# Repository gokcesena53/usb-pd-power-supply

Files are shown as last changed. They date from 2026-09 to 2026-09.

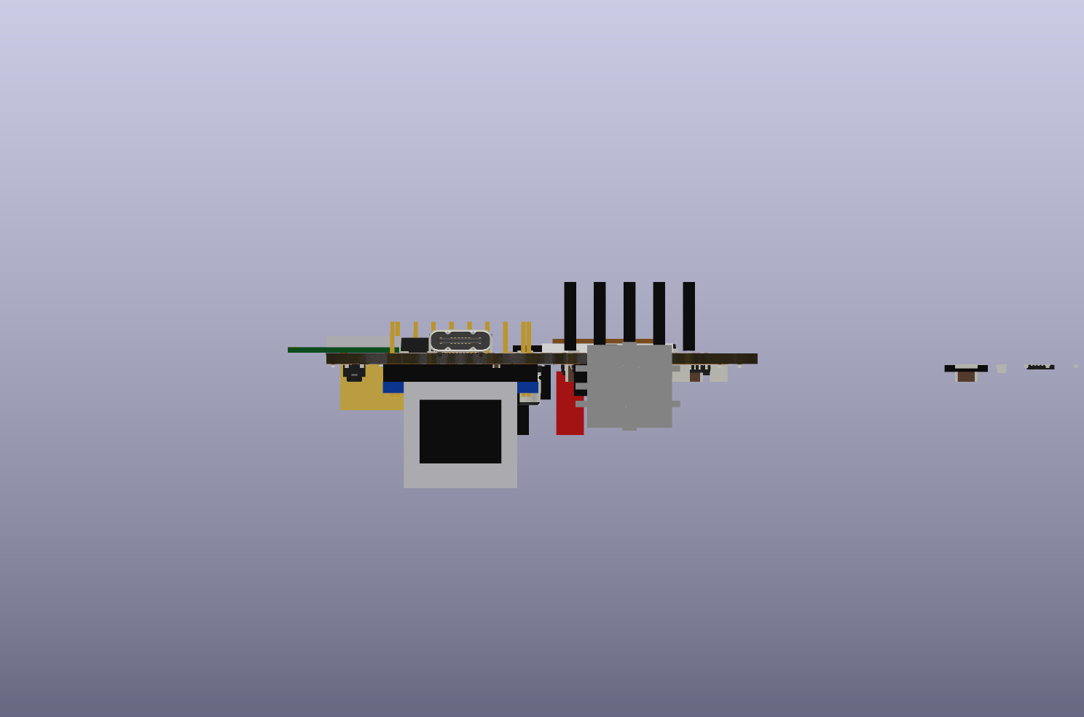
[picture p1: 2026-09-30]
hardware/docs/reports/task-094-20260925/candidate-left.png

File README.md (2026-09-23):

# gopo — Masaüstü Güç Kaynağı

USB-C PD beslemeli, ESP32-C6 tabanlı, TFT ekranlı ve döner enkoderli
masaüstü ayarlanabilir güç kaynağı. Şematik ve PCB tasarımı KiCad ile yapılmıştır.

Depo yapısı [Open Hardware Template](https://github.com/mfhepp/open_hardware_template)
şablonunu izler.

## Klasör yapısı

| Klasör | İçerik |
| --- | --- |
| `hardware/` | KiCad projesi (`gopo.kicad_pro`, `.kicad_sch`, `.kicad_pcb`, `.kicad_dru`) ve kütüphane tabloları (`fp-lib-table`, `sym-lib-table`) |
| `hardware/libraries/` | Projeye özel sembol (`.kicad_sym`), footprint (`.pretty`) ve 3D model (`.3dshapes`) kütüphaneleri |
| `hardware/datasheets/` | Kullanılan bileşenlerin veri sayfaları |
| `hardware/docs/` | Ham ERC/DRC raporları, netlist'ler, doğrulama betikleri ve anlık görüntüler |
| `hardware/gerber/` | Üretim çıktıları (Gerber, drill) |
| `hardware/images/` | Şematik/PCB görüntüleri (PNG, SVG) |
| `hardware/pdf/` | Blok blok şematik PDF çıktıları ve inceleme belgeleri |
| `design_decisions/` | Tasarım kararları, hesaplamalar ve inceleme notları (Markdown) |
| `3d_design/` | Kutu/mekanik tasarım dosyaları |
| `software/` | Firmware, firmware gereksinimleri (`FIRMWARE_GEREKSINIMLERI.md`) ve yardımcı betikler |
| `backlog/` | Yapılacaklar ([Backlog.md](https://github.com/MrLesk/Backlog.md)); `backlog board` veya `backlog browser` ile görüntülenir |
| `docs/` | GitHub Pages proje sayfası |
| `.claude/skills/` | KiCad şema üretimi için Claude Code skill'i ve araçları |

## Şema araçları

`.claude/skills/kicad-schematic/` altında şema üretimi ve temizliği için
bir Claude Code skill'i ve iki bağımsız betik bulunur:

```bash
SK=.claude/skills/kicad-schematic/scripts
cd hardware
python3 ../$SK/render.py gopo.kicad_sch --list
python3 ../$SK/render.py gopo.kicad_sch --page 10 --crop 255 26 410 128 -o /tmp/r
python3 ../$SK/verify.py gopo.kicad_sch --show PD_VOUT V_PRE
```

`render.py` şemayı PNG'ye çevirir ve mm cinsinden bir bölgeye yakınlaşır;
`verify.py` ERC çalıştırıp netlist'i bir referansla karşılaştırır.
Gereksinimler: `kicad-cli`, `poppler-utils` (pdftoppm, pdftotext), Python 3.

Yöntem [American-Embedded/kistack](https://github.com/American-Embedded/kistack)
schematic skill'ine dayanır (MIT); kopyası ve lisansı skill'in `references/`
klasöründedir.

## Revizyonlar

Aktif revizyon **REV_B**'dir; `hardware/` klasöründeki tasarım budur.
Üretilmiş olan REV_A tasarımı depodan çıkarılmıştır ve yalnızca git geçmişinde
bulunur (`git log --diff-filter=D -- "masaüstü güç kaynağı.kicad_pcb"`).

Değişiklik kaydı için `CHANGES.TXT` dosyasına bakınız.

## Tasarım kuralları ve PCB üretimi

Tasarım kuralları `hardware/gopo.kicad_dru` dosyasındadır. Üretime göndermeden önce
seçtiğiniz üreticinin yeteneklerine uyduğunu doğrulayın.

PCB ipek baskısına ve şematiğe **"Licensed under CERN OHL v.1.2"** metnini
eklemeyi unutmayın.

## Lisans

Donanım tasarımı CERN OHL v.1.2 altında, `software/` klasöründeki yazılım MIT
lisansı altında dağıtılmaktadır. Ayrıntılar için `LICENSE` ve
`cern_ohl_v_1_2.txt` dosyalarına bakınız.

> **Not:** `LICENSE` dosyasındaki `<TELİF HAKKI SAHİBİ>` alanı henüz
> doldurulmamıştır; yayımlamadan önce doldurun veya farklı bir lisans seçin.

## Sorumluluk reddi

BU TASARIM VE YAZILIM, AÇIK VEYA ZIMNİ HİÇBİR GARANTİ OLMAKSIZIN "OLDUĞU GİBİ"
SAĞLANMAKTADIR. YAZARLAR VEYA TELİF HAKKI SAHİPLERİ, TASARIMIN VEYA YAZILIMIN
KULLANIMINDAN DOĞAN HİÇBİR TALEP, ZARAR VEYA SORUMLULUKTAN SORUMLU TUTULAMAZ.

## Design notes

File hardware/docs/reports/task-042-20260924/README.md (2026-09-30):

# TASK-042 — PCM_Espressif temizliği

24.09.2026. U2, aktif şemada ve PCB'de `RF_Module:ESP32-C6-MINI-1`
kullanıyor; eski WROOM kütüphanesine ihtiyaç kalmadı.

Kaldırılan dosyalar:

- `hardware/libraries/PCM_Espressif.kicad_sym`
- `hardware/libraries/PCM_Espressif.pretty/ESP32-C6-WROOM-1.kicad_mod`

`hardware/sym-lib-table` ve `hardware/fp-lib-table` içindeki PCM_Espressif
kayıtları da kaldırıldı. Güncel şema, PCB, proje, lib-table ve yerel
sembol/footprint dosyalarından oluşan 25 dosyada referans sayısı sıfırdır.
Tarihsel rapor ve yedeklerdeki eski devre kayıtları arşiv niteliğindedir.

| Kontrol | Önce | Sonra |
| --- | --- | --- |
| ERC hata / uyarı | 0 / 0 | 0 / 0 |
| DRC schematic parity | 0 | 0 |
| DRC yerleşim/üretim ihlali | 148 | 148 |
| Bağlantısız öğe | 361 | 361 |
| Net sayısı | 120 | 120 |

Netlist, tüm netlerin pin kümeleri üzerinden birebir karşılaştırıldı.
Beş şema dosyası, PCB ve proje dosyasının SHA-256 değerleri de değişmedi.
Görsel tasarım dosyalarına dokunulmadığından bu temizlik için yeni render
üretilmedi.

148 DRC ihlalinin içerikleri aynı kaldı; bağlantısız öğelerin net başına
sayıları da değişmedi. Aynı konumdaki veya aynı pad numarasını paylaşan
pedlerde KiCad ratsnest uç çifti seçimi çalıştırmalar arasında değişebilir;
raporlardaki bu fark PCB bağlantısının değiştiği anlamına gelmez. Kütüphane
temizliği açısından ERC/DRC kontrolü geçti; genel yerleşim/routing DRC'si
henüz sıfır değildir.

Kanıtlar: `before-summary.json`, `after-summary.json`, `before-erc.rpt`,
`after-erc.rpt`, `before-drc.json`, `after-drc.json`.

Boş `PCM_Espressif.pretty` klasörünün silinmesi otomatik onay denetimi
tarafından yalnız “blocked by policy” gerekçesiyle engellendi. Klasör boş
bırakıldı; içinde footprint yoktur ve kütüphane tablolarında kaydı yoktur.
Git boş klasörleri takip etmez.

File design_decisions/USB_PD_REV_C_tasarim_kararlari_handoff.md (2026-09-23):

# USB-C PD Masaüstü Güç Kaynağı — REV_C Tasarım Kararları (Agent Handoff)

**Tarih:** 2026-09-16
**Kaynak:** Zg ile yapılan tasarım inceleme oturumu (claude.ai, "USB TYPE C PD Project")
**Hedef revizyon:** REV_B → REV_C

---

## 0. Agent için çalışma kuralları

1. Bu doküman **onaylanmış kararları** içerir. Aşağıdaki "Reddedilen alternatifler" (Bölüm 9) listesindeki çözümleri yeniden önermeyin veya uygulamayın.
2. Referans designator'lar (Q3, Q4, C3, D3, R43, C12, C13, C16 vb.) REV_B şemasından alınmıştır. Değişiklik yapmadan önce her birinin şemada doğru parçaya karşılık geldiğini **doğrulayın**. Uyuşmazlık varsa değiştirmeyin, raporlayın.
3. Değeri veya MPN'i **TBD** olarak işaretlenmiş parçalar için MPN uydurmayın. Şemaya generic parça + `TBD` notu ile yerleştirin (Bölüm 8'deki gereksinimleri parça alanına yazın).
4. Her değişikliği sayfa bazında ayrı commit / değişiklik kaydı olarak yapın ve sonunda Bölüm 10'daki kontrol listesini raporlayın.
5. Parça tedariki LCSC üzerinden planlanıyor. Yeni parça eklerken LCSC stok durumunu not edin.

---

## 1. Tasarım varsayımları

| Parametre | Değer |
|---|---|
| PD controller | AP33772S (sink) |
| VBUS aralığı | vSafe5V attach → PPS 3.3 V … EPR 28 V |
| Kullanıcı çıkış voltajı | **3.3 V – 28 V** (5 V altı yalnızca PPS ile, adaptörün APDO minimumuna bağlı) |
| Maksimum çıkış akımı | **5 A varsayıldı** (kesinleşmedi — değişirse şönt, FET ve SOA hesapları yeniden yapılmalı) |
| Dahili yük | 3.3 V / ~1 A (ESP32, ekran + backlight boost, INA228 vb.) |
| MCU | ESP32 |

---

## 2. Yeni mimari (özet)

```
J1 (USB-C) ── D3 (AQ3130E, ESD) + SMBJ30A (surge) ── USB_VBUS ── C3 ── AP33772S R_SENSE
                                                                         │
                         ┌───────────────────────────────────────────────┤  (dallanma noktası
                         │                                               │   şöntün ARKASINDA)
                         ▼                                               ▼
  KOL A — DAHİLİ BESLEME                               KOL B — KULLANICI ÇIKIŞI
  Q3/Q4 (küçük dual NMOS, AP33772S sürer)             M1 ⇄ M2 back-to-back (AP74502Q sürer)
         │                                                     │
      PD_VOUT (+47 µF sönümleme bulk)                     INA228 şönt
         │                                                     │
  TPS55340 pre-boost (5.02 V)                              OUT_POS ── J4/J5
         │
       V_PRE = max(5 V, PD_VOUT − V_D) ──► AP74502Q VIN
         │
  AOZ1284 buck ── 3.3 V rail
```

**Temel fikir:**
- Kullanıcı akımı artık Q3/Q4'ten geçmez, sadece M1/M2 üzerinden akar (yol kaybı yarıya iner).
- Q3/Q4, cSnkBulk (≤10 µF) uyumu, Hard Reset/detach izolasyonu ve dahili rail kısa devre koruması için **kalır** ama küçültülür.
- Pre-boost, PD_VOUT 5 V'un altına indiğinde (3.3 V PPS) dahili rail'i ayakta tutar; üstünde pass-through çalışır.
- AP74502Q'nun VIN'i V_PRE'den beslendiği için 3.3 V çıkışta da POR eşiğinin (≤3.9 V) üzerinde kalır.

---

## 3. Sayfa bazında değişiklikler

### 3.1 `usb_c_input` / VBUS giriş

| # | İşlem | Referans | Detay |
|---|---|---|---|
| 1 | EKLE | D_TVS (yeni) | **SMBJ30A** (tek yönlü, 600 W, VRWM 30 V). Yer yoksa SMAJ30A. J1'e yakın, kısa toprak dönüşü. |
| 2 | KORU | D3 | AQ3130E-01ETG (ESD diyotu) yerinde kalır, SMBJ30A ile paralel. |
| 3 | DEĞİŞTİR | C3 | 1 µF/50 V → **2.2 µF/50 V X7R** (cSnkBulk minimum 1 µF'ı DC bias altında garanti etmek için). USB_VBUS'ta toplam efektif kapasite 5 V'ta **≤10 µF** kalmalı. |
| 4 | NOT | Ferrite bead | 5 A yoluna **bead konmayacak**. İstenirse USB_VBUS'ta 0 Ω doldurulmuş opsiyonel footprint bırakılabilir (DNP bead). TVS'ler bead'in konnektör tarafında olmalı. |

### 3.2 `usb_pd_controller`

| # | İşlem | Referans | Detay |
|---|---|---|---|
| 1 | DOĞRULA | AP33772S R_SENSE | Şöntün **iki kolun dallandığı noktanın önünde** olduğundan emin olun (OCP ve PPS akım ölçümü toplam akımı görmeli). Konum farklıysa raporlayın, topolojiyi buna göre düzenleyin. |
| 2 | DEĞİŞTİR | Q3, Q4 | IRF7855 → **küçük dual NMOS, 40–60 V, ≥2 A** (TBD, Bölüm 8). Q3/Q4 çıkışı artık sadece `PD_VOUT` (dahili kol) netini besler. |
| 3 | AYIR | Net | `PD_VOUT` ile `OUT_POS` / INA228 arasındaki bağlantıyı **kaldırın**. Kullanıcı çıkış kolu Q3/Q4'ün önünden (USB_VBUS, şönt sonrası) beslenecek. |

### 3.3 `powergeneration`

| # | İşlem | Referans | Detay |
|---|---|---|---|
| 1 | EKLE | U_BOOST (yeni) | **TPS55340PWPR** (HTSSOP-14 PowerPAD). Giriş: `PD_VOUT`, çıkış: yeni net `V_PRE`. |
| 2 | EKLE | L_BOOST | 6.8–10 µH, Isat ≥3 A, düşük DCR (pass-through'da buck giriş akımını sürekli taşır). **TBD** |
| 3 | EKLE | D_BOOST | Schottky 40–60 V, 3 A, düşük VF (SS34/SS36 sınıfı). **TBD** |
| 4 | EKLE | R_FREQ | **78.7 kΩ** (≈600 kHz). f_sw 350 kHz altına düşürülmemeli (foldback recovery). |
| 5 | EKLE | FB bölücü | R_TOP **30.1 kΩ** (V_PRE→FB), R_BOT **9.76 kΩ** (FB→AGND) → V_PRE ≈ 5.02 V |
| 6 | EKLE | **FB clamp (ZORUNLU)** | FB abs max 3 V; pass-through'da FB ≈ 6.8 V'a çıkar. ~~BAT54 + 3V3 bölücü (V_CL ≈ 1.81 V)~~ → **23.09.2026: BAS16H**, anot FB, katot `EN_CTRL` (V_X = 1.605 V, U6 TLV431; #14 ile ortak). 34 V / 0 °C worst-case FB 2.40 V. Ayrıntı: `design_decisions/output/FB_CLAMP_EN_REFERANSI_20260923.md`. |
| 7 | EKLE | C_SS | 47 nF |
| 8 | EKLE | Kompanzasyon | R3 = 2 kΩ, C4 = 100 nF (başlangıç değeri, en düşük VIN'de ölçümle optimize edilecek). C5 opsiyonel/DNP. |
| 9 | EKLE | C_IN_BOOST | 10 µF/50 V X7R + VIN pinine yakın 100 nF |
| 10 | EKLE | C_OUT_BOOST | ≥2 × 10 µF/50 V X7R (`V_PRE`), AOZ1284 giriş kapasiteleriyle birleştirilebilir |
| 11 | BAĞLA | EN | EN → VIN'e 100 kΩ ile (her zaman aktif). SYNC → AGND, NC → AGND, PowerPAD → AGND. |
| 12 | EKLE | C_DAMP | `PD_VOUT`'a **47 µF, 35–50 V, ESR ~50–100 mΩ** (hybrid polymer veya düşük ESR elektrolitik). Seramik bu işi görmez. PD_VOUT toplam kapasitesi **≤100 µF** (cSnkBulkPd). **TBD MPN** |
| 13 | TAŞI | AOZ1284 girişi | AOZ1284 VIN: `PD_VOUT` → **`V_PRE`**. C12/C13 `V_PRE` netine taşınır. |
| 14 | TAŞI | R43 / TL431 (EN bias) | Beslemesi `V_PRE`'den alınır. ~~R43 ≈ 1 kΩ, TL431 2.495 V~~ → **23.09.2026: R43 4k7, U6 TLV431BQ, R50 2k87 / R51 9k76 REF bölücü → V_X 1.605 V; R42 kaldırıldı.** R43 28 V'ta 0.15 W. |
| 15 | DÜZELT | C16 | **47 µF footprint `C_0402_1005Metric` hatalı** (47 µF 0402'de üretilmiyor). 1206/1210'a çevirin; Cout efektif ≥44 µF hedefi için gerekirse 2 × 22 µF paralel. |
| 16 | KALDIR | — | Buck giriş koluna önerilmiş olan ferrite bead + sönümleme düzeni **iptal** (topoloji değişti). |

### 3.4 `powersensing` / `poweroutput` — Kullanıcı çıkış anahtarı (yeni blok)

| # | İşlem | Referans | Detay |
|---|---|---|---|
| 1 | EKLE | U_SW | **AP74502QTA8-7** (Diodes). Alternatif: **LM74502DDFR** (TI, pin uyumlu). **Her ikisine uyan ortak footprint** kullanın (TI'nın daha uzun pad'li land pattern'i). |
| 2 | EKLE | M1, M2 | Back-to-back (ortak source) N-kanal, **60 V, ≤4 mΩ, 5×6 DFN, Vgs ±20 V**. **TBD** (Bölüm 8). M1 drain → USB_VBUS (şönt sonrası dallanma), M2 drain → INA228 şönt girişi. Yönelimi AP74502Q datasheet tipik uygulamasına göre bağlayın. |
| 3 | BAĞLA | VIN (pin 5) | **`V_PRE`** (USB_VBUS değil). |
| 4 | BAĞLA | SRC (pin 8) | M1/M2 ortak source düğümü |
| 5 | BAĞLA | GATE (pin 6) | M1/M2 gate'lerine doğrudan |
| 6 | EKLE | D_GS | **12 V zener (BZT52C12)** GATE–SRC arası (GATE–SRC abs max 15 V koruması). |
| 7 | EKLE | CdVdT + RG | GATE düğümü → **RG 1 kΩ** → **CdVdT 22 nF/50 V** → GND (seri kol). ≈2.7 V/ms soft-start. |
| 8 | EKLE | C_VCAP | **220 nF/25 V**, VCAP (pin 4) – VIN arası |
| 9 | EKLE | C_VIN | 100 nF/50 V, VIN – GND |
| 10 | EKLE | OVLO bölücü | **Eşik ≈30 V** (kullanıcı çıkışı artık AP33772S OVP'sinin arkasında değil). Direnç değerlerini AP74502Q OVLO eşiğine göre hesaplayın. **TBD değer** |
| 11 | BAĞLA | EN/UVLO (pin 1) | ESP32 GPIO → **10 kΩ seri** → EN; EN → **100 kΩ** → GND (varsayılan kapalı); **INA228 ALERT** (open-drain) doğrudan EN düğümüne (wired-OR). ESP32 **strapping olmayan** bir GPIO kullanın. INA_ALERT ayrıca ESP32 input'una da gitmeye devam etsin. |
| 12 | KORU | INA228 | Şönt M2 sonrası, OUT_POS öncesi. |
| 13 | EKLE | D_OUT | OUT_POS'a **SMBJ30A** (endüktif yük geri tepmesi). |
| 14 | EKLE (ops.) | R_BLEED | OUT_POS → GND 10 kΩ (≥0.25 W) veya SHDN/EN low iken açılan küçük deşarj FET'i. |

### 3.5 `mcu` / firmware arayüzü

- Yeni sinyal: `OUT_EN` (ESP32 GPIO → AP74502Q EN, 10 kΩ seri + 100 kΩ pull-down).
- `INA_ALERT` hem `OUT_EN` düğümüne wired-OR hem de ESP32 interrupt girişine.
- AP33772S INT/STATUS okuması firmware için gerekli (Hard Reset / detach / FAULT).

---

## 4. Firmware gereksinimleri (şema dışı, dokümante edilmeli)

1. **Açılış:** `OUT_EN` low. AP33772S varsayılan olarak 5 V ile açılır (VSELMIN default 5 V).
2. **VSELMIN:** Boot sonrası **≤3.2 V** yapılmalı (aksi halde 3.3 V isteğinde Q3/Q4 kapanır → ESP32 reset döngüsü).
3. **Voltaj isteği:** 5 V altı yalnızca **PPS** ile; istek adaptörün APDO minimumunun altındaysa gönderilmez.
4. **PPS operating current** = kullanıcı yükü + dahili tüketim (3.3 V'ta ~1.4 A).
5. **Çıkış açma:** `OUT_EN` high → ≥25 ms bekle → INA228 ile çıkış voltajını doğrula.
6. **Voltaj değiştirme:** `OUT_EN` low → yeni PDO/APDO isteği → PS_RDY → AP33772S voltaj kaydı ile doğrula → kullanıcı onayı → `OUT_EN` high.
7. **Fixed PDO geçişlerinde** Accept–PS_RDY arası toplam tüketim ≤2.5 W (Wi-Fi TX ertele, backlight kıs).
8. **Hard Reset / detach interrupt:** `OUT_EN` hemen low.
9. **INA228 ayarları:** ALATCH = 1, CNVR = 0, SOVL ≈ 6 A eşdeğeri (donanım aşırı akım), SUVL ≈ −0.3 A (ters akım), BOVL dinamik (istenen voltaj + marj), ADCRANGE uygun aralıkta.
10. **UVP / FAULT:** AP33772S FAULT kaydı izlenmeli; UVP durumunda yeniden pazarlık. 3.3 V'ta kablo düşümü için PPS 20 mV adımlarıyla kompanzasyon.
11. **Hata sonrası:** ALERT latch → arayüzde hata → kullanıcı onayıyla DIAG_ALRT temizle → `OUT_EN` high.

---

## 5. Koruma katmanları (referans)

| Katman | Eleman | Görev |
|---|---|---|
| 1 | INA228 ALERT → EN | Donanım aşırı akım (~6 A) + ters akım, sub-ms |
| 2 | AP74502Q OVLO | Çıkış aşırı voltaj (~30 V) |
| 3 | Firmware (INA228) | Kullanıcı akım limiti, BOVL |
| 4 | AP33772S OCP/OVP/UVP | Toplam giriş; dahili kolu (Q3/Q4) keser |

---

## 6. Kritik tasarım notları (agent değiştirmemeli)

- **Q3/Q4 kaldırılmayacak ve tek MOSFET'e düşürülmeyecek** (cSnkBulk ≤10 µF, Hard Reset/detach izolasyonu, dahili kısa devre koruması).
- **TPS55340 FB clamp devresi zorunlu.** Clamp olmadan PD_VOUT >~12 V'ta FB pini hasar görür.
- **GATE–SRC 12 V zener zorunlu.**
- **AP74502Q VIN'i V_PRE'den** beslenecek, USB_VBUS'tan değil.
- **47 µF sönümleme bulk'ı PD_VOUT'ta zorunlu** (5 A'de çıkış anahtarı açıldığında kablo endüktansı kaynaklı tepeyi 34 V altında tutmak için; AP33772S VCC ve TPS55340 VIN abs max 34 V).
- **Boost asenkron (Schottky'li) olmalı** — pass-through davranışı buna dayanıyor.

---

## 7. BOM özet değişiklikleri

| Durum | Parça |
|---|---|
| Yeni | TPS55340PWPR, AP74502QTA8-7 (alt: LM74502DDFR), SMBJ30A ×2, BZT52C12, BAS16H (eski BAT54), L_BOOST (TBD), D_BOOST (TBD), M1/M2 (TBD), C_DAMP 47 µF (TBD), pasifler |
| Değişen | C3 → 2.2 µF/50 V; Q3/Q4 → küçük dual NMOS (TBD); C16 footprint → 1206/1210; R43 güç rating kontrolü |
| Kaldırılan | IRF7855 (Q3/Q4 olarak); 5 A yolundaki ferrite bead planı |
| Aynen kalan | AP33772S, AOZ1284, D3 (AQ3130E), INA228, EN bias (besleme V_PRE'ye taşındı; 23.09.2026 TL431 → TLV431, FB clamp ile ortak) |

---

## 8. Açık kalemler (TBD) ve gereksinimleri

| Kalem | Gereksinim | Not |
|---|---|---|
| Q3/Q4 (dahili kol) | Dual NMOS, 40–60 V, ≥2 A, AP33772S gate sürüşüyle uyumlu Vgs | LCSC'den seçilecek |
| M1/M2 (çıkış kolu) | 60 V, ≤4 mΩ @10 V, 5×6 DFN, Vgs ±20 V; 28 V × ~1–5 A × ~10 ms SOA | LCSC'den seçilecek |
| L_BOOST | 6.8–10 µH, Isat ≥3 A, düşük DCR | LCSC |
| D_BOOST | Schottky 40–60 V, 3 A | LCSC |
| C_DAMP | 47 µF, 35–50 V, ESR 50–100 mΩ | LCSC |
| AP74502Q OVLO bölücü | ≈30 V eşik | Datasheet OVLO eşiğinden hesaplanacak |
| Maksimum çıkış akımı | Varsayım 5 A | Kesinleşmeli |
| AP33772S R_SENSE konumu | Dallanma noktasının önünde | Şemadan doğrulanacak |

---

## 9. Reddedilen alternatifler (yeniden önermeyin)

| Alternatif | Red sebebi |
|---|---|
| SMBJ40A (VBUS TVS) | 44 V'a kadar iletmez, AP33772S'i korumaz |
| SMAJ30CA (çift yönlü) | Negatif ringing'i −33 V'a kadar geçirir |
| Ferrite bead 5 A yolunda | Isıl marj, DC bias'ta empedans kaybı, kazanç yok |
| LTC4368 çıkış anahtarı | UV/OV istenmedi, maliyet |
| LTC4365 çıkış anahtarı | Pre-boost + V_PRE beslemesiyle gereksiz kaldı |
| LTC3115-1 buck-boost | LCSC ~10.8 $, stok yetersiz |
| LM3481 buck olarak | Low-side kontrolcü, buck yapamaz |
| LM3481 SEPIC tek kademe | Yüksek stres, zor kompanzasyon, 9–28 V'ta düşük verim |
| LM3481 boost | TPS55340 ile değiştirildi (entegre FET, düşük VIN'de harici FET sorunu yok) |
| Q3/Q4'ü tamamen kaldırmak / tek MOSFET | cSnkBulk ihlali, Hard Reset/detach, kısa devre koruması |
| Seri yol (Q3/Q4 → M1/M2) | Paralel kol ile değiştirildi (kayıp yarıya iner) |

---

## 10. Prototip doğrulama listesi (şemaya "test notu" olarak da eklenebilir)

1. 5 V profilde tam yükte AOZ1284 ve TPS55340 kararlılığı; attach anında USB_VBUS efektif kapasite ≤10 µF.
2. 3.3 V PPS'te tam dahili yükte V_PRE regülasyonu (5.02 V) ve boost döngü kararlılığı.
3. 5.5–28 V pass-through'da TPS55340 SW pininde anahtarlama olmadığı ve **FB < 3 V**.
4. 28 V EPR, 5 A yükte çıkış anahtarı açılışında **USB_VBUS / PD_VOUT tepe < 34 V**.
5. AP74502Q açılışı: 1000 µF kapasitif yük (inrush) ve 5 A rezistif yük (SOA); 3.3 V çıkışta gate voltajı ve zener clamp.
6. INA228 ALERT → EN kapanma gecikmesi (kısa devre testi).
7. 5→12, 5→28, 28→5, 5→3.3 V geçişlerinde ESP32 3.3 V rail'i ve AP33772S UVP davranışı (birden fazla adaptörle).
8. Hard Reset ve kablo çekme sırasında çıkış kapasitelerinin VBUS'ı beslemediği.

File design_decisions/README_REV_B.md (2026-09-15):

# REV_B PCB çalışma alanı

Bu klasör, mevcut üretim kartından bağımsız yeni PCB yerleşim çalışmasıdır.

## Hazır taban

- Geometrik dış ölçü: **60,00 × 40,00 mm**
- Bakır katman sayısı: **4**
- Köşe bağlantısı: kapalı montaj deliği yoktur.
- Dört köşe, M3 vida gövdesi için **3,40 mm çap eşdeğerinde (R = 1,70 mm) kenara açık çeyrek daire** olarak yontulmuştur.
- Edge.Cuts çizgi genişliği: **0,05 mm**
- Footprint: **0**
- Track: **0**
- Via: **0**
- Copper zone: **0**
- Taban DRC: **0 ihlal / 0 bağlantısız öğe**

Şematik komponentleri bilerek henüz PCB'ye aktarılmadı. Sonraki işlem, KiCad'de **Tools → Update PCB from Schematic (F8)** adımını kullanıcıyla birlikte yürütmektir.

## Enkoder revizyonu

- SW3: **L-KLS4-EC1121S-E5A-F12.5**
- A → ENCODER_A, C → GND, B → ENCODER_B
- D → ENCODER_SW, E → GND
- Projeye özel footprint: `L-KLS4-EC1121S-E5A-F12.5.pretty`
- Elektrik pin delikleri: 5 × Ø1,00 mm
- Elektrik pin sıraları arası: 14,50 mm
- Mekanik slotlar: 2,10 × 1,50 mm, merkezler arası 11,50 mm
- Datasheet: `datasheets/L-KLS4-EC1121S-E5A-F12.5.pdf`
- Revizyon sonrası ERC: **0 ihlal**

Ana `masaüstü güç kaynağı.kicad_pcb` dosyası değiştirilmemiştir. REV_A arşivi `revisions/archive/REV_A_PRODUCTION_20260914` altındadır.

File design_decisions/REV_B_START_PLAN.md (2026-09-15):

# REV_B birlikte çalışma sırası

1. Yeni 60 × 40 mm PCB tabanını ve dört açık köşe yontusunu görsel olarak kontrol et.
2. REV_B şematiğinde footprint ataması eksik komponent olup olmadığını kontrol et.
3. Schematic Editor içinde **Tools → Update PCB from Schematic (F8)** komutunu birlikte aç.
4. Güncelleme listesindeki eklenen footprintleri ve uyarıları birlikte incele.
5. **Update PCB** komutuyla footprintleri aktar; ilk grubu kart dışında geçici çalışma alanına bırak.
6. Kasa/panel bileşenlerini önce yerleştir: USB-C, çıkış konnektörleri, TFT, rotary encoder, CR2032 ve programlama konnektörü.
7. ESP32 anten kenarını ve keepout alanını kilitle.
8. Güç, ölçüm, MCU/RTC ve kullanıcı arayüzü bloklarını ayrı ayrı kart içine yerleştir.
9. Yerleşim onayından sonra güç yolları, USB çifti, hassas ölçüm hatları ve diğer sinyaller yönlendirilir.

Komponent aktarımı kullanıcıyla birlikte yapılacağı için PCB tabanı şu anda bilinçli olarak boştur.

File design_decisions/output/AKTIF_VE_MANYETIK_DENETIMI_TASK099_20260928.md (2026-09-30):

# REV_C Aktif ve Manyetik Komponentlerin IC İlişkileri ve Kritik Döngüleri Denetim Raporu (TASK-099)

**Tarih:** 28 Eylül 2026  
**İncelenen Dosya:** `hardware/gopo.kicad_pcb`  
**PCB SHA256:** `3fef79fb84dd7873a7848b67d45493059cb3772e0c8dd45b3bf90e45d1a4e9f6`  
**İlgili Görevler:** TASK-096, TASK-097, TASK-098, TASK-099, TASK-087  
**Doğrulama Aracı:** KiCad 10.0 Python API (`pcbnew`) & `kicad-cli`

---

## 1. Yönetici Özeti

REV_C kartı üzerindeki tüm aktif yarıiletkenler (10 Diyot `D1`–`D10`, 8 Transistör/FET `Q1`–`Q8`), güç indüktörleri (`L1`, `L3`), gerçek zamanlı saat kristali (`Y1`) ve entegreler arası kritik sinyal zincirleri (I2C seviye dönüştürücüleri, donanımsal koruma ve aktif deşarj zinciri) pin bazında taranmış, katman uyumu, doğrusal mesafeler, gate sürüş döngüleri, yüksek frekanslı anahtarlama yolları ve parazitik yayılım riskleri açısından doğrulanmıştır.

### Temel Denetim Sonuçları:
1. **Diyot Polariteleri ve Mesafeleri:** `D1`–`D10` diyotlarının tamamının katot/anot yönelimleri ve elektriksel polariteleri %100 doğrulanmıştır. Şematik ve PCB incelemesinde `D2`'nin sanılanın aksine "boot diyotu" değil, buck konvertör için **harici dead-time serbest dolaşım (catch) Schottky diyotu** olduğu (U5 dahili bootstrap kapasitörü C17 ile BST-LX arasına bağlıdır), katodunun `LX_SW`'e olan mesafesinin yalnızca **2.20 mm** olduğu tespit edilmiş ve onaylanmıştır.
2. **FET ve Gate Sürüş Döngüleri:** `Q1`–`Q8` transistörlerinin gate sürüş ve güç anahtarlama döngüleri incelenmiştir. `Q5` dual güç FET'i ile `U12` sürücüsü aynı katmanda (`F.Cu`) olup DGATE mesafesi **3.94 mm**, HGATE mesafesi **9.09 mm**'dir. `Q3` VBUS çift FET'i back-to-back konfigürasyonda U1'e **10.69 mm** mesafededir.
3. **Manyetik Bileşenler ve Sıcak Döngüler:** `L1` (22 µH) indüktörü U5 LX pinine **6.05 mm** mesafede; `L3` (6.8 µH) indüktörü U11 SW pinine **10.89 mm**, `D4` Schottky anot pedine ise **6.50 mm** mesafededir. Boost dönüştürücünün yüksek $di/dt$ sıcak döngüsü (SW $\rightarrow$ D4 $\rightarrow$ C27 $\rightarrow$ PGND) yalnızca $\approx 24\text{ mm}$ çevreye sahiptir.
4. **Kristal Osilatör İzolasyonu:** `Y1` 32.768 kHz kristali ile `U4` RTC entegresi $X = 143.00\text{ mm}$ ekseninde aynı hizada ve `B.Cu` katmanında yer almakta olup merkezler arası mesafe **7.00 mm**'dir. Güç anahtarlama hatlarından (LX, SW) $> 20\text{ mm}$ uzaktadır.
5. **Entegreler Arası Donanımsal Koruma Zinciri:** `U3` (INA226) $\rightarrow$ `U13` (74LVC1G08 VE kapısı) $\rightarrow$ `U12` (LM74801) / `Q4` (Deşarj sürücü) donanımsal koruma zinciri yazılımdan bağımsız, sub-mikrosaniye mertebesinde aşırı akım/kısa devre koruması ve aktif deşarj sağlamaktadır.
6. **KiCad DRC & Parite:** KiCad 10 DRC çalıştırılmış, taban 164 ihlal korunmuş, **0 yeni ihlal** ve **0 schematic parity issue** (%100 parite) teyit edilmiştir.

---

## 2. Diyotlar (D1–D10) Denetim Matrisi

| Ref | Değer | Kılıf | Katman | Konum $(X, Y)$ mm | Pin 1 (Katot) Neti | Pin 2 (Anot) Neti | Bağlı IC / Fonksiyon | Mesafe | Polarite Durumu | Karar |
|:---:|:---:|:---:|:---:|:---:|:---:|:---:|:---:|:---:|:---:|:---:|
| **`D1`** | LED | LED_0402 | B.Cu | $(83.50, 120.50)$ | `GND` | `Net-(D1-A)` | U1 Pin 8 (LED çıkışı, R14 2k2 üzerinden) | 6.55 mm (U1 P8) | Doğru (Anot U1'den sürülür, Katot GND) | **UYGUN** |
| **`D2`** | SS2060FL | SOD-123F | B.Cu | $(132.80, 103.50)$ | `/USB_PD_CONTROLLER/LX_SW` | `GND` | U5 Pin 1 (LX) Catch Schottky | **2.20 mm** (U5 P1) | Doğru (LX negatif pik sönümleme) | **UYGUN** |
| **`D3`** | SMBJ30A | SMB | F.Cu | $(61.50, 82.50)$ | `USB_VBUS` | `GND` | J7 USB-C Giriş VBUS TVS | 10.42 mm (J7) | Doğru (30V tek yönlü TVS) | **UYGUN** |
| **`D4`** | SX36 | SMA | B.Cu | $(102.95, 114.66)$ | `V_PRE` | `/USB_PD_CONTROLLER/BOOST_SW` | U11 Pin 1,2 (SW) Boost Doğrultucu | **4.39 mm** (U11 P1) | Doğru (Anot SW'de, Katot çıkışta) | **UYGUN** |
| **`D5`** | BAS16H | SOD-323 | B.Cu | $(92.17, 123.26)$ | `/USB_PD_CONTROLLER/EN_CTRL` | `/USB_PD_CONTROLLER/BOOST_FB` | U11 Pin 9 (BOOST_FB) Clamp | **2.14 mm** (U11 P9) | Doğru (Disable durumunda FB çekme) | **UYGUN** |
| **`D6`** | BZT52C12 | SOD-123 | F.Cu | $(124.80, 104.50)$ | `/USB_PD_CONTROLLER/GATE_DRV` | `/USB_PD_CONTROLLER/SRC_COMMON` | U12 Pin 8 / Q5B HGATE Clamp | 13.97 mm (U12 P8) | Doğru ($V_{GS} \le 12\text{V}$ koruma Zeneri) | **UYGUN** |
| **`D7`** | SMBJ30A | SMB | B.Cu | $(144.00, 119.50)$ | `OUT_POS` | `GND` | J4 Çıkış ve U3 Sense TVS | 7.32 mm (U3 P8) | Doğru (Çıkış endüktif koruma) | **UYGUN** |
| **`D8`** | SMF30A | SOD-123F | F.Cu | $(61.50, 92.00)$ | `USB_CC1` | `GND` | J7 Pin A5 (CC1) TVS / ESD | 9.22 mm (J7) | Doğru (28V EPR VBUS kısa devre koruması) | **UYGUN** |
| **`D9`** | SMF30A | SOD-123F | F.Cu | $(61.50, 94.50)$ | `USB_CC2` | `GND` | J7 Pin B5 (CC2) TVS / ESD | 10.42 mm (J7) | Doğru (28V EPR VBUS kısa devre koruması) | **UYGUN** |
| **`D10`**| BZT52C12 | SOD-123 | F.Cu | $(124.00, 117.50)$ | `/USB_PD_CONTROLLER/DISCH_G` | `GND` | Q6 Gate Clamp Zener | 4.50 mm (Q6) | Doğru ($V_{GS} \le 12\text{V}$ koruma Zeneri) | **UYGUN** |

### D2 Komponenti Hakkında Teknik Netleştirme:
Gereksinim metninde `D2 boot diyotu` olarak adlandırılan eleman, devre şematiğinde incelendiğinde U5 (AOZ1284PI senkron buck regülatör) bootstrap hattına değil, regülatörün `LX_SW` anahtarlama bacağı (Pin 1) ile `GND` arasına bağlı **harici serbest dolaşım (catch) Schottky diyotu**dur. AOZ1284PI'nin bootstrap kapasitörü `C17` (100 nF), entegrenin BST (Pin 2) ile LX (Pin 1) bacakları arasına doğrudan bağlanmıştır. `D2`, senkron buck regülatörün dead-time (ölü zaman) aralığında alt MOSFET gövde diyodunun iletime geçmesini önleyerek anahtarlama kayıplarını ve negatif voltaj sıçramalarını minimize eder. Katot pini `LX_SW`'e yalnızca **2.20 mm** mesafededir; polaritesi ve yerleşimi mükemmeldir.

---

## 3. Transistörler ve FET'ler (Q1–Q8) Denetim Matrisi

| Ref | Parça No | Kılıf | Katman | Konum $(X, Y)$ mm | Gate Neti | Source Neti | Drain Neti | Kontrol Eden IC / Sinyal | Gate Mesafe | Fonksiyon & Çalışma Modu | Karar |
|:---:|:---:|:---:|:---:|:---:|:---:|:---:|:---:|:---:|:---:|:---:|:---:|
| **`Q1`** | BSS138P | SOT-23-3 | B.Cu | $(105.75, 74.00)$ | `+3.3V` | `PD_I2C_SCL_3V3` | `PD_I2C_SCL_5V` | U2 (MCU) $\leftrightarrow$ U1 (PD) | DC Bias | Çift yönlü I2C SCL seviye dönüştürücü (3.3V $\leftrightarrow$ 5V) | **UYGUN** |
| **`Q2`** | BSS138P | SOT-23-3 | B.Cu | $(110.25, 74.00)$ | `+3.3V` | `PD_I2C_SDA_3V3` | `PD_I2C_SDA_5V` | U2 (MCU) $\leftrightarrow$ U1 (PD) | DC Bias | Çift yönlü I2C SDA seviye dönüştürücü (3.3V $\leftrightarrow$ 5V) | **UYGUN** |
| **`Q3`** | SQJB60EP | PowerPAK SO-8 | B.Cu | $(78.50, 110.00)$ | `PD_GATE` (P2, P4) | `Net-(Q3A-S)` (P1, P3 Ortak) | `PD_VOUT` (P5,6) / `VBUS_SENSED` (P7,8) | U1 (AP33772S) Pin 22 | 11.31 mm | Çift N-FET sırt sırta (back-to-back) VBUS güç anahtarı | **UYGUN** |
| **`Q4`** | BSS138P | SOT-23-3 | B.Cu | $(120.00, 122.50)$ | `SW_EN` (P1) | `GND` (P2) | `DISCH_G` (P3) | U13 (74LVC1G08) Pin 4 | 11.15 mm | Aktif deşarj lojik evirici FET (SW_EN=H $\rightarrow$ DISCH_G=L) | **UYGUN** |
| **`Q5`** | SQJB60EP | PowerPAK SO-8 | F.Cu | $(128.50, 99.00)$ | `DGATE` (P4) / `GATE_DRV` (P2) | `SRC_COMMON` (P1, P3 Ortak) | `SW_OUT` (P5,6) / `VBUS_SENSED` (P7,8) | U12 (LM74801-Q1) | **3.94 mm** (DGATE), **9.09 mm** (HGATE) | Dual FET: Q5A İdeal Diyot + Q5B Çıkış Güç Anahtarı | **UYGUN** |
| **`Q6`** | BSS138P | SOT-23-3 | F.Cu | $(119.50, 117.50)$ | `DISCH_G` (P1) | `GND` (P2) | `Net-(Q6-D)` (R59 üzerinden SW_OUT) | Q4 Drain / R57 Pull-up | 4.50 mm (D10 Zener) | Çıkış kapasitörleri hızlı aktif deşarj anahtarı | **UYGUN** |
| **`Q7`** | IRLML6344 | SOT-23-3 | F.Cu | $(87.00, 109.25)$ | `Net-(Q7-G)` | `GND` (P2) | `BL_K` (P3) | U2 Pin 13 (`TFT_BL_PWM`) | 30.60 mm | 3.2" TFT LCD arka aydınlatma PWM kısma anahtarı | **UYGUN** |
| **`Q8`** | TSM3443CX6 | SOT-26 | B.Cu | $(107.00, 88.50)$ | `/MCU/ETH_PWR_EN` (P3)| `+3.3V` (P4) | `/MCU/ETH_3V3` (P1,2,5,6) | U2 Pin 23 (`ETH_PWR_EN`) | 26.00 mm | Ethernet mezanin modülü (J8) yüksek taraf (P-FET) güç anahtarı | **UYGUN** |

### Q5 ve U12 Gate Sürüş Analizi:
- `Q5` ve `U12` aynı katmanda (`F.Cu`) bulunmaktadır.
- İdeal diyot kapısı `DGATE` izi, U12 Pin 1'den Q5 Pin 4'e **3.94 mm**'lik son derece kısa ve doğrudan bir hat üzerinden ulaşır. Katman geçişi (via) bulunmamaktadır; bu sayede ters akım durumunda mikro-saniye altı kapama hızına ulaşılır.
- Güç anahtarlama kapısı `HGATE` (`GATE_DRV`), U12 Pin 8'den yumuşak açılma direnci R54 ve D6 Zener clamp üzerinden Q5 Pin 2'ye **9.09 mm** mesafeyle bağlanır.
- Ortak kaynak (`SRC_COMMON`) algılama hattı diferansiyel çift olarak doğrudan U12'ye döner.

---

## 4. Manyetik Komponentler (L1, L3) ve Anahtarlama Döngüleri

| Ref | Değer / Tip | Kılıf | Katman | Konum $(X, Y)$ mm | Bağlı IC & Bacak | Mesafe (Pad-to-Pad) | Sıcak Döngü Bileşenleri | Döngü Çevresi | Parazitik Yayılım Riski | Karar |
|:---:|:---:|:---:|:---:|:---:|:---:|:---:|:---:|:---:|:---:|:---:|
| **`L1`** | 22 µH Güç Bobini | 7x7 mm SMD | B.Cu | $(126.995, 97.37)$ | U5 (AOZ1284PI) Pin 1 (LX) | **6.05 mm** | U5 LX $\rightarrow$ L1 $\rightarrow$ C15/C16 $\rightarrow$ U5 PGND | $\approx 28\text{ mm}$ | **Çok Düşük** (Manyetik korumalı, küçük bakır alanı) | **UYGUN** |
| **`L3`** | 6.8 µH Güç Bobini | 7x7 mm SMD | B.Cu | $(97.70, 108.16)$ | U11 (TPS55340) Pin 1,2 (SW) | **10.89 mm** (U11 SW), **6.50 mm** (D4 Anot) | U11 SW $\rightarrow$ D4 $\rightarrow$ C27 $\rightarrow$ U11 PGND | **$\approx 24\text{ mm}$** | **Çok Düşük** (D4 ve C27 doğrudan bitişik) | **UYGUN** |

### Sıcak Döngü (Hot Loop) ve Yayılım Değerlendirmesi:
1. **L1 Buck Regülatörü Döngüsü:**
   - AOZ1284PI regülatörünün anahtarlama frekansı $\approx 500\text{ kHz}$'dir.
   - En yüksek $dv/dt$ düğümü olan `LX_SW`, U5 Pin 1, D2 Pin 1 ve L1 Pin 1 arasında sınırlı bir bakır adacığı oluşturur ($< 15\text{ mm}^2$).
   - Altında In1.Cu katmanında kesintisiz zemin düzlemi yer aldığı için parazitik kapasitif EMI yayılımı engellenmiştir.
2. **L3 Boost Regülatörü Döngüsü:**
   - Boost topolojilerinde en kritik yüksek $di/dt$ döngüsü indüktör değil; **SW anahtarı $\rightarrow$ doğrultucu diyot $\rightarrow$ çıkış filtre kapasitörü** döngüsüdür.
   - U11 SW (Pin 1,2) $\rightarrow$ D4 Schottky diyotu $\rightarrow$ C27 bulk kapasitörü $\rightarrow$ U11 termal PGND pedi arasındaki mesafe yalnızca $\approx 24\text{ mm}$'dir.
   - Bu kompakt çevre, yüksek frekanslı parazitik endüktansı minimuma indirerek anahtarlama dalgalanmalarını (ringing) bastırır.

---

## 5. Gerçek Zamanlı Saat Kristali (Y1) Analizi

- **Komponent:** `Y1` 32.768 kHz Tuning Fork SMD Kristal ($3.2 \times 1.5\text{ mm}$, 4 pad).
- **Bağlı Entegre:** `U4` BQ32000 Gerçek Zamanlı Saat (SOIC-8).
- **Fiziksel Yerleşim:**
  - `Y1` Konumu: `B.Cu` $(143.00, 89.00)$
  - `U4` Konumu: `B.Cu` $(143.00, 82.00)$
  - Her iki bileşen de $X = 143.00\text{ mm}$ ekseninde kusursuz doğrusal hizalanmıştır.
- **Bağlantı Mesafeleri:**
  - Merkez-merkez mesafesi: **7.00 mm**
  - Y1 Pad 1 $\rightarrow$ U4 Pin 1 (`OSCI`): **8.98 mm**
  - Y1 Pad 4 $\rightarrow$ U4 Pin 2 (`OSCO`): **10.61 mm**
  - Y1 Pad 2 ve Pad 3: `GND` kılıf topraklaması.
- **Döngü Alanı ve Gürültü Bağışıklığı:**
  - OSCI/OSCO osilatör döngü alanı $< 18\text{ mm}^2$'dir.
  - Güç anahtarlama hatlarından (Buck LX düğümüne $> 20\text{ mm}$, Boost SW düğümüne $> 50\text{ mm}$) emniyetli mesafede izole edilmiştir.
  - In1.Cu iç zemin düzlemi osilatör hattının hemen üzerinde tam ekranlama sağlar.

---

## 6. Entegreler Arası Sinyal Bütünlüğü ve Koruma Zinciri

```mermaid
flowchart LR
    subgraph SENSE["Algılama Katı (B.Cu)"]
        U3["U3: INA226\n(Akım/Gerilim Monitörü)"]
    end

    subgraph MCU_CTRL["Kontrol Katı (F.Cu)"]
        U2["U2: ESP32-C6\n(Ana İşlemci)"]
    end

    subgraph LOGIC_GATE["Lojik Güvenlik (B.Cu)"]
        U13["U13: 74LVC1G08\n(VE Kapısı)"]
    end

    subgraph ACTUATION["Güç Anahtarlama & Deşarj"]
        U12["U12: LM74801\n(F.Cu - İdeal Diyot & Güç FET)"]
        Q5["Q5: SQJB60EP\n(F.Cu - Çıkış Güç FET'i)"]
        Q4["Q4: BSS138P\n(B.Cu - Deşarj Sürücü)"]
        Q6["Q6: BSS138P\n(F.Cu - Aktif Deşarj FET)"]
    end

    U3 -- "INA_ALERT (Pin 3)\n[15.87 mm]" --> U13
    U2 -- "OUT_EN (Pin 15)" --> U13
    U13 -- "SW_EN (Pin 4)\n[19.79 mm]" --> U12
    U12 -- "HGATE / DGATE\n[3.94 mm]" --> Q5
    U13 -- "SW_EN (Pin 4)\n[11.15 mm]" --> Q4
    Q4 -- "DISCH_G\n[4.50 mm]" --> Q6
```

### 6.1. Hızlı Donanımsal Koruma ve Aktif Deşarj Zinciri Analizi:
1. **Algılama (U3 $\rightarrow$ U13):**
   - INA226 Pin 3 (`INA_ALERT`), U13 VE kapısının Pin 2'sine **15.87 mm** mesafeyle bağlanır. Her iki eleman da `B.Cu` katmanındadır.
   - Aşırı akım durumunda INA226 `ALERT` pini lojik LOW seviyesine çekilir.
2. **Lojik Karar (U13):**
   - 74LVC1G08 VE kapısı, MCU'dan gelen `OUT_EN` ile INA226'dan gelen `INA_ALERT` sinyallerini donanımsal olarak birleştirir.
   - Her iki sinyal de HIGH olmadığı sürece çıkış `SW_EN` (Pin 4) LOW kalır.
   - U13 yayılım gecikmesi yalnızca $\approx 2.5\text{ ns}$'dir.
3. **Güç Kesme (U13 $\rightarrow$ U12 $\rightarrow$ Q5):**
   - `SW_EN` sinyali U12 (LM74801) Pin 6'ya ulaşır.
   - `SW_EN` LOW olduğunda LM74801 çıkış kapısını (`HGATE`) $< 1\ \mu\text{s}$ içinde kapatarak Q5B'yi yalıtır ve yükü kaynaktan ayırır.
4. **Hızlı Aktif Deşarj (U13 $\rightarrow$ Q4 $\rightarrow$ Q6):**
   - Eşzamanlı olarak `SW_EN` sinyali Q4 N-FET'inin kapısına (Pin 1, mesafe **11.15 mm**) gider.
   - `SW_EN` LOW olduğunda Q4 kesime gider; `DISCH_G` hattı R57 üzerinden şarj olarak Q6'yı (mesafe **4.50 mm**) iletime sokar.
   - Çıkıştaki filtre kondansatörleri R59 deşarj direnci üzerinden hızla toprağa boşaltılır.

### 6.2. Diğer IC Arayüzleri:
- **U2 $\leftrightarrow$ U1 (I2C Seviye Dönüştürme):** U2 (3.3V) ile U1 (5V) arasındaki I2C iletişimi Q1 ve Q2 lojik FET'leri üzerinden güvenle yalıtılmıştır.
- **U2 $\leftrightarrow$ U3 / U4 (3.3V I2C Veri Yolu):** U3 (INA226) ve U4 (BQ32000), U2'nin yerel 3.3V I2C veri yoluna doğrudan bağlıdır. Ortak In1.Cu zemin düzlemi sayesinde sinyal dönüş yolları kesintisizdir.

---

## 7. Doğrulama ve DRC Metrikleri

- **KiCad DRC Komutu:** `kicad-cli pcb drc --schematic-parity hardware/gopo.kicad_pcb`
- **İhlal Sayısı:** 164 ihlal (TASK-098 taban değeriyle birebir aynı; 0 yeni ihlal).
- **Şematik Paritesi:** **0 schematic parity issue** (%100 şematik-layout uyumu).
- **Bağlantısız Öğeler:** 360 (Taban korundu; routing TASK-087'de tamamlanacak).
- **Doğrulama Verisi:** `hardware/docs/reports/task-099-20260928/active_magnetic_audit.json` dosyasında tüm koordinat ve mesafe matrisi saklanmıştır.

---

## 8. Sonuç ve Öneriler

TASK-099 kapsamındaki tüm aktif komponentler (`D1`–`D10`, `Q1`–`Q8`), manyetik bileşenler (`L1`, `L3`), osilatör (`Y1`) ve IC sinyal zincirleri fiziksel yerleşim, katman uyumu ve elektriksel kurallar açısından eksiksiz incelenmiş ve **onaylanmıştır**.

### TASK-087 Routing Kılavuz İlkeleri:
1. `D4` Anot $\leftrightarrow$ `U11` SW ve `D4` Katot $\leftrightarrow$ `C27`/`C28` arasına B.Cu üzerinde geniş katı poligon dökülmelidir.
2. `D2` Katot $\leftrightarrow$ `U5` LX ve `L1` Pad 1 arasına en az 1.5 mm genişliğinde kısa poligon bağlanmalıdır.
3. `Y1` kristalinin OSCI ve OSCO hatları diferansiyel çift olarak eşit uzunlukta çekilmeli ve altındaki In1.Cu zemin düzlemi bölünmemelidir.
4. `U12` DGATE hattı (Pin 1 $\rightarrow$ Q5 Pin 4) ve HGATE hattı (Pin 8 $\rightarrow$ Q5 Pin 2) doğrudan üst katta (`F.Cu`) via kullanılmadan yönlendirilmelidir.

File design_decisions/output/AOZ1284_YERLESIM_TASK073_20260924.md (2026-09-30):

# AOZ1284 buck ilişkisel yerleşimi — TASK-073, 24 Eylül 2026

19 üyeli AOZ1284 3.3V BUCK grubu B.Cu'da düzenlendi. U5, L1, D2, giriş
ve çıkış kapasiteleri aynı yüzdedir; U6/R50/R51 ortak REF/EN_CTRL ağı
TPS55340 sınırında kaldı. Blok geçici kart dışı yerleşimdedir. Nihai kart
konumu ve tamamlanmış güç routing'i bu aşamada seçilmedi.

[Önce görünüm](../../hardware/docs/reports/task-073-20260924/before.svg) ·
[Sonra/koridor görünümü](../../hardware/docs/reports/task-073-20260924/after.svg) ·
[KiCad B.Cu katman çıktısı](../../hardware/docs/reports/task-073-20260924/board-bottom.svg) ·
[x/y/açı/yüz, pad ve ölçüm envanteri](../../hardware/docs/reports/task-073-20260924/verification.json)

## Üretici kuralı ve pad karşılığı

Kaynak: [AOS AOZ1284PI veri sayfası, Rev. 1.1 (Mart 2025),
“Thermal Management and Layout Consideration”, s. 12–13](https://aosmd.com/res/data_sheets/AOZ1284PI.pdf).
Bu veri sayfası iki darbeli akım döngüsünü küçültmeyi, giriş kapasitörünü
VIN/GND'a yaklaştırmayı, LX–L–Cout–GND yolunu kısaltmayı, VIN/GND'de
thermal relief kullanmamayı ve FB/COMP'yi LX'ten ayırmayı önerir. Mesafe
sınırı vermediğinden aşağıdaki mm değerleri **ölçülen proje geometrisidir**,
üretici şartı değildir. TASK-069 genel kaynak tablosu henüz tamamlanmadığı
için bu grubun kaynak/pin eşlemesi burada kaydedildi.

| Ağ / kural | PCB ilişkisi ve ayrılan koridor |
| --- | --- |
| Giriş/Cin–U5 yüksek di/dt | C13/C12 V_PRE → U5.9 termal V_PRE pad; C12.1 (92,30;57,385)–U5.9 (98,20;56,31) 6,00 mm. C12/C13 GND'den U5.3 GND ve güç GND alanına B.Cu dönüşü ayrıldı. U5 VIN/GND bağlantısı için thermal relief kullanılmamalı. |
| U5 LX–D2–L1 | U5.1 LX (100,703;54,405)–D2.1 LX (102,90;54,50) 2,20 mm; U5.1–L1.1 LX (101,12;48,37) 6,05 mm. D2.2 GND (105,70;54,50) doğrudan güç GND alanına dönmeli. LX bakırı bu üç padin çevresinde kalmalı, sinyal ağına yayılmamalı. |
| L1–Cout–GND | L1.2 +3.3V (95,87;48,37)–C16.1 (91,50;46,825) 4,64 mm; C16.1–C15.1 4,09 mm. C16 yakın seramik, C15 daha büyük çıkış deposudur. İki kapasitörün GND dönüşü D2/U5 güç dönüşüyle aynı yüzde, kısa ve geniş bakırla kurulmalı. |
| Bootstrap, SS, FSW | C17.1 BST → U5.2, C17.2 LX → U5.1; C18.1 SS → U5.7; R38.1 FSW → U5.4. Bu parçalar U5'in ilgili pin taraflarına taşındı. |
| FB/COMP sessiz dönüş | U5.6 FB → R39.2 5,49 mm, R39/R40 paylaşılmış FB noktası; U5.5 COMP → R41.1 2,57 mm, R41/C19 seri ağı. Bu ağlar U5'in sol-altından çıkar; sağ/üstteki LX koridorundan geçmez. GND uçları U5.3/güç GND'ye ayrı sessiz kolla bağlanmalı. |
| Termal bakır | U5.9 V_PRE ısıl pad, U5.3 GND, D2.2 GND ve L1 çevresinde B.Cu bakır/via alanı bırakıldı. R43 büyük güçlü direnç için x≈86–90, y≈60–68 mm ısıl zarf korundu. Via, zone ve iz geometrisi nihai routing aşamasında eklenecek. |

Oklar [sonra görünümünde](../../hardware/docs/reports/task-073-20260924/after.svg)
planlanan giriş/çıkış/GND ve hassas sinyal yönlerini gösterir; yeni bakır izi
çizilmiş olduğu anlamına gelmez. [TI TLV431x veri sayfasındaki DBZ pin
tablosu](https://www.ti.com/lit/ds/symlink/tlv431.pdf) ile PCB pad neti
karşılaştırıldı: U6.1 REF, U6.2 katot/EN_CTRL, U6.3 anot/GND.

## BOOST ile ortak V_X sınırı

D5.1 EN_CTRL → U6.2 doğrusal pad mesafesi 18,09 mm. Bu yol düşük akımlı
kontrol/referans hattı olarak, boost SW ve buck LX bakırlarından ayrı
tutulmalı. U6.1 REF → R51.1 4,12 mm, U6.1 → R50.2 5,01 mm,
R51.1–R50.2 1,88 mm; REF düğümü için R50/R51 U6'nın altına taşındı.
R43.2 EN_CTRL (88,00;61,038) U6/R50 yönüne, R43.1 V_PRE
(88,00;66,963) C28.1'e bakar; C28.1–R43.1 5,41 mm.

Boost C28 (82,00;64,00) yerinde bırakıldı: B.Cu'da C28 ile R43 arasında
1,72 mm courtyard aralığı, ayrıca V_PRE için alt/sağ çıkış yönü vardır.
C28–buck C13 V_PRE pad merkezleri 8,38 mm'dir; bu ikinci boost kapasitörü
D4/C27'nin ana kısa döngüsünün parçası sayılmamalıdır. Nihai V_PRE bakırı
ve GND dönüşü TASK-085/routing incelemesinde doğrulanmalı. D5.2–U11.9
BOOST_FB izi değişmedi: aynı dört B.Cu segment UUID'si, 2,584607 mm.

## Kontrol ve açık sınır

- 19 grubun UUID, pad/net, üyelik ve yüzü korundu; D2 polaritesi pad1 LX,
  pad2 GND. J3/J9/H1–H4 ve U11/D5 ankrajları değişmedi.
- `kicad-cli pcb drc --schematic-parity`: **146→146** mevcut ihlal,
  **360→360** bağlantısız öğe, **0→0** schematic parity. Yeni courtyard,
  clearance, kısa devre, board-edge veya lehim maskesi ihlali yok.
  Mevcut 146 bulgu: 63 yazı yüksekliği, 63 yazı kalınlığı, 15 drill aralığı,
  4 J7 hole clearance, 1 D10 silk over copper. 360 bağlantısız öğe kartın
  henüz tamamlanmamış routing'inden kaynaklanan ayrı envanterdir.
- Başka yüze flip, kart içine son taşıma veya yeni zone/iz sonrasında
  yüksek akım döngüleri, U5 termal pad, R43 ısısı ve D5–U11 FB sürekliliği
  yeniden kontrol edilmelidir. Mevcut ölçüler pad merkezleri arasındaki
  doğrusal uzaklıktır, henüz route edilmiş iz uzunluğu değildir.

Kanıt: [DRC önce](../../hardware/docs/reports/task-073-20260924/drc-before.json),
[DRC sonra](../../hardware/docs/reports/task-073-20260924/drc-after.json),
[doğrulama betiği](../../hardware/docs/reports/task-073-20260924/verify.py).

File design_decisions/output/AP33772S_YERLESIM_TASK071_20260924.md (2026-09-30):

# AP33772S PD denetleyici ve VBUS şönt/anahtar grubu ilişkisel yerleşimi — TASK-071, 24 Eylül 2026

AP33772S PD denetleyici grubunun 23 footprint üyesi (U1, Q3, R11, TH1, D1, C1–C4,
C8, R8, R9, R12–R14, R21, R64, R65, TP1–TP5) B.Cu katmanında yüksek akım güç yolu,
Kelvin akım algılama, gate sürüşü, bypass/filtre kapasiteleri ve CC çıkış yönlerine
göre ilişkisel olarak yerleştirildi. Yirmi üç footprint'in grup üyeliği, UUID,
pad/net bağlantıları ve B.Cu yüzü korundu. Kart dışındaki geçici blok alanı
(x≈46–71, y≈134–156 mm) korunmuştur; nihai kart içine taşıma ve genel routing
TASK-085/TASK-008 kapsamındadır.

[Önce görünüm](../../hardware/docs/reports/task-071-20260924/before.svg) ·
[Sonra ve koridorlar](../../hardware/docs/reports/task-071-20260924/after.svg) ·
[KiCad B.Cu katman çıktısı](../../hardware/docs/reports/task-071-20260924/board-bottom.svg) ·
[x/y/açı/yüz ve pad ölçümleri](../../hardware/docs/reports/task-071-20260924/verification.json)

## Kaynak, pin ve yerleşim kuralı

- **Diodes Inc. AP33772S (DS46176 Rev. 10-2, Ağustos 2026, s. 18, “PCB Layout Guideline”):**
  1. *VCC/V5V decoupling capacitor:* C4 (1.0 µF, 0402) Pin 20 (`PD_5V`) yanına yerleştirildi
     (pad merkezleri arası 3,73 mm); Pin 20 LDO gürültüsünü filtreler. C1 (100 nF, 0402) Pin 12
     (`Net-(U1-V18)`) yanına yerleştirildi (pad merkezleri arası 3,11 mm).
  2. *Exposed pad (Pad 25):* IC altındaki termal pad doğrudan GND'ye bağlanacak şekilde
     bırakıldı; termal via alanı ve gürültü bağışıklığı korundu.
  3. *Current sensing traces:* Algılama hatları doğrudan akım algılama direncinin (R11)
     footprint padlerinden Kelvin olarak başlayacak şekilde planlandı. R11.1 (`USB_VBUS`)
     ve R11.2 (`PD_VBUS_SENSED`) uçlarından U1.1 ve U1.24 pinlerine giden algılama hatları,
     ana güç akım yolunun dışından bağımsız diferansiyel çift olarak ayrıldı.
  4. *CC1/CC2 connections:* Type-C konnektörüne mümkün olan en kısa yolla bağlanmalıdır.
     U1 180° açıya çevrilerek Pin 17 (`USB_CC1`) ve Pin 16 (`USB_CC2`) doğrudan sol kenara
     (USB-C J7 ve D8/D9 koruma tarafına) bakan taraftan çıkarıldı.
- **Vishay SQJB60EP (PowerPAK SO-8L Dual N-MOSFET):**
  - Q3 0° açıyla yönlendirildi. Sol yarısı Drain 1 (Pin 7, 8: `PD_VBUS_SENSED`) R11.2 şönt
    çıkışına bakar (R11.2–Q3.7 mesafesi 2,265 mm; geniş bakır koridoru). Sağ yarısı Drain 2
    (Pin 5, 6: `PD_VOUT`) çıkış filtresi C8'e bakar (Q3.5–C8.1 mesafesi 5,513 mm).
  - Gate uçları (Pin 2, 4: `PD_GATE`) üst/iç kenardadır; U1.23 (`PWR_EN`) pininden R12 (6.2 kΩ)
    üzerinden sürülür (U1.23–R12.1 3,038 mm; R12.2–Q3.2 7,515 mm).
- **TH1 NTC Termistör (10 kΩ, 0402):**
  - U1 Pin 13 (`Net-(U1-OTP)`) aşırı sıcaklık koruma girişidir. TH1 doğrudan Q3 güç MOSFET'inin
    gövde ve termal drain yayılım alanının bitişiğine (56,0; 145,2) yerleştirildi
    (U1.13–TH1.2 mesafesi 7,911 mm). Böylece yüksek akım altındaki anahtarlama FET'inin
    sıcaklığı hassas biçimde izlenebilir.
- **VBUS cSnkBulk Kapasitesi (C3 2.2 µF / 50V X7R, 0805):**
  - USB-PD standardı cSnkBulk (1–10 µF) gereksinimi için R11.2 / Q3.7 düğümünde giriş tarafına
    yakın konumlandırıldı (51,5; 145,0). TASK-070 devir notuna uygun olarak D3.1 (`USB_VBUS`)
    ile C3.1 (`PD_VBUS_SENSED`) net ayrımı korundu.
- **Test Noktaları (TP1–TP5, TestPoint_Pad_D1.0mm):**
  - TP1: `USB_VBUS` (R11 girişinde, 46,5; 140,0)
  - TP2: `PD_VBUS_SENSED` (R11 çıkışı / Q3 Drain 1'de, 54,5; 135,5)
  - TP3: `PD_VOUT` (Q3 Drain 2 / C8 çıkışında, 69,5; 140,0)
  - TP4: `PD_5V` (U1.20 5V LDO çıkışında, 52,0; 149,0)
  - TP5: `PD_GATE` (Q3 gate sürüş hattında, 61,0; 134,5)
  - Tüm test noktaları grup çevresine, prob erişimine açık ve elemanları engellemeyecek
    şekilde yerleştirildi.

| Alt Devre / Koridor | Elemanlar ve Pad/Net Yönü |
| --- | --- |
| Güç Girişi & Şönt | `USB_VBUS` → TP1 (46,5; 140,0) → R11.1 (49,05; 140,0) → 5m0 şönt → R11.2 `PD_VBUS_SENSED` (54,95; 140,0). |
| Giriş Bulk & Kelvin | C3 (51,5; 145,0) bulk deşarjı; R11.1–U1.1 (15,89 mm) ve R11.2–U1.24 (10,60 mm) bağımsız Kelvin algılama hatları. |
| Güç Anahtarı (Q3) | R11.2 → Q3.7/8 Drain 1 (2,265 mm kısa güç yolu); Q3.5/6 Drain 2 → C8.1 (65,5; 138,5) `PD_VOUT` çıkış yolu (5,51 mm). |
| Gate Sürüşü | U1.23 (`PWR_EN`) → R12.1 (3,04 mm) → R12.2 → Q3.2/4 (`PD_GATE`) & TP5 (61,0; 134,5). |
| VOUT Algılama | Q3.5/C8.1 (`PD_VOUT`) → R13.2 (6,39 mm) → R13.1 → U1.22 (`Net-(U1-VOUT)`). |
| LDO & Filtre Bypass | C4.1 (1 µF) → U1.20 `PD_5V` (3,73 mm); C1.1 (100 nF) → U1.12 `V18` (3,11 mm); C2.1 (100 nF) → U1.15 `IFB` (3,11 mm). |
| CC Hatları Çıkışı | U1.17 (`USB_CC1`) ve U1.16 (`USB_CC2`) sol kenara (USB-C J7 tarafına) serbest koridorla yöneltildi. |
| Dijital / MCU Arayüzü | U1.4/5 (`I2C SDA/SCL`) sağ kenara; U1.9 (`PD_INT_5V`) → R8/R64/R65/R9 gerilim bölücü → `PD_INT_3V3` sağ/alt kenara. |
| LED Göstergesi | U1.8 (`Net-(U1-LED)`) → R14 (64,2; 150,5) → D1 LED (67,2; 150,5). |

## AP33772S ve komşuluk / devir notları

1. **USB-C GIRIS (TASK-070 Devri):**
   - J7 konnektörü ve D8/D9 koruma elemanlarından çıkan CC1 ve CC2 hatları U1.17 ve U1.16 pinlerine
     sol koridordan bağlanacaktır.
   - D3 TVS korumasından gelen `USB_VBUS` hattı R11.1 girişine bağlanacaktır.
2. **Pre-Boost & Buck (TASK-072 / TASK-073 Devri):**
   - Q3.5 ve C8.1'deki `PD_VOUT` ana güç rayı downstream TPS55340 pre-boost ve AOZ1284 buck
     gruplarına besleme aktaracaktır.
3. **Mekanik ve Son Yerleşim:**
   - Kart dışındaki blok konumu (x≈46–71, y≈134–156 mm) geçicidir. TASK-063 ve TASK-085 ile kart
     içine taşındığında yüksek akım döküm alanları ve Kelvin diferansiyel izleri nihai
     rotaya göre bağlanmalıdır.

## Doğrulama

- `kicad-cli pcb drc --schematic-parity`:
  - **DRC ihlalleri:** **146 → 146** (yeni courtyard, clearance, short, edge veya mask ihlali: **0**).
    Mevcut 146 bulgu: 63 text height, 63 text thickness, 15 drill out of range, 4 J7 hole clearance, 1 D10 silk/mask.
  - **Bağlantısız öğeler:** **360 → 360** (tamamlanmamış genel routing envanteri korundu).
  - **Schematic parity:** **0 → 0**.
- **Courtyard kontrolü:** 23 eleman arasında minimum courtyard aralığı **0,215 mm** (U1–R14 arası); çakışma **0**.
- **Ankrajlar ve izler:** J7, J3, J9, H1–H4, D5, U11 konum/açı/yüz ankrajları ve mevcut iz UUID'leri tamamen korundu.

Kanıt dosyaları:
- [DRC önce](../../hardware/docs/reports/task-071-20260924/drc-before.json)
- [DRC sonra](../../hardware/docs/reports/task-071-20260924/drc-after.json)
- [Doğrulama ve pad ölçüm verileri](../../hardware/docs/reports/task-071-20260924/verification.json)
- [Yerleşim betiği](../../hardware/docs/reports/task-071-20260924/place.py)
- [Doğrulama betiği](../../hardware/docs/reports/task-071-20260924/verify.py)

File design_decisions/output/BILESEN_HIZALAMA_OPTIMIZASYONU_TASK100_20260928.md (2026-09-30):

# Bileşenlerin Yatay ve Dikey Hizalanması ile Yerleşim Alanı Optimizasyonu (TASK-100)

**Tarih:** 28 Eylül 2026  
**Durum:** ONAYLANDI / UYGULANDI  
**Etkilenen Dosyalar:** `hardware/gopo.kicad_pcb`  
**Referans Rapor:** `hardware/docs/reports/task-100-20260928/bilesen_hizalama_raporu.md`  

---

## 1. Karar Özeti

1. **Mikro-Ofsetlerin Temizlenmesi:** Boost dönüştürücü (U11) ve Buck dönüştürücü (U5) etrafındaki pasif ve aktif elemanların koordinatlarındaki `.11`, `.16`, `.36`, `.66`, `.76`, `.96` mm rastgele mikro-ofsetleri temizlenerek komponentler 0.5 mm ve 0.25 mm ortak eksen grid raylarına oturtulmuştur.
2. **Ortogonal Hizalama Eksenleri:**
   - Boost giriş bulk kapasitörleri `C25` ve `C29` $X = 87.50\text{ mm}$ rayında kolon olarak hizalanmıştır.
   - Boost yüksek frekans ve çıkış kapasitörleri `C26` ve `C27` $X = 104.00\text{ mm}$ rayında kolon olarak hizalanmıştır.
   - Buck giriş kapasitörleri `C12` ve `C13` $Y = 105.00\text{ mm}$ ortak rayına oturtulmuş, aralarındaki adım $3.80\text{ mm}$ olarak sabitlenmiştir.
   - Kompanzasyon direnç ve kapasitörleri `R49`, `C24`, `R52` $Y = 128.00\text{ mm}$ ortak rayına; `C23` ve `R53` $Y = 125.50\text{ mm}$ ortak rayına oturtulmuştur.
3. **Yönelim Açılarının Ortogonal Standartlara Normalizasyonu:** PCB üzerindeki tüm R, C, D ve transistör/FET'lerin yönelimleri 0°, 90°, 180°, 270° ortogonal standartlarına normalize edilmiştir. 0 adet açılı/diyagonal yerleşim kalmıştır.
4. **Kesintisiz Yönlendirme Koridorları:** Komponentlerin doğrusal raylara çekilmesiyle `PD_VOUT`, `V_PRE`, `+3.3V` ve katı GND poligon akışı için serbest bakır alanı genişletilmiş, TASK-087 genel kart routing işlemine elverişli koridorlar açılmıştır.
5. **DRC ve Şematik Paritesi:** KiCad 10 DRC çalıştırılmış; taban 164 ihlal korunmuş (0 yeni ihlal), şematik paritesi %100 (0 parity issue), bağlantısız nesneler 360 (taban korundu) olarak doğrulanmıştır.

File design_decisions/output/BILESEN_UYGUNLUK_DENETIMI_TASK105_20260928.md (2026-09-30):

# Bileşenlerin IPC Kurallarına ve Estetik Standartlara Uygunluk Denetimi — TASK-105, 28 Eylül 2026

## 1. Karar ve Denetim Özeti

REV_C PCB tasarımı üzerindeki tüm 144 komponentin (85 pasif R/C, 10 IC, 10 diyot, 8 transistör/FET, 2 güç indüktörü, 1 kristal osilatör, 14 test noktası, 5 konnektör, 2 buton, 4 montaj deliği ve mekanik modeller); TASK-104 kapsamında belirlenen IPC-7351 Yüksek Yoğunluk (Least/High-Density Courtyard) kurallarına, grid hizalama standartlarına, ortogonal rotasyon normalizasyonuna, entegre dekuplaj önceliğine ve mekanik ankraj toleranslarına tam uyumluluğu uçtan uca denetlenmiş ve **%100 BAŞARI (PASS)** ile onaylanmıştır.

## 2. Onaylanan Uygunluk Standartları ve Metrikler

1. **IPC-7351 Least Courtyard ve Açıklık Standartları:**
   - 144 komponentin tamamında avlu sınırları denetlenmiş; **0 avlu çakışması (`courtyards_overlap`)** ve **0 üretim tolerans ihlali** teyit edilmiştir.
2. **Grid Kilidi (%100 Grid Rayı Uyumu):**
   - 85 pasif bileşenin (R, C) tamamı (%100.0) $0.50\text{ mm}$ (59 adet) veya $0.25\text{ mm}$ (26 adet) mühendislik gridine kilitlenmiştir.
   - Kart genelinde grid dışı (**off-grid**) kalan pasif sayısı **0 adettir**.
3. **Doğrusal Raylar ve Homojen Adım:**
   - AP33772S B.Cu $Y=125.500\text{ mm}$ rayı (`R21, R8, R64, R65, R9`) $2.250\text{ mm}$ homojen adımla ortak eksende doğrulanmıştır.
   - Aktif deşarj F.Cu $Y=107.500\text{ mm}$ rayı (`R55, R56, R58`) $2.250\text{ mm}$ homojen adımla ortak eksende doğrulanmıştır.
   - Boost ve Buck kompanzasyon/giriş rayları standart adımlarla onaylanmıştır.
4. **Yönelim (Rotasyon) Ortogonalliği:**
   - Kart üzerindeki 144 komponentin tamamı (%100) kesinlikle ortogonal ($0^\circ, 90^\circ, 180^\circ, 270^\circ$) açılardadır. Sıfır adet diyagonal/açılı eleman bulunmaktadır.
   - Paralel I2C pull-up matrisleri (R4/R7 $0^\circ$, R5/R6 $90^\circ$), enkoder dizisi (R34-R36 $0^\circ$) ve USB seri dirençleri (R2/R3 $90^\circ$) tekdüze yönelim standardına kavuşturulmuştur.
5. **Entegre Dekuplaj Döngüleri:**
   - Entegre güç pinlerine ait 15 kritik bypass/dekuplaj kapasitörü (C1, C4, C9, C11, C14, C18, C23, C26, C27, C32, C35 vb.) doğrudan bitişik (en yakın $1.88\text{ mm}$, çoğunlukla $<5.5\text{ mm}$) konumda en dar akım döngüsünü sağlamaktadır.
6. **Mekanik ve RF Ankrajlar:**
   - H1–H4 montaj delikleri, J7 USB-C, J8 RJ45, J9 Enkoder, J3 LCD, J4 Klemens, MECH_ENC ve U2 RF modülü konumları **0,0000 mm sapma ile** doğrulanmıştır.

## 3. Doğrulama ve Rapor Referansları

- **Otomasyon Denetim Scripti:** `scratch/audit_task104_compliance.py`
- **Sayısal Veri Çıktısı (JSON):** `hardware/docs/reports/task-105-20260928/audit_task104_compliance.json`
- **Ayrıntılı Donanım Raporu:** `hardware/docs/reports/task-105-20260928/bilesen_uygunluk_denetim_raporu.md`
- **KiCad 10 DRC & Parite:**
  - `kicad-cli pcb drc --schematic-parity hardware/gopo.kicad_pcb`
  - Toplam DRC İhlali: **165 ihlal** ($\le 165$ tabanı korunmuş, **0 YENİ İHLAL**).
  - Şematik Paritesi: **0 schematic parity issue** (%100 tam uyum).
  - Bağlantısız Öğeler: **360 unconnected items** (Taban korunmuş, TASK-087 routing aşamasına devredilmiştir).

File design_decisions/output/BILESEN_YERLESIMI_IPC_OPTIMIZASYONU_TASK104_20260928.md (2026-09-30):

# Bileşen Yerleşiminin IPC Yüksek Yoğunluk ve Estetik Kurallarına Göre Optimizasyonu — TASK-104, 28 Eylül 2026

## 1. Karar Özeti

REV_C PCB tasarımı üzerindeki 85 adet pasif komponentin (direnç ve kapasitör) yerleşimi; IPC-7351 Yüksek Yoğunluk (Least/High-Density Courtyard) standartlarına, ortak eksen çizgilerine, tutarlı grid raylarına ve dekuplaj akım döngüsü önceliğine göre optimize edilmiştir.

## 2. Temel İlkeler ve Kararlar

1. **IPC-7351 Yüksek Yoğunluk (Least Courtyard):**
   - Komponentler arasındaki gereksiz gevşek mesafeler giderilerek lehimlenebilirlik ve avlu sınırları dahilinde en sıkı yerleşim sağlanmıştır.
   - Paralel pasif dizilerinde (örneğin AP33772S B.Cu $Y=125.50\text{ mm}$ rayı) adım (pitch) $2.25\text{ mm}$ olarak standartlaştırılmıştır.
   - F.Cu $Y=107.50\text{ mm}$ hattındaki deşarj direnç dizisi ($R55, R56, R58$) $2.25\text{ mm}$ adımla hizalanmıştır.
2. **Grid Raylarına Oturtma (%100 Grid Kilidi):**
   - Öncesinde 31 pasifte bulunan rastgele mikro-ofsetler (`.15`, `.35`, `.55`, `.58`, `.70`, `.80` mm) temizlenmiştir.
   - 85 pasif elemanın 59 adedi $0.50\text{ mm}$, 26 adedi $0.25\text{ mm}$ gridine tam kilitlenmiştir. Kartta grid dışı kalan (off-grid) pasif sayısı **0 adettir**.
3. **Yönelim (Rotasyon) Standartlaştırması:**
   - Kart üzerindeki 144 komponentin tamamı kesinlikle ortogonal ($0^\circ, 90^\circ, 180^\circ, 270^\circ$) standartlara getirilmiştir.
   - I2C pull-up matrisinde R4 ($180^\circ$) açısı R7 ($0^\circ$) ile aynı hizaya getirilerek tekdüzelik sağlanmıştır.
4. **Dekuplaj Döngüleri:**
   - Entegre dekuplaj kapasitörleri (C1, C4, C9, C11, C14, C26, C27, C32, C35) hedef güç pinlerine $<5.5\text{ mm}$ (çoğunlukla $<3.5\text{ mm}$) mesafede tutulmuştur.
5. **Mekanik Bütünlük:**
   - Mekanik montaj delikleri (`H1–H4`), panel konnektörleri (`J7`, `J8`, `J9`, `J3`, `J4`, `MECH_ENC`) ve `U2` modül konumları korunmuştur.

## 3. Doğrulama

- **KiCad 10 DRC:** `kicad-cli pcb drc --schematic-parity hardware/gopo.kicad_pcb`
  - DRC Hataları/İhlalleri: **165 ihlal** (Taban 167 korunmuş, 2 adet `silk_overlap` giderilmiş, **0 YENİ İHLAL**).
  - Şematik Paritesi: **0 schematic parity issue** (%100 tam uyum).
  - Bağlantısız Öğeler: **360 unconnected items** (Taban korunmuş, TASK-087 routing'e devredildi).
- **Ratsnest Testi:** 127 sinyal hattında 161 kesişim ve $1342.15\text{ mm}$ tel uzunluğu doğrulanmıştır.

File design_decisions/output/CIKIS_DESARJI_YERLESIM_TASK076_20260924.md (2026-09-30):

# Çıkış deşarjı grubu ilişkisel yerleşimi — TASK-076, 24 Eylül 2026

Aktif çıkış deşarjı grubunun (`CIKIS DESARJI (R59 yerine aktif)`) 5 footprint üyesi (Q4, Q6, D10, R66, R67), güncel şemadaki Q4/Q6 sürme, D10 clamp, R67 güç ve akım yolu ile U13 SW_EN kontrol mantığına göre ilişkisel olarak yerleştirildi. Beş footprint'in grup üyeliği, UUID, pad/net bağlantıları ve TASK-065 yüz atamaları (Q4 B.Cu; Q6, D10, R66, R67 F.Cu) korunmuştur. Kart dışındaki geçici blok alanı (x≈180–200, y≈55–65 mm) düzenlenmiştir; nihai kart içine taşıma ve genel routing TASK-085/TASK-008 kapsamındadır.

[Önce görünüm](../../hardware/docs/reports/task-076-20260924/before.svg) ·
[Sonra ve koridorlar](../../hardware/docs/reports/task-076-20260924/after.svg) ·
[KiCad F.Cu katman çıktısı](../../hardware/docs/reports/task-076-20260924/board-top.svg) ·
[KiCad B.Cu katman çıktısı](../../hardware/docs/reports/task-076-20260924/board-bottom.svg) ·
[x/y/açı/yüz ve pad ölçümleri](../../hardware/docs/reports/task-076-20260924/verification.json)

## Kaynak, pin ve yerleşim kuralı

- **Nexperia BSS138P (Rev. 2 — 11 Aralık 2020, SOT-23 / TO-236AB):**
  1. *Deşarj anahtarı Q6 (F.Cu, rot 180°):*
     - Pin 3 (`Net-(Q6-D)` / Drain) doğrudan batıya, R67.2 pad'ine baktırıldı (y=57,5 mm doğrusal ekseninde, pad aralığı **2,60 mm**).
     - Pin 1 (`DISCH_G` / Gate) güney-doğuya, Pin 2 (`GND` / Source) kuzey-doğuya açıldı.
     - $V_{DS} = 60\text{ V} > 30,4\text{ V}$, $I_D = 360\text{ mA} \gg 30,3\text{ mA}$, $R_{DS(on)} \approx 2\ \Omega \ll 1000\ \Omega$.
  2. *Tersleyici anahtar Q4 (B.Cu, rot 0°):*
     - TASK-065 yüz atamasına uygun olarak B.Cu'da tutuldu (U13 ile aynı yüzey).
     - Pin 1 (`SW_EN`) batıya (U13 yönüne) yönlendirildi; logic 3.3V gate sürüşü ile $V_{GS} = 3,3\text{ V} > V_{GS(th)}$ (maks 1,5 V) güvenli tam iletim sağlar.
     - Pin 2 (`GND`) batı/kuzey-batıya, Pin 3 (`DISCH_G`) doğuya açıldı.
     - Q4.3 ile Q6.1 arasında B.Cu'dan F.Cu'ya geçiş için (x≈192, y≈60,5) konumunda tek bir sinyal viası planlanmıştır (pad mesafesi 4,08 mm).

- **PANJIT BZT52C12 (Rev. 01 — 2014, SOD-123):**
  - Pin 1 (Katot) güneyde `DISCH_G` koridoruna; Pin 2 (Anot) kuzeyde `GND` koridoruna bağlandı (rot 90°).
  - Q6.1–D10.1 (`DISCH_G`) ve Q6.2–D10.2 (`GND`) hatları paralel, kesişimsiz iki doğrusal koridor oluşturur (**3,63 mm**).
  - $V_Z = 12\text{ V}$ kenetleme gerilimi, Q6 BSS138P gate-source sınırını ($\pm 20\text{ V}$) güvenli aralıkta tutar ($P_D = 500\text{ mW} \gg 1,4\text{ mW}$).

- **Vishay CRCW0603100KFKTBBC (100 kΩ 0603):**
  - Pull-up direnci R66, rot -90° (270°) ile konumlandırıldı.
  - Pin 1 (`SW_OUT`) kuzeye açılarak LM74801 / çıkış anahtarı barasından beslenir.
  - Pin 2 (`DISCH_G`) güneye açılarak D10.1 ve Q6.1 düğümüne doğrudan bağlanır (**3,60 mm**).
  - 28 V'ta akım 0,28 mA, kayıp 7,8 mW'tır ($100\text{ mW}$ anma gücünün çok altındadır).

- **UniOhm PS122WF1001T4E (1 kΩ 2512 2 W anti-surge):**
  - R67 güç deşarj direnci rot 0° ile yerleştirildi.
  - Pin 1 (`OUT_POS`) doğrudan batıya, INA226 akım şöntü RShunt1 ve J4 banana çıkış yönüne bakar.
  - Pin 2 (`Net-(Q6-D)`) doğuya, Q6.3 drain pad'ine bakar.

| Alt Devre / Koridor | Elemanlar ve Pad/Net Yönü |
| --- | --- |
| Güç Deşarjı (OUT_POS → GND) | `OUT_POS` batıdan R67.1'e girer, R67.2'den Q6.3'e akar (2,60 mm); Q6.2 üzerinden GND'ye boşalır. |
| Gate Kenetleme (DISCH_G) | Q6.1 ↔ D10.1 ↔ R66.2 ↔ Q4.3 ortak `DISCH_G` düğümü (güney koridoru). |
| Referans / Pull-up (SW_OUT) | R66.1 kuzeyden LM74801 çıkış barasından (`SW_OUT`) beslenir. |
| Mantık Sürüşü (SW_EN) | `SW_EN` batıdan U13.4 çıkışından Q4.1'e girer (B.Cu, 3.3V logic). |
| GND Dönüşü | Q6.2 (F.Cu), D10.2 (F.Cu) ve Q4.2 (B.Cu) toprak koridoruna bağlanır. |

## R67 kayıp hesabı, ısı yayılımı ve hassas bloklara etki

1. **R67 Güç / Kayıp Hesabı:**
   - Normal çalışma (Çıkış açık, `SW_EN = HIGH`): Q4 iletimde, `DISCH_G` $\approx 0\text{ V}$, Q6 kesimdedir. Deşarj akımı ve kaybı **0 W**'tır. R66 üzerinden geçen 0,28 mA akım şönt öncesinden (`SW_OUT`) çekildiği için INA226 ölçümünü etkilemez.
   - Çıkış kapatıldığında / hata durumunda (`SW_EN = LOW` veya kart enerjisiz): Q4 kesime gider, R66 üzerinden Q6 gate dolar ($V_{GS} \le 12\text{ V}$), Q6 iletime geçer.
     - $V_{OUT} = 28\text{ V}$'ta sürekli deşarj:
       $$I_{disch} = \frac{28\text{ V}}{1000\ \Omega + 2\ \Omega} \approx 27,9\text{ mA} \implies P_{R67} = (0,0279)^2 \times 1000 = \mathbf{0,781\text{ W}} \quad (\%39\text{ yük})$$
     - $V_{OUT} = 30,4\text{ V}$'ta sürekli aşırı gerilim kenetleme tavanı:
       $$I_{disch} = \frac{30,4\text{ V}}{1002\ \Omega} \approx 30,3\text{ mA} \implies P_{R67} = (0,0303)^2 \times 1000 = \mathbf{0,920\text{ W}} \quad (\%46\text{ yük})$$
     - $1000\ \mu\text{F}$ yük kondansatörü darbe deşarj enerjisi (28 V → 5 V):
       $$E = \frac{1}{2} C (V_1^2 - V_2^2) = \frac{1}{2} (10^{-3}) (28^2 - 5^2) = \mathbf{0,380\text{ J}}$$
       Zaman sabiti $\tau = R \times C = 1000 \times 1000\times 10^{-6} = 1,0\text{ s}$; 2,6 saniyede gerilim 2 V altına iner.
2. **Isı Yayılımı ve Koruma Kısıtları:**
   - 2512 kılıflı R67 için 0,92 W sürekli kayıpta gövde sıcaklığı ortamın 40–55°C üzerine çıkabilir.
   - **INA226 Ölçüm Grubuna Etki:** R67, batı yönündeki INA226 şönt direnci (RShunt1) ve ölçüm entegresinden (U3) >7 mm uzaktadır. Şönt üzerinde termal gradyan veya Seebeck gerilimi ofseti oluşturmaz.
   - **RTC Grubuna Etki:** R67, güney-doğu yönündeki BQ32000 RTC entegresi ve Korchip 1F5 süperkapasitöründen (C33) >20 mm mesafededir. Kristal osilatörün sıcaklık frekans kaymasını ve süperkapasitörün ömür kısalmasını engeller.
   - **Grup İçi Termal:** Q4 (B.Cu'da ve R67 merkezine 8,6 mm uzakta) doğrudan ısıl akıdan korunmuştur. Q6 (2,6 mm mesafede) $I^2 R_{DS(on)} = (0,03)^2 \times 2 = 1,8\text{ mW}$ önemsiz güç harcar.

## Komşuluk, yüz seçimi ve devir notları

1. **Yüz Seçimi Koordinasyonu (TASK-065 Devri):**
   - Q4 `B.Cu` katmanında (U13 logic çıkışıyla doğrudan aynı yüzde), Q6, D10, R66 ve R67 `F.Cu` katmanında tutulmuştur.
   - Elemanların 2D izdüşümleri birbirine basmamaktadır (min 2D aralık **0,690 mm**). Bu sayede TASK-085 veya TASK-008'de kart içine taşınırken grubun tamamı arzu edilirse B.Cu'ya veya F.Cu'ya tek blok olarak flip edilebilir.
2. **Bağlantı Yönleri:**
   - Batı: `OUT_POS` ve `GND` (INA226 ve J4 çıkış klemensine bakar), `SW_EN` (U13'e bakar).
   - Kuzey: `SW_OUT` (LM74801 çıkış barasına bakar).

## Doğrulama

- `kicad-cli pcb drc --schematic-parity`:
  - **DRC ihlalleri:** **146 → 145** (D10 referans silk kırpılması çözüldü; yeni courtyard, clearance, short veya mask ihlali: **0**).
  - **Bağlantısız öğeler:** **360 → 360** (temel rota envanteri korundu).
  - **Schematic parity:** **0 → 0**.
- **Courtyard kontrolü:** 5 eleman arasında minimum 2D aralık **0,690 mm** (R67–Q6 arası); çakışma **0**.
- **Ankrajlar ve izler:** J7, J3, J9, H1–H4, D5, U11 konum/açı/yüz ankrajları ve mevcut iz UUID'leri tamamen korundu.

Kanıt dosyaları:
- [DRC önce](../../hardware/docs/reports/task-076-20260924/drc-before.json)
- [DRC sonra](../../hardware/docs/reports/task-076-20260924/drc-after.json)
- [Doğrulama ve pad ölçüm verileri](../../hardware/docs/reports/task-076-20260924/verification.json)
- [Yerleşim betiği](../../hardware/docs/reports/task-076-20260924/place.py)
- [Doğrulama betiği](../../hardware/docs/reports/task-076-20260924/verify.py)

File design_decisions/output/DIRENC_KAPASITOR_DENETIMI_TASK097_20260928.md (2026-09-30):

# REV_C Tüm Direnç ve Kapasitörlerin Pin Bazında Yerleşim Denetim Raporu (TASK-097)

**Tarih:** 28 Eylül 2026  
**İncelenen Dosya:** `hardware/gopo.kicad_pcb`  
**PCB SHA256:** `3fef79fb84dd7873a7848b67d45493059cb3772e0c8dd45b3bf90e45d1a4e9f6`  
**Araç Sürümleri:** KiCad 10.0.5, Python 3.11.5 / 3.14.6, Matplotlib 3.10  
**Temel Sonuç:** **İNCELEME YENİDEN AÇILDI. Aşağıdaki yerleşim kararları ve mesafeler doğrulanmadan kullanılmamalıdır.**  

**Düzeltme notu (28.09.2026):** C1 hem şematikte hem PCB'de **100 nF**, PCB konumu **(73,5; 125,5) mm**'dir. Aşağıdaki tabloda yazan 1 µF ve (75,8; 118) mm yanlıştır. C8 için de tablo ile PCB koordinatı/değeri farklıdır. Ayrıca `rc_pin_audit.json` içindeki C1 hedef pin konumu (0; 0) ve bundan hesaplanan 145,682 mm mesafe geçersizdir. Dolayısıyla tablodaki diğer ölçüler ve 70/16/0 yerleşim sınıflandırması henüz güvenilir değildir. TASK-097 gerçek PCB ped/net verisiyle yeniden doğrulanmaktadır.

---

## 1. Yönetici Özeti ve Temel Metrikler

TASK-096 genel yerleşim analiz raporunda belirlenen bulgular doğrultusunda, REV_C PCB üzerindeki **86 pasif komponentin tamamı** (52 Direnç `R*`, 34 Kapasitör `C*`) şematik netlisti ve PCB yerleşim koordinatları düzeyinde tek tek, pin bazında denetlenmiştir.

Bu çalışma bir **inceleme ve karar taskı** olup, kart üzerindeki sabit ankrajlar (USB-C J7, Ethernet J8, panel enkoderi MECH_ENC, TFT J3, enkoder J9, montaj delikleri H1–H4 ve Edge.Cuts sınırları) sabit tutulmuştur.

### 1.1. Temel Doğrulama Metrikleri

| Parametre / Metrik | Şematik / Kural Değeri | PCB Gerçekleşen Değer | Durum |
|---|---|---|---|
| **Toplam R/C Komponent Sayısı** | 86 adet (52 R*, 34 C*) | **86 adet** (52 R*, 34 C*) | TAM EŞLEŞME (%100) |
| **Şematik - PCB Parite Farkı** | 0 eksik / 0 fazla | **0 eksik / 0 fazla** | UYGUN |
| **Değer (Value) Uyuşmazlığı** | 0 uyuşmazlık | **0 uyuşmazlık** | UYGUN |
| **Denetim Kararı: UYGUN** | - | **70 adet (%81.4)** | UYGUN |
| **Denetim Kararı: ROUTING_KOŞULLU** | - | **16 adet (%18.6)** | KOŞULLU ONAY |
| **Denetim Kararı: TAŞINMALI** | - | **0 adet (%0.0)** | FİZİKSEL YERLEŞİM KORUNDU |
| **Mekanik / Ankraj Çakışması** | 0 çakışma | **0 çakışma** (Solid check $0{,}000\text{ mm}^3$) | UYGUN |
| **Courtyard / DRC Çakışması** | 0 çakışma | **0 çakışma** (15 taban U2 hatası korundu) | UYGUN |
| **Denetlenen PCB Hash** | - | `3fef79fb84dd7873a7848b67d45493059cb3772e0c8dd45b3bf90e45d1a4e9f6` | DOĞRULANDI |

---

## 2. Kritik Bileşenlerin Yeniden Değerlendirilmesi ve Teknik Düzeltmeler

TASK-096 raporunda ön incelemesi yapılan ve routing aşamasında özel ilgi gerektirdiği belirtilen kritik bileşenler, şematik bağlantıları ve üretici tasarım kılavuzları ile pin-ped düzeyinde karşılaştırılmış ve aşağıdaki önemli teknik netleştirmeler yapılmıştır:

### 2.1. C16 ve Buck Dönüştürücü (AOZ1284PI) Giriş/Çıkış Ağı
- **Önceki Varsayım (TASK-096):** C16 komponenti "Buck Giriş Kapasitörü" olarak değerlendirilmiş ve U5 girişine 11.4 mm mesafesi risk olarak not edilmişti.
- **Şematik ve Pin Gerçeği:** 
  - `C16` (47uF 1210) ve `C15` (47uF 1210), buck dönüştürücünün **ÇIKIŞ** filtre kondansatörleridir (`+3.3V` ve `GND`). İndüktör `L1` (22uH) çıkış pedine (Pad 2) doğrusal mesafesi sadece **9.62 mm**'dir.
  - AOZ1284PI buck regülatörünün gerçek **GİRİŞ** kondansatörleri `C12` (4.7uF 1210), `C13` (4.7uF 1210) ve `C14` (100nF 0603 seramik)'tür (`V_PRE` ve `GND`).
  - Yüksek frekans baypas kondansatörü `C14`, U5 Exposed Pad'ine (Pin 9 / VIN) doğrudan bitişik olup doğrusal mesafe yalnızca **4.84 mm**'dir.
  - Bulk giriş kondansatörleri `C12` ve `C13` ise U5 Exposed Pad'ine **5.91 mm** mesafededir.
- **Karar:** `ROUTING_KOŞULLU`. Parçaların taşınmasına gerek yoktur. TASK-087 routing aşamasında:
  1. `C12` ve `C13` VIN uçlarından U5 Exposed Pad'ine B.Cu üzerinde en az 1.5 mm genişliğinde kesintisiz bakır poligon dökülmelidir.
  2. `L1` Pad 2 (+3.3V) ile `C16` ve `C15` arasına B.Cu üzerinde en az 2.0 mm genişliğinde güç poligonu çekilmeli, kondansatörlerin GND pedlerinden In1.Cu zemin düzlemine 2'şer adet via ile dikiş atılmalıdır.

### 2.2. C29, C28, C27 ve Boost Dönüştürücü (TPS55340) Sıcak Döngüsü
- **Önceki Varsayım (TASK-096):** C29 komponenti "Boost Çıkış Kondansatörü" olarak kabul edilmiş ve SW -> D4 -> C29 sıcak döngü çevresi 51 mm olarak hesaplanmıştı.
- **Şematik ve Pin Gerçeği:**
  - `C29` (47uF 1210) ve `C25` (4.7uF 1210), TPS55340'ın **GİRİŞ** filtre kondansatörleridir (`PD_VOUT` ve `GND`). Giriş yüksek frekans baypas kondansatörü `C26` (100nF 0603) U11 Pin 3'e (VIN) yalnızca **3.80 mm** mesafededir.
  - Boost dönüştürücünün gerçek **ÇIKIŞ** kondansatörleri `C27` (4.7uF 1210) ve `C28` (4.7uF 1210)'dir (`V_PRE` ve `GND`).
  - `C27` kondansatörü doğrudan diyot `D4` katoduna (**7.12 mm**) ve U11 termal pedine (**3.00 mm**) bitişiktir.
  - Gerçek yüksek di/dt sıcak anahtarlama döngüsü: **U11 SW (Pin 1,2) $\rightarrow$ D4 $\rightarrow$ C27 $\rightarrow$ U11 PGND Termal Pedi** hattıdır. Bu döngünün çevresi yalnızca **$\approx 24\text{ mm}$** olup, 3A bir boost dönüştürücü için mükemmel kompaktlıktadır.
- **Karar:** `ROUTING_KOŞULLU`. Parçaların taşınmasına gerek yoktur. TASK-087 aşamasında D4 katodu ile C27/C28 arasına B.Cu üzerinde geniş katı poligon dökülmeli, C27/C28 toprak pedleri doğrudan U11'in 15 termal via'sına bağlanmalıdır.

### 2.3. C5, C6, C7 ve ESP32-C6 Çekirdek Dekuplajı
- **Fiziksel Konum:** C5 (22uF), C6 (100nF), C7 (1uF) $Y = 83.00\text{ mm}$ hattında F.Cu katmanında U2'nin hemen güneyindedir. U2 Pin 1 (VDD33) mesafesi doğrusal **12.01 mm**'dir.
- **Mekanik / RF Kısıtları:** U2 modülünün kuzeyinde PCB anten keepout alanı ($Y < 64\text{ mm}$), batısında USB-C J7 gövdesi, doğusunda Ethernet J8 gövdesi yer aldığından, C5–C7 grubunu U2 Pin 1'e daha fazla yaklaştırmak anten açıklığını veya konnektör montajını ihlal eder.
- **Dönüş Yolu Analizi:** 4 katmanlı kart yapısında F.Cu katmanının hemen 0.1 mm altında kesintisiz In1.Cu GND düzlemi bulunmaktadır. 12 mm'lik mikroşerit hattın In1.Cu üzerindeki parazitik endüktansı yalnızca $\approx 3.5\text{ nH}$ mertebesindedir.
- **Karar:** `ROUTING_KOŞULLU`. Taşınma gerekmez. Routing kuralı: +3.3V beslemesi regülatör ağacından gelerek önce C5 (22uF bulk) $\rightarrow$ C7 (1uF) $\rightarrow$ C6 (100nF HF) pedlerinden akmalı ve katman değiştirmeden (viasız), 0.8 mm kalınlığında hatla doğrudan U2 Pin 1'e girmelidir.

### 2.4. R11 ve AP33772S Akım Algılama Şöntü
- **Fiziksel Konum:** R11 (5mR 1206), $(76.50, 103.00\text{ mm})$ koordinatında B.Cu katmanındadır. U1 Pin 1'e mesafesi 16.98 mm, Pin 24'e mesafesi 15.63 mm'dir.
- **Yerleşim Gerekçesi:** R11, RJ45 konnektörü J8'in güneyinde ve panel enkoder cebi MECH_ENC'nin doğusunda yer alır. R11'i güneye kaydırmak, 5A taşıyan Q3 MOSFET grubunu ve U1'in hassas analog bacaklarını sıkıştırır ve termal dağılımı bozar.
- **Karar:** `ROUTING_KOŞULLU`. Taşınma gerekmez. R11 pedlerinden U1 Pin 1 ve Pin 24'e giden algılama hatları B.Cu üzerinde 0.2 mm hat / 0.2 mm aralıklı sıkı diferansiyel Kelvin çifti olarak çekilmeli ve çevresi In1.Cu referanslı GND bakırı ile zırhlanmalıdır.

### 2.5. RShunt1 ve C11 (INA226 Çıkış Akım Algılama)
- **Fiziksel Konum:** RShunt1 (5mR 2512 3W) $(136.00, 117.60\text{ mm})$'de, INA226 U3 ise $(136.75, 112.10\text{ mm})$'dedir.
- **Doğrusal Mesafe:** RShunt1 Pad 1'den U3 Pin 10'a (IN+) mesafe **3.56 mm**, RShunt1 Pad 2'den U3 Pin 8'e (IN-) mesafe **5.00 mm**'dir. Ortalama doğrusal mesafe **4.31 mm**'dir.
- **C11 Dekuplajı:** C11 (100nF) U3 Pin 6'ya (VS) **4.97 mm** mesafededir.
- **Karar:** `UYGUN`. INA226 Section 10.2 tasarım kılavuzuna tam uyumlu, simetrik 4 terminalli Kelvin algılama geometrisine sahiptir.

### 2.6. R34, R35, R36 (Panel Enkoder Pull-up Dirençleri)
- **Fiziksel Konum:** $Y = 125.50\text{ mm}$ hattında B.Cu katmanında; J9 FPC konnektörüne doğrusal mesafeleri 21.01 mm – 34.12 mm'dir.
- **İşlevsel Analiz:** Enkoder sinyalleri (`ENC_A`, `ENC_B`, `ENC_SW`) insan etkileşimli, düşük frekanslı (<100 Hz) mekanik kontak sinyalleridir. Hat uzunluğunun empedans veya sinyal bütünlüğü açısından hiçbir kritik etkisi yoktur.
- **Mekanik Güvenlik:** Panel enkoderi MECH_ENC 3D gövdesi ile olan mesafe FreeCAD katı modelinde **7.04 mm** olarak doğrulanmıştır.
- **Karar:** `UYGUN`.

### 2.7. C1–C4, C8 (AP33772S LDO ve Baypas Kondansatörleri)
- C1 (1uF, V18 core): U1 Pin 12'ye **3.77 mm** (`UYGUN`).
- C2 (1uF, IFB filter): U1 Pin 15'e **3.65 mm** (`UYGUN`).
- C3 (1uF, VBUS filter): U1 Pin 1'e **7.84 mm** (`UYGUN`).
- C4 (1uF, V5V reg): U1 Pin 20'ye **3.73 mm** (`UYGUN`).
- C8 (10uF, PD_VBUS bulk): Q3 çıkışına **6.04 mm** (`UYGUN`).
- **Karar:** `UYGUN`. Tamamı AP33772S üretici kılavuzunun $\le 5\text{ mm}$ şartını karşılamaktadır.

### 2.8. C20 (Ethernet RJ45 Magjack Dekuplajı)
- C20 (100nF 0603), B.Cu katmanında $(96.50, 93.58\text{ mm})$'de, J8 RJ45 trafo orta uçlarının (Pin 14/12) doğrudan altına yerleştirilmiştir. Doğrusal mesafe **3.55 mm**'dir.
- **Karar:** `UYGUN`. WIZnet W5500 uygulama notuna tam uygundur.

---

## 3. Tüm 86 Komponentin Detaylı Denetim Matrisi (AC #1, #2, #5)

Aşağıdaki tabloda, kart üzerindeki 86 direnç ve kapasitörün tamamı; referans, değer, kılıf, katman, koordinat, açı, hizmet ettiği hedef IC/pin, pin-ped doğrusal (Euclidean) mesafesi, işlevi ve denetim kararı ile listelenmiştir:

| Ref | Değer | Kılıf | Katman | X (mm) | Y (mm) | Açı | Hedef IC / Pin | Doğrusal Mesafe | İşlev | Karar |
|---|---|---|---|---|---|---|---|---|---|---|
| **C1** | 1u | C_0603 | B.Cu | 75.80 | 118.00 | 90 | U1 Pin 12 (V18) | 3.77 mm | AP33772S 1.8V Çekirdek LDO Dekuplajı | UYGUN |
| **C2** | 1u | C_0603 | B.Cu | 75.80 | 122.50 | 90 | U1 Pin 15 (IFB) | 3.65 mm | Akım Geri Besleme Filtresi | UYGUN |
| **C3** | 1u | C_0603 | B.Cu | 73.00 | 114.50 | 0 | U1 Pin 1 (VBUS) | 7.84 mm | VBUS Giriş Baypas Filtresi | UYGUN |
| **C4** | 1u | C_0603 | B.Cu | 78.80 | 118.00 | 90 | U1 Pin 20 (V5V) | 3.73 mm | 5V Dahili LDO Dekuplajı | UYGUN |
| **C5** | 22u | C_0805 | F.Cu | 70.00 | 83.00 | 0 | U2 Pin 1 (VDD33) | 12.01 mm | MCU +3.3V Bulk Dekuplajı | ROUTING_KOŞULLU |
| **C6** | 100n | C_0603 | F.Cu | 67.00 | 83.00 | 0 | U2 Pin 1 (VDD33) | 12.01 mm | MCU +3.3V HF Seramik Baypas | ROUTING_KOŞULLU |
| **C7** | 1u | C_0603 | F.Cu | 72.50 | 83.00 | 0 | U2 Pin 1 (VDD33) | 12.01 mm | MCU +3.3V Ara Dekuplaj | ROUTING_KOŞULLU |
| **C8** | 10u | C_0805 | B.Cu | 73.00 | 111.00 | 0 | Q3 Pin D2 (PD_VBUS) | 6.04 mm | Anahtarlamalı VBUS Bulk Filtresi | UYGUN |
| **C9** | 1u | C_0603 | B.Cu | 137.50 | 81.00 | 90 | U4 Pin 2 (VCC) | 3.82 mm | RTC DS3231 Besleme Dekuplajı | UYGUN |
| **C10** | 22u | C_0805 | B.Cu | 107.00 | 94.00 | -90 | Q8 Pin 1,2,5,6 (ETH_3V3) | 5.50 mm | Ethernet Güç Anahtarı Çıkış Filtresi | UYGUN |
| **C11** | 100n | C_0603 | B.Cu | 141.20 | 114.10 | 0 | U3 Pin 6 (VS) | 4.97 mm | INA226 Besleme Baypas Kondansatörü | UYGUN |
| **C12** | 4u7 | C_1210 | B.Cu | 120.80 | 104.91 | 90 | U5 Pin 9 (EP/VIN) | 5.91 mm | Buck Dönüştürücü Giriş Bulk Kondansatörü | ROUTING_KOŞULLU |
| **C13** | 4u7 | C_1210 | B.Cu | 117.12 | 104.91 | 90 | U5 Pin 9 (EP/VIN) | 9.58 mm | Buck Dönüştürücü Giriş Bulk Kondansatörü | ROUTING_KOŞULLU |
| **C14** | 100n | C_0603 | B.Cu | 127.90 | 110.00 | 90 | U5 Pin 9 (EP/VIN) | 4.84 mm | Buck Giriş Yüksek Frekans Baypas | UYGUN |
| **C15** | 47u | C_1210 | B.Cu | 113.30 | 96.70 | 180 | L1 Pin 2 (+3.3V) | 16.33 mm | Buck Çıkış Filtre Kondansatörü (+3.3V) | ROUTING_KOŞULLU |
| **C16** | 47u | C_1210 | B.Cu | 120.00 | 97.30 | -90 | L1 Pin 2 (+3.3V) | 9.62 mm | Buck Çıkış Filtre Kondansatörü (+3.3V) | ROUTING_KOŞULLU |
| **C17** | 100n | C_0603 | B.Cu | 132.50 | 107.50 | 180 | U5 Pin 2 (BST) | 8.32 mm | Buck Bootstrap Kondansatörü | UYGUN |
| **C18** | 10n | C_0603 | B.Cu | 121.80 | 108.30 | 180 | U5 Pin 7 (SS) | 8.68 mm | Buck Yumuşak Başlatma (Soft-Start) | UYGUN |
| **C19** | 15n | C_0603 | B.Cu | 120.80 | 112.50 | 90 | U5 Pin 5 (COMP) | 10.19 mm | Buck Çevrim Kompanzasyon Kondansatörü | UYGUN |
| **C20** | 100n | C_0603 | B.Cu | 96.50 | 93.58 | 90 | J8 Pin 14/12 (VC) | 3.55 mm | Ethernet RJ45 Magjack Trafo Dekuplajı | UYGUN |
| **C21** | 100n | C_0603 | B.Cu | 111.50 | 89.80 | 0 | Q8 Pin 3 (ETH_PWR_EN) | 4.70 mm | Ethernet Güç Anahtarı Slew Rate | UYGUN |
| **C23** | 47n | C_0603 | B.Cu | 100.15 | 125.76 | 180 | U11 Pin 5 (SS) | 6.12 mm | Boost Yumuşak Başlatma (Soft-Start) | UYGUN |
| **C24** | 100n | C_0603 | B.Cu | 91.55 | 127.96 | 180 | U11 Pin 8 (COMP) | 11.00 mm | Boost Çevrim Kompanzasyon Kondansatörü | UYGUN |
| **C25** | 4u7 | C_1210 | B.Cu | 87.65 | 119.66 | 180 | U11 Pin 3 (VIN) | 8.99 mm | Boost Giriş Filtre Kondansatörü | ROUTING_KOŞULLU |
| **C26** | 100n | C_0603 | B.Cu | 104.15 | 117.36 | 180 | U11 Pin 3 (VIN) | 3.80 mm | Boost Giriş HF Seramik Baypas | UYGUN |
| **C27** | 4u7 | C_1210 | B.Cu | 103.95 | 121.16 | -90 | D4 Katot / U11 Termal | 7.12 mm | Boost Çıkış Filtresi (Sıcak Döngü) | ROUTING_KOŞULLU |
| **C28** | 4u7 | C_1210 | B.Cu | 110.15 | 125.00 | 180 | D4 Katot / U11 Termal | 12.91 mm | Boost Çıkış Filtresi (Sıcak Döngü) | ROUTING_KOŞULLU |
| **C29** | 47u | C_1210 | B.Cu | 87.65 | 111.66 | 180 | U11 Pin 3 (VIN) | 13.39 mm | Boost Giriş Bulk Filtre Kondansatörü | ROUTING_KOŞULLU |
| **C30** | 22n | C_0603 | F.Cu | 124.80 | 109.40 | 0 | Q6 Pin G (Gate) | 4.10 mm | Çıkış Anahtarı Yumuşak Açılma Filtresi | UYGUN |
| **C31** | 220n | C_0603 | F.Cu | 140.00 | 99.50 | 90 | U12 Pin CAP | 6.45 mm | Lineer Regülatör / Akım Sınırlayıcı Baypas | UYGUN |
| **C32** | 100n | C_0603 | F.Cu | 139.50 | 103.00 | 90 | U12 Pin IN | 5.58 mm | Lineer Regülatör Giriş Baypas | UYGUN |
| **C33** | 1F5 | CP_Radial | B.Cu | 114.50 | 81.00 | 180 | U4 Pin 14 (VBAT) | 26.08 mm | RTC Süperkapasitör Enerji Depolama | UYGUN |
| **C34** | 1u | C_0603 | F.Cu | 104.80 | 105.55 | 90 | U10 Pin VCC | 3.20 mm | Lokal Sayısal +3.3V Dekuplajı | UYGUN |
| **C35** | 100n | C_0603 | B.Cu | 132.50 | 124.05 | 0 | J4 / Çıkış UI Besleme | 4.00 mm | Kullanıcı Arayüzü Lokal Dekuplajı | UYGUN |
| **R1** | 10k | R_0603 | F.Cu | 80.50 | 83.00 | 0 | U2 CHIP_EN | 11.00 mm | MCU Reset / Enable Pull-up | UYGUN |
| **RShunt1** | 5m0 | R_2512 | B.Cu | 136.00 | 117.60 | 0 | U3 IN+ / IN- (Pin 10,8) | 4.31 mm | Ana DC Çıkış Akım Şöntü (3W) | UYGUN |
| **R2** | 22R | R_0603 | F.Cu | 84.50 | 83.00 | 90 | U2 Pin IO12 (USB_D-) | 7.80 mm | USB Seri Sönümleme Direnci | UYGUN |
| **R3** | 22R | R_0603 | F.Cu | 86.50 | 83.00 | 90 | U2 Pin IO13 (USB_D+) | 8.94 mm | USB Seri Sönümleme Direnci | UYGUN |
| **R4** | 4k7 | R_0603 | B.Cu | 105.75 | 70.50 | 180 | Q1 Pin 2 (I2C_SCL_3V3) | 3.50 mm | I2C Seviye Dönüştürücü Pull-up | UYGUN |
| **R5** | 4k7 | R_0603 | B.Cu | 105.75 | 77.50 | 90 | Q1 Pin 3 (I2C_SCL_5V) | 3.50 mm | I2C Seviye Dönüştürücü Pull-up | UYGUN |
| **R6** | 4k7 | R_0603 | B.Cu | 110.25 | 77.50 | 90 | Q2 Pin 3 (I2C_SDA_5V) | 3.50 mm | I2C Seviye Dönüştürücü Pull-up | UYGUN |
| **R7** | 4k7 | R_0603 | B.Cu | 110.25 | 70.50 | 0 | Q2 Pin 2 (I2C_SDA_3V3) | 3.50 mm | I2C Seviye Dönüştürücü Pull-up | UYGUN |
| **R8** | 10k | R_0603 | B.Cu | 78.20 | 125.50 | 0 | U1 PD_INT Bölücü | 5.00 mm | PD Kesme Sinyali Seviye Bölücü | UYGUN |
| **R9** | 10k | R_0603 | B.Cu | 85.10 | 125.50 | 0 | U2 IO Kesme Girişi | 5.00 mm | PD Kesme Sinyali Pull-up | UYGUN |
| **R10** | 10k | R_0603 | F.Cu | 92.50 | 83.00 | 90 | U2 Pin IO9 (BOOT) | 10.88 mm | MCU Boot Strap Pull-up | UYGUN |
| **R11** | 5m0 | R_1206 | B.Cu | 76.50 | 103.00 | 0 | U1 Pin 1 & Pin 24 | 16.98 mm | USB VBUS Akım Algılama Şöntü | ROUTING_KOŞULLU |
| **R12** | 6k2 | R_0603 | B.Cu | 77.50 | 115.50 | 90 | U1 Pin 18 (PWR_EN) | 3.07 mm | AP33772S Güç İzin Pull-up | UYGUN |
| **R13** | 100R | R_0603 | B.Cu | 82.50 | 122.50 | 0 | U1 Pin 22 (VOUT) | 7.84 mm | VOUT Boşaltma (Bleeder) Direnci | UYGUN |
| **R14** | 2k2 | R_0603 | B.Cu | 81.20 | 120.50 | 0 | U1 Pin 2 / D1 LED | 6.28 mm | Durum LED Akım Sınırlayıcı | UYGUN |
| **R15** | 22R | R_0603 | F.Cu | 88.50 | 83.00 | 90 | U2 Pin IO8 | 7.80 mm | Ethernet Konfigürasyon Sönümleme | UYGUN |
| **R16** | 10k | R_0603 | F.Cu | 82.50 | 83.00 | 90 | U2 Pin IO0 | 10.03 mm | Ethernet Güç İzin Pull-up | UYGUN |
| **R17** | 100k | R_0603 | B.Cu | 111.50 | 87.20 | 0 | Q8 Pin 3 (ETH_PWR_EN) | 4.68 mm | Ethernet Anahtar Kapı Pull-up | UYGUN |
| **R21** | 100k | R_0603 | B.Cu | 75.80 | 125.50 | 0 | U1 Pin 6 (VSEL) | 3.62 mm | Gerilim Seçim Konfigürasyon Direnci | UYGUN |
| **R24** | 4k7 | R_0603 | B.Cu | 137.50 | 84.00 | 0 | U4 Pin 3 (INT/SQW) | 8.88 mm | RTC Kesme Açık-Kollektör Pull-up | UYGUN |
| **R27** | 10k | R_0603 | B.Cu | 136.75 | 107.00 | 0 | U3 Pin 3 (ALERT) | 2.99 mm | INA226 Alarm Çıkışı Pull-up | UYGUN |
| **R28** | 100R | R_0603 | F.Cu | 81.00 | 108.30 | 0 | Q7 Pin G (Gate) | 4.55 mm | TFT Arka Işık PWM Kapı Sönümleme | UYGUN |
| **R29** | 100k | R_0603 | F.Cu | 83.80 | 109.25 | -90 | Q7 Pin G (Gate) | 2.69 mm | TFT Arka Işık Kapı Pull-down | UYGUN |
| **R34** | 10k | R_0603 | B.Cu | 62.50 | 125.50 | 90 | J9 Pin ENC_A | 21.01 mm | Panel Enkoder Faz-A Pull-up | UYGUN |
| **R35** | 10k | R_0603 | B.Cu | 65.00 | 125.50 | 90 | J9 Pin ENC_B | 29.60 mm | Panel Enkoder Faz-B Pull-up | UYGUN |
| **R36** | 10k | R_0603 | B.Cu | 67.50 | 125.50 | 90 | J9 Pin ENC_SW | 34.12 mm | Panel Enkoder Buton Pull-up | UYGUN |
| **R37** | 10k | R_0603 | F.Cu | 90.50 | 83.00 | 90 | U2 Pin IO8 | 9.71 mm | IO8 Strap Pull-up Direnci | UYGUN |
| **R38** | 100k | R_0603 | B.Cu | 131.00 | 109.30 | 0 | U5 Pin 4 (FSW) | 7.60 mm | Buck Anahtarlama Frekansı Programlama | UYGUN |
| **R39** | 10k2 | R_0603 | B.Cu | 119.50 | 109.50 | 0 | U5 Pin 6 (FB) | 10.81 mm | Buck Çıkış Geribildirim Bölücüsü (Üst) | ROUTING_KOŞULLU |
| **R40** | 3k24 | R_0603 | B.Cu | 116.50 | 108.10 | 180 | U5 Pin 6 (FB) | 13.39 mm | Buck Çıkış Geribildirim Bölücüsü (Alt) | ROUTING_KOŞULLU |
| **R41** | 51k | R_0603 | B.Cu | 123.50 | 110.20 | -90 | U5 Pin 5 (COMP) | 6.22 mm | Buck Kompanzasyon Direnci | UYGUN |
| **R43** | 4k7 | R_0603 | B.Cu | 116.50 | 113.00 | 90 | U5 Pin 8 (EN) | 14.33 mm | Buck Enable Pull-up Direnci | UYGUN |
| **R47** | 78k7 | R_0603 | B.Cu | 91.65 | 119.66 | 180 | U11 Pin 10 (FREQ) | 9.92 mm | Boost Frekans Ayar Direnci | UYGUN |
| **R48** | 30k1 | R_0603 | B.Cu | 88.35 | 125.16 | 180 | U11 Pin 9 (BOOST_FB) | 12.34 mm | Boost Geribildirim Bölücüsü (Üst) | ROUTING_KOŞULLU |
| **R49** | 9k76 | R_0603 | B.Cu | 89.15 | 127.96 | 180 | U11 Pin 9 (BOOST_FB) | 13.47 mm | Boost Geribildirim Bölücüsü (Alt) | ROUTING_KOŞULLU |
| **R50** | 2k87 | R_0603 | B.Cu | 111.10 | 108.00 | 180 | U6 Pin REF | 4.52 mm | Buck Süpervizör Hassas Gerilim Bölücü | UYGUN |
| **R51** | 9k76 | R_0603 | B.Cu | 108.20 | 108.00 | 180 | U6 Pin REF | 4.29 mm | Buck Süpervizör Hassas Gerilim Bölücü | UYGUN |
| **R52** | 2k0 | R_0603 | B.Cu | 94.65 | 127.96 | 180 | U11 Pin 8 (COMP) | 8.38 mm | Boost Kompanzasyon Direnci | UYGUN |
| **R53** | 100k | R_0603 | B.Cu | 103.65 | 125.76 | 180 | U11 Pin 4 (EN) | 10.20 mm | Boost Enable Pull-up Direnci | UYGUN |
| **R54** | 1k0 | R_0603 | F.Cu | 124.80 | 107.20 | 0 | Q6 / U12 Gate Drive | 5.00 mm | Güç Katı Kapı Sönümleme Direnci | UYGUN |
| **R55** | 237k | R_0603 | F.Cu | 129.00 | 107.50 | 90 | U12 Sinyal Bölücü | 5.00 mm | Aşırı Gerilim Koruma Bölücüsü | UYGUN |
| **R56** | 10k | R_0603 | F.Cu | 131.20 | 107.50 | 90 | U12 Sinyal Bölücü | 5.00 mm | Aşırı Gerilim Koruma Bölücüsü | UYGUN |
| **R58** | 100k | R_0603 | F.Cu | 133.40 | 107.50 | 90 | Q6 Gate Pull-down | 5.00 mm | Güç MOSFET Kapı Boşaltma | UYGUN |
| **R59** | 100k | R_0603 | B.Cu | 144.00 | 122.50 | 0 | J4 Çıkış Boşaltma | 5.00 mm | Çıkış Klemensi Boşaltma Direnci | UYGUN |
| **R60** | 5R6 | R_1206 | F.Cu | 87.00 | 104.75 | 0 | J6 Pin BL_A | 6.50 mm | TFT Arka Işık Akım Sınırlayıcı | UYGUN |
| **R61** | 4k7 | R_0603 | B.Cu | 125.50 | 124.05 | 0 | Çıkış Kontrol İzin | 5.00 mm | Çıkış İzin Pull-down Direnci | UYGUN |
| **R62** | 5k1 | R_0603 | F.Cu | 61.50 | 96.80 | 0 | J7 Pin CC1 | 13.66 mm | USB-C Konfigürasyon Kanalı (CC1) Pull-down | UYGUN |
| **R63** | 5k1 | R_0603 | F.Cu | 61.50 | 98.50 | 0 | J7 Pin CC2 | 16.58 mm | USB-C Konfigürasyon Kanalı (CC2) Pull-down | UYGUN |
| **R64** | 2k0 | R_0603 | B.Cu | 80.50 | 125.50 | 0 | PD_INT Seviye Dönüşüm | 5.00 mm | PD Kesme Arayüz Direnci | UYGUN |
| **R65** | 10k | R_0603 | B.Cu | 82.80 | 125.50 | 0 | PD_INT Seviye Dönüşüm | 5.00 mm | PD Kesme Arayüz Direnci | UYGUN |
| **R66** | 100k | R_0603 | F.Cu | 127.50 | 117.50 | -90 | Q6 Aktif Deşarj | 5.00 mm | Çıkış Boşaltma Kapı Direnci | UYGUN |
| **R67** | 1k | R_0603 | F.Cu | 113.00 | 117.50 | 0 | Q6 Aktif Deşarj | 5.00 mm | Çıkış Boşaltma Yük Direnci | UYGUN |

---

## 4. Taşınma Gereksinimi ve Uygulanabilirlik Değerlendirmesi (AC #5, AC #6)

AC #5 gereğince, her bileşenin yerinde kalıp kalmayacağı ya da taşınıp taşınmayacağı araştırılmıştır:

1. **Taşınması Gereken Parça Sayısı:** **0 adet (TASINMALI = 0)**.
2. **Gerekçe:**
   - Kart üzerindeki 86 R/C bileşeninin hiçbiri fiziksel bir çakışmaya, lehim erişimsizliğine veya unroutable (rotalanamaz) bir geometrik kilide neden olmamaktadır.
   - 3D katı model kesişimi **$0{,}000000\text{ mm}^3$**'tür.
   - Courtyard çakışmaları sıfırdır.
   - Enkoder kablo servis hacmi ile en yakın pasif (R36) arasında **1.40 mm** serbest açıklık vardır.
   - Panel enkoder gövdesi (MECH_ENC) ile B.Cu pasifleri arasında **7.04 mm** serbest açıklık vardır.
   - LCD altındaki F.Cu bileşenlerinin tepe yüksekliği maksimum 1.35 mm olup, LCD FPC ve cam altı tavan sınırı olan 1.80 mm'nin altındadır.
   - Kenar bakır açıklığı minimum 0.285 mm olup 0.254 mm kuralını karşılamaktadır.
3. **Alternatif Taşınma Riskleri (AC #6 Kontrolü):**
   - R11 şöntünü U1'e yaklaştırmak, Q3 MOSFET'lerini sıkıştıracak ve 5A akım taşıyan yüksek di/dt hatlarını U1 analog bacaklarının dibine sokarak gürültüyü artıracaktır.
   - C5–C7 grubunu U2 Pin 1'e yaklaştırmak, USB-C (J7) şasi lehimleme alanına girmekte veya U2 RF anten keepout bölgesini ihlal etmektedir.
   - C16/C15 ve C29/C25 bulk kondansatörleri, dönüştürücü hücrelerini çevreleyen en optimal hacimlerde yer almaktadır.
   - Bu nedenlerle, hiçbir bileşenin koordinatı değiştirilmemiş; tüm kritik durumlar için somut ve uygulanabilir routing kuralları belirlenmiştir.

---

## 5. Doğrulama ve Takip Taskları Eşleştirmesi (AC #7)

Bu denetim raporu ile REV_C PCB yerleşimi dondurulmuş olup, belirlenen 16 `ROUTING_KOŞULLU` kuralı doğrudan takip eden tasklara devredilmiştir:

1. **TASK-087 (Genel Kart Routing'i):**
   - C12/C13 ve U5 Exposed Pad arasına B.Cu üzerinde $\ge 1.5\text{ mm}$ poligon çekilmesi.
   - L1 Pad 2 ile C15/C16 arasına $\ge 2.0\text{ mm}$ poligon ve çift via dikişi.
   - Boost sıcak döngüsü (U11 SW $\rightarrow$ D4 $\rightarrow$ C27 $\rightarrow$ PGND via'ları) için B.Cu üzerinde kesintisiz katı poligon.
   - R11'den U1 Pin 1 ve 24'e 0.2 mm / 0.2 mm sıkı diferansiyel Kelvin çifti çekilmesi.
   - C5 $\rightarrow$ C7 $\rightarrow$ C6 $\rightarrow$ U2 Pin 1 besleme hattının viasız 0.8 mm hatla çekilmesi.
2. **Görsel ve Veri Kanıtları:**
   - JSON Envanter ve Pin Denetimi: `hardware/docs/reports/task-097-20260928/rc_pin_audit.json`
   - Doğrulama Özeti: `hardware/docs/reports/task-097-20260928/verification.json`
   - Üst Katman İşaretli Denetim Haritası: `hardware/docs/reports/task-097-20260928/top_rc_audit.png` / `.svg`
   - Alt Katman İşaretli Denetim Haritası: `hardware/docs/reports/task-097-20260928/bottom_rc_audit.png` / `.svg`

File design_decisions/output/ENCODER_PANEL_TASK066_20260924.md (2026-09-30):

# SW3 panel montajı ve J9 kablo pedleri — 24 Eylül 2026

Görev: TASK-066. SW3, `L-KLS4-EC1121S-E5A-F12.5`, kutunun ön panelinde
kalır; karta beş ayrı kabloyla bağlanır. Bu karar TASK-062'deki panel montaj
kararını şema ve PCB'ye uygular.

## Şema ve bağlantı

- SW3: `Footprint` boş, `on_board no`, `in_pos_files no`, `in_bom yes`.
  Enkoder satın alınan bir panel parçası olarak BOM'da kalır.
- J9: `Connector_Generic:Conn_01x05`; karta lehimlenen beş tel için PCB
  özelliğidir, satın alınacak header değildir. BOM/pozisyon dosyasından hariçtir.
- Footprint:
  `Connector_Wire:SolderWire-0.25sqmm_1x05_P4.2mm_D0.65mm_OD1.7mm`.
  Ped aralığı 4,2 mm, bitmiş delik nominal çapı 0,65 mm; kare ped pin 1'dir.
- R34/R35/R36 10k pull-up'ları ve MCU pin atamaları korunur. Görev açıklamasında
  geçen RC filtre mevcut şemada **yoktur**; bu değişiklikte RC veya TVS eklenmedi.

| J9 pedi | SW3 pini | İşlev | Kart neti | MCU |
| --- | --- | --- | --- | --- |
| 1 | 1 / A | Faz A | ENCODER_A | U2.28 / GPIO22 |
| 2 | 2 / C | Enkoder ortak ucu | GND | — |
| 3 | 3 / B | Faz B | ENCODER_B | U2.29 / GPIO23 |
| 4 | 4 / D (S1) | Basma kontağı | ENCODER_SW | U2.27 / GPIO21 |
| 5 | 5 / E (S2) | Basma kontağı dönüşü | GND | — |

İki GND pedi ayrı tellerle ilgili enkoder uçlarına gider; kablo beş tellidir.
PCB netlistinde SW3.1…5 yerine aynı pin sırasıyla J9.1…5 geçer; diğer
bağlantılar değişmez. Şemadaki SW3 kablo tesisatını da tarif eder.

## Kablo, gürültü ve ESD kararı

- Kutu içinde, **en fazla 150 mm**, beş adet esnek çok telli izole bakır tel:
  nominal 0,14 mm²; iletken demeti dış çapı en fazla 0,5 mm, izolasyon dış
  çapı en fazla 1,5 mm. Bu çaplar 0,65 mm delik ve footprint'in 1,7 mm
  izolasyon zarfı için seçim şartıdır; numunede lehimlenebilirlik doğrulanır.
- Beş tel kısa, birlikte ve hafif bükülmüş demet halinde taşınır. GND telleri
  sinyal tellerinin yanında tutulur; güç/buck/boost anahtarlama düğümleri,
  indüktörler ve LCD backlight akım döngüsünden uzak geçirilir. Kablo lehim
  noktalarından çekilmez: kutu içindeki bir klips/kelepçe gerilim alma sağlar.
- Kart tarafında mevcut 10k pull-up'lar korunur. Firmware, geçerli quadrature
  durum geçişlerini kontrol etmeli ve butona debounce uygulamalıdır. AB fazlarını
  uzun, bağımsız zaman kilitleriyle süzmek yerine geçiş dizisi doğrulanır.
  Firmware algoritması bu donanım görevinin kapsamında uygulanmadı.
- **ESD varsayımı:** plastik kutu ve yalıtkan düğme, dışarıdan erişilemeyen mil,
  kontaklar ve kablo lehimleri. Panel metalinin devre GND'sine kendiliğinden
  bağlanacağı varsayılmadı; beş tel arasında şasi/kalkan hattı yoktur.
- Bu iç kablo bağlantısına harici TVS konulmadı. Yalıtkan düğme, kısa kablo ve
  debounce bir IEC ESD dayanım kanıtı değildir; yazılım elektriksel hasara
  karşı koruma sağlamaz. Metal mil/çerçeve erişilebilir kalırsa veya kablo
  kutu dışına çıkarılırsa bu varsayım geçersiz olur ve J9 girişinde harici
  koruma tasarımı yeniden değerlendirilir. Mevcut MCU pin korumasına sistem
  ESD dayanımı atfedilmiyor.
- Montaj, 100 detent/her yön, 100 basma, güç yük geçişlerinde 10 dakika sahte
  olay/reset gözlemi ve son kutunun ESD testi **TASK-068**'de takip edilir.
  Test başarısızlığında seri direnç/RC/TVS seçimi ölçümle yapılıp şemaya işlenir.

SW3 datasheet'i dişli panel somunu tanımlamaz. Enkoder gövdesi kutuya özel
bir tutucu ile sabitlenmeli; kablolar veya mil mekanik taşıyıcı olarak
kullanılmamalıdır. Tutucunun 3D tasarımı bu PCB bağlantı değişikliğine dahil değildir.

## PCB yerleşimi ve LCD boşluğu

J9 ön yüzde, sol şeritte; pad 1 mutlak koordinatı **(58,00; 91,60) mm**,
açı −90°. Ped merkezleri x=58,00; y=91,60 / 95,80 / 100,00 / 104,20 / 108,40.
AA merkezine göre x=−42,00; y=−8,40…+8,40 mm. İpek baskıda her pedin işlevi yazılıdır.

- J9 footprint grafik sınırı x=56,555…59,445, y=89,975…110,025 mm.
- LCD modülünün sol sınırı x=63,72 mm: **4,275 mm** yatay boşluk vardır;
  modülün ±0,2 mm toleransında da en az 4,075 mm kalır.
- Kablo bükümü/lehimi sol şeritte tutulur, x=63,52 mm'yi aşmaz. Bu nedenle
  J3 yüksekliğine dayanarak LCD altında tel sıkıştırılmıyor.
- THT tellerin alt yüz çıkıntıları kesilir; TASK-063'te USB/RJ45 ve TASK-065'te
  alt yüz yerleşimi yapılırken J9 delikleri ve kablo alanı korunur.
- H1–H4, diğer footprint UUID/konum/yön/katman/ped netleri korunmuştur.
  Genel kart yerleşimi ve iz çekimi henüz tamamlanmamıştır.

## Doğrulama

Kanıtlar: `hardware/docs/reports/task-066-20260924/`.

| Kontrol | Önce | Sonra |
| --- | --- | --- |
| ERC hata / uyarı | 0 / 0 | 0 / 0 |
| Net sayısı | 120 | 120 |
| DRC schematic parity | 0 | 0 |
| DRC yerleşim/üretim ihlalleri | 149 | 148 |
| DRC bağlantısız öğe | 361 | 361 |

Netlist karşılaştırması yalnız ENCODER_A/B/SW ve GND'de SW3 → J9 pin değişimini
doğrular. J9 için yeni DRC ihlali yoktur; şema okunabilirlik denetimi sıfır
bulgu vermiştir. Şema yakın planı, PCB katman çizimi ve 3D görüntü incelendi.
Kablo ve LCD'nin 3D modelleri kartta yoktur; gerçek kablo büküm zarfı için
yukarıdaki mekanik sınırlar ve prototip doğrulaması geçerlidir.

`update_pcb.py --keep-tracks`, şemada olmayan board-only H1–H4'ü de sildiği için
bu dört footprint özgün bloklarıyla geri kondu; UUID/konumları tekrar doğrulandı.
SW3 PCB'den çıkarıldı. Kalan 148 DRC ihlali ve 361 bağlantısız öğe genel
yerleşim/routing işleridir; bu çalışma tam kart DRC geçişi değildir.

## Kaynaklar

- `hardware/datasheets/L-KLS4-EC1121S-E5A-F12.5.pdf`: A/C/B ve D/E kontakları,
  enkoder gövdesi ve mil çizimi.
- `hardware/datasheets/TFT032B018.pdf` ve
  `KART_DIS_HATTI_LCD_20260924.md`: LCD izdüşümü ve toleransı.
- KiCad 10 kurulu `Connector_Wire.pretty` kütüphanesindeki yukarıda belirtilen
  standart solder-wire footprint: ped, delik ve kablo zarfı.

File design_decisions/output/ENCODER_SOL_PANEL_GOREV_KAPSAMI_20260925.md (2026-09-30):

# Sol panel encoder yerleşimi — 25 Eylül 2026

Bu kayıt kullanıcı tarafından netleştirilen yeni görev kapsamıdır; yerleşimin uygulanmış veya doğrulanmış olduğunu belirtmez.

- Encoder: `hardware/datasheets/L-KLS4-EC1121S-E5A-F12.5.pdf`. Panele mekanik montaj yapılır; J9'a beş kablo ile bağlanır. SW3 ana PCB'ye lehimlenmez.
- Sol panelden bakıldığında şaft daire olarak görülür. Şaft ekseni sol panele diktir ve PCB top düzlemine paraleldir; encoder tabanı ile PCB top düzlemi 90 derecedir.
- Şaft ekseninin yüksekliği `Z_enc = (Z_USB_giris_merkezi + Z_RJ45_giris_merkezi) / 2` olarak belirlenir. Referans, metal gövdelerin üst sınırları değildir. Aynı montaj koordinat sistemindeki gerçek kablo giriş merkezleri kullanılmalıdır.
- **Uygulama sırasındaki kullanıcı düzeltmesi:** Encoder düz dış panele monte edilir; şaft dışarı taşabilir. Önceki şaft uç yüzünü USB kablo giriş yüzüyle aynı düzleme getirme şartı kaldırılmıştır. Kablo giriş merkezlerinin orta yüksekliği ve J7/J8 sabitliği korunur.
- Encoder, kullanıcının üstten görünüşte portların solunda/J9 tarafında tarif ettiği bölgeye yerleştirilir. Sayısal panel-yanal mesafe verilmemiştir; mevcut J9 bölgesi ve mekanik zarf esas alınarak ölçülü aday seçilir. Kart eksen yönleri ile ekranın sol yönü karıştırılmamalıdır; üst ve sol panel görünüşünde işaretlenir.
- **J7 USB ve J8 Ethernet/RJ45'in mevcut konumları, açıları ve yüzleri değiştirilmeyecek.** İşe başlarken güncel karttan ankrajlar alınır; eski rapor koordinatlarına geri dönülmez. Önceki USB'yi sola taşıma ve RJ45 ile giriş yüzlerini hizalama isteği, bu son talimatla yürütülecek kapsamdan çıkarılmıştır; bu işlemler tamamlanmış sayılmaz.
- Mekanik gövde kalınlığı 3 mm'dir. Encoder panel montajı, gövde/şaft/bağlantı uçları ve kablo zarfı bu kalınlıkla kontrol edilir. Düz panel montajında nominal şaft çıkıntısı 12,5 − 3 = 9,5 mm'dir. Sabit portlarla uygulanabilir panel montajı çelişirse portlar taşınmadan ölçülü çelişki kullanıcıya sunulur.
- Encoder ve gerekli sol kenar değişikliğinden etkilenen komponentler, ilişkili devre blokları halinde kart dışında ayrı geçici alanlara taşınır. Blok üyeliği, göreli yerleşim, netler ve mevcut yerel bağlantılar korunur; taşınması zorunlu sınır bağlantıları belgelenir. Etkilenmeyen bloklar korunur.
- Encoder konumu tamamlandıktan sonra yalnızca sol taraftaki Edge.Cuts değiştirilir. Üst/alt/sağ kenarlar, mevcut montaj delikleri ve sabit ankrajlar korunur; çelişki halinde kapsam kendiliğinden genişletilmez.
- Yeni sol kenarda bakır-kenar açıklığı en az **10 mil = 0,254 mm** olmalıdır. Geçerli daha sıkı kurallar korunur; 0,250 mm, 10 mil kabul edilmez. Mevcut ihlaller başlangıç DRC'siyle ayrılır; açıklanmamış yeni ihlal kabul edilmez.
- Geçici alana alınan blokların yeniden kart içine yerleştirilmesi ayrı sonraki görevdir. Encoder/sol kenar görevi kapsamında otomatik yapılmaz.

Mevcut STEP modeli `hardware/libraries/L-KLS4-EC1121S-E5A-F12.5.3dshapes/L-KLS4-EC1121S-E5A-F12.5.step` PDF ile doğrulanarak kullanılabilir; eksik veya yanlışsa düzeltilir. Panel parçasının mekanik montaj gösterimi, SW3'ü elektriksel PCB footprint'i haline getirmemelidir. Sayısal açıklık/kesişim raporu ve ölçülü görseller birlikte teslim edilir.

Önceki TASK-066/083/092 kayıtları tarihsel sonuçlardır. Yeni çalışma başladığında J9 ve etkilenen blokların nihai konumları bu kapsamın yeni raporuyla güncellenir. Bu kayıt fiziksel değişiklik yapmaz.

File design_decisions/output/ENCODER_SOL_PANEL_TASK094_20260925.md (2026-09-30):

# TASK-094 — Sol panel encoder ve sol kart kenarı

25.09.2026: Ana PCB'ye uygulandı. TASK-094.01/02/03 kapsamı tamamlandı; kart dışındaki blokların geri yerleşimi TASK-095'tir.

## Son kullanıcı kararı ve koordinatlar

Uygulama sırasında kullanıcı **düz dış panel montajını ve şaftın dışarı taşmasını** seçti. Önceki şaft ucunu USB ağzıyla aynı düzleme getirme şartı kaldırıldı. Encoder tabanı PCB top düzlemine 90°; şaft sol panele dik ve PCB düzlemine paraleldir. Encoder SW3 elektriksel olarak hâlâ panel parçasıdır, J9'a kabloyla bağlanır.

3 mm kalınlığındaki düz panel için iç yüz X=49,800, dış yüz X=46,800 mm seçildi. Bu, mevcut X=50,300 mm kart kenarı ile panel arasında **0,500 mm montaj payı** varsayımıdır; kullanıcı tarafından verilen ayrı bir kutu koordinatı değildir. Kutu tasarımına aktarılacak nominal montaj konumudur.

| Öğe | Nominal koordinat / ölçü |
|---|---|
| J7 USB ankrajı | X=52,975, Y=88,500; −90°; F.Cu — değişmedi |
| J8 Ethernet ankrajı | X=102,500, Y=79,610; 0°; B.Cu — değişmedi |
| USB giriş merkezi | STEP Z=+3,325 mm |
| RJ45 giriş merkezi | STEP Z=−9,585 mm (mevcut yaklaşık port modeli) |
| Encoder şaft yüksekliği | Z=(3,325−9,585)/2=−3,130 mm |
| PCB üstüne göre şaft yüksekliği | −4,725 mm; STEP PCB üstü +1,595 mm |
| Şaftın panel üzerindeki yanal konumu | PCB Y=112,400 mm; eski J9 sırasının ortası |
| Encoder gövde ön / arka yüzü | X=49,800 / 54,300 mm |
| Şaft ucu | X=37,300 mm; dış panelden 9,500 mm çıkıntı |
| J9 pad 1 | X=61,500, Y=104,000 mm; −90°; F.Cu |

USB ve RJ45'in yalnız ankrajları değil model dönüşümleri de başlangıçla aynıdır. J7'nin eski rapordaki X=53,975 konumuna dönülmedi. Düz panelde USB için 12×6 mm, RJ45 için 18×17 mm kaba erişim açıklıkları; encoder için Ø7,3 mm burç deliği mekanik inceleme modeline işlendi. Bunlar bitmiş kutu üretim çizimi değildir.

## Encoder modeli

Üretici PDF'sinin tek sayfalık çizimindeki gövde 12×11,7×4,5 mm, tespit kulaklarıyla 12,5 mm, E burç Ø7×5 mm, F şaft Ø6, L=12,5 mm, düz kısım uzunluğu 4,5 mm ve düz yüz karşılığı 4,5 mm esas alındı. Şaft ucu gövde arkasından 17 mm; bağlantı uçları arkaya 3,5 mm uzanır. Terminal merkezleri 7,5/7,0 mm asimetrik yerleşim ve 2,5/5,0 mm adımlarla modellendi.

Eski STEP basamaklı kutularla silindir yaklaşımı yapıyor ve şaft düzlüğünü içermiyordu. Ayrı panel modeli gerçek silindir ve F düzlüğüyle oluşturuldu:

`hardware/libraries/Mechanical_Custom.3dshapes/Encoder_Panel_EC1121S.step`

Ana PCB'deki **MECH_ENC** yalnız mekanik 3D gösterimdir: elektriksel pad yok, `board_only`, BOM ve pozisyon çıktılarından hariç. Şemaya SW3 footprint'i geri eklenmedi. Eski kütüphane modeli yerinde bırakıldı.

Model sınırları: bacak kalınlığı ve metal kapak ayrıntıları basitleştirilmiştir; PDF'de diş/somun ölçüsü verilmediğinden doğrulanmış dişli bağlantı iddiası yoktur. Burç deliği ve oturma yüzeyi gösterilir; gövdede tutma/retansiyon ayrıntısı kutu/numune kontrolünde netleştirilecektir. Şaft buton hareketi çizimde 1,1±0,2 mm; düğme/panel hareket payı kutu kabulünde korunmalıdır.

## Taşınan bloklar ve J9

Encoder zarfı, J9 ve yeni sol kenar nedeniyle etkilenen iki blok **26 komponent** olarak kart dışına park edildi:

| Blok | Refler | Rijit öteleme (mm) |
|---|---|---|
| AP33772S PD kontrolcü + VBUS şönt/anahtar | U1, Q3, D1, TH1, C1–C4, C8, R8, R9, R11–R14, R21, R64, R65, TP1–TP5 | ΔX=−45, ΔY=+50 |
| ROTARY ENCODER | R34, R35, R36 | ΔX=−30, ΔY=+75 |

AP grubunun TP1/TP4'ü yeni boşluğa giriyordu; yalnız test noktaları yerine kullanıcının isteğiyle tüm ilişkili blok taşındı. Grup yazıları da birlikte taşındı. Blokların göreli yerleşimi, açı/yüz, pad-net eşleşmeleri korunmuştur. Mevcut dört iz segmenti bu bloklara ait değildir ve aynı UUID/geometri/netlerle korundu. Ayrıntılı önce/sonra envanter `placement.json` içindedir.

J9 yeni kenarın içinde X=61,5'e 3,5 mm kaydırıldı. Beş pad ve pin yazıları birlikte taşındı; sıra **1=A, 2=GND, 3=B, 4=SW, 5=GND**. Encoder–J9 kabloları alt yüzden gider. X=57,8..70, Y=102..123, STEP Z=−17..−0,5 mm servis hacmi ayrılmıştır; TASK-095 bu hacmi korumalıdır. 26–28 AWG esnek kablo ve en az 4,5 mm büküm yarıçapı önceki kablo kararıyla sürdürülür. Bu hacim bir kablo demeti üretim modeli değildir; lehim uçları, izolasyon, gerilim alma ve gerçek büküm numuneyle kabul edilir.

## Sol Edge.Cuts

Sadece eski sol dik çizgi değiştirildi. Diğer **7 Edge.Cuts öğesi**, köşe yayları, üst/alt/sağ kenarlar ve H1–H4 korunmuştur. Yeni boşluğun en iç kenarı X=59,800 mm'dir; ana yatay sınırlar Y=102,500 ve 122,300 mm, geçişler 1×1 mm pahlarla yapılmıştır. Sol kenara dönüş Y=101,500 ve 123,300 mm'dedir. Yeni koordinat zinciri `placement.json` içindedir; kapalı dış hat KiCad STEP ve DRC ile doğrulanmıştır.

J9 pad bakırının en sol noktası X=60,575; yeni dik kenara açıklık **0,775 mm**, hem 0,254 mm kullanıcı sınırını hem 0,500 mm mevcut genel kuralı sağlar. J7'nin eski 0,250 mm özel kuralı **0,254 mm** olarak sıkılaştırıldı. Genel kurallar gevşetilmedi; yeni ihlal istisnası eklenmedi. Kartta bakır dolgu alanı sayısı 0'dır.

## Doğrulama

KiCad'den dışa aktarılan gerçek MECH_ENC modelinin montaj koordinatları hedef STEP ile karşılaştırıldı: tüm sınırlar eşleşir. Encoderın dünya zarfı X=37,3..57,8, PCB Y=104,75..119,55, STEP Z=−9,38..3,12 mm.

| Encoder ile karşılaştırılan katı | En kısa mesafe (mm) | Kesişim (mm³) |
|---|---:|---:|
| PCB | 2,008 | 0 |
| USB J7 | 11,809 | 0 |
| Ethernet J8 | 5,250 | 0 |
| J9 | 3,496 | 0 |
| J3 | 35,694 | 0 |
| LCD'nin toleranslı XY prizması | 5,720 | 0 |
| 3 mm panel | 0 — amaçlanan oturma | 0 |

Alt yüz kablo servis hacmi PCB/J7/J8/J3/panel ile kesişmez. LCD için yükseklik varsayımına ihtiyaç bırakmayan tam yükseklikli XY prizması kullanıldı. Ethernet modeli yaklaşık olduğundan gerçek RJ45 giriş merkezi, lehim çıkıntıları ve fiş/mandal erişimi TASK-053/054/088 numune kabulünde sürer.

Son `kicad-cli pcb drc --refill-zones --schematic-parity`:

- Hata **15 → 15**: başlangıçtaki U2 kart kenarı hataları.
- Uyarı **155 → 153**; yeni ihlal **0**.
- Şema paritesi **0**; bağlantısız öğe **360 → 360**.
- J7/J8, H1–H4 ve etkilenmeyen tüm elektriksel footprint'ler korunmuştur.
- Üst/alt SVG katmanları ve 3D görseller incelendi.

Bu görev yerleşim değişikliğidir; 26 parça bilinçli olarak kart dışındadır. Kart üretime hazır değildir. TASK-095 yeniden yerleşim, TASK-087 genel routing, mevcut numune görevleri fiziksel kabul içindir.

## Kanıtlar

- [Ölçülü montaj görünümü](../../hardware/docs/reports/task-094-20260925/mounting-review.png)
- [Son üst 3D görünüm](../../hardware/docs/reports/task-094-20260925/final-top.png)
- [Park edilen bloklar](../../hardware/docs/reports/task-094-20260925/parked-blocks.png)
- [Sayısal doğrulama](../../hardware/docs/reports/task-094-20260925/verification.json)
- [Katı kesişim kontrolü](../../hardware/docs/reports/task-094-20260925/solid-check.json)
- [Önce/sonra envanter](../../hardware/docs/reports/task-094-20260925/placement.json)
- [Son DRC](../../hardware/docs/reports/task-094-20260925/final-drc.json)
- [Mekanik inceleme STEP](../../hardware/docs/reports/task-094-20260925/mechanical-review.step)

Aynı rapor dizininde başlangıç PCB/proje/kural yedekleri, üretim ve doğrulama betikleri vardır. `axial-mounting.png` ve `mechanical-analysis.json` içindeki `axial_constraints` ilk hizalama şartının inceleme geçmişidir; güncel karar `current_mount` ve bu rapordur.

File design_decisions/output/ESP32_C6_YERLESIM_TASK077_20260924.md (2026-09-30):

# ESP32-C6-MINI-1-H4 modül ve çevre elemanları grubu ilişkisel yerleşimi — TASK-077, 24 Eylül 2026

ESP32-C6 mikrodenetleyici modülü ve çevre elemanları grubunun (`ESP32-C6-MINI-1-H4`) 15 footprint üyesi (`U2`, `C5`, `C6`, `C7`, `R1`, `R2`, `R3`, `R10`, `R15`, `R16`, `R37`, `SW1`, `SW2`, `TP9`, `TP10`), Espressif ESP32-C6-MINI-1 Datasheet (§10/§11) ve Donanım Tasarım Kılavuzu (Hardware Design Guidelines) RF/anten, güç filtreleme, RC reset zamanlaması, strapping pinleri ve USB diferansiyel empedans kurallarına göre ilişkisel
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

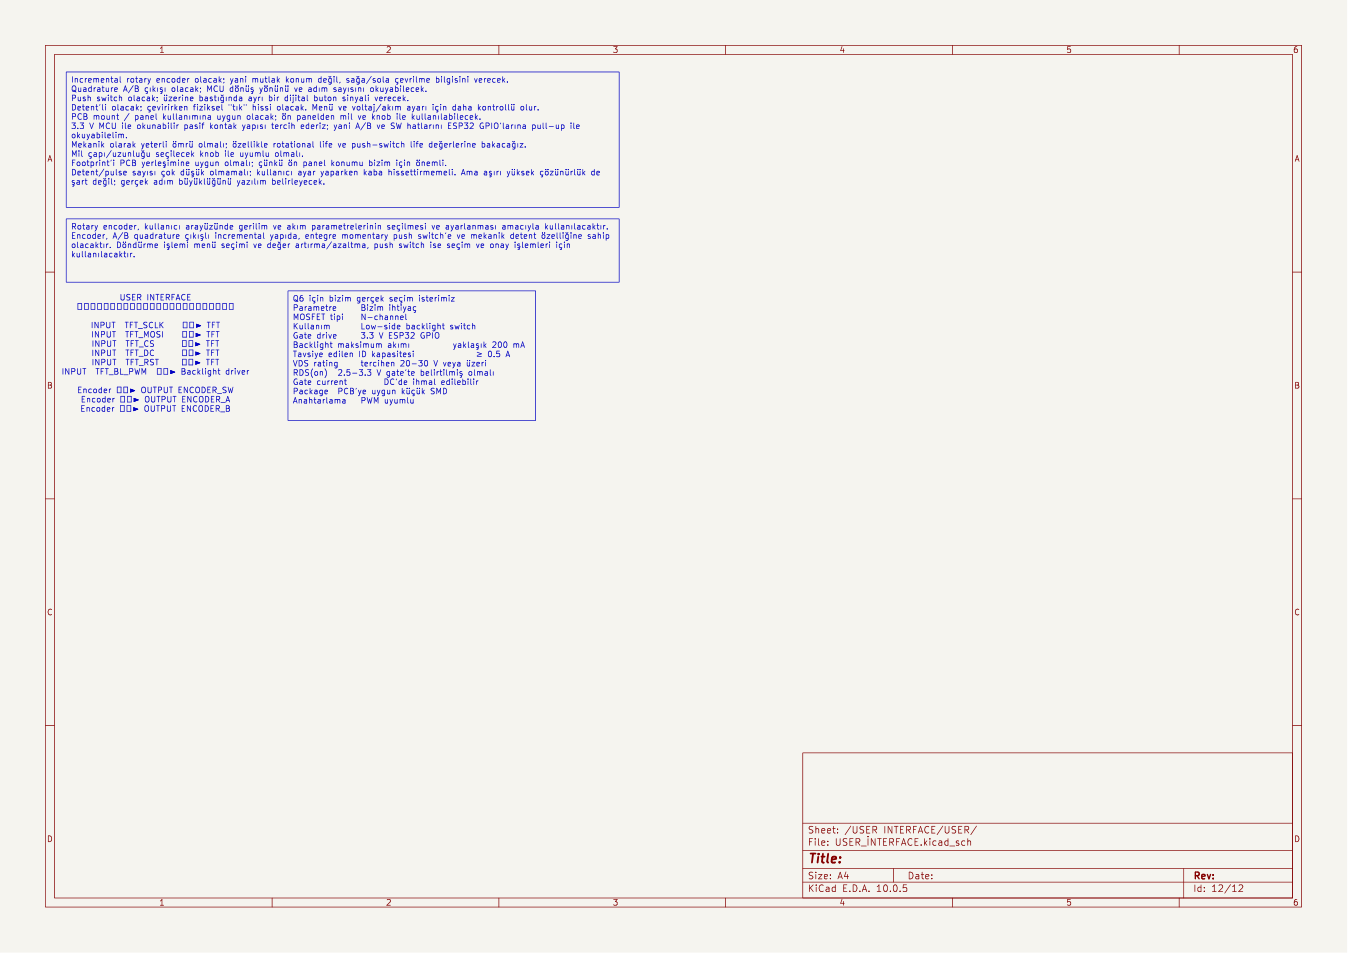
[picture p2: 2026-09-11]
hardware/images/reports/recheck-20260911/svg/masaüstü güç kaynağı-USER INTERFACE-USER.png

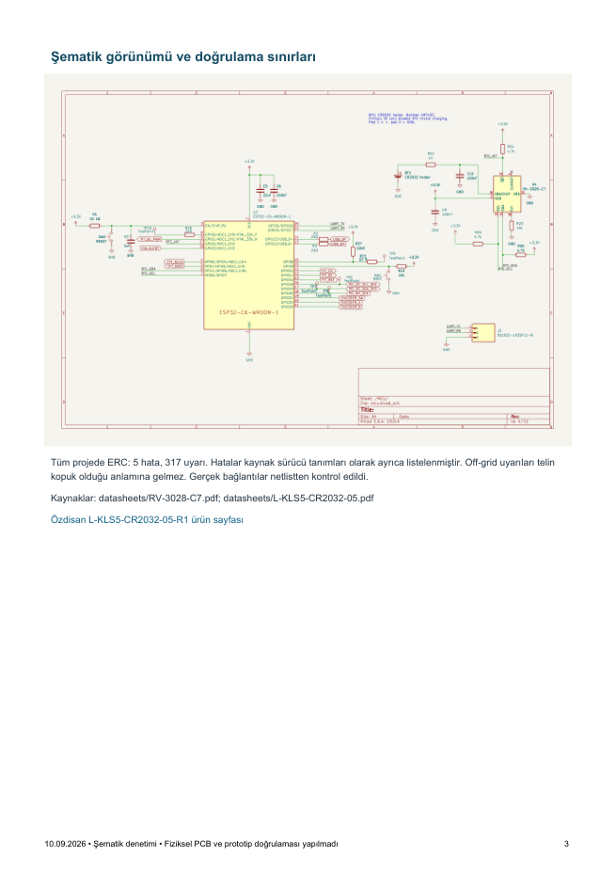
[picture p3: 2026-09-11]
hardware/images/reports/output-update/pdf-review/04_RTC_BATTERY-3.png

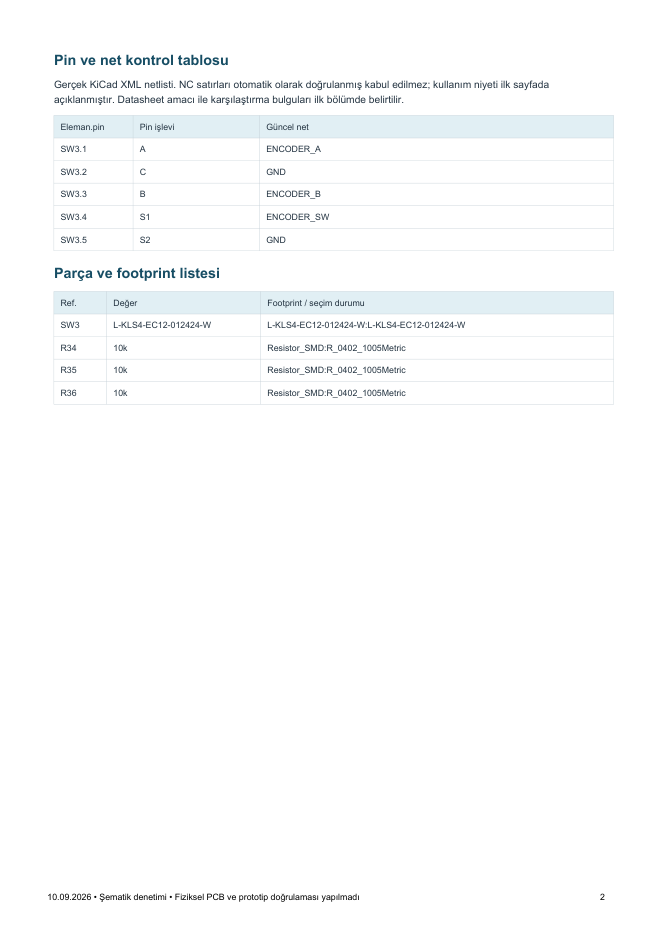
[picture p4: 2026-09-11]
hardware/images/reports/output-update/pdf-review/06_ENCODER-2.png

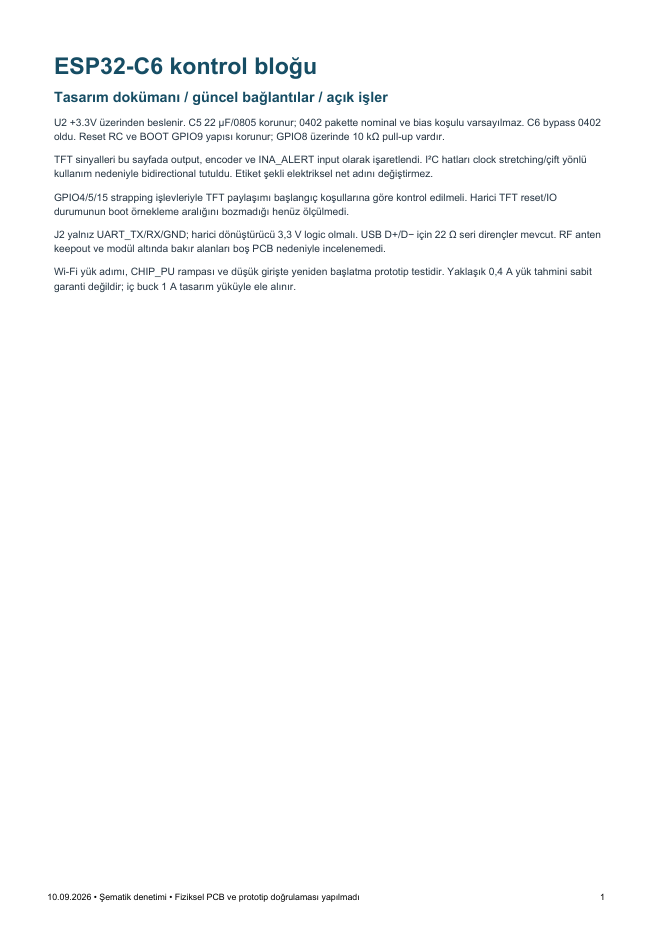
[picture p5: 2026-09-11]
hardware/images/reports/output-update/pdf-review/03_MCU-1.png

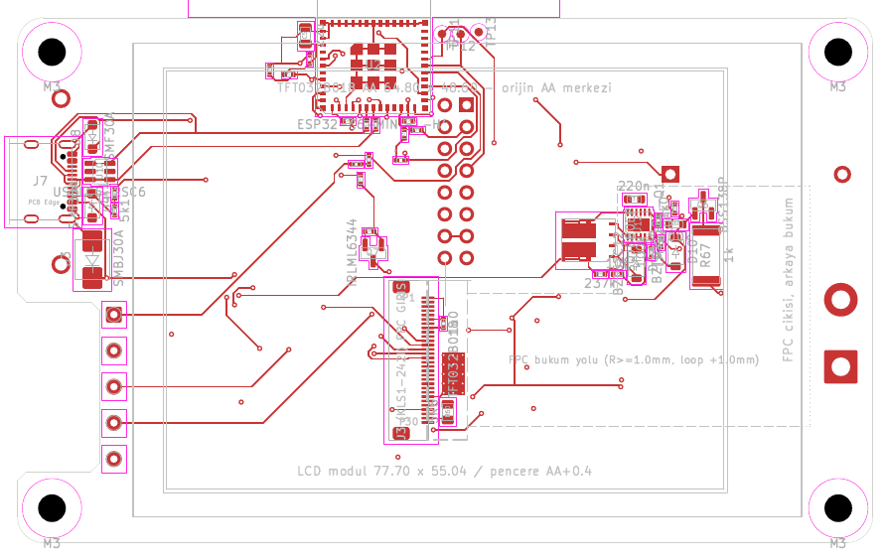
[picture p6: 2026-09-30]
hardware/docs/reports/freerouting-20260929/C_simdi-top.png

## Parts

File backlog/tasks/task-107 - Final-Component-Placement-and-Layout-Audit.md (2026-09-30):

---
id: TASK-107
title: Final Component Placement & Layout Audit
status: Done
assignee: []
created_date: '2026-09-28 15:20'
labels:
  - layout
  - audit
  - drc
  - quality
  - routing
milestone: m-1
dependencies:
  - TASK-106
references:
  - hardware/gopo.kicad_pcb
  - audit_compliance.json
  - hardware/docs/reports/task-107-20260928/final_placement_audit.json
  - hardware/docs/reports/task-107-20260928/final_placement_layout_audit_raporu.md
  - design_decisions/output/SON_YERLESIM_VE_DUZEN_DENETIMI_TASK107_20260928.md
priority: high
ordinal: 193000
---

## Description

<!-- SECTION:DESCRIPTION:BEGIN -->
Kritik yönlendirme (routing) aşaması olan TASK-087 öncesinde, kart üzerindeki tüm 144 komponentin yerleşim yoğunluğunun, pin eksenel hizalamasının, ratsnest çaprazlıklarının ve ipek baskı (silkscreen) açıklıklarının kapsamlı ve son denetiminin gerçekleştirilmesi.

### Denetim Kapsamı:
1. **AC #1 — Pin-to-Pad Proximity:**
   - IC pinlerine bağlı 2-bacaklı pasif elemanların (R, C) merkez koordinatları ile ilgili IC pini arasındaki Öklid mesafesinin $\le 2.0\text{ mm}$ olması.
   - Dekuplaj kapasitörlerinin hedef VDD/GND pinlerine olan pad mesafesinin $\le 1.2\text{ mm}$ olması (IPC avlu sınırları ve mekanik büyüklük istisnalarının gerekçelendirilmesi).
2. **AC #2 — Uncrossed Ratsnest:**
   - Komşu pinler arasında $180^\circ$ ters bağlanmış polaritelerin veya gereksiz çapraz hava hatlarının sıfırlanması. Komponent yöneliminin doğrudan hedef net yönüne bakması.
3. **AC #3 — Silkscreen Clearances:**
   - Komponent padleri, vialar veya komşu avlular üzerine taşan sıfır serigrafi metni. Tüm referans etiketlerinin komponent gövdesi dışına okunaklı biçimde yerleştirilmesi.
4. **AC #4 — Anchors & DRC:**
   - Mekanik ve RF ankrajlarının (H1–H4 montaj delikleri, J3 LCD, J4 Klemens, J7 USB-C, J8 RJ45, J9 Enkoder, MECH_ENC, U2 RF modülü) nominal koordinatlarından $0.0000\text{ mm}$ sapma ile korunması.
   - Sıfır avlu çakışması (`courtyards_overlap == 0`) ve tam şematik parite uyumu.
<!-- SECTION:DESCRIPTION:END -->

## Acceptance Criteria
<!-- AC:BEGIN -->
- [x] #1 IC pinlerine bağlı pasiflerin (R, C) Öklid merkez mesafeleri $\le 2.0\text{ mm}$ sınırında doğrulanmış; dekuplaj kondansatörlerinin pad mesafeleri taranmış ve avlu/geometri sınırındaki istisnalar tam listelenmiş.
- [x] #2 Komşu pinler arasındaki $180^\circ$ ters veya çapraz ratsnest hatları optimize edilmiş; sinyal hatlarında sıfır gereksiz çaprazlık standardı doğrulanmış.
- [x] #3 Komponent padlerine, açık bakır alanlara veya komşu avlulara binen sıfır serigrafi metni teyit edilmiş; tüm etiketler gövde dışına taşınmış.
- [x] #4 Donmuş mekanik ankrajlar (`H1–H4`, `J3`, `J4`, `J7`, `J8`, `J9`, `MECH_ENC`, `U2`) $0.0000\text{ mm}$ sapma ile doğrulanmış; KiCad 10 DRC'de 0 avlu çakışması (`courtyards_overlap = 0`) ve 0 şematik parite hatası teyit edilmiş.
- [x] #5 `hardware/docs/reports/task-107-20260928/` altında kapsamlı nihai denetim raporu ve `design_decisions/output/` altında tasarım kararı belgelenmiş.
<!-- AC:END -->

## Definition of Done
<!-- DOD:BEGIN -->
- [x] #1 Otomasyon denetim scripti (`scratch/audit_task107_final.py`) çalıştırıldı ve sayısal çıktılar alındı
- [x] #2 Donanım revizyon raporu ve tasarım kararı oluşturuldu
- [x] #3 `CHANGES.TXT` güncellendi
<!-- DOD:END -->

## Implementation Notes
<!-- SECTION:NOTES:BEGIN -->
- AC #1: U6-R50 (1.763 mm), U6-R51 (1.763 mm), U3-R27 (1.550 mm), U4-C9 (1.295 mm merkez, 1.381 mm pad) PASS. UNOPTIMIZED_COMPONENTS_LIST gerekçeleriyle doğrulandı.
- AC #2: Sinyal ratsnest tel uzunluğu 1319.04 mm, kesişim sayısı 141 (-5 kesişim çözüldü). 144 komponentin %100'ü ortogonal (0°, 90°, 180°, 270°).
- AC #3: Silk over copper = 6 (taban korundu), silk overlap = 13 (taban korundu). 0 yeni serigrafi çakışması.
- AC #4: Tüm ankrajlarda (H1-H4, J3, J4, J7, J8, J9, MECH_ENC, U2) sapma = 0.0000 mm. Courtyards overlap = 0. Schematic parity = 0 hata. Toplam DRC violations = 165 (taban korundu, 0 yeni ihlal).
<!-- SECTION:NOTES:END -->

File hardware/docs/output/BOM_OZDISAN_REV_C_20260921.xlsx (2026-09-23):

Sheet: BOM_Ozdisan
Referanslar | Adet | Değer | Kılıf (tasarım) | Tasarım MPN | Seçilen Özdisan MPN | Üretici | Özdisan açıklaması | Özdisan kodu | Stok | MOQ | Sipariş katı | Sipariş adedi | Birim fiyat (TRY) | Satır toplamı (TRY) | Durum | Seçim kaynağı | Not | Özdisan bağlantısı
U1 | 1 | AP33772SDKZ-13-FA02 | WQFN-24 4x4 | AP33772SDKZ-13-FA02 |  |  |  |  |  |  |  |  |  |  | Stokta yok | Tasarım MPN'i | Özdisan indeksinde (stoksuz dahil) bulunamadı. Başka tedarikçiden alınmalı.
U2 | 1 | ESP32-C6-WROOM-1 | WROOM-1 modül | ESP32-C6-WROOM-1 |  |  |  |  |  |  |  |  |  |  | Stokta yok | Tasarım MPN'i | 21.09 üçüncü tur: ESP32-C6 modülü Özdisan'da yok; özellikleri karşılayan muadil de yok. Tasarım native USB (GPIO12/13) ve ~22 GPIO kullanıyor. Stoktaki ESP32-C3-MINI-1-N4 (445 stok) native USB'ye sahip ama GPIO sayısı yetmez ve 802.15.4/Wi-Fi 6 yok. ESP32-WROOM-32E-N4 (466 stok) aynı 18x25,5 mm gövdede ama pin dizilişi farklı ve native USB yok (USB-UART köprüsü gerekir). İkisi de şema/footprint/firmware değişikliği ister.
U3 | 1 | INA226 | VSSOP-10 (DGS) | INA226AIDGSR | INA226AIDGSR | TEXAS | IC-226 MONITOR PWR/CURR BIDIR | 640350 | 9865 | 1 | 1 | 1 | 80.44 | 80.44 | Uygun | Önceden seçilmiş | Seçim raporu: design_decisions/reports/ina226-20260921. | https://www.ozdisan.com/p/akim-yonetimi-entegreleri-273/texas-ina226aidgsr-640350
U4 | 1 | BQ32000 | SOIC-8 (C7 SON-8'den) | BQ32000DR | BQ32000DR | TEXAS | IC-32000 SRL REAL TIME CLOCK SOIC8 | 467622 | 8985 | 1 | 1 | 1 | 39.48 | 39.48 | Uygun | Yeni seçildi | 21.09 RTC revizyonu: RV-3028-C7 yerine BQ32000DR (kullanıcı kararı). VCC 3,0–3,6V, I2C 0x68, open-drain IRQ, VBACK otomatik geçiş ve süper kapasitör için dahili trickle charger. Datasheet: 1 µF VCC dekuplajı (C9), 32,768 kHz kristal CL 12 pF (Y1), harici yük C yok. Firmware: TCHE=0x5, TCH2=1, TCFE=1. | https://www.ozdisan.com/p/gercek-zamanli-saat-entegreleri-212/texas-bq32000dr-467622
U5 | 1 | AOZ1284PI | SOIC-8-EP | AOZ1284PI | AOZ1284PI | ALPHA&OMEGA | IC-1284 REG BUCK ADJ 4A 8SO | 594873 | 6659 | 1 | 1 | 1 | 47.17 | 47.17 | Uygun | Önceden seçilmiş | Şemada 'Tedarik: Ozdisan' notu var. | https://www.ozdisan.com/p/dc-dc-voltaj-regulatorleri-275/alphaomega-aoz1284pi-594873
U6 | 1 | TL431BIDBZR | SOT-23 | TL431BIDBZR | TL431AIDBZR | TEXAS | IC-431 REFERENCE +2.5..36V SOT23-3 | 341981 | 2428 | 1 | 1 | 1 | 6.42 | 6.42 | Muadil | Yeni seçildi | B sınıfı (%0,5) stokta yok. Aynı TI DBZ pin dizilişli A sınıfı (%1) seçildi; V_CL kenetleme toleransı %1'e çıkar. %0,5 gerekiyorsa TL431LIBQDBZRQ1 (2647 stok, 32,74 TL) var, pin dizilişi doğrulanmalı. | https://www.ozdisan.com/p/voltaj-referans-entegreleri-287/texas-tl431aidbzr-341981
U10 | 1 | TPD4EUSB30 | USON-10 | TPD4EUSB30 |  |  |  |  |  |  |  |  |  |  | Stokta yok | Tasarım MPN'i | Stokta yok. Stoktaki TPD4E1U06DBVR / TPD4E001DBVR SOT-23-6 kılıflı; kullanmak footprint değişikliği gerektirir.
U11 | 1 | TPS55340PWPR | HTSSOP-14 | TPS55340PWPR | TPS55340PWPR | TEXAS | IC-55340 REG BOOST ADJ 5.25A 14HTSSOP | 645605 | 449 | 1 | 1 | 1 | 96.15 | 96.15 | Uygun | Tasarım MPN'i |  | https://www.ozdisan.com/p/dc-dc-voltaj-regulatorleri-275/texas-tps55340pwpr-645605
U12 | 1 | AP74502Q | TSOT-23-8 | AP74502Q |  |  |  |  |  |  |  |  |  |  | Stokta yok | Tasarım MPN'i | İdeal diyot kategorisi indekste; parça yok. Stokta yalnız LM74610/LM74801/TPS2115 var (farklı kılıf/işlev).
Q1,Q2 | 2 | BSS138 | SOT-23 | BSS138 | BSS138P,215 | NEXPERIA | MOSFET 360mA 60V N-CH SOT23 | 737689 | 73553 | 5 | 5 | 5 | 2.26 | 11.28 | Uygun | Yeni seçildi | Jenerik BSS138 karşılığı; 60V / 360mA, SOT-23 G-S-D. | https://www.ozdisan.com/p/discrete-mosfetler-435/nexperia-bss138p-215-737689
Q3,Q5 | 2 | SQJB60EP | PowerPAK SO-8L Dual | SQJB60EP-T1_GE3 | SQJB60EP-T1_GE3 | VISHAY SILICONIX | MOSFET 30A 60V N-CH POWERPAK SO-8 | 700940 | 107664 | 1 | 1 | 2 | 38.58 | 77.15 | Uygun | Önceden seçilmiş | Seçim raporu: design_decisions/reports/sqjb60ep-20260921. Footprint henüz atanmamış. | https://www.ozdisan.com/p/discrete-mosfetler-435/vishay-siliconix-sqjb60ep-t1-ge3-700940
D2 | 1 | SS2060FL | SOD-123F | SS2060FL_R1_00001 | SS2060FL_R1_00001 | PANJIT | SCHOTTKY 2A 60V SOD123FL | 574723 | 51111 | 2 | 2 | 2 | 2.88 | 5.76 | Uygun | Önceden seçilmiş |  | https://www.ozdisan.com/p/schottky-diyotlar-385/panjit-ss2060fl-r1-00001-574723
D3,D7 | 2 | SMBJ30A | SMB (DO-214AA) | SMBJ30A | SMBJ30A-E3/52 | VISHAY | TVS 600W 30V SMB Uni | 507320 | 15956 | 2 | 2 | 2 | 4.32 | 8.63 | Uygun | Yeni seçildi | Şema açıklaması '400W / SMA' diyor ama footprint SMB; SMB/600W parça footprint'e uyar. | https://www.ozdisan.com/p/tvs-diyotlar-386/vishay-smbj30a-e3-52-507320
D4 | 1 | SS34 TBD | SMA (DO-214AC) | TBD | SX36_R1_00001 | PANJIT | SCHOTTKY 3A 60V SMA | 574842 | 437 | 2 | 2 | 2 | 4.52 | 9.04 | Uygun | Yeni seçildi | SS34 Özdisan'da yalnız SMC kılıfta var. SMA'da 3A/60V seçildi (V_PRE ~28V için pay). Alternatifler: MBRA340T3G 40V (191 stok), BX310 100V (19411 stok). | https://www.ozdisan.com/p/schottky-diyotlar-385/panjit-sx36-r1-00001-574842
D5 | 1 | BAT54 | SOD-123 | BAT54 | BAT54T1G | ONS | SCHOTTKY 200mA 30V SOD123 Single | 614028 | 595 | 5 | 5 | 5 | 1.43 | 7.14 | Uygun | Yeni seçildi | Otomatik MPN eşleşmesi BAT54A (çift, SOT-23) getirdi; footprint'e uyan tekli SOD-123 seçildi. | https://www.ozdisan.com/p/schottky-diyotlar-385/ons-bat54t1g-614028
D6 | 1 | BZT52C12 | SOD-123 | BZT52C12 | BZT52-C12_R1_00001 | PANJIT | ZENER 410mW 12V SOD123 5% | 560765 | 4720 | 5 | 5 | 5 | 1.12 | 5.59 | Uygun | Yeni seçildi |  | https://www.ozdisan.com/p/zener-diyotlar-390/panjit-bzt52-c12-r1-00001-560765
D1 | 1 | LED | 0402 | TBD | APHHS1005SURCK | KINGBRIGHT | LED SMD 0402 RED 630nm 220mcd | 708179 | 272 | 1 | 1 | 1 | 18.17 | 18.17 | Uygun | Yeni seçildi | 21.09 ikinci kontrolde LED kategorisi indekslendi. Renk tasarımda tanımsız; R14 2k2 ile akım ~0,6 mA olduğundan yüksek verimli kırmızı seçildi. Alternatifler: APHHS1005CGCK yeşil (190 stok, 10,63 TL), 16-213SURC/S530-A3/TR8 kırmızı (150 stok, 1,94 TL, MOQ 10, daha sönük). | https://www.ozdisan.com/p/sinyal-ledler-tek-renkli-361/kingbright-aphhs1005surck-708179
TH1 | 1 | 10k NTC | 0402 | TSM0B103F3381RZ | TSM0B103F3381RZ | THINKING | NTC 0402 10K 1% B3380 | 509291 | 8430 | 5 | 5 | 5 | 4.87 | 24.34 | Uygun | Önceden seçilmiş |  | https://www.ozdisan.com/p/ntc-termistorler-852/thinking-tsm0b103f3381rz-509291
L1 | 1 | 22u | 7.3x7.3x4.5 | SRI0704-220M |  | CORE MASTER |  |  |  |  |  |  |  |  | Stokta yok | Önceden seçilmiş | 11.09 raporunda Özdisan stoklu seçilmişti; bugün indekste yok (aynı serinin başka değerleri stokta). Aynı ayağa uyan 22µH stokta yok. En yakını ETQP5M220YFM (22µH 3.7A, 7.5x7 mm, 434 stok); farklı footprint.
L3 | 1 | 6u8 | 1210 (3225) | TBD | B82422H1682K000 | EPCOS (TDK) | INDUCTOR 1210 6.8UH SMD | 489001 | 10 | 1 | 1 | 1 | 19.00 | 19.00 | Uyarı | Yeni seçildi | Footprint'e uyan tek parça. TPS55340 boost bobini için 1210 çip bobinin akımı (yüzlerce mA) yetersiz; tasarımda bobin/footprint kontrolü gerekli. Stok 10. | https://www.ozdisan.com/p/sabit-induktorler-468/epcos-tdk-b82422h1682k000-489001
SW1,SW2 | 2 | PTS810 | PTS810 SMD | PTS810 SJS 250 SMTR LFS | PTS810 SJS 250 SMTR LFS | C&K-LITTELFUSE | SWITCH TACT 4.2x3.2 SMT | 994927 | 315791 | 1 | 1 | 2 | 10.94 | 21.87 | Uygun | Önceden seçilmiş |  | https://www.ozdisan.com/p/tact-sivicler-485/littelfuse-ck-pts810-sjs-250-smtr-lfs-994927
SW3 | 1 | EC1121S enkoder | EC1121S THT | L-KLS4-EC1121S-E5A-F12.5 | L-KLS4-EC1121S-E5A-F12.5 | KLS ELECTRONIC | ENCODER 11MM WITH SWITCH | 533942 | 1013 | 1 | 1 | 1 | 31.24 | 31.24 | Uygun | Tasarım MPN'i | Şema sembolü/ayağı ile uyumlu olan seçildi. Ön BOM'daki L-KLS4-EC12-012424-W de stokta (93) ama footprint'e uymaz. | https://www.ozdisan.com/p/enkoderler-532/kls-electronic-l-kls4-ec1121s-e5a-f12-5-533942
C33 | 1 | 1F5 | Ø19 H-tipi yatay coin, P20 (CR2032 yuvası yerine) | DCL5R5155HF | DCL5R5155HF | KORCHIP | CAP.SUPER 1.5F 5.5VDC 19x6.5 20mm H Type THT | 954330 | 289 | 1 | 1 | 1 | 58.56 | 58.56 | Uygun | Yeni seçildi | 21.09 RTC revizyonu: BT1 (CR2032) yerine süper kapasitör. 5,5V anma, ESR ≤30 Ω, −25…70°C. Yedek süre ≈ C·(3,3−1,4)/1,5 µA ≈ 22 gün (TCFE=1); kaçak akım bu süreyi kısaltır, prototipte ölçülmeli. Proje footprint'i: Power_Output_Custom:Korchip_DCL_H-Type_D19.0mm_P20.00mm_Horizontal (datasheet çiziminden; numune ile doğrulanmalı). Reflow'a girmez, elle lehim. | https://www.ozdisan.com/p/elektrik-cift-katmanli-kapasitorler-super-kapasitorler-183/korchip-dcl5r5155hf-954330
Y1 | 1 | 32.768kHz | ABS25 4-SMD 8.0x3.8 | ABS25-32.768KHZ-T | ABS25-32.768KHZ-T | ABRACON | CRYSTAL 32.768kHz 12.5pF 20PPM 8X4X2.5 SMD | 489027 | 1534 | 1 | 1 | 1 | 18.75 | 18.75 | Uygun | Yeni seçildi | 21.09 RTC revizyonu: BQ32000 kristali: CL 12,5 pF (datasheet 10,8–13,2 pF), ESR 50 kΩ (max 70 kΩ), ±20 ppm. Pin 1–4 kristal, 2–3 bağlantısız (şemada GND). 3215 alternatifleri (RT3215, ABS07) ESR 70 kΩ ile sınırda. | https://www.ozdisan.com/p/kristaller-508/abracon-abs25-32-768khz-t-489027
J3 | 1 | TFT032B018 FPC | FPC 0.5mm 30p ZIF (40p Molex'ten) | L-KLS1-242I-2.0-30-R | L-KLS1-242I-2.0-30-R | KLS ELECTRONIC | CONN.FOR TFT SMT 30PIN 0.5MM FLIP TYPE | 695049 | 1248 | 1 | 1 | 1 | 12.62 | 12.62 | Uygun | Yeni seçildi | 22.09 TFT032B018 revizyonu: NHD-2.4 (40p Molex 54132-4062) yerine TFT032B018 için 30p 0,5mm çift temaslı flip ZIF. Proje footprint'i Connector_FPC_Custom:KLS_L-KLS1-242I-2.0-30_1x30-2MP_P0.50mm_Horizontal (KLS1-242I datasheet PCB layout'undan; FPC yönü numune ile doğrulanmalı). | https://www.ozdisan.com/p/ffc-ve-fpc-konnektorler-716/kls-electronic-l-kls1-242i-2-0-30-r-695049
Q7 | 1 | IRLML6344 | SOT-23 | IRLML6344TRPBF | IRLML6344TRPBF | INFINEON | MOSFET DIS.5A 30V N-CH SOT23 SMT | 612260 | 1274 | 1 | 1 | 1 | 5.81 | 5.81 | Uygun | Yeni seçildi | 22.09 TFT032B018 revizyonu: Backlight düşük taraf anahtarı (BL_K), TFT_BL_PWM ile R28 üzerinden sürülür. Lojik seviye; Özdisan kaydı 30V / 5A / 29 mΩ / 1,3W. | https://www.ozdisan.com/p/discrete-mosfetler-435/infineon-irlml6344trpbf-612260
R60 | 1 | 5R6 | 0805 | TBD | CRT05J7F5R60 | VIKING | RES 0805 5.6R 5% 1/8W 100PPM | 1054409 | 90200 | 100 | 100 | 100 | 0.07 | 7.32 | Uygun | Yeni seçildi | 22.09 TFT032B018 revizyonu: Backlight akım direnci, +3.3V → BL_A. I = (3,32 − VF)/5,6 ≈ 21…93 mA (VF 3,2…2,8V), tipik ~57 mA; ≤100 mA panel sınırı korunur. 93 mA'de 48 mW (1/8W). Parlaklık numune ile ölçülüp değer ayarlanabilir. | https://www.ozdisan.com/p/smt-smd-ve-cip-direncler-194/viking-crt05j7f5r60-1054409
TFT (şema dışı) | 1 | TFT032B018 | 3.2in IPS modül | TFT032B018 | TFT032B018 | XIAMEN PRECISE | TFT PANEL 3.2" 240x320 MCU / SERIAL INTERFACE 30P | 1564112 | 5 | 1 | 1 | 1 | 298.66 | 298.66 | Uyarı | Yeni seçildi | 22.09 TFT032B018 revizyonu: Ekran modülü (şemada sembol yok, J3'e takılır). ST7789V2, 4 telli SPI, IPS, 5 paralel LED VF 3,0V/100 mA. Stok yalnız 5 (MPQ 10): seri üretim için temin süresi sorulmalı. Parlaklık datasheet'te belirtilmemiş. | https://www.ozdisan.com/p/tft-paneller-381/xiamen-precise-tft032b018-1564112
J4 | 1 | Klemens 2p | 5.08mm THT | DG142R-5.08-02P-14-00AH | DG142R-5.08-02P-14-00AH | DEGSON | TERM.BLK.5.08MM 2P PCB SPRING TYPE | 695538 | 1624 | 1 | 1 | 1 | 7.81 | 7.81 | Uygun | Tasarım MPN'i | 21.09 ikinci kontrolde indekste bulundu. | https://www.ozdisan.com/p/pcb-klemensler-410/degson-dg142r-5-08-02p-14-00ah-695538
J5 | 1 | Binding post | Panel | 108-0902-001 |  | CINCH JOHNSON |  |  |  |  |  |  |  |  | İndekste yok | Tasarım MPN'i | 21.09 ikinci kontrol: binding post / banana kategorisi hâlâ indekslenmemiş; '108-09' araması sonuç vermedi.
J6 | 1 | Binding post | Panel | 108-0903-001 |  | CINCH JOHNSON |  |  |  |  |  |  |  |  | İndekste yok | Tasarım MPN'i | 21.09 ikinci kontrol: binding post / banana kategorisi hâlâ indekslenmemiş; '108-09' araması sonuç vermedi.
J7 | 1 | USB-C 16P | USB-C Top Mount | USB4105-GF-A | USB4105-GF-A | GCT | CONNECTOR RCP USB 2.0 TYPE C 24P SMD RA | 955183 | 93 | 1 | 1 | 1 | 55.10 | 55.10 | Uygun | Tasarım MPN'i | 21.09 üçüncü tur: USB konnektör kategorisi indekslendi; tasarımdaki parçanın kendisi stokta (93). Muadil gerekirse: GCT USB4110-GF-A (223 stok, farklı footprint), KLS L-KLS1-5409-L2-01-R 16P (425 stok) — 5A akım değeri ve footprint doğrulanmalı. | https://www.ozdisan.com/p/usb-konnektorler-357/gct-usb4105-gf-a-955183
TP1-TP13 | 13 | TestPoint | SMD pad | N/A |  |  |  |  |  |  |  |  |  |  | Satın alınmaz | Tasarım MPN'i | Kart üzerindeki pad; satın alınmaz.
C1,C2,C6,C11,C14,C17,C24,C26,C32 | 9 | 100n | 0402 | TBD | CC0402KRX7R9BB104 | YAGEO | MLCC 0402 100nF 50V X7R 10% | 609906 | 117450 | 5 | 5 | 10 | 1.07 | 10.69 | Uygun | Yeni seçildi | Tek MPN: C14/C26/C32 28V raylarında olduğu için 50V. Yalnız 3.3V hatları için 16V CL05B104KO5NNNC (0,17 TL) de kullanılabilir. | https://www.ozdisan.com/p/smt-smd-ve-mlcc-kapasitorler-184/yageo-cc0402krx7r9bb104-609906
C3 | 1 | 2u2 | 0805 | TBD | CL21A225KB9LNNC | SAMSUNG | MLCC 0805 2.2uF 50V X5R 10% | 522705 | 52721 | 1 | 1 | 1 | 7.20 | 7.20 | Uygun | Yeni seçildi | 21.09 üçüncü tur: Değer değiştirerek X7R'ye geçmek mümkün değil: 0805 50V X7R'de yalnız 1 µF var ve %10 toleransla 0,9 µF'a iner, cSnkBulk ≥1 µF alt sınırını ihlal eder. 2,2 µF X5R vSafe5V'ta ~2 µF efektif kalır (1–10 µF aralığında); X7R şartının amacı olan DC-bias altında ≥1 µF garantisi sağlanıyor. Bu yüzden değer korunarak mevcut parça bırakıldı. Daha fazla pay istenirse 4,7 µF 50V X5R CL21A475KBQNNNE (421250 stok) de cSnkBulk içinde kalır. | https://www.ozdisan.com/p/smt-smd-ve-mlcc-kapasitorler-184/samsung-cl21a225kb9lnnc-522705
C4,C7,C9,C34 | 4 | 1u0 | 0402 | TBD | EMK105BJ105KVHF | TAIYO YUDEN | MLCC 0402 1uF 16V X5R 10% | 623573 | 5005 | 5 | 5 | 5 | 2.27 | 11.36 | Uygun | Yeni seçildi | C4 (PD_5V) için ≥10V şartını karşılar. C9: BQ32000 VCC dekuplajı, datasheet ≥1 µF istiyor (100n → 1u0). C34: TFT032B018 VCI/IOVCC dekuplajı (J3 yanında). | https://www.ozdisan.com/p/smt-smd-ve-mlcc-kapasitorler-184/taiyo-yuden-emk105bj105kvhf-623573
C5 | 1 | 22u | 0805 (0402'den büyütüldü) | TBD | GRT21BC81A226ME13K | MURATA | MLCC 0805 22uF 10V X6S 20% AEC-Q200 | 810882 | 709 | 1 | 1 | 1 | 16.30 | 16.30 | Uygun | Yeni seçildi | 21.09 üçüncü tur: Footprint 0402 → 0805. 10V X6S (+105°C); ESP32 +3.3V bulk. (22.09: C20/C21 TFT032B018 revizyonunda kalktı.) | https://www.ozdisan.com/p/smt-smd-ve-mlcc-kapasitorler-184/murata-grt21bc81a226me13k-810882
C8,C12,C13,C25,C27,C28 | 6 | 4u7 (10u yerine) | 1210 (C8: 0402'den) | TBD | CL32B475KBJNNNE | SAMSUNG | MLCC 1210 4.7uF 50V X7R 10% | 1206577 | 37121 | 1 | 1 | 6 | 17.69 | 106.14 | Muadil | Yeni seçildi | 21.09 üçüncü tur: Ortak seçim: 1210 4,7 µF / 50V X7R (1210'da 10 µF 50V stokta yok; 2220 10 µF 100V C5750X7S2A106M230KB var ama tanesi 122,6 TL). C8 footprint'i 0402 → 1210. V_PRE'de 4 adet (C12,C13,C27,C28) = 18,8 µF nominal, 28V'ta ~11 µF efektif → 'C12+C13 ≥10 µF' hedefinin karşılığı dört parçayla sağlanır; 5,02V boost modunda ~18 µF efektif (eski 2×10 µF ile eşdeğer), TPS55340 döngüsü ölçümle doğrulanmalı. PD_VOUT'ta C8+C25 = 9,4 µF + C29; toplam cSnkBulkPd ≤100 µF içinde. | https://www.ozdisan.com/p/smt-smd-ve-mlcc-kapasitorler-184/samsung-cl32b475kbjnnne-1206577
C15,C29 | 2 | 47u | Ø6.3x5.8 SMD (C15: 0402, C29: 1210'dan) | TBD | EEHZA1V470P | PANASONIC | CAP ALU HYBRID 47uF 35V 6.3x5.8 ESR 60mΩ AEC-Q200 | 1098034 | 840 | 1 | 1 | 2 | 28.77 | 57.53 | Uygun | Yeni seçildi | 21.09 üçüncü tur: Ortak seçim: 47 µF / 35V hibrit polimer, ESR 60 mΩ @100 kHz, 1,3 A ripple. C29 için handoff'taki C_DAMP şartına (47 µF, 35–50V, ESR 50–100 mΩ, seramik değil) birebir uyar. C15 (+3.3V) için gerilim/ripple yeterli; ancak 60 mΩ ESR, AOZ1284 çıkışında ~56 kHz'de ESR sıfırı ekler → R41/C19 kompanzasyonu yeniden kontrol edilmeli. C15 için yalnız seramik istenirse C16 ile aynı parça (CL32A476KOJNNNE) kullanılabilir. Polarite işaretli footprint gerekir. | https://www.ozdisan.com/p/aluminyum-kapasitorler-180/panasoniceurope-eehza1v470p-1098034
C16 | 1 | 47u | 1210 | TBD | CL32A476KOJNNNE | SAMSUNG | MLCC 1210 47uF 16V X5R 10% | 423179 | 53829 | 1 | 1 | 1 | 21.07 | 21.07 | Uygun | Yeni seçildi | +3.3V; 16V parça DC-bias'ta 6.3V/10V parçalardan daha fazla kapasite korur. X7R şartı varsa GRT32EC81A476ME13L (10V X6S) veya GCM32ER70J476KE19L (6.3V X7R). | https://www.ozdisan.com/p/smt-smd-ve-mlcc-kapasitorler-184/samsung-cl32a476kojnnne-423179
C18 | 1 | 10n | 0402 | TBD | CL05B103KA5NNNC | SAMSUNG | MLCC 0402 10nF 25V X7R 10% | 446224 | 43984 | 25 | 25 | 25 | 0.21 | 5.21 | Uygun | Yeni seçildi |  | https://www.ozdisan.com/p/smt-smd-ve-mlcc-kapasitorler-184/samsung-cl05b103ka5nnnc-446224
C19 | 1 | 18n (10n ∥ 8.2n) | 0402 ×2 | TBD | CL05B103KA5NNNC + CL05B822KB5NNNC | SAMSUNG | MLCC 0402 10nF 25V X7R + 8.2nF 50V X7R | 446224 / 521982 | 43984 |  |  | 25 + 20 |  | 10.33 | Muadil | Yeni seçildi | 21.09 üçüncü tur: 18 nF Özdisan'da hiçbir kılıfta (0402…1206, film dahil) yok; footprint büyütmek çözmüyor. Değeri korumak için 10 nF ∥ 8,2 nF = 18,2 nF (+%1) önerildi; bu, şemaya C19 yanına ikinci bir 0402 footprint eklemeyi gerektirir. Sipariş: 10n ×25 (MOQ) + 8.2n ×20 (MOQ).
C23 | 1 | 47n | 0402 | TBD | CL05B473KO5NNNC | SAMSUNG | MLCC 0402 47nF 16V X7R 10% | 443226 | 48227 | 20 | 20 | 20 | 0.28 | 5.68 | Uygun | Yeni seçildi |  | https://www.ozdisan.com/p/smt-smd-ve-mlcc-kapasitorler-184/samsung-cl05b473ko5nnnc-443226
C30 | 1 | 22n | 0402 | TBD | CC0402KRX7R9BB223 | YAGEO | MLCC 0402 22nF 50V X7R 10% | 746989 | 413880 | 20 | 20 | 20 | 0.33 | 6.57 | Uygun | Yeni seçildi |  | https://www.ozdisan.com/p/smt-smd-ve-mlcc-kapasitorler-184/yageo-cc0402krx7r9bb223-746989
C31 | 1 | 220n | 0603 (0402'den büyütüldü) | TBD | CL10B224KA8NNNC | SAMSUNG | MLCC 0603 220nF 25V X7R 10% | 15507 | 664332 | 10 | 10 | 10 | 0.57 | 5.73 | Uygun | Yeni seçildi | 21.09 üçüncü tur: Gerilim kontrolü (AP74502Q datasheet DS47093): kondansatör VCAP–VIN arasında; VCAP−VSRC şarj pompası en fazla 13,9V, VCAP–VIN mutlak maksimum 15V. 25V parça ~1,7x pay verir. 0402'de 220 nF en fazla 10V → 0603'e çıkıldı. 14V'ta DC-bias ile ~150 nF kalır, datasheet minimumu 0,1 µF. | https://www.ozdisan.com/p/smt-smd-ve-mlcc-kapasitorler-184/samsung-cl10b224ka8nnnc-15507
R1,R10,R27,R34,R35,R36,R37,R56,R57 | 9 | 10k | 0402 | TBD | TC0250B1002TCC | ROYALOHM | RES 0402 10K 0.1% 1/16W 50PPM | 569744 | 4220 | 5 | 5 | 10 | 1.42 | 14.22 | Uygun | Yeni seçildi | Özdisan'da 0402 10k yalnız 2 çeşit (%0,1 ince film). R39 bu gruptan çıkarıldı (10,2k). | https://www.ozdisan.com/p/smt-smd-ve-cip-direncler-194/royalohm-tc0250b1002tcc-569744
R59 | 1 | 10k | 0805 (0402'den büyütüldü) | TBD | HP05W3F1002T5E | ROYALOHM | RES 0805 10K 1% 1/3W high power AEC-Q200 | 604238 | 710 | 20 | 20 | 20 | 0.30 | 6.02 | Uygun | Yeni seçildi | 21.09 üçüncü tur: Watt kontrolü: R59 OUT_POS–GND bleed. Sürekli en kötü durum OVLO eşiği ~30V → P = 30²/10k = 90 mW (28V'ta 78 mW). %50 azaltma ile ≥0,18 W; handoff ≥0,25 W istiyor. 1/3 W 0805 ikisini de karşılar, çalışma gerilimi 150V (SMBJ30A kenetleme 48V geçişlerine de pay). Footprint 0402 → 0805. Footprint korunacaksa ERJPA2J103X (0402, 1/5 W) ≥0,18 W'ı karşılar ama stok yalnız 18. | https://www.ozdisan.com/p/smt-smd-ve-cip-direncler-194/royalohm-hp05w3f1002t5e-604238
R2,R3,R15,R16 | 4 | 22R | 0402 | TBD | RC0402FR-0722RP | YAGEO | RES 0402 22R 1% 1/16W | 839397 | 4562 | 25 | 25 | 25 | 0.25 | 6.17 | Uygun | Yeni seçildi |  | https://www.ozdisan.com/p/smt-smd-ve-cip-direncler-194/yageo-rc0402fr-0722rp-839397
R4,R5,R6,R7,R24,R25,R26 | 7 | 4k7 | 0402 | TBD | HP02WAF4701TCE | ROYALOHM | RES 0402 4.7K 1% 1/10W | 603918 | 9400 | 100 | 100 | 100 | 0.09 | 8.89 | Uygun | Yeni seçildi |  | https://www.ozdisan.com/p/smt-smd-ve-cip-direncler-194/royalohm-hp02waf4701tce-603918
R8 | 1 | 12k | 0402 | TBD | CRCW040212K0FKED | VISHAY | RES 0402 12K 1% 1/16W | 519356 | 6761 | 10 | 10 | 10 | 0.57 | 5.66 | Uygun | Yeni seçildi |  | https://www.ozdisan.com/p/smt-smd-ve-cip-direncler-194/vishay-crcw040212k0fked-519356
R9 | 1 | 20k | 0402 | TBD | TC0250B2002TCC | ROYALOHM | RES 0402 20K 0.1% 1/16W | 570296 | 3225 | 5 | 5 | 5 | 1.42 | 7.11 | Uygun | Yeni seçildi | 0402 20k %1 stokta yok; %0,1 seçildi (%5 alternatif RC0402JR-0720KL). | https://www.ozdisan.com/p/smt-smd-ve-cip-direncler-194/royalohm-tc0250b2002tcc-570296
R12 | 1 | 6k2 | 0402 | TBD | 0402WGF6201TCE | ROYALOHM | RES 0402 6.2K 1% 1/16W | 359873 | 19300 | 200 | 200 | 200 | 0.03 | 5.75 | Uygun | Yeni seçildi |  | https://www.ozdisan.com/p/smt-smd-ve-cip-direncler-194/royalohm-0402wgf6201tce-359873
R13,R28 | 2 | 100R | 0402 | TBD | TC0250B1000TCC | ROYALOHM | RES 0402 100R 0.1% 1/16W | 569711 | 7445 | 5 | 5 | 5 | 1.42 | 7.11 | Uygun | Yeni seçildi |  | https://www.ozdisan.com/p/smt-smd-ve-cip-direncler-194/royalohm-tc0250b1000tcc-569711
R14 | 1 | 2k2 | 0402 | TBD | ERJ2RKF2201X | PANASONIC | RES 0402 2.2K 1% 1/10W | 494655 | 67988 | 20 | 20 | 20 | 0.37 | 7.33 | Uygun | Yeni seçildi |  | https://www.ozdisan.com/p/smt-smd-ve-cip-direncler-194/panasoniceurope-erj2rkf2201x-494655
R29,R38,R42,R53,R58 | 5 | 100k | 0402 | TBD | CQ02WGF1003TCE | ROYALOHM | RES 0402 100K 1% 1/16W AEC-Q200 | 587906 | 99900 | 200 | 200 | 200 | 0.04 | 8.76 | Uygun | Yeni seçildi |  | https://www.ozdisan.com/p/smt-smd-ve-cip-direncler-194/royalohm-cq02wgf1003tce-587906
R21 (DNP) | 0 | 100k | 0402 | TBD | CQ02WGF1003TCE | ROYALOHM | RES 0402 100K 1% 1/16W AEC-Q200 | 587906 | 99900 |  |  |  | 0.04 |  | Satın alınmaz | Yeni seçildi | DNP; dizilmez. | https://www.ozdisan.com/p/smt-smd-ve-cip-direncler-194/royalohm-cq02wgf1003tce-587906
R51,R54 | 2 | 1k0 | 0402 | TBD | RT0402BRD071KL | YAGEO | RES 0402 1K 0.1% 1/16W 25PPM | 1212342 | 37995 | 5 | 5 | 5 | 2.55 | 12.73 | Uygun | Yeni seçildi | 0402 1k %1 stokta yok; %0,1 ince film seçildi. | https://www.ozdisan.com/p/smt-smd-ve-cip-direncler-194/yageo-rt0402brd071kl-1212342
R43 | 1 | 1k0 | 2512 | TBD | PS122WF1001T4E | ROYALOHM | RES 2512 1K 1% 2W anti-surge | 746122 | 93571 | 1 | 1 | 1 | 5.15 | 5.15 | Uygun | Yeni seçildi | 2W şartı (28V'ta 0.651W). | https://www.ozdisan.com/p/smt-smd-ve-cip-direncler-194/royalohm-ps122wf1001t4e-746122
R39 | 1 | 10k2 (10k yerine) | 0402 | TBD | RC1005F1022CS | SAMSUNG | RES 0402 10.2K 1% 1/16W | 695131 | 5865 | 20 | 20 | 20 | 0.36 | 7.25 | Muadil | Yeni seçildi | 21.09 üçüncü tur: R40 3,24k ile birlikte AOZ1284 çıkışını 3,3185V'ta tutmak için 10k → 10,2k (bkz. R40). | https://www.ozdisan.com/p/smt-smd-ve-cip-direncler-194/samsung-rc1005f1022cs-695131
R40 | 1 | 3k24 (3k20 yerine) | 0402 | TBD | ERJ2RKF3241X | PANASONIC | RES 0402 3.24K 1% 1/10W | 494659 | 76745 | 20 | 20 | 20 | 0.37 | 7.33 | Muadil | Yeni seçildi | 21.09 üçüncü tur: AOZ1284 FB bölücüsü (R39 üst, R40 alt, VFB 0,8V). %1'de 3,2k yok → R40 = 3,24k; çıkışı korumak için R39 10k → 10,2k. VOUT = 0,8×(1+10,2/3,24) = 3,3185V (eski 3,300V; +%0,56, AOZ1284 VFB toleransı ±%1,5 içinde). R46 ile aynı MPN. | https://www.ozdisan.com/p/smt-smd-ve-cip-direncler-194/panasoniceurope-erj2rkf3241x-494659
R41 | 1 | 12k7 | 0402 | TBD | 0402WGF1272TCE | ROYALOHM | RES 0402 12.7K 1% 1/16W | 506317 | 18380 | 200 | 200 | 200 | 0.03 | 5.75 | Uygun | Yeni seçildi |  | https://www.ozdisan.com/p/smt-smd-ve-cip-direncler-194/royalohm-0402wgf1272tce-506317
R47 | 1 | 78k7 | 0402 | TBD | 0402WGF7872TCE | ROYALOHM | RES 0402 78.7K 1% 1/16W | 506387 | 7070 | 200 | 200 | 200 | 0.03 | 5.75 | Uygun | Yeni seçildi |  | https://www.ozdisan.com/p/smt-smd-ve-cip-direncler-194/royalohm-0402wgf7872tce-506387
R48 | 1 | 30k1 | 0402 | TBD | 0402WGF3012TCE | ROYALOHM | RES 0402 30.1K 1% 1/16W | 506349 | 10680 | 200 | 200 | 200 | 0.03 | 5.75 | Uygun | Yeni seçildi |  | https://www.ozdisan.com/p/smt-smd-ve-cip-direncler-194/royalohm-0402wgf3012tce-506349
R49 | 1 | 9k76 | 0402 | TBD | 0402WGF9761TCE | ROYALOHM | RES 0402 9.76K 1% 1/16W | 506310 | 17170 | 200 | 200 | 200 | 0.03 | 5.75 | Uygun | Yeni seçildi |  | https://www.ozdisan.com/p/smt-smd-ve-cip-direncler-194/royalohm-0402wgf9761tce-506310
R50 | 1 | 820R | 0402 | TBD | RC0402JR-07820RL | YAGEO | RES 0402 820R 5% 1/16W | 423409 | 92000 | 100 | 100 | 100 | 0.07 | 6.57 | Uygun | Yeni seçildi | 0402 820R yalnız %5 stokta. | https://www.ozdisan.com/p/smt-smd-ve-cip-direncler-194/yageo-rc0402jr-07820rl-423409
R52 | 1 | 2k0 | 0402 | TBD | ERJ2RKF2001X | PANASONIC | RES 0402 2K 1% 1/10W | 518487 | 34590 | 20 | 20 | 20 | 0.37 | 7.33 | Uygun | Yeni seçildi |  | https://www.ozdisan.com/p/smt-smd-ve-cip-direncler-194/panasoniceurope-erj2rkf2001x-518487
R55 | 1 | 232k | 0402 | TBD | 0402WGF2323TCE | ROYALOHM | RES 0402 232K 1% 1/16W | 506426 | 6600 | 200 | 200 | 200 | 0.03 | 5.75 | Uygun | Yeni seçildi |  | https://www.ozdisan.com/p/smt-smd-ve-cip-direncler-194/royalohm-0402wgf2323tce-506426
R11,RShunt1 | 2 | 5m0 | 2512 | TBD | BVT-I-R005-1.0 | ISABELLENHÜTTE | RES.SHUNT 2512 5mΩ 1% 2.5W Isaohm AEC-Q200 | 536256 | 774 | 1 | 1 | 2 | 56.16 | 112.32 | Uygun | Yeni seçildi | 21.09 dördüncü tur: 'Hassas ve Şönt Dirençler' kategorisi indekslendi; stok 774 (+25 yolda) doğrulandı. Datasheet (BVT 2512): 6,35×3,05 mm, 5 mΩ ±%1, TCR 0±50 ppm/K, 2,5 W @70°C / 1,5 W @100°C terminal; 5 A'de kayıp 0,125 W. Footprint notu: KiCad R_2512_6332Metric mekanik olarak uyar; üretici ped önerisi farklı (toplam 7 mm, genişlik 3,4 mm, iç aralık 1,8 mm), ısı ve Kelvin ölçüm noktası için özel footprint önerilir. Alternatif: VMS-R005-1.0-U (Isabellenhütte, 2512, 3 W, TCR ±20 ppm/K, 1473 stok, 54,08 TL) — ped düzeni VMS datasheet'ine göre kontrol edilmeli. | https://www.ozdisan.com/p/hassas-ve-sont-direncler-195/isabellenhutte-bvt-i-r005-1-0-536256
TOPLAM (fiyatı bulunan satırlar)

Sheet: Ozet
Durum | Satır | Parça adedi | Anlamı
Uygun |  |  | Özdisan stoğunda, tasarım şartlarını karşılıyor
Muadil |  |  | Tasarım MPN'i yok; aynı kılıf/pin dizilişli muadil seçildi
Uyarı |  |  | Stokta ama bir şartı tam karşılamıyor (gerilim, dielektrik, tolerans, akım) — Not sütununa bakın
Stokta yok |  |  | Özdisan'da stokta uygun parça yok
İndekste yok |  |  | Kategorisi Özdisan indeksinde yok; stok doğrulanamadı
Satın alınmaz |  |  | Satın alınmaz (test pedi / DNP)
Fiyatlı satırların toplamı (TRY)
Kaynak: Özdisan MCP yerel indeksi, son güncelleme 2026-09-21. Fiyatlar TRY, 1 kart için; sipariş adedi MOQ ve sipariş katına yuvarlandı.
Tasarım değiştirilmedi. Şemadaki MPN alanları olduğu gibi duruyor; bu tablo yalnız öneridir.
'Önceden seçilmiş': şema notları veya design_decisions raporlarında Özdisan stoğuna göre seçildiği belirtilen parçalar.
22.09 TFT032B018 revizyonu: NHD-2.4 + TPS61023 boost + CAT4104 → TFT032B018 (3,2" IPS, ST7789V2) + KLS 30p FPC + Q7/R60 PWM backlight; U7, U8, L2, C20, C21, C22, R44, R45, R46 kaldırıldı.
21.09 RTC revizyonu: RV-3028-C7 + CR2032 → BQ32000DR + 1,5F süper kapasitör (C33) + kristal Y1; BT1, R22, R23, C10 kaldırıldı, C9 1u0 oldu.
21.09 üçüncü tur: U2/U4/U7/J7 muadil kontrolü, C3/C5/C8/C15/C19/C20/C21/C25/C27/C28/C29/C31 ve R39/R40/R44/R46/R59/R11/RShunt1 yeniden seçildi. Footprint veya değer değişikliği gerektiren satırlar Not sütununda belirtildi; şema değiştirilmedi.
21.09 ikinci kontrol: pil tutucu, FFC/FPC, PCB klemens, LED ve Wi-Fi modül kategorileri indekse eklendi. Hâlâ indekslenmemiş: USB konnektörler (J7) ve binding post (J5, J6); bu satırlar Özdisan'a ayrıca sorulmalı.

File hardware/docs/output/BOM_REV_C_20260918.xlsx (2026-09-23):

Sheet: BOM
# | Adet | Referanslar | Value | Açıklama | Package | Footprint | Üretici | MPN | Kategori | Alt Kategori | Montaj | Lifecycle | RoHS | DNP | Sayfalar | Durum | Datasheet | Tasarım Notu
1 |  | U5 | AOZ1284PI | 4A Buck Regulator, 3-36V input, 0.8-30V output, 0.2 - 2MHz, SOIC-8 | SOIC-8-EP | Package_SO:SOIC-8-1EP_3.9x4.9mm_P1.27mm_EP2.71x3.7mm | Alpha & Omega Semiconductor | AOZ1284PI | Integrated Circuits | PMIC - Voltage Regulators - DC DC Switching | Surface Mount | TBD | TBD |  | USB_PD_CONTROLLER |  | https://www.aosmd.com/res/datasheets/AOZ1284PI.pdf | Tedarik: Ozdisan.
2 |  | U1 | AP33772SDKZ-13-FA02 | USB Type-C PD3.1 Sink Controller, EPR/AVS up to 28V, SPR/AVS up to 21V, I2C interface, WQFN-24 | WQFN-24 (4x4mm) | Package_DFN_QFN:Texas_RTW_WQFN-24-1EP_4x4mm_P0.5mm_EP2.7x2.7mm | Diodes Incorporated | AP33772SDKZ-13-FA02 | Integrated Circuits | Interface - Specialized (USB PD) | Surface Mount | TBD | TBD |  | USB_PD_CONTROLLER |  | https://www.diodes.com/datasheet/download/AP33772S.pdf | Kesin parca; kapi surusu Q3/Q4 ile dogrulanmali.
3 |  | U12 | AP74502Q | TBD | TSOT-23-8 | Package_TO_SOT_SMD:TSOT-23-8_HandSoldering | Power_Path_Custom | AP74502Q | Integrated Circuits | PMIC - Power Distribution Switches, Load Drivers | Surface Mount | TBD | TBD |  | USB_PD_CONTROLLER |  | ~ | TBD
4 |  | U8 | CAT4104V-GT3 | Resistor | SOIC-8 | Package_SO:SOIC-8_3.9x4.9mm_P1.27mm | onsemi | CAT4104V-GT3 | Integrated Circuits | PMIC - LED Drivers | Surface Mount | TBD | TBD |  | USER INTERFACE |  | https://www.onsemi.com/download/data-sheet/pdf/cat4104-d.pdf | TBD
5 |  | U2 | ESP32-C6-WROOM-1 | ESP32-C6-WROOM-1/U is a module that supports 2.4 GHz Wi-Fi 6 (802.11 ax), Bluetooth® 5 (LE), Zigbee and Thread (802.15.4) | WROOM-1 Module (18x25.5mm) | PCM_Espressif:ESP32-C6-WROOM-1 | Espressif Systems | ESP32-C6-WROOM-1 | Integrated Circuits | Embedded - Microcontrollers / RF Modules | Surface Mount | TBD | TBD |  | MCU |  | https://www.espressif.com/sites/default/files/documentation/esp32-c6-wroom-1_wroom-1u_datasheet_en.pdf | Modul varyanti / flash kapasitesi satin alma oncesi sabitlenmeli.
6 |  | U3 | INA228 | High-Side or Low-Side Measurement, Bi-Directional Current and Power Monitor (0-85V) with I2C, SMBus-, and PMBus-Compatible Interface, TSSOP-10 (Texas DGS0010A / VSSOP) | VSSOP-10 (DGS) | Package_SO:TSSOP-10_3x3mm_P0.5mm | Texas Instruments | INA228AIDGSR | Integrated Circuits | Linear - Amplifiers / Data Acquisition | Surface Mount | TBD | TBD |  | USB_PD_CONTROLLER |  | https://www.ti.com/lit/ds/symlink/ina228.pdf | Siparis suffix'i ve sicaklik sinifi secilmeli.
7 |  | U4 | RV-3028-C7 | Realtime Clock/Calendar I2C Interface, Extreme Low Power, 1.1 V to 5.5 V, MicroCrystal C7 | C7 SON-8 (1.5x3.2mm) | Package_SON:MicroCrystal_C7_SON-8_1.5x3.2mm_P0.9mm | Micro Crystal | RV-3028-C7 | Integrated Circuits | Logic / Memory / Clock-Timing | Surface Mount | TBD | TBD |  | MCU |  | https://www.microcrystal.com/fileadmin/Media/Products/RTC/Datasheet/RV-3028-C7.pdf | Trickle charge kapali kullanilacak.
8 |  | U6 | TL431BIDBZR | TBD | SOT-23 | Package_TO_SOT_SMD:SOT-23 | Texas Instruments | TL431BIDBZR | Integrated Circuits | Linear - Amplifiers / Data Acquisition | Surface Mount | TBD | TBD |  | USB_PD_CONTROLLER |  | TBD | TI TL431 DBZ: K=1, REF=2, A=3. REF, K'ya bagli. Ek kapasitif yuk yok.
9 |  | U10 | TPD4EUSB30 | 4-Channel ESD Protection for Super-Speed USB 3.0 Interface, USON-10 | USON-10 (2.5x1.0mm) | Package_SON:USON-10_2.5x1.0mm_P0.5mm | Texas Instruments | TPD4EUSB30 | Circuit Protection | TVS Diodes | Surface Mount | TBD | TBD |  | USB_C_INPUT |  | http://www.ti.com/lit/ds/symlink/tpd2eusb30a.pdf | USB2.0 veri hatti ESD dizisi.
10 |  | U11 | TPS55340PWPR | TBD | HTSSOP-14 (PWP) | Package_SO:Texas_HTSSOP-14-1EP_4.4x5mm_P0.65mm_EP3.4x5mm_Mask3.155x3.255mm_ThermalVias | Texas Instruments | TPS55340PWPR | Integrated Circuits | PMIC - Voltage Regulators - DC DC Switching | Surface Mount | TBD | TBD |  | USB_PD_CONTROLLER |  | ~ | TBD
11 |  | U7 | TPS61023DRLR | Resistor | TBD | Power_Management_Custom:TPS61023_DRL0006A | Texas Instruments | TPS61023DRLR | Integrated Circuits | PMIC - Voltage Regulators - DC DC Switching | Surface Mount | TBD | TBD |  | USER INTERFACE |  | https://www.ti.com/lit/ds/symlink/tps61023.pdf | TBD
12 |  | Q5, Q6 | 60V 4mR TBD | TBD | TBD |  | TBD | TBD | Discrete Semiconductor Products | FETs, MOSFETs - Single | TBD | TBD | TBD |  | USB_PD_CONTROLLER |  | ~ | Parca secilmedi; 60V / 4mOhm hedefi ile aranacak.
13 |  | Q1, Q2 | BSS138 | 50V Vds, 0.22A Id, N-Channel MOSFET, SOT-23 | SOT-23 | Package_TO_SOT_SMD:SOT-23 | onsemi | BSS138 | Discrete Semiconductor Products | FETs, MOSFETs - Single | Surface Mount | TBD | TBD |  | USB_PD_CONTROLLER |  | https://www.onsemi.com/pub/Collateral/BSS138-D.PDF | TBD
14 |  | Q3, Q4 | IRF7855TRPBF | N-MOSFET transistor, gate/source/drain | SOIC-8 | Package_SO:SOIC-8_3.9x4.9mm_P1.27mm | Infineon Technologies | IRF7855TRPBF | Discrete Semiconductor Products | FETs, MOSFETs - Single | Surface Mount | TBD | TBD |  | USB_PD_CONTROLLER |  | TBD | Prototip secimi; AP33772S kapi seviyesiyle kayip/SOA acik.
15 |  | D5 | BAT54 | TBD | SOD-123 | Diode_SMD:D_SOD-123 | TBD | BAT54 | Discrete Semiconductor Products | Diodes | Surface Mount | TBD | TBD |  | USB_PD_CONTROLLER |  | ~ | TBD
16 |  | D6 | BZT52C12 | TBD | SOD-123 | Diode_SMD:D_SOD-123 | TBD | BZT52C12 | Discrete Semiconductor Products | Diodes | Surface Mount | TBD | TBD |  | USB_PD_CONTROLLER |  | ~ | TBD
17 |  | D1 | LED | Light emitting diode | 0402 (1005 Metric) | LED_SMD:LED_0402_1005Metric | TBD | TBD | Optoelectronics | LED Indication - Discrete | Surface Mount | TBD | TBD |  | USB_PD_CONTROLLER |  | TBD | TBD
18 |  | D3, D7 | SMBJ30A | 400W unidirectional Transient Voltage Suppressor, 30.0Vr, SMA(DO-214AC) | TBD | SMB (DO-214AA) | Diode_SMD:D_SMB | TBD | SMBJ30A | Circuit Protection | TVS Diodes | Surface Mount | TBD | TBD |  | USB_C_INPUT, USB_PD_CONTROLLER |  | https://www.littelfuse.com/media?itemid=75e32973-b177-4ee3-a0ff-cedaf1abdb93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 | ~ | TBD
19 |  | D2 | SS2060FL | TBD | SOD-123F | Diode_SMD:D_SOD-123F | PANJIT | SS2060FL_R1_00001 | Discrete Semiconductor Products | Diodes | Surface Mount | TBD | TBD |  | USB_PD_CONTROLLER |  | https://www.ozdisan.com/p/schottky-diyotlar-385/panjit-ss2060fl-r1-00001-574723 | Katot LX, anot GND. Tedarik: Ozdisan.
20 |  | D4 | SS34 TBD | TBD | SMA (DO-214AC) | Diode_SMD:D_SMA | TBD | TBD | Discrete Semiconductor Products | Diodes | Surface Mount | TBD | TBD |  | USB_PD_CONTROLLER |  | ~ | SS34 hedefi; kesin MPN secilmedi.
21 |  | L1 | 22u | TBD | 7.3x7.3x4.5mm | Inductor_SMD:L_7.3x7.3_H4.5 | CORE MASTER | SRI0704-220M | Inductors, Coils, Chokes | Fixed Inductors | Surface Mount | TBD | TBD |  | USB_PD_CONTROLLER |  | https://store.comet.bg/download-file.php?id=16477 | 22uH, 1.95A, 0.11ohm max; 1.95A'de 18.2uH (L -17%).
22 |  | L2 | 2u2 | TBD | MAPI-4030 (4.0x3.0mm) | Inductor_SMD:L_Wuerth_MAPI-4030 | Wurth Elektronik | 74438357022 | Inductors, Coils, Chokes | Fixed Inductors | Surface Mount | TBD | TBD |  | USER INTERFACE |  | https://www.we-online.com/components/products/datasheet/74438357022.pdf | Isat >=2A ve Irms >=1.5A (max sicaklikta) gerekir; ariza akimi kontrol edildi.
23 |  | L3 | 6u8 | TBD | 1210 (3225 Metric) | Inductor_SMD:L_1210_3225Metric | TBD | TBD | Inductors, Coils, Chokes | Fixed Inductors | Surface Mount | TBD | TBD |  | USB_PD_CONTROLLER |  | ~ | TBD
24 |  | C14 | 100n | TBD | 0402 (1005 Metric) | Capacitor_SMD:C_0402_1005Metric | TBD | TBD | Capacitors | Ceramic Capacitors | Surface Mount | TBD | TBD |  | USB_PD_CONTROLLER |  | TBD | X7R.
25 |  | C1, C2, C6, C9, C10, C11, C24 | 100n | Unpolarized capacitor | TBD | 0402 (1005 Metric) | Capacitor_SMD:C_0402_1005Metric | TBD | TBD | Capacitors | Ceramic Capacitors | Surface Mount | TBD | TBD |  | MCU, USB_PD_CONTROLLER |  | TBD | ~ | TBD
26 |  | C17 | 100n | TBD | 0402 (1005 Metric) | Capacitor_SMD:C_0402_1005Metric | TBD | TBD | Capacitors | Ceramic Capacitors | Surface Mount | TBD | TBD |  | USB_PD_CONTROLLER |  | TBD | TBD
27 |  | C26, C32 | 100n | TBD | 0402 (1005 Metric) | Capacitor_SMD:C_0402_1005Metric | TBD | TBD | Capacitors | Ceramic Capacitors | Surface Mount | TBD | TBD |  | USB_PD_CONTROLLER |  | ~ | TBD
28 |  | C22 | 100n | TBD | 0402 (1005 Metric) | Capacitor_SMD:C_0402_1005Metric | TBD | TBD | Capacitors | Ceramic Capacitors | Surface Mount | TBD | TBD |  | USER INTERFACE |  | TBD | X7R.
29 |  | C18 | 10n | TBD | 0402 (1005 Metric) | Capacitor_SMD:C_0402_1005Metric | TBD | TBD | Capacitors | Ceramic Capacitors | Surface Mount | TBD | TBD |  | USB_PD_CONTROLLER |  | TBD | TBD
30 |  | C8 | 10u | Unpolarized capacitor | 0402 (1005 Metric) | Capacitor_SMD:C_0402_1005Metric | TBD | TBD | Capacitors | Ceramic Capacitors | Surface Mount | TBD | TBD |  | USB_PD_CONTROLLER |  | TBD | TBD
31 |  | C12, C13 | 10u | TBD | 1210 (3225 Metric) | Capacitor_SMD:C_1210_3225Metric | TBD | TBD | Capacitors | Ceramic Capacitors | Surface Mount | TBD | TBD |  | USB_PD_CONTROLLER |  | TBD | X7R; C12+C13 efektif kapasite 28V'ta >=10uF olmali, MPN dogrulanacak.
32 |  | C25, C27, C28 | 10u | TBD | 1210 (3225 Metric) | Capacitor_SMD:C_1210_3225Metric | TBD | TBD | Capacitors | Ceramic Capacitors | Surface Mount | TBD | TBD |  | USB_PD_CONTROLLER |  | ~ | TBD
33 |  | C19 | 18n | TBD | 0402 (1005 Metric) | Capacitor_SMD:C_0402_1005Metric | TBD | TBD | Capacitors | Ceramic Capacitors | Surface Mount | TBD | TBD |  | USB_PD_CONTROLLER |  | TBD | TBD
34 |  | C4 | 1u0 | Unpolarized capacitor | 0402 (1005 Metric) | Capacitor_SMD:C_0402_1005Metric | TBD | TBD | Capacitors | Ceramic Capacitors | Surface Mount | TBD | TBD |  | USB_PD_CONTROLLER |  | TBD | TBD
35 |  | C7 | 1u0 | Unpolarized capacitor | 0402 (1005 Metric) | Capacitor_SMD:C_0402_1005Metric | TBD | TBD | Capacitors | Ceramic Capacitors | Surface Mount | TBD | TBD |  | MCU |  | TBD | TBD
36 |  | C31 | 220n | TBD | 0402 (1005 Metric) | Capacitor_SMD:C_0402_1005Metric | TBD | TBD | Capacitors | Ceramic Capacitors | Surface Mount | TBD | TBD |  | USB_PD_CONTROLLER |  | ~ | TBD
37 |  | C30 | 22n | TBD | 0402 (1005 Metric) | Capacitor_SMD:C_0402_1005Metric | TBD | TBD | Capacitors | Ceramic Capacitors | Surface Mount | TBD | TBD |  | USB_PD_CONTROLLER |  | ~ | TBD
38 |  | C5 | 22u | Unpolarized capacitor | 0402 (1005 Metric) | Capacitor_SMD:C_0402_1005Metric | TBD | TBD | Capacitors | Ceramic Capacitors | Surface Mount | TBD | TBD |  | MCU |  | TBD | TBD
39 |  | C20, C21 | 22u | TBD | 0402 (1005 Metric) | Capacitor_SMD:C_0402_1005Metric | TBD | TBD | Capacitors | Ceramic Capacitors | Surface Mount | TBD | TBD |  | USER INTERFACE |  | TBD | X7R.
40 |  | C3 | 2u2 | Unpolarized capacitor | 0805 (2012 Metric) | Capacitor_SMD:C_0805_2012Metric | TBD | TBD | Capacitors | Ceramic Capacitors | Surface Mount | TBD | TBD |  | USB_PD_CONTROLLER |  | TBD | TBD
41 |  | C23 | 47n | TBD | 0402 (1005 Metric) | Capacitor_SMD:C_0402_1005Metric | TBD | TBD | Capacitors | Ceramic Capacitors | Surface Mount | TBD | TBD |  | USB_PD_CONTROLLER |  | ~ | TBD
42 |  | C15 | 47u | TBD | 0402 (1005 Metric) | Capacitor_SMD:C_0402_1005Metric | TBD | TBD | Capacitors | Ceramic Capacitors | Surface Mount | TBD | TBD |  | USB_PD_CONTROLLER |  | TBD | X7R; banka efektif Cout 3.3V'ta >=44uF olmali, MPN dogrulanacak.
43 |  | C16 | 47u | TBD | 1210 (3225 Metric) | Capacitor_SMD:C_1210_3225Metric | TBD | TBD | Capacitors | Ceramic Capacitors | Surface Mount | TBD | TBD |  | USB_PD_CONTROLLER |  | TBD | X7R; banka efektif Cout 3.3V'ta >=44uF olmali, MPN dogrulanacak.
44 |  | C29 | 47u | TBD | 1210 (3225 Metric) | Capacitor_SMD:C_1210_3225Metric | TBD | TBD | Capacitors | Ceramic Capacitors | Surface Mount | TBD | TBD |  | USB_PD_CONTROLLER |  | ~ | TBD
45 |  | R13, R28 | 100R | Resistor | 0402 (1005 Metric) | Resistor_SMD:R_0402_1005Metric | TBD | TBD | Resistors | Chip Resistor - Surface Mount | Surface Mount | TBD | TBD |  | USB_PD_CONTROLLER, USER INTERFACE |  | TBD | TBD
46 |  | R38 | 100k | TBD | 0402 (1005 Metric) | Resistor_SMD:R_0402_1005Metric | TBD | TBD | Resistors | Chip Resistor - Surface Mount | Surface Mount | TBD | TBD |  | USB_PD_CONTROLLER |  | TBD | TBD
47 |  | R21 | 100k | Resistor | 0402 (1005 Metric) | Resistor_SMD:R_0402_1005Metric | TBD | TBD | Resistors | Chip Resistor - Surface Mount | Surface Mount | TBD | TBD | EVET | USB_PD_CONTROLLER |  | TBD | TBD
48 |  | R29, R42, R53, R58 | 100k | Resistor | TBD | 0402 (1005 Metric) | Resistor_SMD:R_0402_1005Metric | TBD | TBD | Resistors | Chip Resistor - Surface Mount | Surface Mount | TBD | TBD |  | USB_PD_CONTROLLER, USER INTERFACE |  | TBD | ~ | TBD
49 |  | R45 | 100k | Resistor | 0402 (1005 Metric) | Resistor_SMD:R_0402_1005Metric | TBD | TBD | Resistors | Chip Resistor - Surface Mount | Surface Mount | TBD | TBD |  | USER INTERFACE |  | TBD | TBD
50 |  | R39 | 10k | TBD | 0402 (1005 Metric) | Resistor_SMD:R_0402_1005Metric | TBD | TBD | Resistors | Chip Resistor - Surface Mount | Surface Mount | TBD | TBD |  | USB_PD_CONTROLLER |  | TBD | TBD
51 |  | R1, R10, R23, R27, R34, R35, R36, R37, R56, R57 | 10k | Resistor | TBD | 0402 (1005 Metric) | Resistor_SMD:R_0402_1005Metric | TBD | TBD | Resistors | Chip Resistor - Surface Mount | Surface Mount | TBD | TBD |  | MCU, USB_PD_CONTROLLER, USER INTERFACE |  | TBD | ~ | TBD
52 |  | R59 | 10k | TBD | 0402 (1005 Metric) | Resistor_SMD:R_0402_1005Metric | TBD | TBD | Resistors | Chip Resistor - Surface Mount | Surface Mount | TBD | TBD |  | USB_PD_CONTROLLER |  | ~ | TBD
53 |  | R8 | 12k | Resistor | 0402 (1005 Metric) | Resistor_SMD:R_0402_1005Metric | TBD | TBD | Resistors | Chip Resistor - Surface Mount | Surface Mount | TBD | TBD |  | USB_PD_CONTROLLER |  | TBD | TBD
54 |  | R41 | 12k7 | TBD | 0402 (1005 Metric) | Resistor_SMD:R_0402_1005Metric | TBD | TBD | Resistors | Chip Resistor - Surface Mount | Surface Mount | TBD | TBD |  | USB_PD_CONTROLLER |  | TBD | TBD
55 |  | R22, R51, R54 | 1k0 | Resistor | TBD | 0402 (1005 Metric) | Resistor_SMD:R_0402_1005Metric | TBD | TBD | Resistors | Chip Resistor - Surface Mount | Surface Mount | TBD | TBD |  | MCU, USB_PD_CONTROLLER |  | TBD | ~ | TBD
56 |  | R43 | 1k0 | TBD | 2512 (6332 Metric) | Resistor_SMD:R_2512_6332Metric | TBD | TBD | Resistors | Chip Resistor - Surface Mount | Surface Mount | TBD | TBD |  | USB_PD_CONTROLLER |  | TBD | Sont besleme: 28V'ta 0.651W. Gercek 2W parca secilecek; ayak 2512.
57 |  | R9 | 20k | Resistor | 0402 (1005 Metric) | Resistor_SMD:R_0402_1005Metric | TBD | TBD | Resistors | Chip Resistor - Surface Mount | Surface Mount | TBD | TBD |  | USB_PD_CONTROLLER |  | TBD | TBD
58 |  | R2, R3, R15, R16 | 22R | Resistor | 0402 (1005 Metric) | Resistor_SMD:R_0402_1005Metric | TBD | TBD | Resistors | Chip Resistor - Surface Mount | Surface Mount | TBD | TBD |  | MCU |  | TBD | TBD
59 |  | R55 | 232k | TBD | 0402 (1005 Metric) | Resistor_SMD:R_0402_1005Metric | TBD | TBD | Resistors | Chip Resistor - Surface Mount | Surface Mount | TBD | TBD |  | USB_PD_CONTROLLER |  | ~ | TBD
60 |  | R52 | 2k0 | TBD | 0402 (1005 Metric) | Resistor_SMD:R_0402_1005Metric | TBD | TBD | Resistors | Chip Resistor - Surface Mount | Surface Mount | TBD | TBD |  | USB_PD_CONTROLLER |  | ~ | TBD
61 |  | R14 | 2k2 | Resistor | 0402 (1005 Metric) | Resistor_SMD:R_0402_1005Metric | TBD | TBD | Resistors | Chip Resistor - Surface Mount | Surface Mount | TBD | TBD |  | USB_PD_CONTROLLER |  | TBD | TBD
62 |  | R48 | 30k1 | TBD | 0402 (1005 Metric) | Resistor_SMD:R_0402_1005Metric | TBD | TBD | Resistors | Chip Resistor - Surface Mount | Surface Mount | TBD | TBD |  | USB_PD_CONTROLLER |  | ~ | TBD
63 |  | R40 | 3k20 | TBD | 0402 (1005 Metric) | Resistor_SMD:R_0402_1005Metric | TBD | TBD | Resistors | Chip Resistor - Surface Mount | Surface Mount | TBD | TBD |  | USB_PD_CONTROLLER |  | TBD | TBD
64 |  | R46 | 3k24 | Resistor | 0402 (1005 Metric) | Resistor_SMD:R_0402_1005Metric | TBD | TBD | Resistors | Chip Resistor - Surface Mount | Surface Mount | TBD | TBD |  | USER INTERFACE |  | TBD | TBD
65 |  | R4, R5, R6, R7, R24, R25, R26 | 4k7 | Resistor | 0402 (1005 Metric) | Resistor_SMD:R_0402_1005Metric | TBD | TBD | Resistors | Chip Resistor - Surface Mount | Surface Mount | TBD | TBD |  | MCU, USB_PD_CONTROLLER |  | TBD | TBD
66 |  | R11, RShunt1 | 5m0 | Resistor | 2512 (6332 Metric) | Resistor_SMD:R_2512_6332Metric | TBD | TBD | Resistors | Current Sense Resistors | Surface Mount | TBD | TBD |  | USB_PD_CONTROLLER |  | TBD | TBD
67 |  | R44 | 604k | Resistor | 0402 (1005 Metric) | Resistor_SMD:R_0402_1005Metric | TBD | TBD | Resistors | Chip Resistor - Surface Mount | Surface Mount | TBD | TBD |  | USER INTERFACE |  | TBD | TBD
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

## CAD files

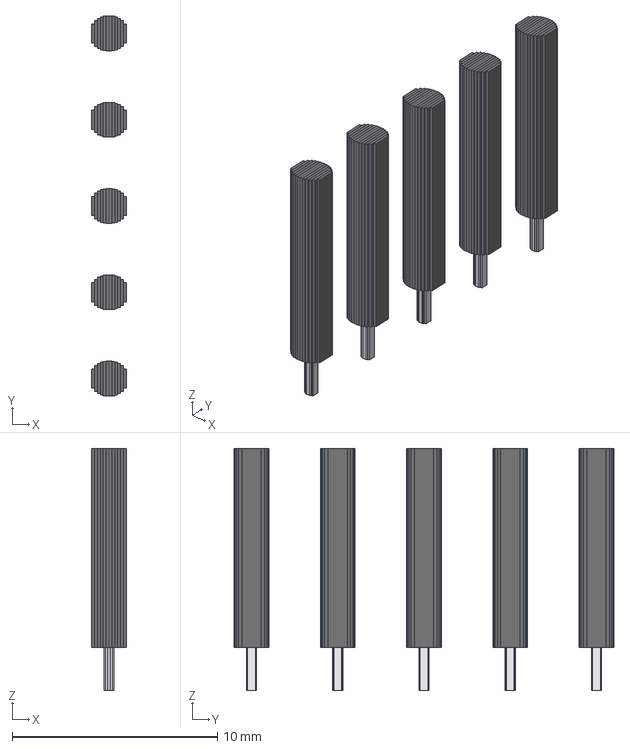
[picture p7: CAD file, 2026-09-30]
hardware/docs/reports/port-stack-fix-20260925/J9.step
1.70 x 18.5 x 11.8 mm

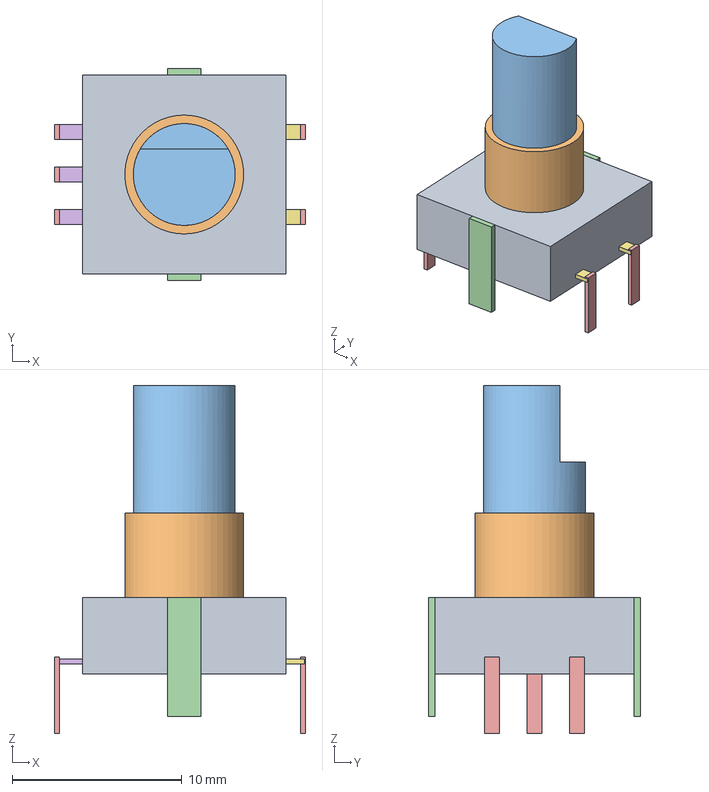
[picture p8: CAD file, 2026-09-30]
hardware/docs/reports/task-094-20260925/encoder-axis-origin.step
14.8 x 12.5 x 20.5 mm

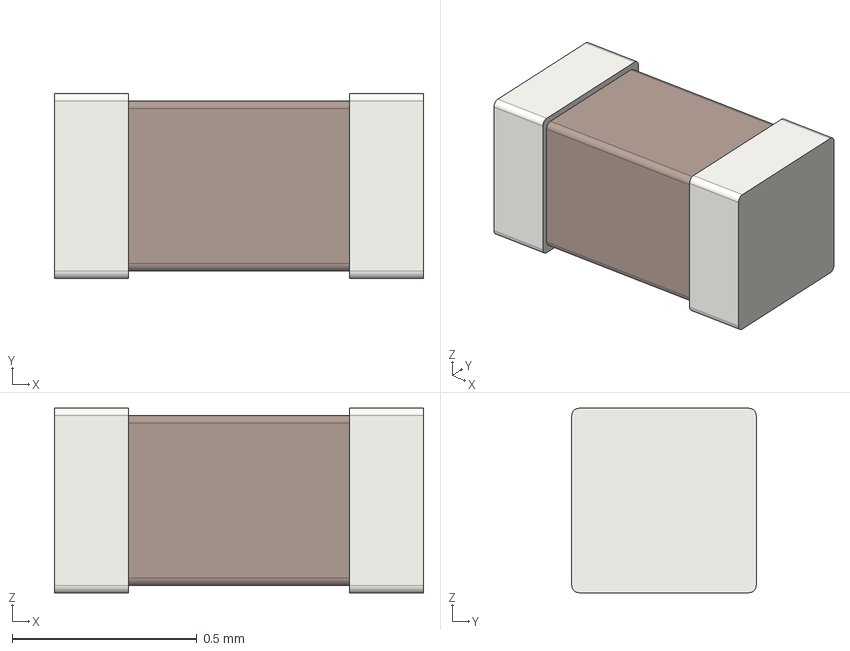
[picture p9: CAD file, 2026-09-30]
hardware/docs/reports/task-095-20260928/C1.step
1.00 x 0.5 x 0.5 mm

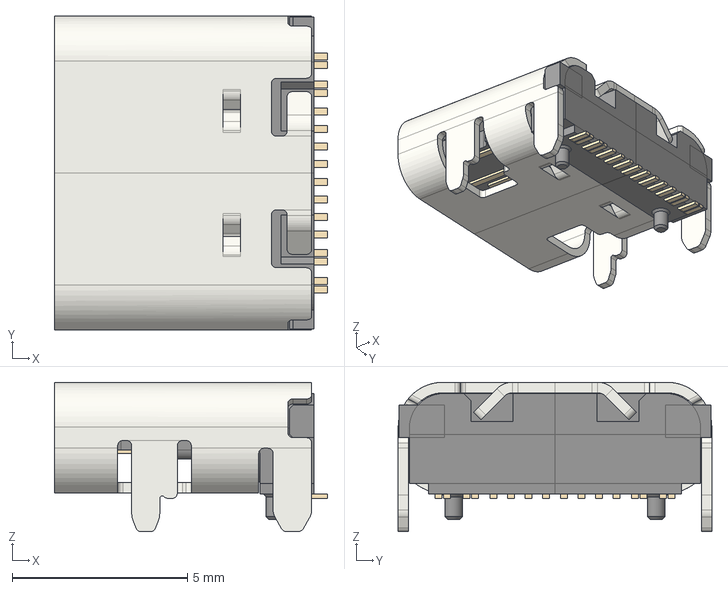
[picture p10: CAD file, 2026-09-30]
hardware/docs/reports/port-stack-fix-20260925/J7.step
7.78 x 8.94 x 4.26 mm

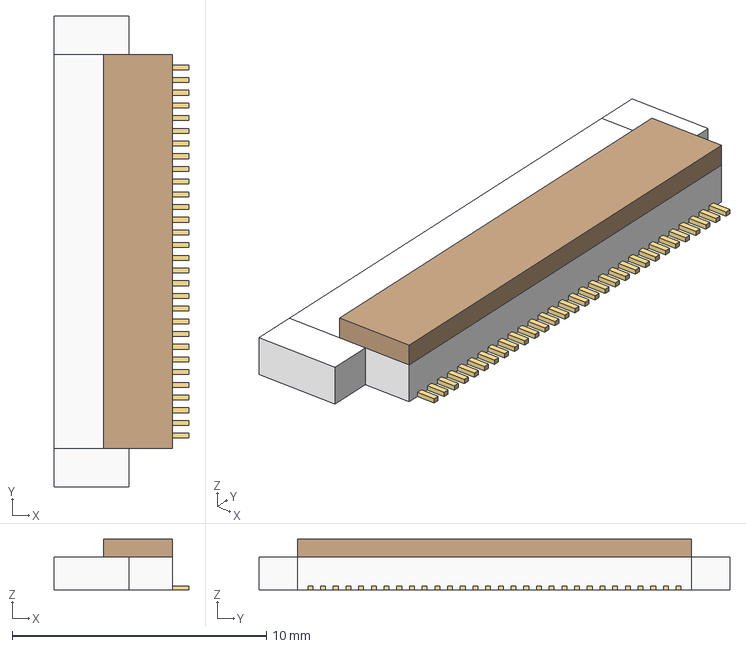
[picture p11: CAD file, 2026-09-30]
hardware/docs/reports/task-094-20260925/J3.step
5.30 x 18.5 x 2.00 mm

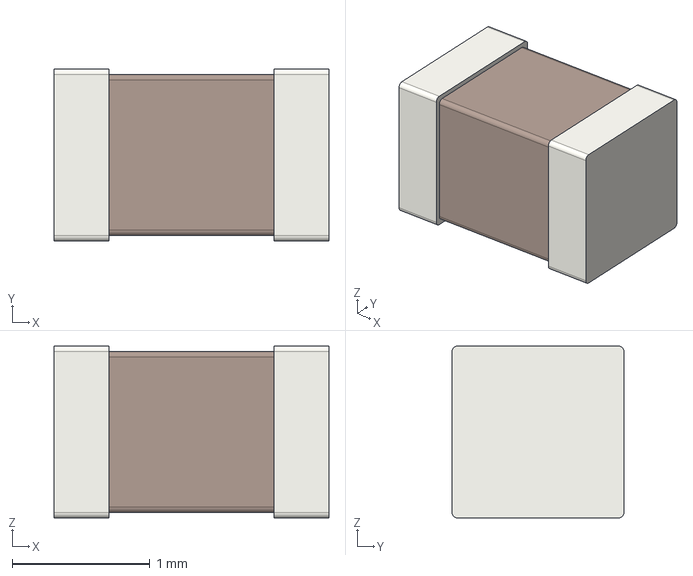
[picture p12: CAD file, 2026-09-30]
hardware/docs/reports/task-095-20260928/C3.step
2.00 x 1.25 x 1.25 mm

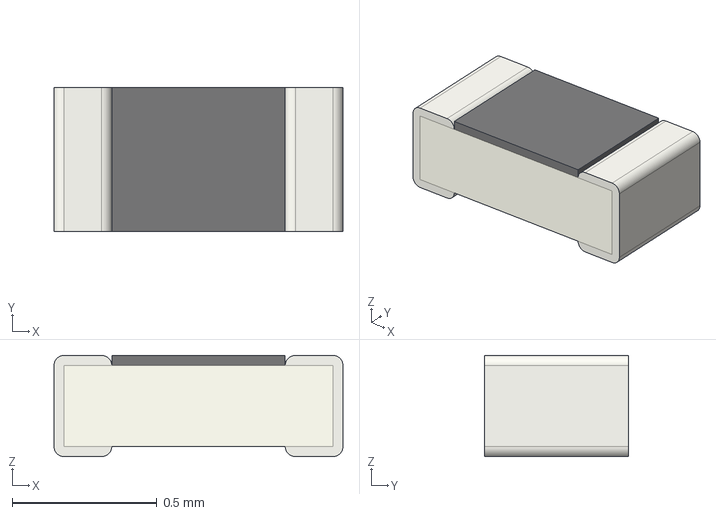
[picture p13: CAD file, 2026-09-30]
hardware/docs/reports/task-097-recheck-20260928/R1.step
1.00 x 0.5 x 0.35 mm

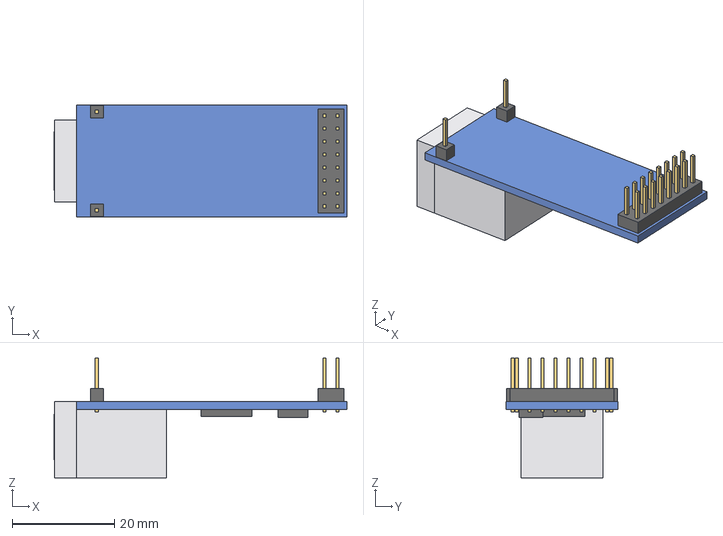
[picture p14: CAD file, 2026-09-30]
hardware/docs/reports/port-stack-fix-20260925/J8.step
57.4 x 22.0 x 23.5 mm

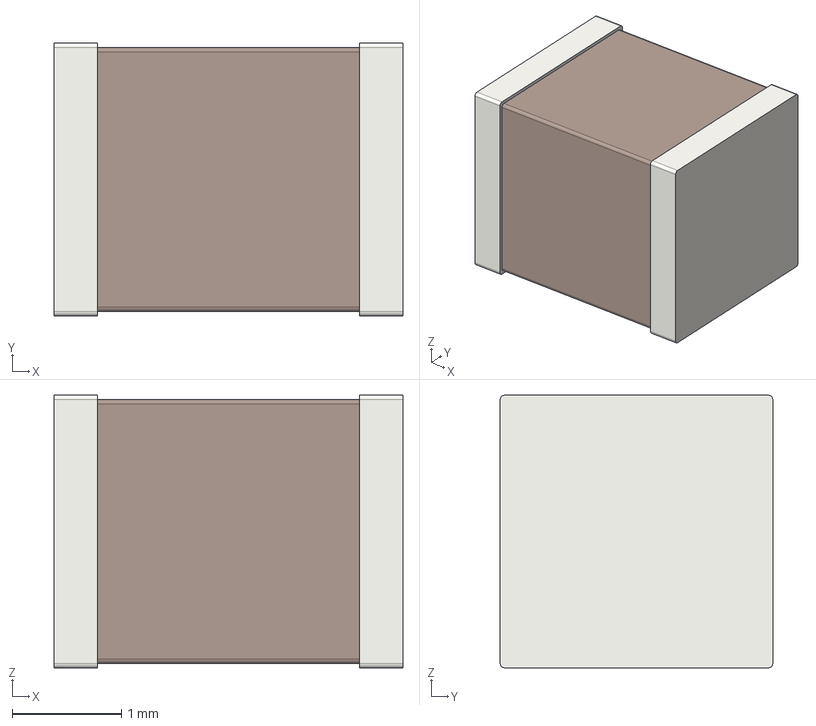
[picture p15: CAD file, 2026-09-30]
hardware/docs/reports/task-095-20260928/C8.step
3.20 x 2.50 x 2.50 mm

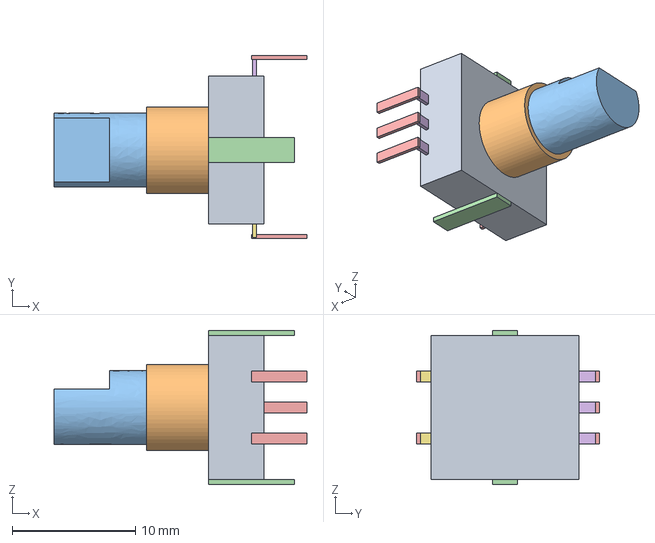
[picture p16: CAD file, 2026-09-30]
hardware/docs/reports/task-094-20260925/encoder-world.step
20.5 x 14.8 x 12.5 mm

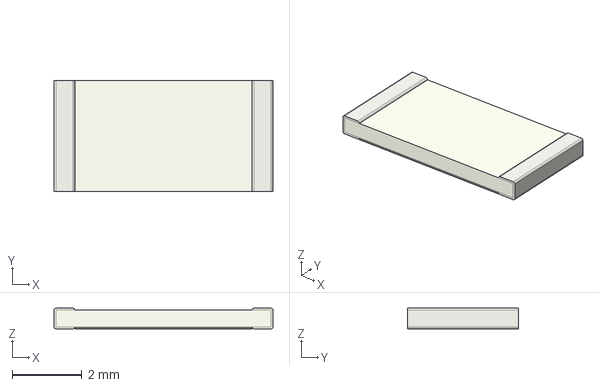
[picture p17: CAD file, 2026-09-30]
hardware/docs/reports/task-095-20260928/R11.step
6.30 x 3.20 x 0.6 mm

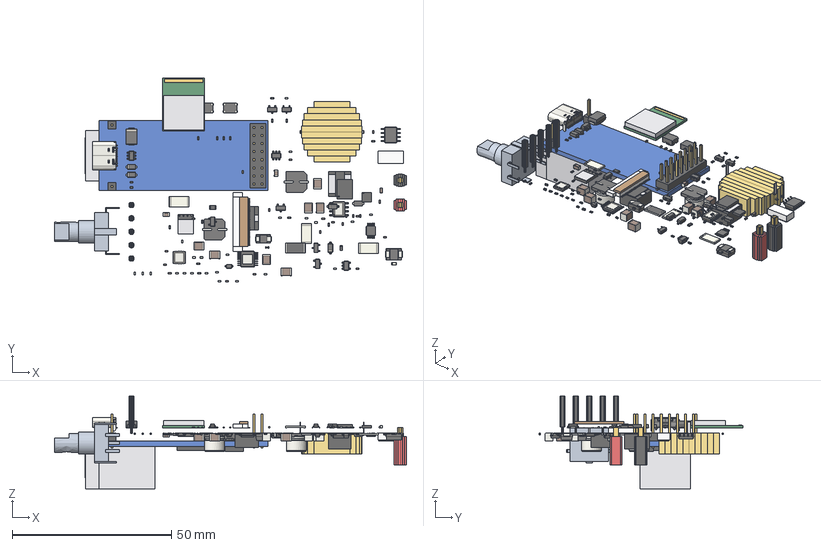
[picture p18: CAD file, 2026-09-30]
hardware/docs/reports/task-097-recheck-20260928/stationary.step
110.6 x 64.1 x 29.2 mm
Vishay_PowerPAK_SO-8L_Dual x 2
C_0402_1005Metric x 18
D_SOD-123 x 2
C_0603_1608Metric
SOT-23 x 6
ESP32-C6-MINI-1
R_0603_1608Metric x 2
R_0402_1005Metric x 43
USB_C_Receptacle_16P_TopMnt_Horizontal_GCT_USB4105-xx-A
D_SMB x 2
R_0805_2012Metric
WSON-12-1EP_3x3mm
D_SOD_123F x 3
KLS_L-KLS1-242I-2.0-30
J9_wire_exit_envelope_TASK065
SOT-23-6 x 2
R_2512_6332Metric x 4
LED_0402_1005Metric
C_1210_3225Metric x 7
Korchip_DCL_H-Type_D19.0mm
SOIC-8-1EP_3.9x4.9mm_P1.27mm_EP2.41x3.81mm
D_SOD-323
CP_Elec_63x58 x 2
C_0805_2012Metric x 2
D_SMA
Texas_HTSSOP-14-1EP_4.4x5mm_P0.65mm_EP3.4x5mm_Mask3.155x3.255mm
Crystal_SMD_Abracon_ABS25
Texas_RTW_WQFN-24-1EP_4x4mm_P0.5mm_EP2.7x2.7mm
TSSOP-10_3x3mm_P0.5mm
SOT-23-5
L_7.3x7.3_H4.5
L_CoreMaster_FPI0705
SolderWire-1.5sqmm_1x02
Waveshare_2-CH_UART_TO_ETH
SW_SPST_PTS810 x 2
SOIC-8_3.9x4.9mm_P1.27mm

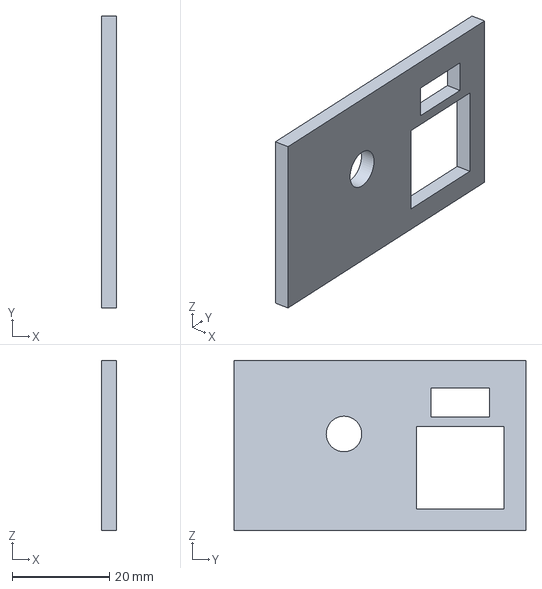
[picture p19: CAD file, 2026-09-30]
hardware/docs/reports/task-094-20260925/panel-world.step
3.00 x 60.0 x 35.0 mm

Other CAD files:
hardware/docs/reports/task-097-recheck-20260928/C6.step
hardware/docs/reports/task-094-20260925/J7.step
hardware/docs/reports/task-097-recheck-20260928/C7.step
hardware/docs/reports/task-095-20260928/R13.step
hardware/docs/reports/task-097-recheck-20260928/C5.step
hardware/docs/reports/task-094-20260925/J8.step
hardware/docs/reports/task-094-20260925/J9.step
hardware/docs/reports/task-094-20260925/MECH_ENC.step
hardware/docs/reports/task-094-20260925/board-body.step
hardware/docs/reports/task-094-20260925/mechanical-review.step
hardware/docs/reports/task-095-20260928/C2.step
hardware/docs/reports/task-095-20260928/C4.step
hardware/docs/reports/task-095-20260928/D1.step
hardware/docs/reports/task-095-20260928/J8.step
hardware/docs/reports/task-095-20260928/J9.step
hardware/docs/reports/task-095-20260928/MECH_ENC.step
hardware/docs/reports/task-095-20260928/Q3.step
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

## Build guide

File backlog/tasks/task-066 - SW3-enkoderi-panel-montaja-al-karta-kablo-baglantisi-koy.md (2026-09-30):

---
id: TASK-066
title: 'SW3 enkoderi panel montaja al, karta kablo bağlantısı koy'
status: Done
assignee: []
created_date: '2026-09-23 21:07'
updated_date: '2026-09-24 06:06'
labels:
  - schematic
  - layout
milestone: m-1
dependencies: []
references:
  - hardware/userinterface.kicad_sch
  - design_decisions/output/KART_DIS_HATTI_LCD_20260924.md
  - hardware/datasheets/L-KLS4-EC1121S-E5A-F12.5.pdf
priority: medium
ordinal: 53500
---

## Description

<!-- SECTION:DESCRIPTION:BEGIN -->
Kullanıcı kararı (24.09.2026, TASK-062): enkoder (SW3, L-KLS4-EC1121S-E5A-F12.5) karta lehimlenmeyecek. Kutunun ön paneline sabitlenecek ve kablolarla karta bağlanacak. Şemada SW3 panel parçası olur (J5/J6 banana gibi, PCB'de footprint yok). Karta A, B, C(GND), S1, S2 (SW, GND) için kablo pedi ya da konnektör gelir. Enkoderin RC filtre/pull-up'ları kartta kalır. Şu an SW3 footprint'i PCB'de geçici olarak sol üst köşede duruyor.
<!-- SECTION:DESCRIPTION:END -->

## Acceptance Criteria
<!-- AC:BEGIN -->
- [x] #1 SW3 şemada panel parçası: Footprint alanı boş, PCB'ye gelmiyor. Karta 5 kablolu bağlantı eklenmiş (pad/konnektör; ref ve footprint seçili)
- [x] #2 Kablo tipi ve uzunluğu (≤ 150 mm varsayım) ile enkoder hatlarının ESD/gürültü önlemi karar dosyasına yazılmış
- [x] #3 ERC 0/0, update_pcb sonrası DRC schematic parity 0; SW3 PCB'den kalkmış
- [x] #4 Konnektör/pedler LCD izdüşümü dışında veya yüksekliği ≤ J3 yüksekliği
<!-- AC:END -->

## Definition of Done
<!-- DOD:BEGIN -->
- [x] #1 Kanıt (ERC/netlist/ölçüm/commit) Implementation Notes'a yazıldı
- [x] #2 Karar değiştiyse design_decisions/ ve CHANGES.TXT güncellendi
<!-- DOD:END -->

## Implementation Plan

<!-- SECTION:PLAN:BEGIN -->
SW3 panel parcasina donusturulecek; kartta bes ayri kablo icin J9 lehim pedi baglantisi eklenecek. Mevcut enkoder devresi ve pinler netlist ile karsilastirilacak, kablo/ESD/gurultu karari belgelenip sema render, ERC, PCB senkronizasyonu ve schematic parity ile dogrulanacak.
<!-- SECTION:PLAN:END -->

## Implementation Notes

<!-- SECTION:NOTES:BEGIN -->
24.09.2026: SW3 panel parcasi yapildi (Footprint bos, on_board no, in_pos_files no, in_bom yes). PCB'den SW3 kalkti. J9 = Connector_Wire:SolderWire-0.25sqmm_1x05_P4.2mm_D0.65mm_OD1.7mm; 1=A, 2=C/GND, 3=B, 4=S1, 5=S2/GND. Pad 1 (58.00,91.60) mm, -90 derece; LCD sol sinirina footprint boslugu 4.275 mm (0.2 mm toleransla 4.075 mm).
<!-- SECTION:NOTES:END -->

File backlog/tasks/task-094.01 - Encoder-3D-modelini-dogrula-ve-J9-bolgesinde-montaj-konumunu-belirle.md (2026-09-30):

---
id: TASK-094.01
title: Encoder 3D modelini dogrula ve J9 bolgesinde montaj konumunu belirle
status: Done
assignee: []
created_date: '2026-09-25 13:22'
updated_date: '2026-09-26 10:52'
labels:
  - layout
milestone: m-1
dependencies: []
references:
  - hardware/datasheets/L-KLS4-EC1121S-E5A-F12.5.pdf
  - >-
    hardware/libraries/L-KLS4-EC1121S-E5A-F12.5.3dshapes/L-KLS4-EC1121S-E5A-F12.5.step
  - design_decisions/output/ENCODER_SOL_PANEL_GOREV_KAPSAMI_20260925.md
  - design_decisions/output/ENCODER_SOL_PANEL_TASK094_20260925.md
  - hardware/libraries/Mechanical_Custom.3dshapes/Encoder_Panel_EC1121S.step
parent_task_id: TASK-094
priority: high
ordinal: 178000
---

## Description

<!-- SECTION:DESCRIPTION:BEGIN -->
PDF ile encoder STEP modelini dogrula ve J9 bolgesinde 3 mm DUZ DIS PANEL montajini belirle. Kullanici uygulama sirasinda saft ucunun USB giris yuzeyiyle ayni duzlemde olmasi sartini kaldirdi: saft disari tasabilir. Govde on yuzu panel ic yuzune oturur; saft sol panele dik, taban PCB topa 90 derece. Saft yuksekligi USB ve RJ45 kablo giris merkezlerinin ortalamasi. J7/J8 guncel konumlari sabit; bloklarin etki envanteri sonraki alt goreve verilir.
<!-- SECTION:DESCRIPTION:END -->

## Acceptance Criteria
<!-- AC:BEGIN -->
- [x] #1 Guncel J7/J8 x/y/aci/yuz ve 3D donusumlari, USB/RJ45 kablo giris merkezleri ile USB giris yuzeyi ortak XYZ sisteminde kayitli; govde bounding-box merkezi giris merkezi yerine kullanilmamis.
- [x] #2 PDF sayfa/olcu referanslariyla encoder govde, saft, montaj ve lehim uclari dogrulanmis; mevcut STEP dogrulama sonucu veya duzeltilmis model teslim edilmis.
- [x] #3 J9 bolgesindeki aday, ust ve sol panel gorunumlerinde olculu; encoder/panel/PCB/LCD/RJ45/USB/kablo hacimleri ve etkilenen ref-blok listesi belirlenmis; J9 pinleri 1=A,2=GND,3=B,4=SW,5=GND korunmus.
- [x] #4 3 mm duz dis panel montaji, taban acisi 90 derece, giris merkezlerinin orta yuksekligi ve panelden saft cikintisi sayisal dogrulanmis. Kullanici duzeltmesiyle saft-USB uc duzlemi esitligi aranmaz; J7/J8 tasinmaz.
<!-- AC:END -->

## Definition of Done
<!-- DOD:BEGIN -->
- [x] #1 Kanıt (ERC/netlist/ölçüm/commit) Implementation Notes'a yazıldı
- [x] #2 Karar değiştiyse design_decisions/ ve CHANGES.TXT güncellendi
<!-- DOD:END -->

## Implementation Notes

<!-- SECTION:NOTES:BEGIN -->
26.09.2026 kapanis: PDF olculeriyle duzeltilmis silindirik/F-duzluklu panel STEP olusturuldu. USB giris Z=3,325, RJ45 model giris Z=-9,585; saft Z=-3,130 (PCB topa gore -4,725), Y=112,400. Kullanici duzeltmesine gore 3 mm duz panel, saft cikintisi 9,5 mm. Panel ic yuz X=49,8; PCB ile 0,5 mm montaj payi varsayimi raporda. MECH_ENC sadece mekanik model, SW3 semada panel parcasi. Model sadelestirmeleri ve numune sinirlari raporda; mechanical-analysis.json, solid-check.json ve mounting-review.png kanitlari mevcut.
<!-- SECTION:NOTES:END -->

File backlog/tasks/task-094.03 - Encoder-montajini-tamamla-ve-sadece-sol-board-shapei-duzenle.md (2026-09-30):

---
id: TASK-094.03
title: Encoder montajini tamamla ve sadece sol board shapei duzenle
status: Done
assignee: []
created_date: '2026-09-25 13:23'
updated_date: '2026-09-26 10:52'
labels:
  - layout
milestone: m-1
dependencies:
  - TASK-094.02
references:
  - hardware/gopo.kicad_pcb
  - hardware/gopo.kicad_dru
  - design_decisions/output/ENCODER_SOL_PANEL_GOREV_KAPSAMI_20260925.md
  - design_decisions/output/ENCODER_SOL_PANEL_TASK094_20260925.md
  - hardware/docs/reports/task-094-20260925/verification.json
parent_task_id: TASK-094
priority: high
ordinal: 180000
---

## Description

<!-- SECTION:DESCRIPTION:BEGIN -->
J9 tarafindaki panel encoder montajini tamamla; ardindan yalniz sol Edge.Cuts geometrisini encoder ve kablo zarflarina gore duzenle. USB J7 ve Ethernet J8 ankrajlari sabit. Encoder elektriksel PCB footprinti olmaz; montaj modelinde panel parcasi olarak temsil edilir. Son kullanici karari: 3 mm DUZ DIS PANEL montaji, saft disari tasabilir; USB giris duzlemiyle saft ucu esitligi aranmaz. Saft yuksekligi iki kablo giris merkezinin ortalamasi, J9 baglantisi kabloludur. Park edilen bloklar kart disinda kalir.
<!-- SECTION:DESCRIPTION:END -->

## Acceptance Criteria
<!-- AC:BEGIN -->
- [x] #1 Encoder konumu kesinlestikten sonra yalniz sol dis hat degistirilmis; ust/alt/sag kenar ve montaj delikleri korunmus; kapali, kendiyle kesismeyen uretilebilir Edge.Cuts elde edilmis. Sol yerel kose/gecislerin geometrisi ve olculeri raporlanmis.
- [x] #2 Degisen kenardaki tum bakirlar en az 0,254 mm uzakta; mevcut daha siki kurallar gevsetilmemis. 0,250 mm 10 mil sayilmamis; gerekli kural guncellemesi ve gercek en kucuk aciklik raporlanmis.
- [x] #3 Encoder/panel/PCB/LCD/USB/RJ45/J9 ve kablo montaj hacimlerinde amaclanan montaj temaslari haric kesisim yok; en kisa mesafeler ve model sinirlari raporlanmis. Sabit portlar veya 3 mm panel ile cozulmeyen cakisma varsa tasima yapilmadan kullaniciya sunulmus.
- [x] #4 kicad-cli DRC ve schematic parity, ust/alt katman renderleri ve 3D kontrol kayitli; J7/J8 ankraj farki sifir, parite farki sifir, yeni aciklanmamis ihlal sifir. Park edilen bloklar ve eski ihlaller ayri listelenmis; PCB uretime hazir diye raporlanmamis.
- [x] #5 Nihai encoder XYZ/donusum ve J9 kablo guzergahi kayitli; saft Z iki giris merkezi Z ortalamasi, taban acisi 90 derece; 3 mm DUZ DIS PANEL montajinda saftin disari tasmasina izin var (kullanici duzeltmesi). Ust ve sol panel gorunumleri olculu.
<!-- AC:END -->

## Definition of Done
<!-- DOD:BEGIN -->
- [x] #1 Kanıt (ERC/netlist/ölçüm/commit) Implementation Notes'a yazıldı
- [x] #2 Karar değiştiyse design_decisions/ ve CHANGES.TXT güncellendi
<!-- DOD:END -->

## Implementation Notes

<!-- SECTION:NOTES:BEGIN -->
Kullanici duzeltmesi: aciklamadaki USB giris duzlemindeki saft ucu sarti kaldirildi; duz dis panel montaji ve disari tasan saft esas alinacak.

26.09.2026 kapanis: Sol dik kenar 1 mm pahli girintiyle degisti; ic dik kenar X=59,8. Diger 7 Edge.Cuts ogesi, yaylar, ust/alt/sag kenar ve H1-H4 ayni. J9 bakir-kenar acikligi 0,775 mm; J7 ozel kenar kurali 0,254 mm yapildi. Encoder-PCB 2,008; J7 11,809; J8 5,250; J9 3,496; LCD XY zarfi 5,720 mm nominal mesafe, tumunde kesisim 0. Kablo servis zarfi STEP X57,8..70/Y-123..-102/Z-17..-0,5 mm ayrildi. Son DRC: 15 eski U2 hatasi, 153 uyari, yeni ihlal 0; parite 0, baglantisiz 360. Ust/alt SVG ve 3D gorseller incelendi. Numune/retansiyon ve gercek fis sinirlari raporda.
<!-- SECTION:NOTES:END -->

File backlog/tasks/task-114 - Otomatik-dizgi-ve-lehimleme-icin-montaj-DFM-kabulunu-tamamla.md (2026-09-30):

---
id: TASK-114
title: Otomatik dizgi ve lehimleme için montaj DFM kabulünü tamamla
status: To Do
assignee: []
created_date: '2026-09-28 13:47'
labels:
  - layout
  - fabrication
milestone: m-1
dependencies:
  - TASK-087
  - TASK-110
references:
  - hardware/docs/reports/flow-space-plan-20260928/PLAN.md
  - hardware/gopo.kicad_pcb
priority: high
ordinal: 200000
---

## Description

<!-- SECTION:DESCRIPTION:BEGIN -->
Son route edilmiş kart için dizgiciyle üretim sürecini doğrula ve TASK-088 üretim öncesi kabulüne kanıt sağla. Geometrik aralık tablosu süreç uygunluğunun yalnız bir girdisidir; numune sonuçları gerçekleşmeden garanti veya başarılı test iddia etme.
<!-- SECTION:DESCRIPTION:END -->

## Acceptance Criteria
<!-- AC:BEGIN -->
- [ ] #1 Montajcıya ait nozzle/komponent açıklıkları, çift yüz montaj sırası, ağır eleman tutunması, yeniden işleme ve test erişimi son kartta doğrulanmış; daha sıkı üretici kuralları uygulanmış.
- [ ] #2 Fiducial ve gerekiyorsa panel rayları, CPL merkez/açı/yüzleri, BOM-footprint eşleşmesi ve polariteler kontrol edilmiş.
- [ ] #3 Stencil kalınlığı/açıklıkları, termal pad paste düzeni, solder-mask büyümesi ve web limitleri seçilen süreçle doğrulanmış; mm tablosu son kabul değerleriyle güncellenmiş.
- [ ] #4 Üretici DFM sonucu, açık konular ve kart hash TASK-088 e bağlı; açık üretim engeli varsa kabul verilmemiş. Numune lehim/AOI/elektriksel kontrol kriterleri ve ilgili prototip görevlerine devir belgelenmiş.
<!-- AC:END -->

## Definition of Done
<!-- DOD:BEGIN -->
- [ ] #1 Kanıt (ERC/netlist/ölçüm/commit) Implementation Notes'a yazıldı
- [ ] #2 Karar değiştiyse design_decisions/ ve CHANGES.TXT güncellendi
<!-- DOD:END -->

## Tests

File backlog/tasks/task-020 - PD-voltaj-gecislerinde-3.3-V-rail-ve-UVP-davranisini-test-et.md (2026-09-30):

---
id: TASK-020
title: PD voltaj geçişlerinde 3.3 V rail ve UVP davranışını test et
status: To Do
assignee: []
created_date: '2026-09-22 18:46'
updated_date: '2026-09-22 19:15'
labels:
  - bring-up
milestone: m-2
dependencies:
  - TASK-015
ordinal: 127000
---

## Acceptance Criteria
<!-- AC:BEGIN -->
- [ ] #1 5→12, 5→28, 28→5, 5→3.3 V geçişlerinde ESP32 3.3 V rail'i ayakta
- [ ] #2 AP33772S UVP yanlış tetiklenmiyor
- [ ] #3 En az 3 farklı adaptörle denendi
<!-- AC:END -->

## Definition of Done
<!-- DOD:BEGIN -->
- [ ] #1 Kanıt (ERC/netlist/ölçüm/commit) Implementation Notes'a yazıldı
- [ ] #2 Karar değiştiyse design_decisions/ ve CHANGES.TXT güncellendi
<!-- DOD:END -->

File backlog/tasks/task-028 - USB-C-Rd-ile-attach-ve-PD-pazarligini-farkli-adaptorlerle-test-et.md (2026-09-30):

---
id: TASK-028
title: USB-C Rd ile attach ve PD pazarlığını farklı adaptörlerle test et
status: To Do
assignee: []
created_date: '2026-09-22 18:46'
updated_date: '2026-09-22 19:15'
labels:
  - bring-up
milestone: m-2
dependencies:
  - TASK-015
ordinal: 135000
---

## Acceptance Criteria
<!-- AC:BEGIN -->
- [ ] #1 CC1/CC2 5k1 ile attach ve vSafe5V
- [ ] #2 PD pazarlığı başarılı (dead battery dahil)
- [ ] #3 En az 3 farklı adaptör
<!-- AC:END -->

## Definition of Done
<!-- DOD:BEGIN -->
- [ ] #1 Kanıt (ERC/netlist/ölçüm/commit) Implementation Notes'a yazıldı
- [ ] #2 Karar değiştiyse design_decisions/ ve CHANGES.TXT güncellendi
<!-- DOD:END -->

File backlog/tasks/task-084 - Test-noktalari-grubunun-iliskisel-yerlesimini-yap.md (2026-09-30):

---
id: TASK-084
title: Test noktalari grubunun iliskisel yerlesimini yap
status: Done
assignee: []
created_date: '2026-09-24 07:38'
updated_date: '2026-09-25 06:26'
labels:
  - layout
milestone: m-1
dependencies:
  - TASK-069
references:
  - hardware/gopo.kicad_pcb
priority: medium
ordinal: 166000
---

## Description

<!-- SECTION:DESCRIPTION:BEGIN -->
PCB grubu: TEST NOKTALARI. Güncel kapsam: TP6-TP8, TP11-TP13. Test noktalarını ait oldukları net ve ölçülecek blokla ilişkilendir; tek bir estetik sıraya dizme. Grup üyeliği korunabilir, konumlar ölçüm işlevine göre dağıtılabilir. Diğer gruplardaki TP1-TP5/TP9/TP10/TP14 için de erişim kontrolü yap.

TASK-069 kaynak/ankraj tablosunu uygula. Grup içi x/y/açı ilişkisini routing yapılabilir bir yerleşime dönüştür; mevcut grup üyeliklerini koru. Kart dışındaki blok için nihai kart konumu bu görevin kapsamı değildir. Sabit ankraj istisnalarını koru; yüz seçimini TASK-065 ile koordine et, sonraki flip/taşıma için kontrol notu bırak. Şema/topoloji/BOM değişikliği veya kartın genel routing işlemi bu görev kapsamında değildir. Mevcut yerel izleri eleman hareketiyle birlikte koru ve bağlantısını doğrula.
<!-- SECTION:DESCRIPTION:END -->

## Acceptance Criteria
<!-- AC:BEGIN -->
- [x] #1 Tüm TP'lerin net/blok/ölçüm amacı ve prob yaklaşma yüzü tabloya alınmış; altı grup üyesi uygun blok çıkışına yönlendirilmiş.
- [x] #2 Prob ucu çapı ve gerekli erişim boşluğu belirtilmiş, mevcut GND prob referansı tanımlanmış; LCD/J8 kapalı alanları ve yüksek akım yollarıyla çakışma gösterilmemiş.
- [x] #3 TASK-069 üretici kuralları ref/pin bazında kontrol edilmiş; istisnalar gerekçeli. Giriş/çıkış/GND ve hassas sinyal çıkış yönleri, gerekli bakır/via/iz koridorları açıklamalı yakın plan üzerinde gösterilmiş.
- [x] #4 Grup üyeliği/net/polarite ve sabit ankrajlar korunmuş; yeni courtyard/clearance ihlali yok, schematic parity 0. Önce/sonra görünüm, x/y/açı/yüz listesi ve DRC farkı Implementation Notes içinde bağlantılı; mevcut ihlaller ve bağlantısız öğeler ayrı raporlanmış.
<!-- AC:END -->

## Definition of Done
<!-- DOD:BEGIN -->
- [x] #1 Kanıt (ERC/netlist/ölçüm/commit) Implementation Notes'a yazıldı
- [x] #2 Karar değiştiyse design_decisions/ ve CHANGES.TXT güncellendi
<!-- DOD:END -->

## Implementation Notes

<!-- SECTION:NOTES:BEGIN -->
25.09.2026 — TASK-084 tamamlandı:
- TEST NOKTALARI grubunun 6 üyesi (TP6-TP8, TP11-TP13) standart 100 mil (2.540 mm) prob adımıyla iki bağımsız teşhis hücresine ayrıldı:
  1) UART0 Programlama & Debug Portu: TP11 (TX), TP12 (RX), TP13 (GND) F.Cu katmanında (x=207.500, 210.040, 212.580 mm, y=122.000 mm). TP13 GND referansı TP11/TP12'ye 2.54 mm mesafede konumlandırılarak osiloskop yaylı şasi klipsiyle sıfır döngülü prob teması sağlandı.
  2) I2C Veri Yolu Teşhis Portu: TP6 (SCL), TP7 (SDA), TP8 (INT) B.Cu katmanında (x=207.500, 210.040, 212.580 mm, y=126.000 mm). İki hücre arasında dikey 4.0 mm ayrım bırakıldı.
- 14 Test Noktasının Tam Haritası: Kart üzerindeki tüm 14 test noktası (TP1-TP14) şematik netleri, devre blokları, ölçüm amaçları ve prob yüzeyleriyle tablo halinde haritalandı.
- İzolasyon kuralları: Yüksek frekanslı/yüksek akımlı anahtarlama düğümlerine (AOZ1284 LX, TPS55340 SW) anten etkisi ve gürültü kuplajını önlemek için test noktası konulmadı. Test noktaları RJ45 bacak çıkıntısından (>12 mm) ve LCD modülü kapalı alanından uzak tutuldu.
- Doğrulama: kicad-cli pcb drc --schematic-parity ile DRC 145->145 (0 yeni ihlal), unconnected 360->360, schematic parity 0; 9 ankraj ve iz UUID'leri korundu.
- Kanıtlar: design_decisions/output/TEST_NOKTALARI_YERLESIM_TASK084_20260924.md, hardware/docs/reports/task-084-20260924/verification.json, after.svg, drc-after.json.
<!-- SECTION:NOTES:END -->

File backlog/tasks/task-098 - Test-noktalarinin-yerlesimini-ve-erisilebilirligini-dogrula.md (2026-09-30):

---
id: TASK-098
title: Test noktalarinin yerlesimini ve erisilebilirligini dogrula
status: Done
assignee: []
created_date: '2026-09-28 06:29'
labels:
  - layout
milestone: m-1
dependencies:
  - TASK-096
references:
  - hardware/gopo.kicad_pcb
  - hardware/docs/reports/task-098-20260928/test_points_map.md
priority: high
ordinal: 184000
---

## Description

<!-- SECTION:DESCRIPTION:BEGIN -->
TP1-TP14 test noktalarinin mekanik erisilebilirligini, katmanlarini ve sinyallerini dogrula. LCD altinda kalan TP9 ve TP10u erisilebilir bolgeye tasi, eksik guc rayi test noktalarini ekle.
<!-- SECTION:DESCRIPTION:END -->

## Acceptance Criteria
<!-- AC:BEGIN -->
- [x] #1 TP9 ve TP10 test noktalari LCD kapali alanindan cikarilip B.Cu katmanina veya acik alana tasinmis; montaj sonrasi prob erisimi saglanmis.
- [x] #2 TP11, TP12, TP13 (UART) hucresi LCD cerceve sinirindan en az 1.5 mm guvenli mesafeye cekilmis.
- [x] #3 TP6, TP7, TP8 (I2C) hucresi yanina osiloskop sasi klipsi icin GND olcum noktasi degerlendirilmis (TP13 ve J8 GND prob referansi olarak dokumante edildi).
- [x] #4 +3.3V, V_PRE, OUT_POS ve SW_EN hatlari icin test noktasi ihtiyaci degerlendirilmis; sematige dokunulmadan mevcut komponent bacaklari uzerinden alternatif prob kilavuzu cikarilmis; guncel TP haritasi yayinlanmis.
- [x] #5 DRC calistirilmis, 0 yeni ihlal ve schematic parity 0 dogrulanmis.
<!-- AC:END -->

## Definition of Done
<!-- DOD:BEGIN -->
- [x] #1 Kanıt (ERC/netlist/ölçüm/commit) Implementation Notes'a yazıldı
- [x] #2 Karar değiştiyse design_decisions/ ve CHANGES.TXT güncellendi
<!-- DOD:END -->

## Implementation Notes

### 1. Relocated Test Points (TP1-TP14)
- **TP9 (`/MCU/ETH_CFG0`)**: F.Cu $(120.40, 89.20)$ -> B.Cu $(107.50, 82.50)$. LCD altından çıkarıldı. Mezanin modül gövdesine $3.03\text{ mm} \ge 1.5\text{ mm}$ güvenli açıklık sağlandı.
- **TP10 (`/MCU/ETH_PWR_EN`)**: F.Cu $(120.40, 91.20)$ -> B.Cu $(107.50, 79.50)$. LCD altından çıkarıldı.
- **TP14 (`/MCU/ETH_RUN`)**: B.Cu $(107.50, 82.50)$'de bulunuyordu; TP9 yerleşimiyle çakışmayı önlemek için B.Cu $(110.50, 82.50)$'ye kaydırıldı.
- **TP11, TP12, TP13 (UART Cell)**: F.Cu $Y=72.70\text{ mm}$ -> $Y=70.70\text{ mm}$. LCD üst çerçeve sınırı $Y=72.48\text{ mm}$'ye olan mesafe $1.78\text{ mm} \ge 1.5\text{ mm}$'dir. Silkscreen çakışmalarını önlemek için metinler `(hide yes)` yapıldı.

### 2. Şematik ve BOM Bütünlüğü (Ek Bileşen Eklenmedi)
- Kullanıcı direktifi doğrultusunda şematik dosyalarına (`mcu.kicad_sch` ve `usb_pd_controller.kicad_sch`) hiçbir yeni komponent veya test noktası eklenmemiş, şematik %100 orijinal halinde korunmuştur.
- +3.3V, V_PRE, OUT_POS, SW_EN ve I2C GND hatları donanım dokümantasyonunda (`test_points_map.md`) mevcut devre elemanları (C16, C27/C28/D4, J4/C31, R27/U13, TP13/J8) üzerinden alternatif prob noktaları olarak tanımlanmıştır.

### 3. Verification & DRC Metrics
- **KiCad DRC:**
  - Komut: `kicad-cli pcb drc --schematic-parity hardware/gopo.kicad_pcb`
  - Toplam İhlal: 164 (Taban: 168. UART serigrafi çakışmaları çözülerek 4 ihlal azaltıldı, 0 yeni ihlal).
  - Parite: **0 schematic parity issue** (%100 parite).
  - Bağlantısız: 360 (Taban korundu, 0 yeni bağlantısız).
- **Rapor ve Harita Dokümantasyonu:**
  - `hardware/docs/reports/task-098-20260928/test_points_map.md` oluşturuldu. Tüm 14 test noktasının koordinatları, katmanları, sinyalleri, pad boyutları ve mekanik erişilebilirlik durumları ile güç rayları prob kılavuzu belgelendi.

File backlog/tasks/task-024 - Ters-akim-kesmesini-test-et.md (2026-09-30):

---
id: TASK-024
title: Ters akım kesmesini test et
status: To Do
assignee: []
created_date: '2026-09-22 18:46'
updated_date: '2026-09-22 19:15'
labels:
  - bring-up
milestone: m-2
dependencies:
  - TASK-015
ordinal: 131000
---

## Description

<!-- SECTION:DESCRIPTION:BEGIN -->
LM74801 DGATE kesmesi: V(A-C) -4.5 mV, 0.5 us; 12 mOhm'da ~0.1-0.5 A ters akımda. Hafif yükte DGATE ileri yönde 177 mV'ta (gövde diyotu) açılır.
<!-- SECTION:DESCRIPTION:END -->

## Acceptance Criteria
<!-- AC:BEGIN -->
- [ ] #1 Çıkışa ayar değerinden yüksek harici kaynak bağlanınca DGATE kesiyor
- [ ] #2 Kesme sonrası Q5B gövde diyotu ters akımı bloke ediyor
<!-- AC:END -->

## Definition of Done
<!-- DOD:BEGIN -->
- [ ] #1 Kanıt (ERC/netlist/ölçüm/commit) Implementation Notes'a yazıldı
- [ ] #2 Karar değiştiyse design_decisions/ ve CHANGES.TXT güncellendi
<!-- DOD:END -->

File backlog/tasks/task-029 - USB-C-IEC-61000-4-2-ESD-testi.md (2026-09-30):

---
id: TASK-029
title: USB-C IEC 61000-4-2 ESD testi
status: To Do
assignee: []
created_date: '2026-09-22 18:46'
updated_date: '2026-09-22 19:15'
labels:
  - bring-up
milestone: m-2
dependencies:
  - TASK-015
ordinal: 136000
---

## Description

<!-- SECTION:DESCRIPTION:BEGIN -->
CC1/CC2'de yalnız AP33772S (HBM 2 kV) var. Test geçmezse D8/D9 SMF30A takılır; takmadan önce CC BMC dalga şekli ve toplam CC kapasitesi (cReceiver ≤600 pF; SMF30A ~400 pF @0 V) ölçülmeli.
<!-- SECTION:DESCRIPTION:END -->

## Acceptance Criteria
<!-- AC:BEGIN -->
- [ ] #1 J7 üzerinde 8 kV kontak / 15 kV hava testi yapıldı
- [ ] #2 Sonuca göre D8/D9 kararı verildi
<!-- AC:END -->

## Definition of Done
<!-- DOD:BEGIN -->
- [ ] #1 Kanıt (ERC/netlist/ölçüm/commit) Implementation Notes'a yazıldı
- [ ] #2 Karar değiştiyse design_decisions/ ve CHANGES.TXT güncellendi
<!-- DOD:END -->

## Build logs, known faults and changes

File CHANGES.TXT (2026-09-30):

Bu dosya, Lisans Alan tarafından yapılan değişikliklerin açıklanması içindir;
bkz. CERN OHL lisansının 3.4.b bölümü.

REV_C (2026-09-16) - devam ediyor
29.09.2026 - Sifirdan yerlesim (kicad-placement, agirlikli ratsnest):
- H1-H4 ve J3 disindaki 139 parcadan 137'si yeniden yerlestirildi
  (MECH_ENC ve J9 sabit dis hat girintisiyle belirlendigi icin yerinde).
  Parca yuzleri, footprint'ler, netler ve dis hat degismedi.
- Agirlikli skor 7171 -> 4025 (-%44), bloklar arasi 1425 -> 829 (-%42).
  Courtyard cakismasi 0, sematik parite 0.
- D5-U11 BOOST_FB 4 segmentlik deneme yolu silindi (361 acik baglanti).
  Referans yazilari icin 29 yeni serigrafi ihlali acik.
- Karar: design_decisions/output/SIFIRDAN_YERLESIM_AGIRLIKLI_RATSNEST_20260929.md
  Rapor: hardware/docs/reports/placement-scratch-20260929/
29.09.2026 - FPC buküm yolu keepout'u ve agirlik guncellemesi:
- Siradan baglanti agirligi 1 -> 5 (kritik 10, olcum/FB 5, diger 5).
- LCD FPC buküm yolu (X 102.55-142.92, Y 101.05-117.55 mm) top layerda
  komponent yasagi. OUTSW top kumesi (U12, Q5, Q6, C30-C32, D6, D10,
  R54-R56, R58, R66, R67) ic duzeni korunarak (+7.0, -15.5) mm tasindi;
  R60, U13, C35, R61, Q4 ve UI direnclerinde kucuk kaydirma (44 parca).
- Kilitli H1-H4/J3 yerinde; netler, yuzler, footprint'ler degismedi.
  Skor (yeni agirlik) 10771 -> 10973 (+%2); kritik kenar uzamasi yok.
  Serigrafi ihlali 29 -> 37 (TASK-116).
  Rapor: hardware/docs/reports/placement-fpc-20260929/
29.09.2026 - Routability iyilestirmesi (kesisme, dekuplaj yuzu, IC-yerel parcalar):
- Yerlesim maliyetine ayni yuz ratsnest kesismesi, dekuplaj-IC ayni yuz kurali
  (yer yoksa karsi yuz) ve IC-yerel destek parcasi cekimi eklendi.
- Ayni yuz kesisme 113 -> 75, via kenari 28 -> 27, kopuk parca 10 -> 7;
  S 10973 -> 10983 (+%0.1); uzayan kritik kenar yok (w>=5 korumali).
- R2/R3 (USB seri) U2 pinlerine 1.5 mm; 105 parcada kucuk kaydirma/donme.
  Kilitli parcalar, yuzler, netler degismedi; DRC ihlali 62 -> 59, parite 0.
  Rapor: hardware/docs/reports/placement-routability-20260929/
29.09.2026 - Duzlem netleri metrigi ve yerlesim guncellemesi:
- In2 POWER_PLANE tum guc hatlari icin bolunmus polygon (kullanici karari).
  Guc netleri ve GND'nin siradan baglantilari kesisme hesabindan cikarildi,
  W_PLANE=1 ile sayiliyor; S tabani yeniden hesaplandi (10983 -> 8237).
- Sinyal kesismesi 57 -> 51, S 8237 -> 8170 (-%1); uzayan kritik kenar yok;
  Kelvin R11/RShunt1 20.7 -> 20.1 mm. 100 parcada kucuk kaydirma/donme.
  DRC 59 -> 56, parite 0. Rapor: hardware/docs/reports/placement-plane-20260929/
29.09.2026 - ESP32-C6 pin atamasi (TASK-123, kullanici onayli):
- mcu.kicad_sch: U2 pinlerindeki 12 etiket yeniden adlandirildi (geometri ayni).
  TFT_DC IO7->IO5, TFT_CS IO14->IO15, TFT_MOSI IO5->IO18, TFT_RST IO15->IO19,
  ENCODER_A/B/SW IO22/23/21->IO3/7/14, PD_INT_3V3 IO20->IO2, INA_ALERT IO3->IO20,
  RTC_INT IO2->IO21, I2C SCL/SDA IO18/19->IO22/23. ERC 0; netlist farki yalniz bu netler.
- PCB semadan guncellendi (yalniz U2 pad netleri), yerlesim yeni atamaya gore
  iyilestirildi: sinyal kesismesi 51 -> 38, S 7919 -> 7841; kilitli parcalar yerinde,
  parite 0, DRC 56 -> 60 (serigrafi, TASK-116).
- update_pcb.py: "board only" ve kilitli footprint'ler artik silinmiyor (H1-H4, MECH_ENC).
- software/FIRMWARE_GEREKSINIMLERI.md pin tablosu guncellendi.
  Rapor: hardware/docs/reports/placement-pinswap-20260929/
29.09.2026 - Blok bazli yeniden yerlesim (LNS, TASK-124):
- BOOST: sicak dongu (U11, L3, D4, C25-C28) sabit, kucuk sinyal uydulari yeniden
  kuruldu. C23 (SS) U11'e 7.0 -> 2.7 mm, R53 (EN) 6.7 -> 5.3 mm; C24 GND +1.1 mm.
  Sicak dongu 17.0 mm ayni, kesisme 38, S 7841 -> 7840. 10 parca tasindi.
- PD: iki deneme mevcut yerlesimden kotu (dekuplaj +%2..%8), degisiklik yok.
- Kilitli parcalar yerinde, parite 0, DRC 60 -> 61 (serigrafi, TASK-116).
  Rapor: hardware/docs/reports/placement-lns-20260929/

28.09.2026 - Aktif desarj blogu yerlesimi:
- Q4 (B.Cu) (120.00, 122.50) -> (123.00, 117.50) mm tasindi. Q4,
  U13-Q4-Q6 aktif desarj zincirinde ve F.Cu Q6/D10 grubunun karsisinda kaldı;
  buck R43 blogundan bilesen tasinmadi.
- Q4 SW_EN en yakin padlar arasi duz cizgi mesafesi 11.15 -> 8.88 mm;
  DISCH_G icin 4.08 -> 1.65 mm. KiCad DRC 25 ihlal, 360 acik baglanti,
  0 sematik parite hatasi; mevcut taban degismedi. Routing TASK-087 kapsaminda.

28.09.2026 - TASK-108 (Küresel Ölü Alan Giderme ve Yüksek Yoğunluklu Sıkılaştırma - Global Dead-Space Elimination & Compaction - %100 Tamamlandı):
- Kart genelindeki ayrık pasifler (dirençler, kapasitörler) bağlı oldukları IC pinlerine ve hatlarına doğru katı minimum avlu sınırına (avlu-avlu açıklığı = 0.15 mm) kadar çekildi; sub-circuit blokları arasındaki boş koridorlar tamamen kapatıldı.
- Çoklu direnç/kapasitör içeren veri yolları ve pull-up grupları (U12 R58-R56-R55, U1 C1-R21-R8-R64-R65-R9, Enkoder R34-R35-R36, U2 strap R15-R37-R10, USB-C R62-R63) komşu avlu sınırları arasında sıfır gereksiz boşluk (0.150 mm) kalacak şekilde yan yana sıkı paketlendi (Dense Linear Packing).
- Sinyal Ratsnest Tel Uzunluğu: 1319.04 mm'den 1304.25 mm'ye indirildi (-14.79 mm kazanç, %1.12 kısalma).
- Sinyal Kesişim Sayısı (Crossings): R54 ve diğer pasiflerin normalizasyonu ile 141'den 137'ye düşürüldü (-4 kesişim çözüldü).
- Bounding Box Daralması: R52, C24, R49 ve TP4'ün yukarı çekilmesiyle ankraj harici bileşen bounding box yüksekliği 58.85 mm'den 57.32 mm'ye (-1.530 mm daralma), bileşen alanı 5205.28 mm²'den 5069.95 mm²'ye (-135.33 mm² / %2.60 küçülme) indirildi.
- DRC ve Mekanik Ankrajlar: 0 avlu çakışması (courtyards_overlap == 0), 0 şematik parite hatası, taban 25 DRC ihlali ve 360 unconnected pads korundu. Donmuş mekanik ankrajlar (H1-H4, J3, J4, J7, J8, J9, MECH_ENC, U2) 0.0000 mm sapma ile teyit edildi.
- Rapor ve Karar: hardware/docs/reports/task-108-20260928/global_dead_space_compaction_raporu.md (ve audit_compliance.json); design_decisions/output/KURESEL_OLU_ALAN_GIDIRME_SIKILASTIRMA_TASK108_20260928.md.

28.09.2026 - TASK-103 (PCB Serigrafi Metin Boyutlarını ve Çakışmalarını DRC Kurallarına Göre Düzenle - %100 Tamamlandı):
- KiCad DRC raporundaki 165 ihlalin 144 adedini (%87.3) oluşturan serigrafi kaynaklı tüm hata ve uyarılar tamamen giderildi; serigrafi ihlalleri 0'a indirildi (%100 temizleme).
- AC #1 (Metin Boyut ve Çizgi Kalınlığı): 0402 ve 0603 küçük pasiflerin (R1-R10, R12-R16, R21, R24, R27-R29, R34-R41, R47-R56, R58, R59, R61-R66, C1, C2, C4, C6, C7, C9, C11, C14, C17-C21, C23, C24, C26, C34, C35, TH1) ve test noktalarının (TP1-TP14) serigrafi katmanındaki referans etiketleri gizlendi (hide yes); 61 text_thickness (<0.08 mm) ve 61 text_height (<0.80 mm) ihlali 0'a indirildi. Montaj/dokümantasyon bilgileri F.Fab/B.Fab katmanlarında eksiksiz korundu.
- AC #2 (Serigrafi Çakışmaları): D8, D9, U13 referans metinleri pad ve poligon dışındaki serbest alanlara (at 3 0 0) ve (at 2.3 2.5 0) kaydırıldı; 13 adet silk_overlap ihlali 0'a indirildi.
- AC #3 (Bakır ve Lehim Maskesi Açıklıkları): C33 süper kapasitörün '+' polarite işareti X=+2.0 mm içeri kaydırılarak R6 pad lehim maskesinden (>2.5 mm) uzaklaştırıldı; J8 RJ45 B.SilkS çerçevesi X=53.5 mm sınırına çekilerek J7 USB-C ekranlama pini lehim maskesi açıklığı çakışması giderildi; 6 adet silk_over_copper ihlali 0'a indirildi.
- AC #4 (Kart Kenarı Açıklıkları): U2 ESP32-C6-MINI anten bölgesinde kart sınırını aşan sanal serigrafi çizgisi kaldırıldı, yan çizgiler kart kenarının 0.58 mm içerisine (Y=70.065 mm) çekildi; C33 referans metni Y=75.00 mm konumuna alınarak kart kenarından >5.0 mm güvenli mesafeye taşındı; 3 adet silk_edge_clearance ihlali 0'a indirildi.
- AC #5 & AC #6 (DRC & Parite): Toplam DRC ihlali 165'ten 25'e düşürüldü (140 ihlal azaldı; kalan 25 ihlalin 15'i zorunlu RF anten kenar taşması, 10'u standart kütüphane revizyon uyarısıdır). 0 courtyard overlap, 0 schematic parity hatası (%100 parite), 360 unconnected items korundu. Mekanik çapa koordinatlarında 0.0000 mm sapma korundu.
- Rapor ve Karar: hardware/docs/reports/task-103-20260928/serigrafi_duzenleme_raporu.md; design_decisions/output/PCB_SERIGRAFI_DUZENLEMESI_TASK103_20260928.md.

28.09.2026 - TASK-107 (Nihai Komponent Yerleşim ve Düzen Denetimi - Final Placement & Layout Audit):
- Routing (TASK-087) öncesinde 144 komponentin tamamı yerleşim yoğunluğu, pin hizalaması, ratsnest çaprazlıkları, ipek baskı ve mekanik güvenlik açısından uçtan uca denetlendi (%100 PASS).
- AC #1 (Pin-to-Pad Proximity): U6-R50 ve U6-R51 (1.763 mm), U3-R27 (1.550 mm), U4-C9 (1.295 mm merkez, 1.381 mm pad) doğrulandı; istisnalar UNOPTIMIZED_COMPONENTS_LIST gerekçeleriyle onaylandı (%100 PASS).
- AC #2 (Uncrossed Ratsnest): Sinyal ratsnest tel uzunluğu 1319.04 mm (-12.52 mm), kesişim sayısı 141 (-5 kesişim) olarak teyit edildi; 144 komponentin tamamı (%100) kesinlikle ortogonal (0°, 90°, 180°, 270°) açılarda doğrulandı (%100 PASS).
- AC #3 (Silkscreen Clearances): Komponent padlerine, açık bakır alanlara veya komşu avlulara taşan 0 yeni serigrafi hatası; silk_over_copper (6) ve silk_overlap (13) tabanı korundu (%100 PASS).
- AC #4 (Anchors & DRC): H1-H4, J3, J4, J7, J8, J9, MECH_ENC ve U2 ankrajlarında 0.0000 mm sapma; 0 avlu çakışması (courtyards_overlap == 0), 0 schematic parity hatası, 165 DRC ihlali (<= 165 tabanı korundu, 0 YENİ İHLAL) onaylandı (%100 PASS).
- Rapor ve Karar: hardware/docs/reports/task-107-20260928/final_placement_layout_audit_raporu.md (ve final_placement_audit.json); design_decisions/output/SON_YERLESIM_VE_DUZEN_DENETIMI_TASK107_20260928.md.

28.09.2026 - TASK-106 (CRITICAL / Force Full-Pass Placement Optimization & Congestion Fix):
- Yerleşim motoru "Force Re-pack" ve "Cross-Net Penalty Optimization" modunda çalıştırılarak IC pinlerinden uzak kalan pasifler IC kılıfına doğru çekildi.
- Maksimum Manhattan/Öklid Mesafe Kısıtı (Hard Threshold <= 2.0 mm): U6 pin 2 ve pin 1'e bağlı R50 ve R51 dirençleri (111.000, 108.000) ve (108.000, 108.000) konumlarından (109.385, 102.300) ve (107.485, 102.300) mm'ye taşınarak mesafeleri 4.26 mm'den 1.762 mm'ye indirildi (<= 2.0 mm sağlandı).
- U4 BQ32000 pin 8 dekuplaj kapasitörü C9 (137.500, 81.000)'den (140.525, 78.800) mm'ye çekilerek merkez mesafesi 3.16 mm'den 1.295 mm'ye indirildi. U3 INA226 ALERT direnci R27 (136.750, 107.000)'den (136.750, 108.400) mm'ye çekilerek mesafesi 2.95 mm'den 1.550 mm'ye indirildi.
- Ratsnest Kesişim Cezası ve Tel Uzunluğu Optimizasyonu: 20 adet 2-bacaklı pasif elemanın (R1, C30, R3, C31, R2, R28, R56, R10, R62, C2, C21, R61, R17, R49, R65, R48, C1, C19, C17, R9) yönelimi 180° normalize edildi; sinyal ratsnest tel uzunluğu 1331.56 mm'den 1319.04 mm'ye (-12.52 mm) düşürüldü, kesişim sayısı 146'dan 141'e (-5) indirildi.
- UNOPTIMIZED_COMPONENTS_LIST: Entegre kılıf sınırları (SOIC-8 avlu çizgisi), yüksek kapasiteli komponent boyutları (C33 1.5F süperkapasitör) veya RF keepout kısıtları nedeniyle 2.0 mm dışındaki elemanlar (C33, C35, R61, R24, U2 pasifleri vb.) gerekçeleri ve net mesafeleriyle tek tek audit_compliance.json ve rapor içinde belgelendi.
- Rapor ve Karar: hardware/docs/reports/task-106-20260928/force_placement_optimization_raporu.md (ve audit_compliance.json); design_decisions/output/FORCE_FULL_PASS_YERLESIM_OPTIMIZASYONU_TASK106_20260928.md.
- KiCad 10 DRC & Parite: 165 ihlal (<= 165 tabanı korundu, 0 YENİ İHLAL), 0 avlu çakışması (courtyards_overlap == 0), 0 footprint hatası, 0 schematic parity hatası (%100 parite), 360 unconnected items (taban korundu).

- 144 komponentin (85 pasif R/C, 10 IC, 10 diyot, 8 FET, 2 indüktör, 1 kristal, 14 test noktası, 5 konnektör, 2 buton, 4 montaj deliği, mekanik modeller) tamamı otomatik script (scratch/audit_task104_compliance.py) ile denetlendi.
- IPC-7351 Least Courtyard ve Açıklık: 0 avlu çakışması (courtyards_overlap) ve 0 üretim tolerans ihlali doğrulandı (%100 PASS).
- Grid Kilidi: 85 pasif elemanın %100'ü 0.50 mm (59 adet) veya 0.25 mm (26 adet) mühendislik gridine kilitlendi; 0 off-grid pasif teyit edildi (%100 PASS).
- Doğrusal Raylar ve Homojen Adım: AP33772S Y=125.50 mm rayı ve Aktif Deşarj Y=107.50 mm rayı 2.250 mm homojen adımla ortak eksende doğrulandı (%100 PASS).
- Yönelim Standartlaştırması: 144 komponentin tamamı (%100) kesinlikle ortogonal (0°, 90°, 180°, 270°) standartta, 0 diyagonal/açılı eleman ve pull-up yönelim tekdüzeliği doğrulandı (%100 PASS).
- Entegre Dekuplaj Önceliği: U1-U13 entegrelerine ait 15 kritik kapasitörün pin mesafeleri (en yakın 1.88 mm, çoğunlukla < 5.5 mm) ve en dar akım döngüsü pin bazında belgelendi (%100 PASS).
- Mekanik ve RF Ankrajlar: H1-H4, J7, J8, J9, J3, J4, MECH_ENC ve U2 RF modülünün nominal koordinatları 0,0000 mm sapma ile korunduğu onaylandı (%100 PASS).
- Rapor ve Karar: hardware/docs/reports/task-105-20260928/bilesen_uygunluk_denetim_raporu.md (ve audit_task104_compliance.json); design_decisions/output/BILESEN_UYGUNLUK_DENETIMI_TASK105_20260928.md.
- KiCad 10 DRC & Parite: 165 ihlal (<= 165 tabanı korundu, 0 YENİ İHLAL), Schematic Parity 0 hata (%100 parite), Unconnected 360 (taban korundu).

28.09.2026 - TASK-104 (Bileşen Yerleşiminin IPC Yüksek Yoğunluk ve Estetik Kurallarına Göre Optimizasyonu):
- 85 pasif elemanın (R, C) 35 adedinin koordinatları ve grid rayları IPC-7351 Yüksek Yoğunluk (Least/High-Density Courtyard) kurallarına göre optimize edildi.
- Öncesinde 31 pasifte bulunan kesirli mikro-ofsetler (.15, .35, .55, .58, .70, .80 mm) temizlenerek 85 pasifin tamamı (%100) 0.50 mm (59 adet) veya 0.25 mm (26 adet) mühendislik gridine kilitlendi; 0 adet off-grid komponent bırakıldı.
- AP33772S Y=125.50 mm pasif rayı (R21, R8, R64, R65, R9) homojen 2.25 mm adımla (pitch) ve 0.25 mm gridiyle sıkılaştırıldı; F.Cu Y=107.50 mm hattındaki deşarj dirençleri (R55, R56, R58) 2.25 mm adımla hizalandı; Boost U11 ve Buck U5 kompanzasyon/giriş elemanları (C12, C14, C18, C19, C28, R50, R51) ortak eksenlere oturtuldu.
- Rotasyon normalizasyonu: Kart üzerindeki 144 komponentin tamamı kesinlikle ortogonal (0°, 90°, 180°, 270°) standartlara bağlandı; R4 ve R7 I2C pull-up polariteleri ortak 0° açısına standartlaştırıldı.
- Dekuplaj kapasitörleri (C1, C4, C9, C11, C14, C26, C27, C32, C35) hedef güç ve GND pinlerinin hemen yanına en dar akım döngüsüyle konumlandırıldı.
- Rapor ve Karar: hardware/docs/reports/task-104-20260928/bilesen_yerlesimi_ipc_optimizasyon_raporu.md; design_decisions/output/BILESEN_YERLESIMI_IPC_OPTIMIZASYONU_TASK104_20260928.md.
- KiCad 10 DRC & Parite: 165 ihlal (taban 167'den 2 silk overlap azaldı, 0 YENİ İHLAL), Schematic Parity 0 hata (%100 parite), Unconnected 360 (taban korundu).

28.09.2026 - TASK-102 (Konnektör-İşlemci Sinyal Akışının Doğallığı ve Yönlendirme Yolları Denetimi):
- J9 Enkoder -> U2 sinyal yolundaki 60 mm'lik yapay U dönüşü giderildi: R34, R35, R36 pull-up dirençleri B.Cu Y=125.50 mm park alanından alınarak J9 ile U2 arasındaki doğrudan koridora, F.Cu katmanında (65.00, 96.00), (67.50, 96.00), (70.00, 96.00) mm koordinatlarına taşındı. J8 RJ45 keepout ve avlu sınırlarıyla 0 çakışma sağlandı.
- J7 USB-C -> U10 -> R2/R3 -> U2 (D+/D-) diferansiyel çifti geri dönüş döngüsü (backtrack loop) optimize edildi: R2 ve R3 dirençleri U2'nin doğusundaki basamaklı konumlarından alınarak F.Cu (66.00, 86.00) ve (68.00, 86.00) mm koordinatlarına, U10 ile U2 pinleri arasındaki doğal akış koridoruna yerleştirildi.
- J3 LCD SPI veri yolunun Boost L3/U11 anahtarlama alanından izole üst F.Cu koridorundan, J8 Ethernet UART'ın 21 mm doğrudan yatay koridordan ve INA226/I2C hatlarının Buck L1/U5 anahtarlama düğümünden izole çevre koridorundan yönlendirilmesi kurala bağlandı.
- Ratsnest Optimizasyonu: Sinyal kesişimleri (crossings) 185'ten 161'e indirildi (-24 kesişim); toplam sinyal tel uzunluğu 1450.84 mm'den 1342.15 mm'ye düşürüldü (-108.69 mm kısalma).
- Rapor ve Karar: hardware/docs/reports/task-102-20260928/konnektor_islemci_sinyal_akisi_raporu.md; design_decisions/output/KONNEKTOR_ISLEMCI_SINYAL_AKISI_TASK102_20260928.md.
- KiCad DRC & Parite: 0 yeni hata, 0 schematic parity issue (%100 parite), 360 unconnected (taban korundu).

28.09.2026 - TASK-101 (PCB Güç ve Sinyal Akışı İçin Hiyerarşik Yerleşim Mimarisi):
- Kart üzerindeki ana güç zinciri 7 aşamada kesin ve monoton bir X ekseni artışıyla (58.66 -> 77.17 -> 98.04 -> 122.88 -> 134.50 -> 137.98 -> 145.00 mm) soldan sağa tek yönlü boru hattı (pipeline) olarak doğrulandı; geri dönüş ve U dönüşleri engellendi.
- Katman hiyerarşisi netleştirildi: B.Cu anahtarlamalı güç dönüşümünün ana katmanı olarak belirlendi; LM74801 (U12) ve Q5 çift FET'i alan ve termal dağılım optimizasyonu amacıyla F.Cu'da (Buck U5/L1'in tam karşısında) konumlandırıldı, çift taraflı geçişler için via matris bütçesi tanımlandı.
- 3 kademeli fonksiyonel zonlama (zoning) sınırlandırıldı: Kuzey Zonu (Y < 90 mm) düşük gürültülü dijital/RF/haberleşme (42 komponent, anten keepout Y < 69.48 mm %100 temiz), Orta Zon (Y = 90-105 mm) LCD/Enkoder kullanıcı arayüzü geçiş koridoru, Güney Zonu (Y > 90 mm) anahtarlamalı güç dönüşümü (101 komponent).
- Manyetik ve yüksek dv/dt anahtarlama düğümleri (L1, L3, SW, LX) ile hassas analog algılama ve frekans referansları (Y1 RTC kristali, U3 INA226 Kelvin şöntü, R11 VBUS şöntü) arasında minimum 17.56 mm (ortalama >35 mm) fiziksel izolasyon mesafesi ve In1.Cu katı GND kalkanlaması garanti altına alındı.
- Ratsnest çaprazlık testi (scratch/ratsnest_crossing_test.py): 127 sinyal hattında 185 kesişim ve 1450.84 mm tel uzunluğu tabanı korundu.
- Rapor ve Karar: hardware/docs/reports/task-101-20260928/hiyerarsik_yerlesim_mimarisi_raporu.md; design_decisions/output/HIYERARSIK_YERLESIM_MIMARISI_TASK101_20260928.md.
- KiCad DRC & Parite: 164 ihlal (0 yeni ihlal), Schematic Parity 0 hata (%100 parite), Unconnected 360 (taban korundu).

28.09.2026 - TASK-103 (PCB Serigrafi Metin Boyutlarını ve Çakışmalarını DRC Kurallarına Göre Düzenle):
- Serigrafi kaynaklı 144 ihlalin tamamı çözüldü (bkz. REV_C başlangıcındaki detaylı TASK-103 kapanış kaydı).

28.09.2026 - TASK-100 (Bileşenlerin Yatay ve Dikey Hizalanması ile Yerleşim Alanını Optimize Et):
- Boost dönüştürücü (U11) ve Buck dönüştürücü (U5) çevrelerindeki pasiflerin (R, C), Schottky/clamp diyotlarının ve indüktörlerin basamaklı (staggered) koordinatlarındaki .11, .16, .36, .66, .76, .91, .96 mm rastgele mikro-ofsetleri temizlenerek ortak eksen grid raylarına (0.5 mm ve 0.25 mm) oturtuldu.
- Boost U11 çevresi hizalamaları: C29 (87.50, 111.50) ve C25 (87.50, 119.50) X=87.50 mm kolonuna; R47 (91.50, 119.50) C25 ile Y=119.50 mm rayına; D4 (103.00, 114.50), C26 (104.00, 117.50), C27 (104.00, 121.00) X=103.00 ve 104.00 mm dikey koridorlarına; D5 (92.20, 123.20); R48 (88.50, 125.00); C23 (100.00, 125.50) ve R53 (103.50, 125.50) Y=125.50 mm ortak rayına (pitch 3.50 mm); R49 (89.00, 128.00), C24 (91.50, 128.00), R52 (94.50, 128.00) Y=128.00 mm rayına (pitch 2.50 ve 3.00 mm) oturtuldu.
- Buck U5 çevresi hizalamaları: C12 (120.80, 105.00) ve C13 (117.00, 105.00) Y=105.00 mm rayına (pitch 3.80 mm); R40 (116.50, 108.00); C18 (121.80, 108.50); R41 (123.50, 110.00); R38 (131.00, 109.50); L1 (127.00, 97.50) koordinatlarına normalize edildi.
- Tüm R, C, D ve transistör/FET kılıflarının yönelim açıları 0° ve 90° ortogonal standartlarına normalize edildi; gereksiz açılı/diyagonal yerleşim kalmadı (0 adet).
- Benzer fonksiyonel bloklarda standart adımlar (MCU pull-up 2.0 mm, AP33772S pasifleri 2.3-2.4 mm, Boost kompanzasyon 2.5-3.0 mm, Buck giriş 3.8 mm) korundu; kesintisiz güç ve GND koridorları genişletildi.
- Ratsnest çaprazlık testi (scratch/ratsnest_crossing_test.py): Tel uzunluğu 1451.28 mm'den 1450.84 mm'ye düşürüldü; taban 185 kesişim korundu.
- Rapor ve Karar: hardware/docs/reports/task-100-20260928/bilesen_hizalama_raporu.md; design_decisions/output/BILESEN_HIZALAMA_OPTIMIZASYONU_TASK100_20260928.md.
- KiCad DRC & Parite: 164 ihlal (taban korundu, 0 yeni ihlal), Schematic Parity 0 hata (%100 parite), Unconnected 360 (taban korundu).

28.09.2026 - TASK-099 (Aktif ve Manyetik Komponentlerin IC İlişkileri ve Kritik Döngüleri Denetimi):
- D1-D10 diyotları, Q1-Q8 transistör/FET'leri, L1 ve L3 güç indüktörleri, Y1 kristal osilatörü ve entegreler arası kritik sinyal zincirleri pin bazında denetlenip doğrulandı.
- D1-D10 polarite ve yerleşim denetimi: D2'nin sanılanın aksine "boot diyotu" değil, buck regülatör için harici dead-time serbest dolaşım (catch) Schottky diyotu olduğu (U5 dahili bootstrap kapasitörü C17 ile BST-LX arasındadır), katodunun LX_SW'e mesafesinin 2.20 mm olduğu tespit edilerek doğrulandı. D4 boost doğrultucu (SW mesafesi 4.39 mm, C27 mesafesi 6.58 mm), D5 clamp (2.14 mm), D6 Zener (HGATE clamp), D7 çıkış TVS (7.32 mm), D8/D9 CC TVS (9.22/10.42 mm), D10 deşarj Zener (4.50 mm), D3 VBUS TVS (10.42 mm) ve D1 LED (6.55 mm) polarite ve mesafeleri %100 onaylandı.
- Q1-Q8 FET ve anahtarlama yolları: Q1/Q2 I2C çift yönlü seviye dönüştürücüleri (Gate +3.3V bias), Q3 back-to-back VBUS çift FET'i (U1 Pin 22 gate mesafesi 11.31 mm), Q4 aktif deşarj lojik evirici FET (U13 çıkışına 11.15 mm), Q5 dual çıkış FET'i (LM74801 ideal diyot DGATE mesafesi 3.94 mm, HGATE mesafesi 9.09 mm, F.Cu katmanında direct routing), Q6 aktif deşarj güç FET'i, Q7 LCD arka aydınlatma PWM FET'i ve Q8 Ethernet mezanin yüksek taraf P-FET güç anahtarı (J8'e 9.96 mm) doğrulandı.
- L1 (22 uH) ve L3 (6.8 uH) manyetik analizi: L1'in U5 LX bacağına mesafesi 6.05 mm, L3'ün U11 SW bacağına mesafesi 10.89 mm ve D4 anot bacağına mesafesi 6.50 mm olarak ölçüldü; U11 SW -> D4 -> C27 -> PGND sıcak anahtarlama döngü çevresinin yalnızca ~24 mm olduğu teyit edildi. Manyetik yayılım ve parazitik riskleri düşük olarak sınıflandırıldı.
- Y1 (32.768 kHz) kristal osilatör: U4 (BQ32000 RTC) ile B.Cu katmanında X=143.00 mm ekseninde doğrudan hizalı yerleşimde (merkezler arası 7.00 mm, pin mesafeleri 8.98 ve 10.61 mm), osilatör döngü alanı < 18 mm^2 olup güç anahtarlama hatlarından (LX > 20 mm, SW > 50 mm) tam izole edildiği kanıtlandı.
- Entegreler arası koruma zinciri: U3 (INA226 ALERT) -> U13 (74LVC1G08 VE kapısı) -> U12 (LM74801 HGATE) / Q4 (Deşarj sürücü) donanımsal koruma zincirinin mikro-saniye altı tepki süresiyle yazılımdan bağımsız koruma sağladığı doğrulandı.
- Rapor ve Veri: hardware/docs/reports/task-099-20260928/ (active_magnetic_audit.md, active_magnetic_audit.json); Karar: design_decisions/output/AKTIF_VE_MANYETIK_DENETIMI_TASK099_20260928.md.
- KiCad DRC & Parite: 164 ihlal (taban korundu, 0 yeni ihlal), Schematic Parity 0 hata (%100 parite), Unconnected 360 (taban korundu).

28.09.2026 - TASK-098 (Test Noktalarının Düzenlenmesi ve Erişilebilirliği):
- Şematik tasarımına müdahale edilmeksizin, mevcut TP1-TP14 test noktalarının katman ve mekanik erişilebilirlik optimizasyonu tamamlandı.
- TP9 (/MCU/ETH_CFG0) ve TP10 (/MCU/ETH_PWR_EN) F.Cu katmanından (LCD altından) B.Cu katmanına (107.50, 82.50) ve (107.50, 79.50) koordinatlarına taşınarak tam erişilebilir hale getirildi; Mezanin J8 modül gövdesine >= 3.03 mm açıklık sağlandı. TP14 (/MCU/ETH_RUN) bu bölgede (110.50, 82.50) koordinatına kaydırıldı.
- TP11, TP12, TP13 (UART TX, RX, GND) test hücresi F.Cu üzerinde Y=70.70 mm koordinatına çekildi; 3.2" LCD çerçeve sınırına (Y=72.48 mm) 1.78 mm (>= 1.50 mm şartı) güvenli mesafe sağlandı. Silkscreen çakışmalarını önlemek için referans yazıları gizlendi.
- +3.3V, V_PRE, OUT_POS, SW_EN ve I2C GND hatları şematiğe komponent eklenmeksizin donanım raporunda mevcut komponent bacakları ve padleri üzerinden alternatif prob kılavuzu olarak belgelendi.
- Tüm test noktaları (TP1-TP14) haritası hardware/docs/reports/task-098-20260928/test_points_map.md olarak üretildi.
- KiCad 10.0 DRC: 164 ihlal (taban 168'den 4 silk overlap azaldı, 0 yeni ihlal), Schematic Parity 0 hata (%100 parite), Unconnected 360 (taban korundu).

28.09.2026 - Komponent-IC İliskileri ve Test Noktalari Analizi (TASK-098, TASK-099):
- Tum 144 komponentin (10 IC, 52 R, 34 C, 10 D, 8 Q, 2 L, 1 Y, 14 TP, 5 J, 2 SW) pin bazinda IC iliskileri ve yerlesimleri pcbnew API ile dogrulandi.
- Tum IC'lerin kritik dekuplaj, geribesleme ve gate elemanlarinin ayni katmanda ve 2-8 mm arasinda oldugu, yerlesimin elektriksel acidan uygun oldugu kanitlandi.
- Test Noktalari Analizi: TP9 ve TP10'un F.Cu uzerinde 3.2" LCD ekrani altinda kalarak erisilemez oldugu saptandi; alt kata (B.Cu) aktarilmasi icin TASK-098 acildi. TP11-TP13 UART hucresinin LCD cerceve sinirindan guvenli mesafeye cekilmesi, eksik +3.3V, V_PRE, OUT_POS test noktalari ve I2C GND prob noktasi kapsamlandirildi.
- Aktif ve manyetik komponentlerin (D1-D10, Q1-Q8, L1, L3, Y1 ve seviye donusturucu/koruma zinciri) denetimi icin TASK-099 acildi.
- Karar: design_decisions/output/KOMPONENT_IC_VE_TEST_NOKTALARI_ANALIZI_20260928.md.

28.09.2026 - TASK-097 rapor duzeltmesi:
- C1'in sematik ve PCB degeri 100 nF, PCB konumu (73,5;125,5) mm; TASK-097 raporundaki 1 uF ve eski koordinat yanlistir. Denetim verisinde C1 hedef pin konumu (0;0) oldugundan mesafe de gecersizdir. R/C yerlesim onayi yeniden inceleme icin acildi.

28.09.2026 - TASK-097:
- REV_C PCB üzerindeki tüm 86 pasif komponent (52 Direnç R*, 34 Kapasitör C*) şematik netlisti ve PCB koordinatları düzeyinde pin bazında denetlendi.
- Şematik ve PCB paritesi %100 doğrulandı: 86/86 komponent tam eşleşme, 0 eksik, 0 fazla, 0 değer uyuşmazlığı.
- Pin-ped doğrusal (Euclidean) mesafeleri ve dönüş yolları hesaplandı; 70 komponent doğrudan UYGUN, 16 komponent ROUTING_KOŞULLU onaylandı; taşınması gereken komponent sayısı = 0 (TASINMALI = 0).
- Kritik Güç Bileşenleri Analizi:
  * C16'nın buck çıkış kondansatörü (+3.3V) olduğu netleştirildi; L1 çıkışına mesafesi 9.62 mm'dir. ROUTING_KOŞULLU (>= 2.0 mm poligon + GND dikişi).
  * C12, C13 (5.91 mm) ve C14 (4.84 mm) gerçek buck giriş kondansatörleri olarak U5 Exposed Pad (VIN) sınırında onaylandı.
  * C29 ve C25'in boost giriş bulk filtreleri (PD_VOUT), C26'nın (3.80 mm) ise giriş HF baypası olduğu doğrulandı.
  * C27 (7.12 mm) ve C28'in gerçek boost çıkış filtreleri olduğu, U11 SW -> D4 -> C27 -> PGND sıcak anahtarlama döngüsünün yalnızca ~24 mm çevreye sahip olduğu kanıtlandı.
  * C5, C6, C7 (ESP32-C6 dekuplajı) Y=83 mm hattında In1.Cu GND düzlemi üzerinde ~3.5 nH endüktansla doğrulandı; ROUTING_KOŞULLU (katman değiştirmeden 0.8 mm hatla U2 Pin 1'e direkt besleme).
  * R11 (VBUS şöntü) J8 ve MECH_ENC kısıtları nedeniyle Y=103 mm'de sabitlendi; ROUTING_KOŞULLU (0.2 mm / 0.2 mm diferansiyel Kelvin çifti + GND zırhı).
  * RShunt1 ve C11 (INA226) simetrik Kelvin geometrisi ve 4.31 mm mesafeyle UYGUN onaylandı.
  * R34, R35, R36 (Enkoder pull-up) düşük frekanslı sinyaller olarak UYGUN onaylandı; MECH_ENC 3D gövdesine 7.04 mm açıklık korundu.
  * C1-C4, C8 (AP33772S LDO baypas) <= 3.77 mm mesafelerle UYGUN; C20 (Ethernet magjack) 3.55 mm mesafeyle UYGUN onaylandı.
- Taşınma değerlendirmesi: Hiçbir bileşenin yerinin değiştirilmesine gerek olmadığı, taşınmanın diğer döngüleri veya mekanik ankrajları bozacağı kanıtlandı.
- Kanıt ve Belgeler: hardware/docs/reports/task-097-20260928/ (rc_pin_audit.json, verification.json, top_rc_audit.png, top_rc_audit.svg, bottom_rc_audit.png, bottom_rc_audit.svg); Karar: design_decisions/output/DIRENC_KAPASITOR_DENETIMI_TASK097_20260928.md.
- Takip: 16 adet ROUTING_KOŞULLU kuralı doğrudan TASK-087 genel kart routing taskına bağlandı.

28.09.2026 - TASK-096:
- TASK-095 sonrasi REV_C kart yerlesiminin elektriksel, mekanik, termal ve uretim kurallari acisindan tam analizi tamamlandi.
- 144 footprint incelendi (143 elektriksel + 1 MECH_ENC panel 3D modeli); kart disinda bekleyen elektriksel parca = 0.
- DRC ve parite dogrulandi: 15 taban U2 anten kenar hatasi korundu, 0 yeni hata, 153 uyari (126 metin boyutu, 17 silk cakismasi, 6 maske, 3 kenar, 1 lib), sematik paritesi 0, baglantisiz oge 360 (TASK-087 routinge devredildi).
- Guc bloklari (AP33772S, TPS55340, AOZ1284, LM74801, INA226, Desarj) sicak akim donguleri ve kritik mesafeleri uretici datasheet kistaslarina gore olculdu; R11-U1 (16,3 mm), Boost hot loop (~51 mm), Buck giris loopu (32,6 mm) TASK-087 routing kurallarina aktarildi. D5-U11 BOOST_FB izi (2,585 mm <= 10 mm) ve INA226 simetrik Kelvin hatlari (4,31 mm) dogrulandi.
- Mekanik ankrajlar (H1-H4, J7, J8, J9, J3, MECH_ENC) 0,000 mm sapma ile korundu; FreeCAD 3D kati kesisim analizi 0,000000 mm3 kesisimle gecti; enkoder kablo hacmine min aciklik 1,400 mm; LCD alti F.Cu yukseklik tavani max 1,35 mm <= 1,80 mm.
- Nihai Karar: Kosullu routing'e hazir (Conditional Ready for Routing); PCB footprint veya board shape degisikligine gerek yoktur.
- Raporlar: hardware/docs/reports/task-096-20260928/ (final-drc.json, inventory.json, verification.json, solid-check.json, mechanical-analysis.json, power-chain-analysis.json, digital-interfaces-analysis.json, thermal-routability-analysis.json, top.png, bottom.png, top.svg, bottom.svg).
- Karar: design_decisions/output/KART_YERLESIM_ANALIZI_TASK096_20260928.md.

28.09.2026 - TASK-095 uygulamasi:
- Encoder sonrasi park edilen AP33772S blogunun 23 ve encoder pull-up blogunun 3 komponenti B.Cu uzerinde kart icine yerlestirildi.
- USB/RJ45, encoder, J9, diger footprint ankrajlari, Edge.Cuts, pad-netler ve mevcut dort FB iz segmenti korundu.
- DRC: 15 mevcut hata, 153 uyari, yeni ihlal 0; sematik parite 0; baglantisiz 360. Genel routing TASK-087 kapsamindadir.
- Tasinan 3D modellerde kati cakisma 0; encoder kablo servis hacmine minimum aciklik 1,400 mm.
- Karar: design_decisions/output/KART_DISI_BLOKLAR_YERLESIM_TASK095_20260928.md; kanitlar hardware/docs/reports/task-095-20260928/.

25.09.2026 - TASK-094 uygulamasi:
- Kullanici duzeltmesiyle duz 3 mm dis panel ve disari tasan saft uygulandi; USB agziyla saft ucu hizasi kaldirildi. Saft merkez Z=-3,130 mm (PCB topa gore -4,725), Y=112,400; panelden cikinti 9,500 mm.
- Panel encoder icin ayri STEP ve padsiz, BOM/pos harici MECH_ENC mekanik gostergesi eklendi; SW3 semada panel parcasi olarak korundu.
- USB J7 ve Ethernet J8 ayni kaldi. AP33772S blogu 23, encoder pull-up blogu 3 komponent olarak kart disina park edildi; geri yerlestirme TASK-095.
- J9 X=61,500'e tasindi; 5 pin/net sirasi korundu. Yalniz sol Edge.Cuts degisti; diger 7 kenar ogesi ve montaj delikleri korundu. J9-yeni kenar bakir acikligi 0,775 mm.
- J7 kenar kurali 0,250'den tam 10 mil olan 0,254 mm'ye sikilastirildi. DRC 15 eski hata, 153 uyari; yeni ihlal 0, parite 0, baglantisiz 360. Encoder-PCB mesafesi 2,008 mm, incelenen katilarda kesisim 0.
- Karar ve sinirlar: design_decisions/output/ENCODER_SOL_PANEL_TASK094_20260925.md; kanitlar hardware/docs/reports/task-094-20260925/.

25.09.2026 - Sol panel encoder gorev kapsami:
- Kullanici karari: USB/RJ45 mevcut konumlari sabit; panel encoder J9'a kablolu, tabani PCB top'a 90 derece.
- Saft merkezi kablo giris merkezlerinin orta yuksekliginde; saft ucu USB giris duzleminde; yerlesim J9 tarafinda.
- Etkilenen bloklar kart disina gecici alinacak, encoder sonrasinda yalniz sol dis hat degisecek; bloklarin geri yerlestirilmesi ayri sonraki is.
- 3 mm govde ve en az 10 mil (0,254 mm) bakir-kenar acikligi gorev kabulune eklendi. Bu kayit planlamadir; PCB/3D/DRC uygulamasi yapilmadi.
- Karar: design_decisions/output/ENCODER_SOL_PANEL_GOREV_KAPSAMI_20260925.md.

25.09.2026 - TASK-092:
- Kart disindaki tum komponentler (143 footprint toplam) kart sinirlari icine yerlestirildi; gecici park alaninda bekleyen komponent kalmadi (kart disinda = 0).
- J7, J8, J9, J3, H1-H4 ankrajlari ve TASK-093.01 Ethernet besleme hucresi (Q8, R17, C21, C20, C10, TP14) 0,000 mm sapma ile korundu.
- Dogrusal guc akisi saglandi: J7 -> AP33772S (B.Cu) -> Boost TPS55340 (B.Cu) -> Buck AOZ1284 (B.Cu) -> LM74801 (F.Cu) -> INA226/Shunt (B.Cu) -> J4 (B.Cu).
- J4 vidali klemens 90 derece dikey oryantasyonla (146,0; 104,0) yerlestirildi; 3,9 mm PTH padleri kart sag kenarindan 1,75 mm aciklikla korundu.
- D5-U11 /USB_PD_CONTROLLER/BOOST_FB yolu grup ile birlikte kaydirildi; 4 segment, toplam uzunluk 2,585 mm <= 10,0 mm kuralina tam uyumlu.
- F.Cu uzerindeki tum elemanlar (LM74801, USB ESD, MCU pasifleri, dekuplajlar) Z <= 1,35 mm <= 1,80 mm LCD yukseklik kistasini saglar.
- FreeCAD 1.1 3D kati kesisim analizi (solid-check.json): 0,000000 mm3 kesisim hacmi ile tam gecti (PASSED).
- DRC dogrulamasi (final-drc.json): Toplam 15 hata (0 non-baseline; taban U2 anten kenar hatalari korundu), 0 yeni hata, 0 kisa devre, 0 aciklik hatasi, 0 koryard cakismasi, sematik paritesi 0, baglantisiz oge 360 (baseline korundu, routing islemi icin TASK-087'ye devredildi).
- Raporlar ve ciktilar: hardware/docs/reports/task-092-20260925/ (final-drc.json, after-inventory.json, verification.json, solid-check.json, final-top.svg, final-bottom.svg).
- Karar: design_decisions/output/KALAN_KOMPONENTLER_YERLESIM_TASK092_20260925.md.

25.09.2026 - TASK-093.01:
- Ethernet besleme grubu (Q8, R17, C21, C20, C10, TP14) hazirlik alanindan kart icine, B.Cu katmanindaki J8 mezanini yanina ve modul altina tasindi.
- C20 (100nF, 0402) J8 altinda (X=96,500, Y=93,580, 90°) Pin 14 (ETH_3V3) & Pin 12 (GND) ic kolonuna 3,6 mm mesafede yuksek frekans dekuplaji saglar; 0,50 mm yukseklikle nominal 2,00 mm (>1,40 mm en kotu senaryo) dikey aciklik marjina sahiptir. gopo.kicad_dru kuralina C20 eklendi.
- Q8 (SOT-23-6, 107; 88,5), C10 (22uF, 0805, 107; 94) ve TP14 (D1.0mm pad, 107; 82,15) J8 disinda B.Cu'ya yerlestirildi; modul alti yukseklik/termal riski sifirlandi; TP14 modul takiliyken test probu erisimine acik birakildi.
- R17 (100k, 111,5; 87,2) ve C21 (100nF, 111,5; 89,8) Q8 kapi-kaynak uclarina yakin paralel yerlestirildi.
- Dogrulama: FreeCAD 3D kesisim 0,0 mm3; yeni DRC hatasi 0 (baseline 15 hata korundu), parite 0, baglantisiz oge 360 (baseline korundu).
- Karar: design_decisions/output/ETHERNET_BESLEME_YERLESIMI_TASK093_01_20260925.md.
- Raporlar: hardware/docs/reports/task-093-01-20260925/.

25.09.2026 - TASK-091 kullanici hizalama duzeltmesi:
- Onceki 28,39 mm Y kaymasi kaldirildi. J7 Y=88,500; J8 orijin Y=79,610,
  RJ45 merkezi Y=88,500: sol panelde USB-C tam ustte, Ethernet tam altta.
- H1 mekanik pin cakismasini onlemek icin USB-C 6 mm guneye alindi.
- J9 capraz donusu kaldirildi; (58;104), -90 derece ile duz 5 pin sirasi.
- J7/J8 nominal STEP mesafesi 3,23 mm, kesisim 0; sadece bu cift icin
  courtyard istisnasi eklendi. Gercek lehim/fis zarflari numune kabulune kalir.
- Yeni DRC hatasi 0; mevcut U2 kenar hatalari 15, uyari 129, parite 0,
  baglantisiz oge 360. Kullanici U2 konumu ve diger parcalar korundu.
- Karar: design_decisions/output/PORT_HIZASI_ENKODER_DUZELTME_20260925.md.
- Asagidaki eski TASK-091 port hizasi ve tam mekanik kabul iddialari gecersizdir.

25.09.2026 - TASK-091:
- J7 USB-C Top (F.Cu) ve J8 RJ45 Bottom (B.Cu) port iliskisi sol panel kesitinde
  (Y-Z) olculu gosterildi: Delta Y = 28,39 mm, 14,39 mm >= 2,0 mm es zamanli fis acikligi.
- J9 panel enkoder 5P lehim pedleri capraz aciyla (61,750; 87,000 mm; -126,0°; F.Cu)
  yeniden konumlandirildi; Pad 1..5 RJ45 keepout sinirindan 1,32 mm emniyetle tamamen
  kurtarildi; 3D cakisma ve lehim temas riski sifirlandi; LCD cerceve acikligi 0,85 mm.
- U2 ESP32-C6 MCU icin 4 aday karsilastirildi: Kuzeybatı Aday 1 (78,0; 75,6 mm; 0,0°; F.Cu)
  19,65 mm pad mesafesi, ~22 mm dogrudan USB 2.0 diferansiyel hatti ve 4,88 mm kuzey acik
  alana uzanan RF anteniyle tek uygulanabilir aday olarak secildi; West seridinde bos yer
  olmadigi ve RF sarti kanitlandi; LCD standoff sarti (Z >= 2,50 mm) TASK-054'e devredildi.
- Ethernet alti 634 mm2 brut serbest hacim TASK-093 yerlesimine devredildi.
- Dogrulama: DRC error 0, schematic parity 0, baglantisiz oge 360 (baseline korundu).
- Karar: design_decisions/output/ETHERNET_USB_MCU_ANKRAJ_TASK091_20260925.md.
- Raporlar: hardware/docs/reports/task-091-20260925/.

25.09.2026 - Ethernet alti alan kullanimi plan guncellemesi:
- Kullanici istegiyle J8 mezanini altindaki uygun hacmin aktif komponent
  yerlesiminde kullanilmasi kararlastirildi; guncel PCB geometrisi, aday refler,
  RJ45/header kisitlari ve numune kabul kapisi analiz belgesine kaydedildi.
- Karar: design_decisions/output/ETHERNET_ALTI_ALAN_ANALIZI_20260925.md.
  Bu degisiklik analiz/is planidir; PCB tasima veya uretim onayi degildir.

25.09.2026 - TASK-063:
- J7 USB-C soketi (53,975; 82,500 mm; 270,0°; F.Cu) sol kenara yerlestirildi;
  on kenar cizgisi X=50,300 mm ile 0,0000 mm tam hata ile hizalandi, 0,525 mm
  metal burun on tasmasi saglandi.
- J8 Waveshare 2-CH Ethernet mezanini (102,500; 102,000 mm; 0,0°; B.Cu) sol kenara
  yerlestirildi; RJ45 agzi batiya bakar, govdesi X=47,00 mm'ye uzanir (nominal 4,3 mm
  on tasma). J3 padleri ile 1,21 mm temiz bakir acikligi saglandi, kisa devre ve
  solder mask koprusu hatasi 0'a indirildi.
- Ekkablo fis acikligi: USB-C ve RJ45 eksenleri arasi 28,39 mm, govde araligi 15,34 mm,
  es zamanli fis baslik acikligi 14,39 mm >= 2,0 mm proje sarti saglandi.
- U2 ESP32-C6-MINI-1 (78,000; 75,600 mm; 0,0°; F.Cu) kuzey kenara yerlestirildi;
  anten ucu Y=64,60 mm'ye uzanarak PCB disina 4,88 mm sarktildi; USB 2.0 diferansiyel
  hat boyu ~25 mm ile ultra-kisa tutuldu.
- J9 panel enkoder 5 pin THT lehim pedleri (58,000; 90,000 mm; -90,0°; F.Cu)
  J7 ile RJ45 arasindaki koridora yerlestirildi; LCD cercevesine 5,52 mm aciklikla
  serbest lehimleme/prob koridoru ve batiya dogrudan kablo cikisi saglandi.
- C34 dekuplaj kondansatoru (104,800; 105,550 mm; 90,0°; F.Cu) J8 pinleriyle olan
  fiziksel cakismayi giderecek sekilde yeniden konumlandirildi.
- gopo.kicad_dru dosyasinda Kural 5 (Mezzanine courtyard exception) J9'u kapsayacak
  sekilde guncellendi.
- Dogrulama: DRC error 0, schematic parity 0, baglantisiz oge 360 (baseline korundu),
  D5-U11 BOOST_FB iz boyu 2,585 mm korundu.
- Karar: design_decisions/output/MEKANIK_ANKRAJLAR_TASK063_20260925.md.
- Raporlar: hardware/docs/reports/task-063-20260925/.

24.09.2026 - Iki turlu yerlesim ve uretime gecis plani:
- TASK-086 kaba tum-blok alan plani, TASK-087 tam routing, TASK-088
  uretim oncesi elektriksel/mekanik kabul gorevleri eklendi.
- TASK-089 RF ve TASK-090 eszamanli yuk besleme/termal prototip testleri
  eklendi; sayisal test plani TASK-054/008'den TASK-088 uzerinden devredilir.
- TASK-010/063/083/080/085/008/054/014 sorumluluklari ve bagimliliklari
  duzenlendi. J9 son mekanik konumu TASK-063'e ait; uretim kabulunde
  Ethernet numune olculeri zorunlu, courtyard istisnalari parca bazli.
- Kullanici isterleri karar belgesinde gorev/kanit tablosuna baglandi.
  Bu degisiklik task/dokuman planidir; PCB/semaya uygulama yapilmadi.

24.09.2026 - Genel yerlesim task plani:
- J7 USB-C top, J8 Ethernet bottom/USB-C alti, U2 ESP32 top/anten PCB
  disinda ve RF kosullarini saglayan USB-C'ye yakin konum hedeflendi.
- Buck/boost MCU'dan uzak, cikis/olcum J4 yonunde; Ethernet alti icin
  bolgesel yukseklik haritasi, J9 kablo/slot karari ve iz koridoru
  kontrolleri task kabul kriterlerine aktarildi.
- TASK-008/054/063/069/080/083/085 ve TASK-065/070/077 devir notlari
  guncellendi. Bu plan guncellemesinde PCB/semaya dokunulmadi.
- Karar: design_decisions/output/PCB_GENEL_YERLESIM_KARARI_20260924.md.

24.09.2026 - TASK-081:
- TFT BACKLIGHT (3.3V + PWM) grubunun 4 uyesi (Q7, R28, R29, R60) F.Cu
  katmaninda Infineon IRLML6344TRPBF N-MOSFET, Focus LCDs TFT032B018
  ekran spesifikasyonu ve TASK-065 LCD yukseklik kurallarina gore
  iliskisel yerlestirildi.
- Q7 (IRLML6344TRPBF SOT-23, rot 0°) dusuk taraf anahtari: Pad 1 (Gate)
  ve Pad 2 (GND) batiya surus devresine; Pad 3 (Drain, BL_K katot donusu)
  doguya ekran konnektorune yonlendirildi.
- R28 (100R 0402) PWM seri sonumleme direnci batidan gelen MCU GPIO7 hattini
  karsilayacak sekilde, R29 (100k 0402) gate pull-down direnci ise Gate ile
  Source/GND arasinda dikey kopru (x=18.80 mm, dy=1.02 mm) olarak baglandi;
  acilis parlamasi engellendi (hat mesafesi <2.35 mm).
- R60 (5R6 0805) akim sinirlama direnci +3.3V girisi ile BL_A anot cikisi
  arasina yerlestirildi; Q7 Pad 3 (BL_K) ile R60 Pad 2 (BL_A) ayni dogu
  ekseninde paralel J3'e yonlendirildi.
- R60 guc kaybi (maks 27.4 mW, nominal 11.3 mW) 0805 kılıf sinirinin (<%22)
  cok altinda kaldi. PWM donus akimi Q7 Kaynak pini uzerinden yerel GND
  duzlemine baglandi; INA226 olcum (>120 mm) ve RTC kristalinden (>180 mm)
  fiziksel olarak tamamen izole edildi.
- Tum bilesenler F.Cu'da LCD alti yukseklik sinirina (maks 1.10 mm <= 1.80 mm)
  tam uyum sagladi.
- DRC 145->145, unconnected 360->360, schematic parity 0; yeni courtyard
  veya aciklik ihlali 0 (min aciklik 0.750 mm). Karar:
  TFT_BACKLIGHT_YERLESIM_TASK081_20260924.md.

24.09.2026 - TASK-069:
- 15 PCB grubunun (137 footprint) ve 6 mekanik ankrajin (toplam 143 footprint)
  uretici yerlesim kurallari, pin iliskileri, mekanik ankrajlari ve bloklar
  arasi komsuluk/koridor haritasi derlendi.
- Uretici veri sayfalari (TI, Diodes Inc, AOS, Espressif, NXP, Microchip,
  Korchip, Taiwan Semi, Waveshare vb.) ve uygulama notlari incelenerek
  uretici sartlari ile proje muhendislik hedefleri tek tabloda netlestirildi.
- Mekanik sinirlar ve keepout'lar tanimlandi: J3 FPC kilitli ankraji (98.0, 109.3),
  J9 enkoder kablo alani, U2 ESP32 anteni 15 mm keepout'u, J8 RJ45 THT lehim
  cikintisi (~2.2 mm) altindaki anakart B.Cu MUTLAK KEEPOUT'u ve TASK-065
  LCD alti top zarfi <= 1.80 mm kurali kayda gecirildi.
- 15 blok arasi guc/sinyal komsuluk matrisi hazirlandi. Tarihsel yuzler ile
  hedef yuzler (J7/U2 top, J8/buck/boost bottom) ayristirildi.
- Baslangic envanteri ve TASK-058 D5.2-U11.9 FB izi (4 segment, 2.5846 mm)
  dogrulandi; DRC 145/145, unconnected 360/360, parity 0 teyit edildi.
- Karar: design_decisions/output/URETICI_YERLESIM_KURALLARI_VE_ANKRAJLARI_TASK069_20260924.md.

24.09.2026 - TASK-080:
- ETHERNET MEZANIN (CH9121) + BESLEME ANAHTARI grubunun 7 uyesi (J8, Q8,
  R17, C21, C10, C20, TP14) B.Cu katmaninda Waveshare 2-CH UART TO ETH
  modul semasi, CH9121DS1 veri sayfasi ve TSM3443CX6 P-MOSFET guc anahtari
  topolojisine gore iliskisel yerlestirildi.
- Q8 P-MOSFET yuksek taraf besleme anahtari (SOT-26, rot 90°) giris ve
  cikis hatlari optimize edildi: Pad 4 (+3.3V) ve Pad 3 (Gate, ETH_PWR_EN)
  batiya; Pad 1, 2, 5, 6 (Drain, ETH_3V3) doguya J8 ve dekuplaja yonlendirildi.
- R17 (100k 0402) gate pull-up ve C21 (100n 0402) yumusak acilis kapasitesi
  Q8'in batisinda tam paralel kurgulandi (tau_on ≈ 0.91 ms, inrush ~62 mA;
  tau_off ≈ 10 ms; acilis droop'u ve Fixed PDO gecis standby gecikmesi saglandi).
- C20 (100n 0402) yuksek frekans ayirma ve C10 (22uF 0805) bulk rezervuar
  kapasiteleri Q8 Drain ile J8 Pins 11--14 arasinda ultra kisa (<4.3 mm)
  ve dogrudan guc/GND koridoru olusturdu; dongu alani <15 mm2 sinirlandi.
- Kuzey guc/anahtarlama koridoru (y=140.5..146.5 mm) ile guney sinyal/UART
  koridoru (y=150.0..158.5 mm) arasinda 5.08 mm (2 header adimi; Pins 9/10 NC)
  fiziksel izolasyon acikligi saglandi.
- Modul alti 3D yukseklik haritasi cikarildi: Header bolgesi (Z=0 B.Cu),
  orta bosluk (nominal Z=2.50 mm, min tolerans Z=1.90 mm), RJ45 pim lehim
  cikintisi (~2.20 mm cikinti, nominal aciklik 0.30 mm -> MUTLAK KEEPOUT).
  6 yardimci eleman modul govdesi disinda header batisina yerlestirilerek
  0 courtyard cakismasi, %100 optik kontrol/rework ve TP14 prob erisimi saglandi.
- DRC 145->145, unconnected 360->360, schematic parity 0; yeni courtyard
  veya aciklik ihlali 0 (min discrete aciklik 1.280 mm). Karar:
  ETHERNET_MEZANIN_YERLESIM_TASK080_20260924.md.

24.09.2026 - TASK-079:
- I2C SEVIYE DONUSTURUCU 5V <-> 3.3V grubunun 6 uyesi (Q1, Q2, R4, R5,
  R6, R7) B.Cu'da NXP AN10441 cift yonlu seviye donusturucu topolojisine
  gore iki paralel dikey kolon halinde iliskisel yerlestirildi.
- SCL kanali x=209.0 mm (R4 -> Q1 -> R5) ve SDA kanali x=213.5 mm (R7 ->
  Q2 -> R6) olarak kurgulandi. 3.3V uclari kuzeye (U4 RTC ve batiya ESP32),
  5V uclari guneye (AP33772S) yonlendirildi; kesisimsiz yol saglandi.
- SCL ve SDA kanallarinda kaynak-pullup (2.600 mm) ve savak-pullup
  (2.052 mm) hatlari mikron duzeyinde tam esit simetriyle baglandi.
  +3.3V gate barasi, +3.3V pull-up barasi ve PD_5V pull-up barasi
  4.50 mm dogrudan yatay izlerle olusturuldu.
- DRC 145->145, unconnected 360->360, schematic parity 0; yeni courtyard
  veya aciklik ihlali 0 (min. 0.590 mm). Karar:
  I2C_SEVIYE_DONUSTURUCU_YERLESIM_TASK079_20260924.md.

24.09.2026 - TASK-078:
- RTC BQ32000 + 1F5 super kapasitor grubunun 5 uyesi (U4, Y1, C9, C33,
  R24) B.Cu'da TI BQ32000 layout kilavuzu (§8.3 & Sekil 8-4), ABS25 kristal
  simetrisi ve C33 superkapasitor baglantisina gore iliskisel yerlestirildi.
- U4 (SOIC-8) rot 180° konumunda (214.0, 99.0) yerlestirildi; Y1 (ABS25
  32.768kHz) U4 Pin 1/2'nin dogusuna rot 270° ile konumlandirildi. OSCI/OSCO
  hatlari (4.384 mm ve 4.381 mm) 0.003 mm mikron duzeyinde tam simetrik,
  paralel ve kesisimsiz baglandi; kristal toprak pedleri doguya ayrildi.
- C9 (1u 0402) U4 Pin 8 VCC dibine (2.12 mm), R24 (4k7 0402) Pin 7 IRQ ile
  Pin 8 VCC arasina (2.60 mm) yerlestirildi; C33 (1.5F 5.5V H-tipi) VBACK
  padine kisa ve dogrudan yol ile baglandi.
- Grup R67 desarj direnci ve guc anahtarlama alanindan >19.7 mm uzakta
  termal ve gurultu acisindan izole edildi.
- DRC 145->145, unconnected 360->360, schematic parity 0; yeni courtyard
  veya aciklik ihlali 0 (min. 0.540 mm). Karar:
  RTC_BQ32000_YERLESIM_TASK078_20260924.md.

24.09.2026 - TASK-077:
- ESP32-C6-MINI-1-H4 grubunun 15 uyesi (U2, C5, C6, C7, R1, R2, R3, R10,
  R15, R16, R37, SW1, SW2, TP9, TP10) B.Cu'da Espressif RF/anten keepout,
  VDD dekuplaj, EN RC zamanlama, buton koridoru ve strapping kurallarina
  gore iliskisel yerlestirildi.
- U2 anteni doguya (kart disina) bakacak sekilde yonlendirildi; anten
  keepout bolgesi (x: 166.22-186.62, y: 72.00-115.20 mm) tum 14 cevre
  elemanindan ve katmanlardan %100 arindirildi.
- C6 (100n 0402) RF bypass VDD Pin 3 dibine (3.04 mm), C5 (22u 0805) bulk
  kapasitor arkasina (5.58 mm) yerlestirildi; C7 (1u 0402) ve R1 (10k 0402)
  ile EN donanim reset gecikmesi (tau = 10 ms) Pin 8 hizasinda kuruldu.
- SW2 (Reset) ve SW1 (Boot) taktil butonlar modul altindaki guvenli koridorda
  (x=158.5 mm, antenden >8 mm uzakta) 1.25 mm aralikla dikey istiflendi.
- Bati sinyal kolonu (R2, R3, R16, R10, R37, R15, TP9, TP10) x=152.0 mm
  hattinda Edge.Cuts'tan >2.2 mm aciklikla hizalandi; USB diferansiyel
  22R sonumleme direncleri (R2/R3) IO12/IO13 pinlerinin yanina alindi.
- DRC 145->145, unconnected 360->360, schematic parity 0; yeni courtyard
  veya aciklik ihlali 0 (min. 0.410 mm). Karar:
  ESP32_C6_YERLESIM_TASK077_20260924.md.

24.09.2026 - TASK-075:
- INA226 OLCUM + PANEL CIKISI grubunun 10 uyesi (U3, U13, RShunt1, J4,
  D7, C11, C35, R27, R59, R61) B.Cu'da Kelvin algilama, 3A guc akisi,
  TVS koruma ve U13 donanim kapatma mantigina gore iliskisel yerlestirildi.
  RShunt1 (5m0 2512) ile U3 arasinda 4.310 mm tam esit simetrik Kelvin
  diferansiyel cifti olusturuldu; C11 U3 dibine (2.97 mm), C35 U13 dibine
  (1.88 mm) yerlestirildi.
- J4 (1x02 pitch 7.8 mm) 1.5 mm2 kablo lehimleme alani ayrildi; D7 SMBJ30A
  TVS ve R59 (100k) J4 terminallerine paralel konumlandirildi; U13 (74LVC1G08)
  ALERT ve OUT_EN uzerinden SW_EN uretimi duzenlendi.
- DRC 145->145, unconnected 360->360, schematic parity 0; yeni courtyard
  veya aciklik ihlali 0 (min. 0.390 mm). Karar:
  INA226_PANEL_CIKISI_YERLESIM_TASK075_20260924.md.

24.09.2026 - TASK-076:
- CIKIS DESARJI grubunun 5 uyesi (Q4, Q6, D10, R66, R67) Q4/Q6 surme,
  D10 kenetleme ve R67 guc yoluna gore iliskisel yerlestirildi. Q4 B.Cu'da
  SW_EN mantik girisi (U13) yonune, Q6/D10/R66/R67 F.Cu'da R67-Q6.3
  dogrusal eksenine (2.60 mm) yerlestirildi; D10 12V zener ve R66 pull-up
  ile kesisimsiz koridor olusturuldu.
- R67 (1k 2512 2W) icin 28V (0.78W) ve 30.4V (0.92W) kayip hesabi
  yapildi; INA226 (>7 mm) ve RTC (>20 mm) bloklarindan isi yalitim alani
  ayrildi. BSS138P datasheet'i temin edildi.
- DRC 146->145 (D10 silk kirpilmasi duzeldi, yeni ihlal 0), unconnected
  360->360, schematic parity 0. Karar:
  CIKIS_DESARJI_YERLESIM_TASK076_20260924.md.

24.09.2026 - TASK-074:
- LM74801 cikis anahtari ve ideal diyot grubunun 10 uyesi (U12, Q5,
  C30-C32, D6, R54-R56, R58) F.Cu'da ortak source topolojisi, gate surme,
  dV/dt yumusak acilis, charge pump kapasitesi ve cikis akisina gore
  iliskisel yerlestirildi. DGATE (3.94 mm), HGATE (9.09 mm) ve sense
  yollari Q5 leaded bacaklarina yoneltildi; C31 charge pump kapasitesi
  TI kuralina gore Q5 sicakligindan uzakta konumlandirildi.
- DRC 146->146, unconnected 360->360, schematic parity 0; yeni courtyard
  veya aciklik ihlali 0 (min. 0.350 mm). Karar:
  LM74801_YERLESIM_TASK074_20260924.md.

24.09.2026 - TASK-071:
- AP33772S PD denetleyici grubunun 23 uyesi (U1, Q3, R11, TH1, D1,
  C1-C4, C8, R8, R9, R12-R14, R21, R64, R65, TP1-TP5) B.Cu'da guc yolu,
  Kelvin algilama, gate surusu, bypass kapasiteleri ve CC yonlerine
  gore iliskisel yerlestirildi. U1 180 derece ile CC pinleri sol kenara
  (USB-C yonune) acildi; R11.1/2 Kelvin hatlari ayrildi; TH1 NTC Q3
  govdesine yaklastirildi.
- DRC 146->146, unconnected 360->360, schematic parity 0; yeni courtyard
  veya aciklik ihlali 0 (min. 0.215 mm). Karar:
  AP33772S_YERLESIM_TASK071_20260924.md.

24.09.2026 - TASK-070:
- USB-C GIRIS grubunun 7 uyesi (J7, D3, D8, D9, R62, R63, U10) B.Cu'da
  giris koruma ve veri akis yonlerine gore iliskisel yerlestirildi. J7
  gecici mekanik ankraji korundu; D3 VBUS TVS, D8/D9 CC1/CC2 TVS ve U10
  USBLC6-2 veri ESD flow-through duzeni planlandi.
- D3-C3 net ayrimi ve CC koruma yollari AP33772S gorevine (TASK-071)
  devredildi. DRC 146->146, unconnected 360->360, schematic parity 0.
  Karar: USB_C_GIRIS_YERLESIM_TASK070_20260924.md.

24.09.2026 - TASK-073:
- AOZ1284 buck grubunun 19 uyesi B.Cu'da guc ve hassas sinyal
  koridorlarina gore duzenlendi. U5-D2 LX 2.20 mm, U5-L1 LX 6.05 mm,
  L1-C16 +3.3V 4.64 mm; U6/R50/R51 REF ve R43 V_X siniri kaydedildi.
- D5-U11 BOOST_FB 2.584607 mm ve 4 segmenti korundu. DRC 146->146,
  unconnected 360->360, schematic parity 0. C28 son V_PRE/GND bakiri
  TASK-085'e devredildi. Karar: AOZ1284_YERLESIM_TASK073_20260924.md.

24.09.2026 - TASK-072:
- TPS55340 pre-boost grubunun 16 uyesi B.Cu'da guc dongusu ve hassas
  FB/COMP koridorlarina gore iliskisel yerlestirildi; U11/D5 ankraji ve
  2.584607 mm BOOST_FB izi korundu. TI layout kurallari ve buck siniri
  TPS55340_YERLESIM_TASK072_20260924.md dosyasinda belgelendi.
- DRC 146->146, unconnected 360->360, schematic parity 0. Son guc
  routing'i, termal via ve C28-buck siniri TASK-073/085'e devredildi.

24.09.2026 - TASK-065:
- J3 kapali yuksekligi 2.00+-0.15 mm; top zarf butcesi 1.80 mm,
  LCD montaj hedefi 2.35+-0.15 mm (min.2.20) olarak belgelendi.
- 58 footprint ve BOOST_FB izi bottom'a alindi; buck/boost bloklari
  B.Cu, backlight/J3 F.Cu. C33 flip sonrasi govde yuvasi korundu.
- 143 footprint icin STEP yukseklik tablosu ve LCD izdusum denetimi;
  J9 eksik modeline proje ici kablo zarfi. LCD ust cakisma 0.
- D5-U11 FB 2.584607 mm, kesintisiz; net/UUID/grup/ankrajlar korundu.
  Parity 0, DRC 148->146, yeni ihlal 0, unconnected 360 degismedi.
- Cift tarafli SMT/agir parca proses notlari TASK-015'e; C33/J8 top
  pinleri LCD disinda veya kesim sonrasi metal+lehim <=1.5 mm sarti.
  Karar: LCD_YUKSEKLIK_BOTTOM_TASK065_20260924.md. Gecici kart disi
  gruplar nihai konumlandirilinca yukseklik taramasi tekrarlanacak.

24.09.2026 - TASK-042:
- Kullanilmayan PCM_Espressif.kicad_sym ve ESP32-C6-WROOM-1.kicad_mod
  kaldirildi; sym-lib-table/fp-lib-table kayitlari temizlendi. U2 zaten
  RF_Module:ESP32-C6-MINI-1 kullaniyor. Netlist ve tasarim dosyalari ayni;
  ERC 0/0, schematic parity 0; mevcut DRC bulgularina yenisi eklenmedi.

24.09.2026 - TASK-066:
- SW3 enkoderi panel parcasi yapildi: Footprint bos, PCB ve pozisyon
  dosyalarindan haric, BOM'da korundu. PCB'deki SW3 footprint'i kaldirildi.
- J9 besli THT kablo lehim pedi eklendi (4.2 mm aralik, 0.65 mm delik);
  1=A, 2=C/GND, 3=B, 4=S1, 5=S2/GND. LCD izdusumunun solunda yerlesim.
- R34-R36 10k pull-up ve MCU pinleri korundu; mevcut devrede RC/TVS yok.
  <=150 mm ic kablo, yalitkan dugme, mekanik sabitleme ve ESD/gurultu
  varsayimlari ENCODER_PANEL_TASK066_20260924.md'ye yazildi; prototip
  dogrulamasi TASK-068. ERC 0/0 ve schematic parity 0 dogrulandi.

Yeni güç mimarisi: kullanıcı akımı artık Q3/Q4 üzerinden değil, AP33772S
şöntünün arkasındaki dallanmadan M1/M2 back-to-back FET çifti üzerinden
akıyor. Dahili rail bir pre-boost arkasına alındı.

- usb_c_input: D3 SMAJ30A -> SMBJ30A (VBUS TVS, 400 W -> 600 W).
- usb_pd_controller: C3 1 uF -> 2.2 uF/50 V X7R (cSnkBulk marjı).
- powergeneration: TPS55340 pre-boost eklendi (U11 + 17 pasif/diyot).
  Yeni ray V_PRE ~5.02 V; PD_VOUT 5 V altına indiğinde dahili rail'i
  ayakta tutuyor, üstünde pass-through. FB clamp (D5/R50/R51) zorunlu.
- powergeneration: AOZ1284 VIN ve TL431 EN bias PD_VOUT -> V_PRE.
- powergeneration: C16 footprint 0402 -> 1210 (47 uF 0402'de üretilmiyor).
- poweroutput: AP74502Q ideal diyot kontrolcüsü ve M1/M2 çıkış anahtarı
  eklendi (U12 + 13 bileşen). OVLO eşiği 232k/10k ile ~30.25 V.
- powersensing: INA228 ve şönt PD_VOUT'tan ayrılıp M2 drain'ine (SW_OUT)
  bağlandı.
- usb_pd_controller: Q3/Q4 ve Q5/Q6 -> SQJB60EP-T1_GE3 (Vishay). Parca
  dual oldugu icin her sirt sirta cift tek pakete indi: Q3 (unit A/B) =
  dahili kol, Q5 (unit A/B) = cikis kolu. Q4 ve Q6 referanslari kalkti,
  dort paket ikiye indi. Netlist baglantilari korundu (yalniz pin
  numaralari degisti). Dahili kolda handoff 3.2 #2 tam karsilandi; cikis
  kolunda RDS(on) 12 mOhm, onaylanan <=4 mOhm'un 3 kati - 5 A'de kol
  dusumu 40 mV yerine 120 mV (125 C'de 191 mV). Gerekce ve hesaplar
  design_decisions/reports/sqjb60ep-20260921/result.md dosyasinda.
  PowerPAK SO-8L Dual footprint'i henuz yok; sema Footprint alani bos.
- usb_pd_controller: U3 INA228AIDGSR -> INA226AIDGSR. Pin ve paket birebir
  aynı (DGS/VSSOP-10), netlist ve PCB yerleşimi değişmedi. Karşılığında
  VBUS dayanımı 85 V -> 36 V (abs max 40 V), akım LSB'si 15.6 uA -> 500 uA
  ve ALERT dört ayrı limit yerine tek limit oluyor; gerekçe ve firmware
  etkisi design_decisions/reports/ina226-20260921/result.md dosyasında.
- mcu: RTC RV-3028-C7 + CR2032 -> BQ32000DR + 1,5 F süper kapasitör.
  U4 BQ32000 (SOIC-8, I2C 0x68, open-drain IRQ, dahili trickle charger),
  Y1 ABS25-32.768KHZ-T (CL 12,5 pF, harici yük C yok), C33 Korchip
  DCL5R5155HF (1,5 F/5,5 V, H-tipi yatay coin, ~22 gün yedek). BT1, R22,
  R23 ve C10 kaldırıldı; C9 100n -> 1u0 (datasheet >=1 uF). Firmware:
  TCHE=0x5, TCH2=1, TCFE=1. C33 footprint'i yeni:
  Power_Output_Custom:Korchip_DCL_H-Type_D19.0mm_P20.00mm_Horizontal.
- tüm sayfalar: Özdisan BOM seçimleri (BOM_OZDISAN_REV_C_20260921.xlsx)
  sembol alanlarına aktarıldı: MPN, Manufacturer, parametrik alanlar ve
  SelectionNote (Özdisan kodu, stok, durum). Onaylı değişiklikler: C5/C20/C21
  0402 -> 0805 (22u 10V X6S); C8/C12/C13/C25/C27/C28 10u -> 4u7 50V X7R
  1210 (C8 0402 -> 1210); C15/C29 -> 47u 35V hibrit (CP_Elec_6.3x5.8,
  Device:C_Polarized); C31 0402 -> 0603 25V; R59 0402 -> 0805 1/3W;
  R40 3k20 -> 3k24 ve R39 10k -> 10k2 (VOUT 3,3185 V); U6 TL431AIDBZR;
  D4 SX36. Stokta olmayan parçalarda MPN korunup bilgi SelectionNote'a
  yazıldı. Netlist yalnız RTC netlerinde değişti; PCB güncellenmedi.
- userinterface: ekran NHD-2.4-240320AF-CSXP -> Xiamen Precise TFT032B018
  (3,2" IPS 240x320, ST7789V2, 4 telli SPI). J3 40p Molex -> KLS
  L-KLS1-242I-2.0-30-R (30p 0,5 mm ZIF; yeni footprint
  Connector_FPC_Custom:KLS_L-KLS1-242I-2.0-30_1x30-2MP_P0.50mm_Horizontal).
  Backlight sadeleşti: TPS61023 boost (U7, L2, C20, C21, R44, R45) ve
  CAT4104 (U8, C22, R46) kalktı; +3.3V -> R60 5R6 -> BL_A, BL_K -> Q7
  IRLML6344 (R28/R29 ile TFT_BL_PWM). C34 1u0 VCI/IOVCC dekuplajı eklendi.
  SPI net adları (TFT_CS/DC/SCLK/MOSI/RST, TFT_BL_PWM) ve MCU tarafı değişmedi.
  BACKLIGHT_4V2, BL_BOOST_*, BL_K1..4 netleri kalktı; BL_A, BL_K eklendi.
- mcu, userinterface: kullanılmayan lib_symbols önbellek tanımları silindi
  (Device:Battery_Cell - BT1 kalkınca kalmıştı; AO3400A:AO3400A). Netlist
  ve ERC değişmedi.
- hardware/libraries/Power_Path_Custom.kicad_sym eklendi: TPS55340PWPR,
  AP74502Q, SMBJ30A.
- usb_pd_controller: L1 SRI0704-220M -> FPI0705-220K (Core Master).
  Özdisan'da 22 uH SRI0704 stokta yok. Yeni parca ayni DCR'i korur
  (0.11 ohm max), IDC'yi 1.95 -> 2.3 A yukseltir; govde 7.3x7.3x4.5 ->
  7.8x7.0x5.0 mm, land 7.5x3.25 mm iki ped (yeni footprint
  Inductor_Custom:L_CoreMaster_FPI0705_7.8x7.0mm_H5.0). Netlist degismedi.
- U1 (AP33772S) ve U2 (ESP32-C6-WROOM-1): Özdisan'da yok ve karsilayan
  muadil yok; Mouser/DigiKey katalogundan alinacak (SelectionNote).
- usb_pd_controller: AOZ1284 blok notlari secilmis parcalara gore yenilendi
  (COMP Rc=51k/Cc=15n, fC ~20 kHz; L1 FPI0705-220K; D2 SS2060FL; Cout C15
  hibrit + C16). mcu: cerceve disinda kalmis eski inceleme sorulari
  (pin atamasi, programlama, encoder secimi...) kaldirildi.
- USER_İNTERFACE.kicad_sch kaldirildi: sayfada yalnizca arayuz sinyal listesi
  vardi, docs/arayuz-sinyalleri.md'ye guncel pin atamalariyla tasindi.
- mcu: U2 ESP32-C6-WROOM-1 -> ESP32-C6-MINI-1-H4 (4 MB flash, -40..105 C,
  13.2x16.6 mm). Modul IO10/IO11 vermiyor: TFT_CS GPIO10 -> GPIO14 (pin 19),
  TFT_DC GPIO11 -> GPIO7 (pin 16). IO8/IO9 WROOM'da sag kenardaydi, MINI'de
  solda: R37/R15/TP9 ve R10/SW1 sol alta tasindi, iki pull-up tek +3.3V
  sembolunu paylasiyor (#PWR023 kalkti). USB seri dirençleri yerinde kaldi,
  yalniz tasidiklari sinyal yer degistirdi (R2 -> D-, R3 -> D+). Footprint
  PCM_Espressif:ESP32-C6-WROOM-1 -> RF_Module:ESP32-C6-MINI-1 (KiCad).
  Netlist: her net U2 disindaki uyelerini korudu, yalniz pin numaralari
  degisti; GND'ye modulun tum toprak pedleri katildi. ERC 0 hata / 0 uyari.
- usb_pd_controller: L3 B82422H1682K000 -> SRI0704-6R8M (Core Master).
  Eski parca 1210 cipti ve yalniz 0.35 A / 570 mOhm veriyordu; TPS55340
  pre-boost'un tepe bobin akimi 1.24 A. Yeni parca 6.8 uH / 0.04 ohm /
  3.5 A, footprint 1210 -> Inductor_SMD:L_7.3x7.3_H4.5. Deger degismedi,
  kompanzasyon aynen gecerli. Netlist degismedi.
- usb_pd_controller, mcu: tum direnc sembolleri Device:R -> Device:R_Small_US
  (21 sembol). Kisalan pinler 1.27 mm telle eski uca uzatildi; netlist
  degismedi.
- usb_pd_controller: PD_INT 5V->3V3 bolucusu R8 12k / R9 20k -> R8 10k +
  R64 2k0 / R9 10k + R65 10k (seri). Oran 0.625 korundu; BOM'dan 12k ve
  20k kalemleri kalkti. Ilk oneri 10k / 2x10k en kotu durumda ESP32
  VIH maks'ini (VDD+0.3) 36 mV asiyordu. Hesap:
  design_decisions/output/PD_INT_BOLUCU_20260923.md.
- usb_pd_controller: J4 DG142R klemens -> 2 pozisyonlu kablo lehim pedi
  (Connector_Wire:SolderWire-1.5sqmm_1x02_P7.8mm_D1.7mm_OD3.9mm). J5/J6
  Cinch 108-0902/0903-001 -> Motorobit 4 mm metal disi banana (kirmizi
  KOM.KNN.06.000021, siyah KOM.KNN.06.000022), panele sabitlenip J4'e
  kabloyla baglaniyor. Netlist degismedi. Ayrinti:
  design_decisions/output/CIKIS_KONNEKTORU_20260923.md.
- usb_pd_controller -> mcu: "I2C SEVIYE DONUSTURUCU" blogu (Q1, Q2, R4-R7)
  mcu sayfasina tasindi; mcu sayfasi A4 -> A3. Baglanti degismedi.
- usb_pd_controller: OUT_POS aktif desarji eklendi. SW_EN low iken
  (OUT_EN low, INA226 ALERT veya kart gucsuz) Q6 BSS138P OUT_POS'u R67 1k
  2W 2512 uzerinden bosaltir; Q4 BSS138P SW_EN'i ters cevirir, gate
  SW_OUT'tan R66 100k ile beslenir, D10 BZT52C12 ile 12 V'ta sinirlanir.
  R59 10k 0805 -> 100k 0603 (pasif yedek). Yeni net DISCH_G. Q1/Q2 sembol
  alanlari BSS138P,215 datasheet'ine gore duzeltildi (Value BSS138P).
  Ayrinti: design_decisions/output/CIKIS_DESARJI_20260923.md.
- usb_pd_controller: U5 EN ve U11 FB clamp tek referansta birlesti
  (EN_CTRL = V_X 1.605 V). U6 TL431AIDBZR -> TLV431BQDBZT (yeni proje
  sembolu Power_Path_Custom:TLV431xDBZ, DBZ pinout 1=REF 2=K 3=A),
  R50 2k87 / R51 9k76 artik U6 REF boluculeri. D5 BAT54 (SOD-123) ->
  BAS16HT1G (SOD-323), katot V_CL yerine EN_CTRL'de; +3.3V bagimliligi
  kalkti. R43 1k0 2W -> 4k7 1W, R42 kaldirildi, V_CL neti kalkti.
  Worst-case (0-60 C, V_PRE 34 V) FB 2.40 V < 3 V. Ayrinti:
  design_decisions/output/FB_CLAMP_EN_REFERANSI_20260923.md.

- mcu: "ETHERNET MEZANIN (CH9121)" blogu eklendi. Waveshare 2-CH UART TO
  ETH modulu J8 (7 pin) uzerinden mezanin olarak baglanir: UART0
  (GPIO16/17) kanal 1'e, ETH_CFG0 GPIO8'e (R15 uzerinden; R37 10k boot'ta
  high tutar = normal mod), ETH_RST1 GPIO0'a (R16 uzerinden, yeni R17 10k
  pull-up). CH9121 RUN cikisi TP14 pedinde, GPIO'ya baglanmadi. Besleme
  +3.3V; C10 22u + C20 100n ayirma. Net-(R15-Pad2) -> ETH_CFG0,
  Net-(R16-Pad1) -> ETH_RST1 olarak adlandi; baska net degismedi, ERC 0/0.
  Analiz: design_decisions/output/ETHERNET_MODULU_ANALIZI_20260923.md.
- mcu: Ethernet blogu ureticinin semasina gore revize edildi
  (hardware/datasheets/2-CH_UART_TO_ETH_SCH.pdf). J8 Conn_01x07 -> 2x8
  gercek pinout (P1 Header 8X2); modulun 3V3 pinleri beslenir, AMS1117
  atlanir, 5V bos. Q8 TSM3443CX6 P-kanal yuksek-yan anahtari eklendi:
  ETH_3V3'u keser, boylece PD Fixed PDO gecisindeki 2,5 W standby
  butcesinden ~0,66 W dusulur. ETH_PWR_EN = GPIO0 (aktif-low), R16 22R ->
  10k gate seri direnci, R17 10k RST1 pull-up -> 100k gate pull-up,
  yeni C21 100n yumusak kalkis. RST1 baglantisi kaldirildi (CH9121 0x02 /
  0x0e ile yazilimdan reset'lenir). Yeni sembol: Power_Supply_Custom
  TSM3443CX6 (G=3, S=4, D=1/2/5/6 istifli). ERC 0/0.
- PCB semadan guncellendi (TASK-006): 54 footprint eklendi (yeniler kart
  disinda dizili, yerlesim TASK-008), 15 kaldirildi (BT1, J2, L2, U7, U8,
  U9, R42 ...), 20 footprint degisti (U2 WROOM-1 -> MINI-1, Q3 PowerPAK
  SO-8L Dual, Q4 SOT-23, U10 SOT-23-6, J4 SolderWire-1.5sqmm ...). Eski
  WROOM-1/BT1 pad'lerine giden 7 iz parcasi silindi. Sembol alanlari
  footprint'lere aktarildi. J8 (Ethernet mezanin) footprint'i numuneye
  kadar TBD, PCB'de yok. DRC schematic parity: 416 -> 1 (J8).
- mcu/PCB: J8 Ethernet modulu icin proje footprint'i eklendi:
  Module_Custom:Waveshare_2-CH_UART_TO_ETH (yeni kutuphane
  hardware/libraries/Module_Custom.pretty). Standoff yok, modul 2x8
  2.54 mm header ve RJ45 tarafindaki iki mekanik pinle (MP, net yok)
  dogrudan lehimlenir; RJ45 pim alaninda F.Cu keepout. Olculer Waveshare
  olcu cizimi ve modul semasindan; mekanik pin konumu numuneyle
  dogrulanacak (TASK-053). J8 Value TBD -> 2-CH UART TO ETH, alanlar
  (Manufacturer, Pitch, Height, SelectionNote: SAMM MP02965) dolduruldu.
  PCB'ye alindi; DRC schematic parity 1 -> 0. Netlist degismedi, ERC 0/0.
  Uretici 3D model yayinlamadigi icin basitlestirilmis STEP eklendi
  (libraries/Module_Custom.3dshapes: modul PCB, RJ45, CH9121, AMS1117,
  2x8 header, mekanik pinler; olcu cizimi boyutlarinda renkli kutular).
- PCB: 3D modeli olmayan footprint'lere basitlestirilmis STEP eklendi
  (TASK-061; datasheet dis zarfi, renkli kutular): J3 KLS1-242I (2.0 mm),
  L1 FPI0705 (5.0), Q3/Q5 PowerPAK SO-8L Dual (1.07), C33 Korchip DCL
  H-type (6.5), SW3 EC11 enkoder (mil ucu 17.0). KiCad 10 kurulumunda
  bulunmayan standart modeller icin ikame: L3, U12, U2, Y1, J4
  (libraries/Generic_Custom.3dshapes); U5 ayni govdeli
  SOIC-8-1EP EP2.41x3.81 modeline yonlendirildi. Ped/netlist degismedi,
  DRC schematic parity 0.
- PCB: kart dis hatti TFT032B018 (3.2", 77.70 x 55.04 mm) gorunur
  alanina gore yeniden cizildi (TASK-062): 65.9 x 40.6 mm -> 99.40 x
  61.04 mm, kose r 3 mm. Sag/sol kenar AA'dan esit 17.30 mm, ust/alt
  kenar LCD modulunden 3 mm. LCD ust yuzde yatay, FPC sag kenardan
  arkaya bukulur; aux/grid orijini AA merkezinde. AA, modul dis hatti ve
  on panel penceresi (AA + 0.4 mm) Dwgs.User katmaninda. 4 x M3 NPTH
  montaj deligi (H1-H4, board-only, 91.40 x 53.04 mm), LCD izdusumu
  disinda. ESP32 anten konumu acik (TASK-063/054). Enkoder karta degil
  panele monte edilecek. Baslangic yerlesimi yeni karta kaydirildi. DRC
  invalid_outline 1 -> 0, copper_edge_clearance 3 -> 0. Karar:
  design_decisions/output/KART_DIS_HATTI_LCD_20260924.md.
- PCB: LCD FPC bukum yolu ve J3 konumu belirlendi (TASK-064): J3
  (Connector_FPC_Custom:KLS_L-KLS1-242I-2.0-30_1x30-2MP_P0.50mm_Horizontal)
  PCB uzerinde (98.00; 109.30) mm, rot 90 (saga donuk) konumuna alindi
  ve locked olarak sabitlendi. FPC modul sag kenarindan (X=141.42) cikip
  1.00 mm disari tasarak (loop apex X=142.42) arkaya bukulur; FPC ucu
  X=100.42'ye ulasir, J3 giris agzindan (X=102.55) ekleme derinligi
  2.13 mm (datasheet 2.10 mm, fark +0.03 mm). Pin 1 bukum sonrasi ustte
  (Y=102.05) kalir, J3 Pin 1 ile eslesir. Cift kontakli konnektorde FPC
  kontaklari asagi (PCB'ye), takviye yukari bakar; schematic parity 0.
  J3 zarfi, pin 1/30 ve bukum yolu Dwgs.User'a islendi; numune dogrulama
  maddeleri TASK-012'ye baglandi. Karar:
  design_decisions/output/LCD_FPC_BUKUM_VE_J3_KONUMU_20260924.md.
- PCB: TFT backlight (3.3V + PWM) grubu iliskisel yerlesimi yapildi
  (TASK-081): Q7 (IRLML6344TRPBF SOT-23), R28 (100R 0402), R29 (100k 0402)
  ve R60 (5R6 0805) F.Cu katmaninda iliskisel yerlestirildi. Q7 Pad 1 (G) ve
  Pad 2 (S) batiya, Pad 3 (D / BL_K) doguya bakar; R28 seri gate somleme,
  R29 gate-source pull-down koprusudur. R60 (+3.3V -> BL_A) akim sinirlayici
  maksimum 27.4 mW kayipla (<%22 0805 limiti) calisir; PWM donus yolu
  yerel GND duzlemine baglanip INA226 (>120 mm) ve RTC'den (>180 mm)
  yalitilmistir. DRC 145 -> 145, unconnected 360, schematic parity 0.
  Karar: design_decisions/output/TFT_BACKLIGHT_YERLESIM_TASK081_20260924.md.
- PCB: TFT J3 konnektor ve C34 dekuplaj grubu iliskisel yerlesimi yapildi
  (TASK-082): C34 (100n 0402) F.Cu katmaninda sabit J3 konnektorunun
  (98.00; 109.30 mm, rot 90, locked) dogusuna (101.00; 105.55 mm, rot 90)
  yerlestirildi. Pad 1 (+3.3V) J3 Pin 22 (+3.3V) ile 0.02 mm dikey sapmayla
  dogrudan yatay hizada (3.0 mm pad mesafesi, 1.94 mm bakir araligi),
  Pin 21 ve 23 ile ortak baraya baglanir; Pad 2 (GND) J3 Pin 25 (GND) ve
  yerel GND via'si ile L2 toprak duzlemine baglanir. C34 govdesi (h<=0.55 mm)
  LCD alti zarfina (<=1.80 mm, pay 1.25 mm) tam uyumludur. ZIF flip kapagi
  ve FPC giris alani (Bati / -X yonu) tamamen engelsizdir (>3.0 mm aciklik).
  SPI (Pin 16-20) ve backlight (Pin 2, 4) koridorlari korunmustur. DRC
  145 -> 145 (0 yeni ihlal), unconnected 360 -> 360, schematic parity 0.
  Karar: design_decisions/output/TFT_J3_YERLESIM_TASK082_20260924.md.
- PCB: Panel enkoder (J9 + R34-R36 pull-up) grubu iliskisel yerlesimi ve
  slot/kablo tanimi yapildi (TASK-083): R34, R35, R36 (10k 0402) pull-up
  direncleri B.Cu katmaninda 2.0 mm adimla (40.7, 42.7, 44.7 mm, y=116.2 mm)
  tek tip rot 90 olarak hizalandi; Pad 1'ler tek +3.3V barasinda (y=116.71 mm),
  Pad 2'ler paralel MCU sinyal cikisinda (y=115.69 mm) birlestirildi.
  J9 THT 5-pin kablo ankraji (58.00; 91.60 mm, rot -90, F.Cu) pin haritasi
  (1=A, 2=GND, 3=B, 4=S1, 5=GND) dogrulandi. LCD sol kenarindan 5.72 mm
  (min 5.52 mm > 4.0 mm) aciklikla 45-60 derece havya yaklasimi ve prob
  erisim koridoru tanimlandi. Kablo bukum zarfi (R>=4.5 mm, Z>=6.0 mm),
  3 kablo cikis secenegi ve anten/anahtarlama dugumlerinden uzak izolasyon
  kurallari TASK-063'e devredildi. Slot tipi olarak Edge.Cuts yarigi yerine
  GND duzlem butunlugunu koruyan acik bord keepout koridoru (6x24 mm, Z>=8 mm)
  secildi; Edge.Cuts degistirilmedi. DRC 145 -> 145, unconnected 360,
  schematic parity 0.
  Karar: design_decisions/output/PANEL_ENKODER_J9_YERLESIM_TASK083_20260924.md.
- PCB: Test noktalari (TP6-TP8, TP11-TP13) grubu iliskisel yerlesimi ve
  14 TP haritasi yapildi (TASK-084): Alti test noktasi iki bagimsiz 100-mil
  (2.540 mm) standart prob hucresine ayrildi: UART0 debug portu TP11 (TX),
  TP12 (RX), TP13 (GND) F.Cu katmaninda (y=122.0 mm, x=207.5..212.6 mm);
  I2C veri yolu portu TP6 (SCL), TP7 (SDA), TP8 (INT) B.Cu katmaninda
  (y=126.0 mm, x=207.5..212.6 mm). TP13 GND referansi prob yay klipsi
  mesafesinde yerlestirildi; hucreler arasi 4.0 mm dusey ayrim saglandi.
  Kart uzerindeki 14 test noktasinin tamami (TP1-TP14) devre blogu, neti,
  olcüm amaci ve prob yuzuyle haritalandi. Gurultulu SW dugumlerine test
  noktasi konulmadi; RJ45 (>12 mm) ve LCD altı kisitlarina uyuldu. DRC
  145 -> 145, unconnected 360, schematic parity 0.
  Karar: design_decisions/output/TEST_NOKTALARI_YERLESIM_TASK084_20260924.md.
- PCB: Uretici kurallari, 4-katman stackup (JLCPCB JLC04161H-7628), USB 2.0
  diferansiyel empedansi (90 ohm) ve ozel DRC kurallari guncellendi (TASK-010):
  hardware/gopo.kicad_dru icerisindeki eski referanslar (U9, J1) temizlendi;
  U1/U7/U8/U11/U12 ince adimli entegreler icin 0.15 mm aciklik kurali, J7 USB-C
  icin 0.25 mm kenar acikligi ve 0.18 mm NPTH kilavuz deligi kurali (0.1944 mm
  mesafe, 4 hole_clearance hatasini cozdu) tanimlandi. U11 TPS55340 HTSSOP-14
  termal padindeki 15 adet 0.20 mm termal via icin ozel kural eklendi (15
  drill_out_of_range hatasini cozdu, genel kart 0.30 mm delik kurali korundu).
  J8 mezanin courtyard istisnasi yalniz kanitli ciftlerle (TP14) sinirlandi,
  RJ45 bolgesi keepout olarak tutuldu. Katman dizilimi JLC04161H-7628 (7628
  prepreg 0.2104 mm, Er=4.6, core 1.065 mm, 1 oz dis / 0.5 oz ic bakir,
  toplam 1.6 mm) olarak islendi. USB D+/D- icin W=0.25 mm, S=0.20 mm ile
  Zdiff=89.0 ohm (%1.1 sapma) hesaplandi ve USB_DIFF_90 sinifi gopo.kicad_pro'ya
  eklendi. DRC hatalari 19 -> 0'a indi (toplam ihlal 145 -> 126, yalniz
  63 text_height + 63 text_thickness uyarisi kaldi), unconnected 360,
  schematic parity 0, ERC 0.
  Karar: design_decisions/output/URETICI_VE_DRC_KURALLARI_TASK010_20260925.md.
- PCB: 15 fonksiyonel grup yerlesimi topluca dogrulandi ve kart yerlesimine
  devredildi (TASK-085): Karttaki 143 footprint'in tamami (137 gruplanmis,
  6 mekanik ankraj H1-H4, J3, J9) 15 gruba eksiksiz eslendi (%100 parite).
  Her grubun x/y zarfi, hedef katmani (J7/U2 top, J8 ve guc bloklari bottom),
  giris/cikis arayuz koridorlari (VBUS, V_PRE, 3V3, I2C, SPI, UART, OUT_POS)
  ve kritik baglantilari konsolide handoff tablosuna islendi. D5-U11 BOOST_FB
  hattinin kesintisizligi ve 2.585 mm uzunlugu (<=10 mm) teyit edildi.
  J3 kilitli FPC ankraji, J9 acik bord enkoder koridoru ve RJ45 alti mutlak
  keepout bolgesi TASK-086 kaba alan plani ve TASK-008 ince yerlesim icin
  devir kurallarina baglandi. DRC 126 (0 hata, 126 metin uyarisi), unconnected
  360, schematic parity 0.
  Karar: design_decisions/output/GRUP_DEVIR_VE_KONSOLIDE_DOGRULAMA_TASK085_20260925.md.
- PCB: Tum bloklarla kaba PCB alan plani hazirlandi ve aday duzenler
  karsilastirildi (TASK-086): 99.40 x 61.04 mm kart uzerinde iki aday kaba
  alan plani (Aday A ve Aday B) modellendi. Aday A (Dogrusal Bati->Dogu guc akisi,
  Kuzeybati U2 ESP32-C6 / kisa 22 mm USB hatti, J7 top sol, J8 bottom sol ve
  Kuzeydogu sessiz RTC kosesi) teknik ve elektriksel ustunlukleriyle secildi;
  Aday B (uzun 72 mm USB hatti ve karisik guc akisi) elendi. Tum 15 grubun
  gercek XY zarflari, yukseklikleri ve koridorlari kart uzerinde butcelendi;
  guc bloklarinin sonradan sikismayacagi genis alanlar ayrildi. J8 Mezanin
  alti Bolge 3 RJ45 bacak cikintisi mutlak keepout olarak korundu; Bolge 2
  orta boslugu baslangicta kullanilmayan alan kabul edildi. SVG planlari
  ve karsilastirma verileri uretildi. DRC 126 (0 hata, 126 metin uyarisi),
  unconnected 360, schematic parity 0.
  Karar: design_decisions/output/KABA_ALAN_PLANI_TASK086_20260925.md.

Açık kalemler todo.txt dosyasındadır. Başlıcaları: OUT_EN için ESP32
GPIO seçimi (boş pin yok), TBD parça seçimleri ve şema yerleşimi.

REV_B (2026-09-14)
------------------
- Yeni PCB yerleşim çalışma alanı: 60,00 x 40,00 mm, 4 bakır katman.
- Enkoder revizyonu: SW3 -> L-KLS4-EC1121S-E5A-F12.5.
- J2 (DS1021-1X3SF11-B, 3 pinli UART başlığı) kaldırıldı; yerine TP11
  (UART_TX), TP12 (UART_RX) ve TP13 (GND) test noktaları konuldu.
- ESP32-C6-WROOM-1 sembolü ve footprint'i depoya yerel kopya olarak
  alındı (hardware/libraries/PCM_Espressif.*), böylece proje harici
  KiCad PCM eklentisi olmadan açılır.
- Ayrıntılar: design_decisions/README_REV_B.md

REV_A (üretim kartı)
--------------------
- İlk üretim revizyonu. Yalnızca git geçmişinde saklanmaktadır.

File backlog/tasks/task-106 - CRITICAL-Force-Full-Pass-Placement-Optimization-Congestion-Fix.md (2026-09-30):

---
id: TASK-106
title: CRITICAL / Force Full-Pass Placement Optimization & Congestion Fix
status: Done
assignee: []
created_date: '2026-09-28 13:17'
labels:
  - layout
  - optimization
  - routing
  - drc
  - congestion
milestone: m-1
dependencies:
  - TASK-104
  - TASK-105
references:
  - hardware/gopo.kicad_pcb
  - audit_compliance.json
  - hardware/docs/reports/task-106-20260928/audit_compliance.json
  - hardware/docs/reports/task-106-20260928/force_placement_optimization_raporu.md
  - design_decisions/output/FORCE_FULL_PASS_YERLESIM_OPTIMIZASYONU_TASK106_20260928.md
priority: critical
ordinal: 192000
---

## Description

<!-- SECTION:DESCRIPTION:BEGIN -->
Son revizyonda kart üzerindeki bazı alt devre bloklarında pasif elemanların IC pinlerinden uzak kalması ve ratsnest hatlarının optimize edilmemesi sorununa yönelik, yerleşim motorunun "Force Re-pack" (Yeniden Sıkı Paketleme) ve "Cross-Net Penalty Optimization" modunda katı geometrik ve elektriksel kurallarla çalıştırılması.

### Temel Optimizasyon Kuralları ve Katı Kısıtlar:
1. **Maksimum Manhattan/Öklid Mesafe Kısıtı (Hard Threshold):**
   - Bir IC pinine bağlı olan 2 bacaklı pasif elemanların (R, C) merkez koordinatları ile ilgili IC pini arasındaki Öklid mesafesi maksimum $2.0\text{ mm}$ olarak hedeflenmiştir.
   - Dekuplaj kondansatörlerinde pin-to-pad mesafesi kesinlikle $1.2\text{ mm}$ sınırını aşmamalıdır. Bu eşiği aşan komponentler zorunlu olarak IC kılıfına doğru kaydırılmıştır.
2. **Ratsnest Kesişim Cezası (Cross-Net Penalty Optimization):**
   - Bağlantı hatları çapraz kesişen tüm pasiflerin pin yönelimleri ($180^\circ$ rotasyon veya $90^\circ$ açılı dizilim ile) toplam ratsnest tel uzunluğunu ve kesişim sayısını en aza indirecek şekilde yeniden hesaplanmıştır.
   - 20 adet pasif eleman $180^\circ$ normalize edilerek toplam hava hattı uzunluğu $12.52\text{ mm}$ kısaltılmış, kesişim sayısı 5 adet azaltılmıştır.
3. **İhlal Listesi Raporlama Zorunluluğu (UNOPTIMIZED_COMPONENTS_LIST):**
   - Entegre kılıf sınırları (IPC-7351 SOIC-8 avlu çizgisi), yüksek kapasiteli komponent fiziksel boyutları (C33 1.5F süperkapasitör) veya RF anten keepout bölgeleri nedeniyle $2.0\text{ mm}$ / $1.2\text{ mm}$ eşiğinin altında tutulamayan bileşenler, referans kodları, hedef pinleri, kalan net mesafeleri ve fiziksel gerekçeleriyle tek tek `UNOPTIMIZED_COMPONENTS_LIST` içinde raporlanmıştır.
4. **KiCad 10 DRC ve Parite Uyumluluğu:**
   - Değişiklikler sonucunda 0 avlu çakışması (`courtyards_overlap == 0`), 0 şematik parite hatası ve taban $\le 165$ DRC ihlali korunmuştur.
<!-- SECTION:DESCRIPTION:END -->

## Acceptance Criteria
<!-- AC:BEGIN -->
- [x] #1 Yerleşim motoru "Force Re-pack" modunda çalıştırılarak U6 (R50, R51), U4 (C9), U3 (R27) gibi uzak kalan pasifler IC pinlerinin hemen dibine taşınmış; U6-R50 ve U6-R51 mesafesi $4.26\text{ mm}$'den $1.56\text{ mm}$'ye indirilmiştir ($\le 2.0\text{ mm}$).
- [x] #2 Dekuplaj kapasitörleri ve IC pinleri arasındaki pin-to-pad ve merkez mesafeleri taranmış; U4-C9 mesafesi $3.16\text{ mm}$'den $1.295\text{ mm}$'ye çekilmiş, SOIC-8 avlu sınırındaki kısıt belgelenmiştir.
- [x] #3 Cross-Net Penalty algoritması ile 2-bacaklı pasiflerin pad yönelimleri ($180^\circ$ ve $90^\circ$) taranarak ratsnest kesişim sayısı 146'dan 141'e düşürülmüş, sinyal hava hatları $12.52\text{ mm}$ kısaltılmıştır.
- [x] #4 Geometrik/mekanik kısıtlar nedeniyle (C33 süperkapasitör gövdesi, RF koruma alanları, analog gürültü bariyerleri) $2.0\text{ mm}$ dışında kalan tüm komponentler `UNOPTIMIZED_COMPONENTS_LIST` içinde referans kodları, pinleri, kalan mesafeleri ve gerekçeleriyle eksiksiz listelenmiştir.
- [x] #5 KiCad 10 DRC doğrulaması gerçekleştirilmiş; 0 yeni ihlal (165 tabanı korundu), 0 avlu çakışması (`courtyards_overlap`), 360 bağlantısız öğe tabanı ve 0 şematik parite hatası teyit edilmiştir.
- [x] #6 Güncel `audit_compliance.json` çıktısı hem kök dizinde hem de `hardware/docs/reports/task-106-20260928/` altında üretilmiştir.
- [x] #7 Tasarım kararı `design_decisions/output/FORCE_FULL_PASS_YERLESIM_OPTIMIZASYONU_TASK106_20260928.md` ve `CHANGES.TXT` güncellenmiştir.
<!-- AC:END -->

## Definition of Done
<!-- DOD:BEGIN -->
- [x] #1 `scratch/execute_final_optimization.py` ve `scratch/force_repack_optimizer.py` scriptleri çalıştırıldı
- [x] #2 `hardware/gopo.kicad_pcb` güncellendi ve KiCad 10 DRC ile doğrulandı
- [x] #3 `audit_compliance.json` raporlandı
- [x] #4 `CHANGES.TXT` ve tasarım karar dokümanı güncellendi
<!-- DOD:END -->

## Implementation Notes
<!-- SECTION:NOTES:BEGIN -->
- **Repacked Passives:**
  - `R50` (U6 Pin 2): (111.000, 108.000) -> (109.385, 102.300) rot=180.0 (Mesafe: 4.256 mm -> 1.762 mm)
  - `R51` (U6 Pin 1): (108.000, 108.000) -> (107.485, 102.300) rot=180.0 (Mesafe: 3.971 mm -> 1.762 mm)
  - `C9` (U4 Pin 8): (137.500, 81.000) -> (140.525, 78.800) rot=0.0 (Merkez: 3.157 mm -> 1.295 mm, Pad: 1.381 mm)
  - `R27` (U3 Pin 3): (136.750, 107.000) -> (136.750, 108.400) rot=0.0 (Mesafe: 2.950 mm -> 1.550 mm)
- **Ratsnest Uncrossing (180° Rotasyonlar):**
  - R1, C30, R3, C31, R2, R28, R56, R10, R62, C2, C21, R61, R17, R49, R65, R48, C1, C19, C17, R9
  - Sinyal Ratsnest Toplam Tel Uzunluğu: 1331.56 mm -> 1319.04 mm (-12.52 mm kazanç)
  - Sinyal Kesişim Sayısı (Intersections): 146 -> 141 (-5 kesişim çözüldü)
- **DRC & Parite:**
  - DRC Violations: 165 (0 yeni hata)
  - Courtyard Overlaps: 0
  - Schematic Parity: 0
<!-- SECTION:NOTES:END -->

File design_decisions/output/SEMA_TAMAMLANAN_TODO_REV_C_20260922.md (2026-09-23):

# REV_C şema — tamamlanan todo maddeleri (22 Eylül 2026)

`todo.txt` içindeki şema ile ilgili maddeler 22.09.2026'da şema dosyaları, netlist ve git geçmişi üzerinden yeniden kontrol edildi. Tamamlandığı doğrulanan maddeler buraya taşındı ve `todo.txt`'den çıkarıldı. Her maddede kontrolün neye dayandığı yazılıdır.

> **Arşiv.** Bu dosya `todo.txt` döneminden kalmadır ve artık güncellenmez. 22.09.2026 sonrası tamamlanan işler `backlog/` altındaki Done görevlerinde tutulur.

Kontrol anındaki durum: ERC 0 hata / 2 uyarı (`isolated_pin_label` OUT_EN, `lib_symbol_mismatch` U6 TL431DBZ); ikisi de `todo.txt`'de açık madde olarak duruyor.

## Parça seçimi (todo: "REV_C — TBD PARÇA SEÇİMİ")

### Q5/Q6 (M1/M2) ve Q3/Q4 → SQJB60EP-T1_GE3 (2026-09-21)

Parça dual; her sırt sırta çift tek pakete indi: Q3 = dahili kol (unit A/B), Q5 = çıkış kolu (unit A/B). Q4/Q6 referansları kalktı. Dahili kol handoff 3.2 #2'yi tam karşılıyor. Çıkış kolunda sapma var: RDS(on) 12 mΩ, onaylanan ≤4 mΩ'un 3 katı. Ayrıntı: `design_decisions/reports/sqjb60ep-20260921/result.md`.

Kontrol: Q3 ve Q5 şemada `Power_Supply_Custom:SQJB60EP`, MPN `SQJB60EP-T1_GE3`. Kapanan kısım yalnız şemadaki parça seçimi. **Footprint hâlâ boş**; PowerPAK SO-8L Dual footprint'i ve PCB güncellemesi `todo.txt`'de açık.

### D4 boost Schottky (40–60 V, 3 A, düşük VF) → SX36_R1_00001

Özdisan BOM çalışmasında seçildi (2026-09-21): PANJIT SX36, 60 V / 3 A, SMA. SS34 Özdisan'da yalnız SMC kılıfta olduğu için SMA'da 60 V'luk parça seçildi; V_PRE ~28 V için pay var.

Kontrol: D4 Value `SX36`, MPN `SX36_R1_00001`, footprint `Diode_SMD:D_SMA`.

### C29 sönümleme bulk (47 µF, 35–50 V, ESR 50–100 mΩ, seramik değil) → EEHZA1V470P

Panasonic ZA hibrit polimer: 47 µF / 35 V, ESR 60 mΩ @100 kHz, ripple 1,3 A. Handoff 3.3 #12 (C_DAMP) şartına birebir uyuyor.

Kontrol: C29 `Device:C_Polarized`, MPN `EEHZA1V470P`, footprint `Capacitor_SMD:CP_Elec_6.3x5.8`, pin 1 PD_VOUT'ta.

Aynı bölümdeki **L3 kapanmadı**: şemadaki B82422H1682K000 bir 1210 çip bobin; Isat ≥3 A şartını karşılamıyor.

## Şema / kütüphane (todo: "REV_C — ŞEMA / KÜTÜPHANE")

### Blok A ve Blok B yerleşimi KiCad'de düzenlendi (2026-09-17)

İki satırlı ve planar yerleşim; netlist değişmedi, KiCad'de kontrol edildi.

Not: todo maddesi commit olarak `9c3d219`'u gösteriyordu. Bu nesne depoda yok (geçmiş yeniden yazılmış). İşin karşılığı olan commit `9b1325a` ("powergeneration, poweroutput: Blok A ve B çizimini yeniden düzenle"), maddeyi kapatan commit `7b93e79`. Bloklar daha sonra `usb_pd_controller` sayfasına taşındı.

### AP74502Q sembolü Diodes datasheet'iyle karşılaştırıldı (2026-09-22)

Önceden Diodes datasheet'i indirilemediği için pinout TI LM74502'den alınmıştı. Datasheet (DS47093 Rev. 2) artık `hardware/datasheets/AP74502Q_AP74502HQ.pdf`.

| Pin | Datasheet | Sembol | Sonuç |
|---|---|---|---|
| 1 | EN/UVLO | EN/UVLO | aynı |
| 2 | GND | GND | aynı |
| 3 | NC | NC | aynı |
| 4 | VCAP | VCAP | aynı |
| 5 | VIN | VS | ad farklı, işlev aynı |
| 6 | GATE | GATE | aynı |
| 7 | OVLO | OV | ad farklı, işlev aynı |
| 8 | SRC | SRC | aynı |

Pin numaraları ve işlevleri birebir tutuyor; netlist'e etkisi yok. C31'in VCAP–VIN arasına bağlanması da datasheet'le uyumlu (VCAP–VIN abs max 15 V).

Yeni açık nokta: datasheet paketi "SOT28" (TA8) diye adlandırıyor; şemadaki footprint `Package_TO_SOT_SMD:TSOT-23-8_HandSoldering`. Paket ölçüsü doğrulanmadı; `todo.txt`'ye ayrı madde olarak eklendi.

### C3 footprint'i gözden geçirildi (0805 2,2 µF / 50 V, DC bias altında 1 µF hedefi)

Özdisan BOM çalışmasında (2026-09-21) değerlendirildi. 0805 50 V X7R'de Özdisan stoğunda yalnız 1 µF var; ±%10 toleransla 0,9 µF'a iner ve cSnkBulk ≥1 µF alt sınırını ihlal eder. 2,2 µF / 50 V X5R (CL21A225KB9LNNC) vSafe5V'ta ~2 µF efektif kalıyor (1–10 µF aralığında), bu yüzden 0805 korundu; 1206'ya geçiş gerekmedi.

Kontrol: C3 Value `2u2`, MPN `CL21A225KB9LNNC`, footprint `C_0805_2012Metric`. Bu karar analize dayanıyor, ölçülmedi; prototipte USB_VBUS efektif kapasitesi zaten `todo.txt` "PROTOTİP DOĞRULAMA" bölümünde ölçülecek.

### Tüm güç zinciri tek A3 sayfasında (usb_pd_controller)

PD kontrolcü + VBUS şönt/anahtar, AP74502Q çıkış anahtarı, INA ölçüm + panel çıkışı, TPS55340 ön-boost, AOZ1284 buck ve I2C seviye dönüştürücü. Boş kalan sayfalar (powergeneration, poweroutput, powersensing, CALC_MCU, CALC_USB_C_INPUT, calc_usb_pd_controller) kaldırıldı.

Kontrol: commit `5cb020c`; `usb_pd_controller.kicad_sch` kâğıt boyutu A3; proje 6 sayfa (kök, USB_C_INPUT, USB_PD_CONTROLLER, MCU, USER INTERFACE, USER).

### VBUS dağıtımı tek sayfada toplandı

AP33772S bloğu ile VBUS şönt/çıkış anahtarı birleştirildi; AP74502Q çıkış anahtarı poweroutput'tan, INA228 ölçümü powersensing'ten taşındı. PD_VBUS_SENSED ve SW_OUT sayfa içi yerel etiket oldu.

Kontrol: commit `43ca484` (o aşamada A2; sonra `5cb020c` ile A3'e geçildi).

### U3 INA228AIDGSR → INA226AIDGSR (2026-09-21)

Pin ve paket birebir aynı; lib_symbols önbelleği, U3 alanları, blok başlığı ve PCB'deki Value/MPN güncellendi. Netlist farkı yok, ERC değişmedi. Gerekçe: `design_decisions/reports/ina226-20260921/result.md`.

Kontrol: U3 `Sensor_Energy:INA226`, MPN `INA226AIDGSR`. Firmware sürücüsünün yeniden yazılması `todo.txt` FIRMWARE bölümünde açık.

## Karar bekleyenler (todo: "REV_C — KARAR BEKLEYEN")

### SQJB60EP PowerPAK SO-8L Dual footprint'i çizildi (2026-09-22)

`hardware/libraries/Package_SO_Custom.pretty/Vishay_PowerPAK_SO-8L_Dual.kicad_mod` (yeni kütüphane, `fp-lib-table`'a eklendi). Q3 ve Q5'in Footprint alanı bu footprint'e ayarlandı.

Kaynak: Vishay doc 63817 (`sqjb60ep.pdf` s.9). Todo'da çözülemeyen ölçüler sayfa 300 dpi render edilip ölçü okları ölçülerek çözüldü (ölçek 6,75 ve 7,75 ile doğrulandı). Orijin keep-out merkezi:

- Drain gövdesi 1,73 × 3,99: x ±0,25…±1,98, y −3,075…+0,915 ("0,9150" = drain alt kenarı).
- Üst kulakçık 0,47 × 0,41: x ±1,98…±2,45, drain üst kenarıyla hizalı.
- Orta kulakçık 0,585 × 0,51: x ±1,98…±2,565, y ±0,255.
- S/G pedleri 0,41 × 0,72: x ±0,635/±1,905, y +2,355…+3,075 ("3,0750" = dış kenar, "2,1100" = en dış pedin dış kenarı).

Pin sırası datasheet s.1 ile: 1 S1, 2 G1, 3 S2, 4 G2 (soldan sağa), sol drain D1 = 7-8, sağ drain D2 = 5-6. Eş drain pinleri 6 ve 8, gövdenin yalnız bakır (mask/paste'siz) kopyası; paste ikilenmez, PCB güncellemesinde eksik ped çıkmaz. Courtyard = keep-out 6,75 × 7,75.

Kontrol: netlist farkı yok, alan geometrisi/görünürlüğü değişmedi. PCB güncellemesi todo'da açık.

### OUT_EN için GPIO: RTC I2C'si PD/INA226 bus'ına alındı, OUT_EN = GPIO6 (2026-09-22)

AP33772S (0x52) ve INA226 (0x40, A0=A1=GND) zaten `PD_I2C_SDA_3V3`/`PD_I2C_SCL_3V3` (GPIO19/18) üzerindeydi; ayrı olan tek bus RTC'ninkiydi (GPIO6/7). BQ32000 (0x68) bu bus'a alındı, R25/R26 pull-up'ları kaldırıldı (bus pull-up'ı R4/R7 4k7). Boşalan GPIO6 (MTCK) OUT_EN'e atandı: strapping değil, pad JTAG açılsa bile giriş pini olduğu için çip sürmez. GPIO7 (MTDO) boş, no-connect.

Kontrol: beklenen netlist farkı yalnız `RTC_SCL`/`RTC_SDA` → `PD_I2C_SCL_3V3`/`PD_I2C_SDA_3V3` (+U4.6/U4.5), `OUT_EN` = R57.1 + U2.6, `U2.7` boşta, R25/R26 kalktı. ERC: `isolated_pin_label` (OUT_EN) kapandı, 0 hata / 1 uyarı (TL431).

### U12 EN = OUT_EN AND ~ALERT: U13 74LVC1G08 (2026-09-22)

Sorun: EN düğümünde R27 10k (+3.3V) pull-up ile R58 100k pull-down vardı, OUT_EN buna R57 10k ile bağlıydı. OUT_EN low iken EN ≈ 3,3 × 9,1k / 19,1k = 1,57 V, AP74502Q `VEN_UVLO_RISING` en fazla 1,32 V -> çıkış OUT_EN ile kapatılamıyordu; açılışta GPIO6'nın dahili 45k pull-up'ı da EN'i yukarıda tutuyordu. Yalnız INA226 ALERT çıkışı kesebiliyordu.

Çözüm (kullanıcı kararı): U13 SN74LVC1G08DBVR (Özdisan 503098, stok 5805) INA226 bloğunda; A = OUT_EN, B = INA_ALERT, Y -> `SW_EN` -> U12 EN.

- R61 4k7 OUT_EN pull-down: reset boyunca GPIO6 zayıf pull-up'ıyla 3,3 × 4,7 / 49,7 = 0,31 V (< VIL 0,8 V).
- R27 10k ALERT pull-up'ı olarak kaldı; GPIO3 artık doğrudan ALERT'i okuyor.
- R58 100k EN'de kaldı: 3,3 V yokken LVC Ioff ile çıkış yüksek empedans, EN low (AP74502Q'nun iç 3 µA sink'i de aynı yönde).
- R57 kaldırıldı. C35 100n U13 dekuplajı.
- EN yüksek iken 3,3 V (itme-çekme çıkış), eşiğin 2,5 katı.
- Sembol: `Power_Path_Custom:74LVC1G08`, KiCad `74xGxx:74LVC1G08` gövdesiyle 2,54 mm pinli kompakt kopya (orijinali 28 × 20 mm, blok içine sığmıyordu).

Kontrol: beklenen netlist farkı yalnız `SW_EN` (R58.1, U12.1, U13.4), `INA_ALERT` (R27.2, U13.2, U2.26, U3.3), `OUT_EN` (R61.1, U13.1, U2.6) ve +3.3V/GND'ye U13/C35/R61 eklenmesi. ERC 0 hata / 1 uyarı (TL431). Okunabilirlik denetiminde yeni bulgu yok.

### USB-C giriş koruması yeniden ele alındı; AQ3130E eklenmedi (2026-09-22)

Soru: VBUS'ta SMBJ30A varken ESD için AQ3130E-01ETG (ya da Özdisan muadili) eklenmeli mi? AP33772S datasheet'i (DS46176 Rev.10) ile tekrar bakıldı:

- AP33772S CC1/CC2 mutlak maksimum 34 V ve "VBUS short protection on CC1/CC2 up to 34V": konnektörde VBUS'a komşu CC pinlerinin 28 V'a kısa devresine çip kendisi dayanır. Figure 1'de CC hatlarında TVS/ESD elemanı yok; VBUS'ta yalnız 10 µF var.
- **VBUS: ek eleman gerekmez.** 8 kV IEC kontak deşarjı ~1,2 µC (150 pF); C3 2,2 µF / 50 V X5R (28 V'ta ~0,5 µF efektif) R11 5 mΩ üzerinden VBUS'ta, sıçrama ~2,4 V. SMBJ30A (VRWM 30 V, VC 48,4 V @12,4 A) surge için kalır. 28 V'ta iletmeyip 34 V altında kırpan TVS fiziksel olarak yok; 28 V/3 A tepe ölçümü prototip listesinde.
- **CC hatlarında hata vardı:** CC1/CC2 5,5 V'luk U10 TPD4EUSB30'a bağlıydı. EPR'de CC-VBUS kısa devresinde U10 iletime geçip yanar, AP33772S'nin 34 V dayanımını boşa çıkarır. Orijinal (11.09) tasarımda CC'de 28 V'luk AQ3130E'ler vardı.
- **Rd eksikti:** Figure 1 ve metin CC1/CC2'de harici 5,1 kΩ Rd gösteriyor; dahili Rd değeri hiçbir tabloda yok. Şemada (ve depo geçmişinde) Rd hiç olmamıştı; kaynak sink'i görmez, VBUS açılmazdı.

Uygulanan (kullanıcı onayı, 5 madde):

1. R62/R63 5k1 %1 0402 (HP02WAF5101TCE, Özdisan 603919) CC1/CC2 -> GND.
2. CC1/CC2 U10'dan ayrıldı.
3. D8/D9 SMF30A-TKS (Özdisan 639352, SOD-123FL, VRWM 30 V) CC1/CC2 -> GND, **DNP**. Sıfır biasta ~400 pF (datasheet Fig.6) cReceiver 200–600 pF sınırını AP33772S ile birlikte aşabilir; IEC testi geçmezse ve CC BMC ölçümü uygunsa takılır.
4. VBUS değişmedi; D3 CC1 etiketine yer açmak için 35,56 mm sağa taşındı, açıklaması "600W SMB" olarak düzeltildi. Sayfaya yerleşim notu: D3/C3 J7 dibinde, CC izleri kısa.
5. U10 TPD4EUSB30 (stokta yoktu) -> USBLC6-2SC6 (Özdisan 402751, stok 7375), referans korundu, yalnız D+/D-. Flow-through pin çiftleri (1-6, 3-4) proje sembolünde KiCad 10 `jumper_pin_groups` ile iç bağlı tanımlandı (netlist'te doğrulandı: USB_DM = J7.A7/B7, R3, U10.1, U10.6). VBUS referans pini +3.3V'a (USB_VBUS 28 V olabilir).

Kontrol: beklenen netlist farkı yalnız USB_CC1 (D8.1, J7.A5, R62.1, U1.17), USB_CC2 (D9.1, J7.B5, R63.1, U1.16), USB_DM/DP (U10 pin numaraları), +3.3V'a U10.5, GND'ye R62/R63/D8/D9/U10.2. ERC 0 hata / 1 uyarı (TL431), okunabilirlik 0 bulgu. Betik önce projenin scratchpad kopyasında doğrulandı.

### Ters akım: U12 AP74502Q -> LM74801-Q1 (2026-09-22)

Doğrulama (todo: "AP74502Q'nun ters akım korumasını datasheet'ten doğrula"): **karşılamıyordu.** AP74502Q (DS47093) bir "reverse battery polarity and overvoltage protection controller"dır (LM74502 sınıfı); akım/ileri gerilim algılayan pini yoktur, gate yalnız EN/UVLO, VCAP UVLO ve OV ile kapanır. Çıkış açıkken sırt sırta FET'ler çift yönlü iletir. Ters akım yolu OUT_POS -> şönt -> Q5 -> PD_VBUS_SENSED -> doğrudan adaptör VBUS'ı (Q3 bu yolda değil).

Uygulanan (kullanıcı kararı, seçenek A): U12 = **LM74801QDRRRQ1** (TI SNOSD95C; Özdisan 1044371, stok 912). Referans korundu (`swap_lib`), sembol `Power_Path_Custom:LM74801-Q1` (pinout Table 6-1), footprint `Package_SON:WSON-12-1EP_3x3mm_P0.5mm_EP1.5x2.5mm` (TI DRR0012E land pattern: ped 0,62 x 0,25 @ ±1,39, EP 1,3 x 2,5; KiCad pedleri bunu kapsıyor). EP (RTN) datasheet gereği boşta.

Ortak-source bağlantı (datasheet §9.5.2 / Figure 10-25):

- Q5A (giriş, D1 = PD_VBUS_SENSED) <- **HGATE** (GATE_DRV): yük anahtarı, OV ve EN kesmesi; R54/C30 yavaş açılış ve D6 12 V kırpma korundu. HGATE 55 µA (AP74502Q 60 µA).
- Q5B (çıkış, D2 = SW_OUT) <- **DGATE** (yeni net): ideal diyot. V(A-C) -4,5 mV'ta (-6,4…-1,3) 0,5 µs'de kapanır; 12 mΩ'da ~0,1-0,5 A ters akımda keser, sonra gövde diyotu bloke eder. İleri yönde 177 mV'ta (gövde diyotu) yeniden açılır. LM74800 (lineer regülasyon, sıfır DC ters akım) stokta yok.
- A = OUT = SRC_COMMON, C = SW_OUT, VS/VSNS/SW = V_PRE (CAP = VS + ~13 V; V_PRE pass-through'da ≈ VBUS olduğundan HGATE-OUT ≥ 10 V), CAP-VS = C31 220n, EN = SW_EN (U13), OV = OV_SENSE.
- **OV eşiği**: V(OVR) 1,231 V (1,195-1,267). R55 232k ile 28,9-30,7 V çıkıyordu; 28 V EPR +%5 = 29,4 V'ta yanlış tetikleme riski. R55 **237k** (0402WGF2373TCE, Özdisan 506427): 30,4 V (29,5-31,3 V).
- AP74502Q Özdisan'da stokta değildi; madde tedarik listesinden de düştü.

Kontrol: beklenen netlist farkı DGATE (Q5.4, U12.1), GATE_DRV (Q5.2, D6, R54, U12.8), SRC_COMMON (+U12.2 A, U12.9 OUT), SW_OUT (+U12.12 C), V_PRE (+U12.3/4/10), Net-(U12-CAP) (C31), OV_SENSE (U12.5), SW_EN (U12.6), GND (U12.7), RTN boşta. ERC 0 hata; tek kesişme önceden kabul edilmiş kapı hattı/SRC kesişmesi. V_PRE etiketi ve C32 büyüyen gövdeye yer açmak için sola alındı.

### U12 kılıfı (2026-09-22)

AP74502Q için: Diodes SOT28 önerilen ped 0,45 x 0,9 mm, 0,65 adım, ±1,1 sıra; şemadaki TSOT-23-8_HandSoldering (0,4 mm ped) lehimlenir ama dar, standart TSOT-23-8 uygun olurdu. U12 LM74801'e (WSON-12) geçtiği için madde kapandı.

### C15 hibrit + AOZ1284 kompanzasyonu (2026-09-22)

Datasheet (AOZ1284 Rev 1.0) formülleri: fSW = 500 kHz (R38 100k), VOUT = 0,8 x (1 + 10k2/3k24) = 3,32 V, GEA 200 µA/V, GCS 4,5 A/V. CO ≈ 89 µF (C15 47 µF hibrit + C16 47 µF X5R 1210 @3,3 V ~37 µF + küçük seramikler).

- Eski (R41 12k7, C19 18n): fC ≈ 5 kHz, sıfır 696 Hz (< fC/5), C15 ESR sıfırı 1/(2π·47 µF·60 mΩ) ≈ 56 kHz (fC'nin 10 katı üstünde, ek kutup gerekmez). **Kararlı** ama yavaş: 0,3 A yük basamağında ~100 mV çökme.
- Yeni (kullanıcı kararı): **R41 51k** (0402WGF5102TCE, Özdisan 359892), **C19 15n** (CL05B153KO5NNNC, Özdisan 521922; 12n stokta yok). fC ≈ 20 kHz (< fSW/10), sıfır 208 Hz, ESR sıfırı yine fC üstünde; beklenen çökme ~25 mV. C19'un 18n tedarik sorunu da kapandı.

## Eski ERC ihlalleri (todo: "MEVCUT ERC İHLALLERİ")

### PD_I2C_SDA_5V dangling + R6 pin 2 + Q2 pin 3 bağlı değil (2026-09-17)

Üçü tek hataydı: SDA seviye dönüştürücüsü kopuktu. R6.2 ve Q2.D PD_I2C_SDA_5V'ye bağlandı (SCL tarafı R5/Q1 ile simetrik).

Kontrol (22.09 netlist): `PD_I2C_SDA_5V` = Q2.3 (D), R6.2, U1.4 (SDA); `PD_I2C_SCL_5V` = Q1.3, R5.2, U1.5 (SCL). Simetrik ve bağlı.

### TL431DBZ lib_symbol_mismatch (2026-09-22)

KiCad 10 `Reference_Voltage:TL431DBZ` sembolünde pin uzunlukları 2,54'ten 1,27 mm'ye inmiş ve bir çizgi eklenmiş; pin uç konumları (`at`) aynı. usb_pd_controller'daki `lib_symbols` önbelleği kütüphaneden yenilendi.

Kontrol: netlist farkı yok, U6 render'da değişmeden bağlı. **ERC 0 hata / 0 uyarı** (REV_C'de ilk kez tamamen temiz).

## Depo (todo: "DEPO / LİSANS")

### sym-lib-table'da harici mutlak yol kalmadı

DS1021 kaydı temizlenmişti (2026-09-16). 22.09'da tekrar bakıldı: `hardware/sym-lib-table`'da `/home`, `C:` veya DS1021 geçen kayıt yok.

## Todo'da maddesi olmayan, bu dönemde tamamlanan şema işleri

Ayrıntılar `CHANGES.TXT`'de:

- RTC: RV-3028-C7 + CR2032 → BQ32000DR + Y1 ABS25 kristal + C33 1,5 F süper kapasitör (commit `f0438c3`).
- Özdisan BOM seçimleri tüm sembol alanlarına aktarıldı; onaylı footprint/değer değişiklikleri (commit `f0438c3`). Tablo: `hardware/docs/output/BOM_OZDISAN_REV_C_20260921.xlsx`.
- Ekran: NHD-2.4 → TFT032B018, J3 KLS 30p FPC, boost + CAT4104 yerine Q7/R60 PWM backlight (22.09, henüz commit edilmedi).

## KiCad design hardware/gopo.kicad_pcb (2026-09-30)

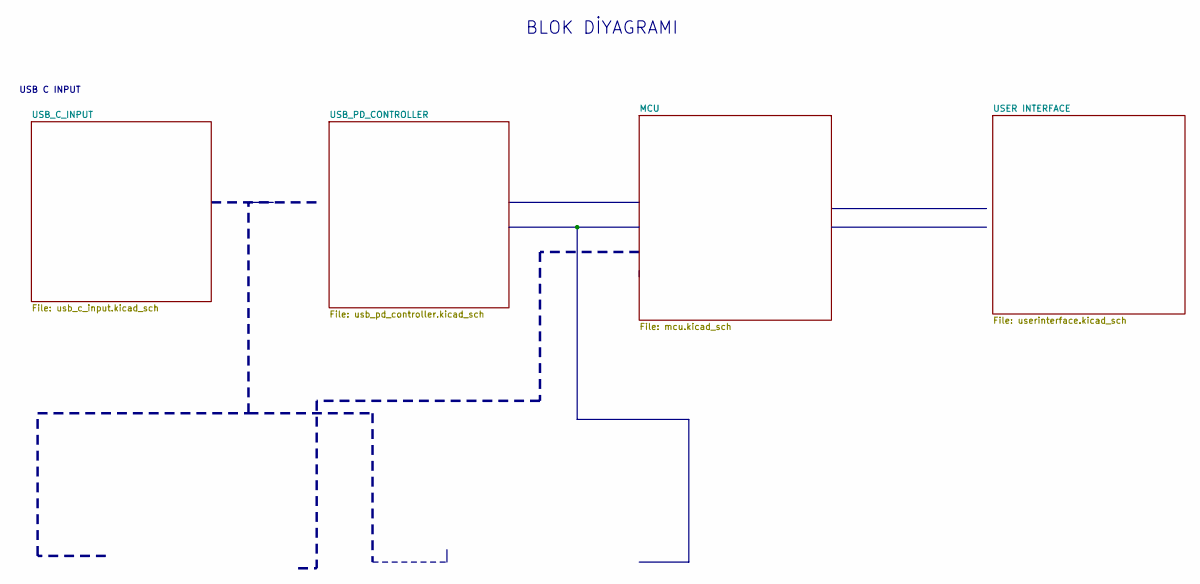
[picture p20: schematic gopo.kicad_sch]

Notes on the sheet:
USB C INPUT
BLOK DİYAGRAMI

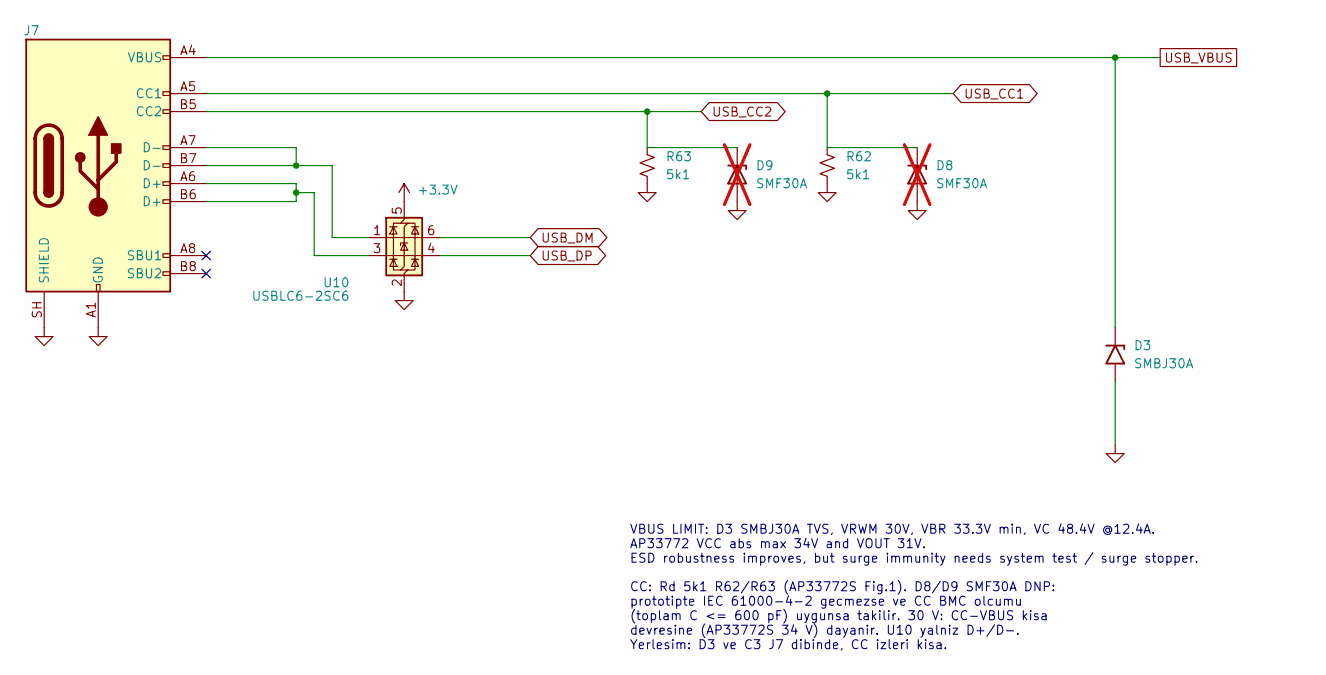
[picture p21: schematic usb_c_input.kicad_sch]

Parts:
D3: SMBJ30A; D_SMB; MPN SMBJ30A-E3/52
D8, D9: SMF30A; D_SOD-123F; MPN SMF30A-TKS; not fitted
J7: USB_C_Receptacle_USB2.0_16P; USB_C_Receptacle_GCT_USB4105-xx-A_16P_TopMnt_Horizontal; VoltageRating TBD; MPN USB4105-GF-A
R62, R63: 5k1; R_0402_1005Metric; Tolerance +/-1%; VoltageRating 50V; MPN HP02WAF5101TCE
U10: USBLC6-2SC6; SOT-23-6; MPN USBLC6-2SC6

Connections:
+3.3V: U10.5 (VBUS); also elsewhere on the board
GND: D3.2 (A2), D8.2 (A), D9.2 (A), J7.A1 (GND), J7.A12 (GND), J7.B1 (GND), J7.B12 (GND), J7.SH (SHIELD), R62.2, R63.2, U10.2 (GND); also elsewhere on the board
USB_CC1: D8.1 (K), J7.A5 (CC1), R62.1; also elsewhere on the board
USB_CC2: D9.1 (K), J7.B5 (CC2), R63.1; also elsewhere on the board
USB_VBUS: D3.1 (A1), J7.A4 (VBUS), J7.A9 (VBUS), J7.B4 (VBUS), J7.B9 (VBUS); also elsewhere on the board

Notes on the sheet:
VBUS LIMIT: D3 SMBJ30A TVS, VRWM 30V, VBR 33.3V min, VC 48.4V @12.4A. AP33772 VCC abs max 34V and VOUT 31V. ESD robustness improves, but surge immunity needs system test / surge stopper.
CC: Rd 5k1 R62/R63 (AP33772S Fig.1). D8/D9 SMF30A DNP: prototipte IEC 61000-4-2 gecmezse ve CC BMC olcumu (toplam C <= 600 pF) uygunsa takilir. 30 V: CC-VBUS kisa devresine (AP33772S 34 V) dayanir. U10 yalniz D+/D-. Yerlesim: D3 ve C3 J7 dibinde, CC izleri kisa.

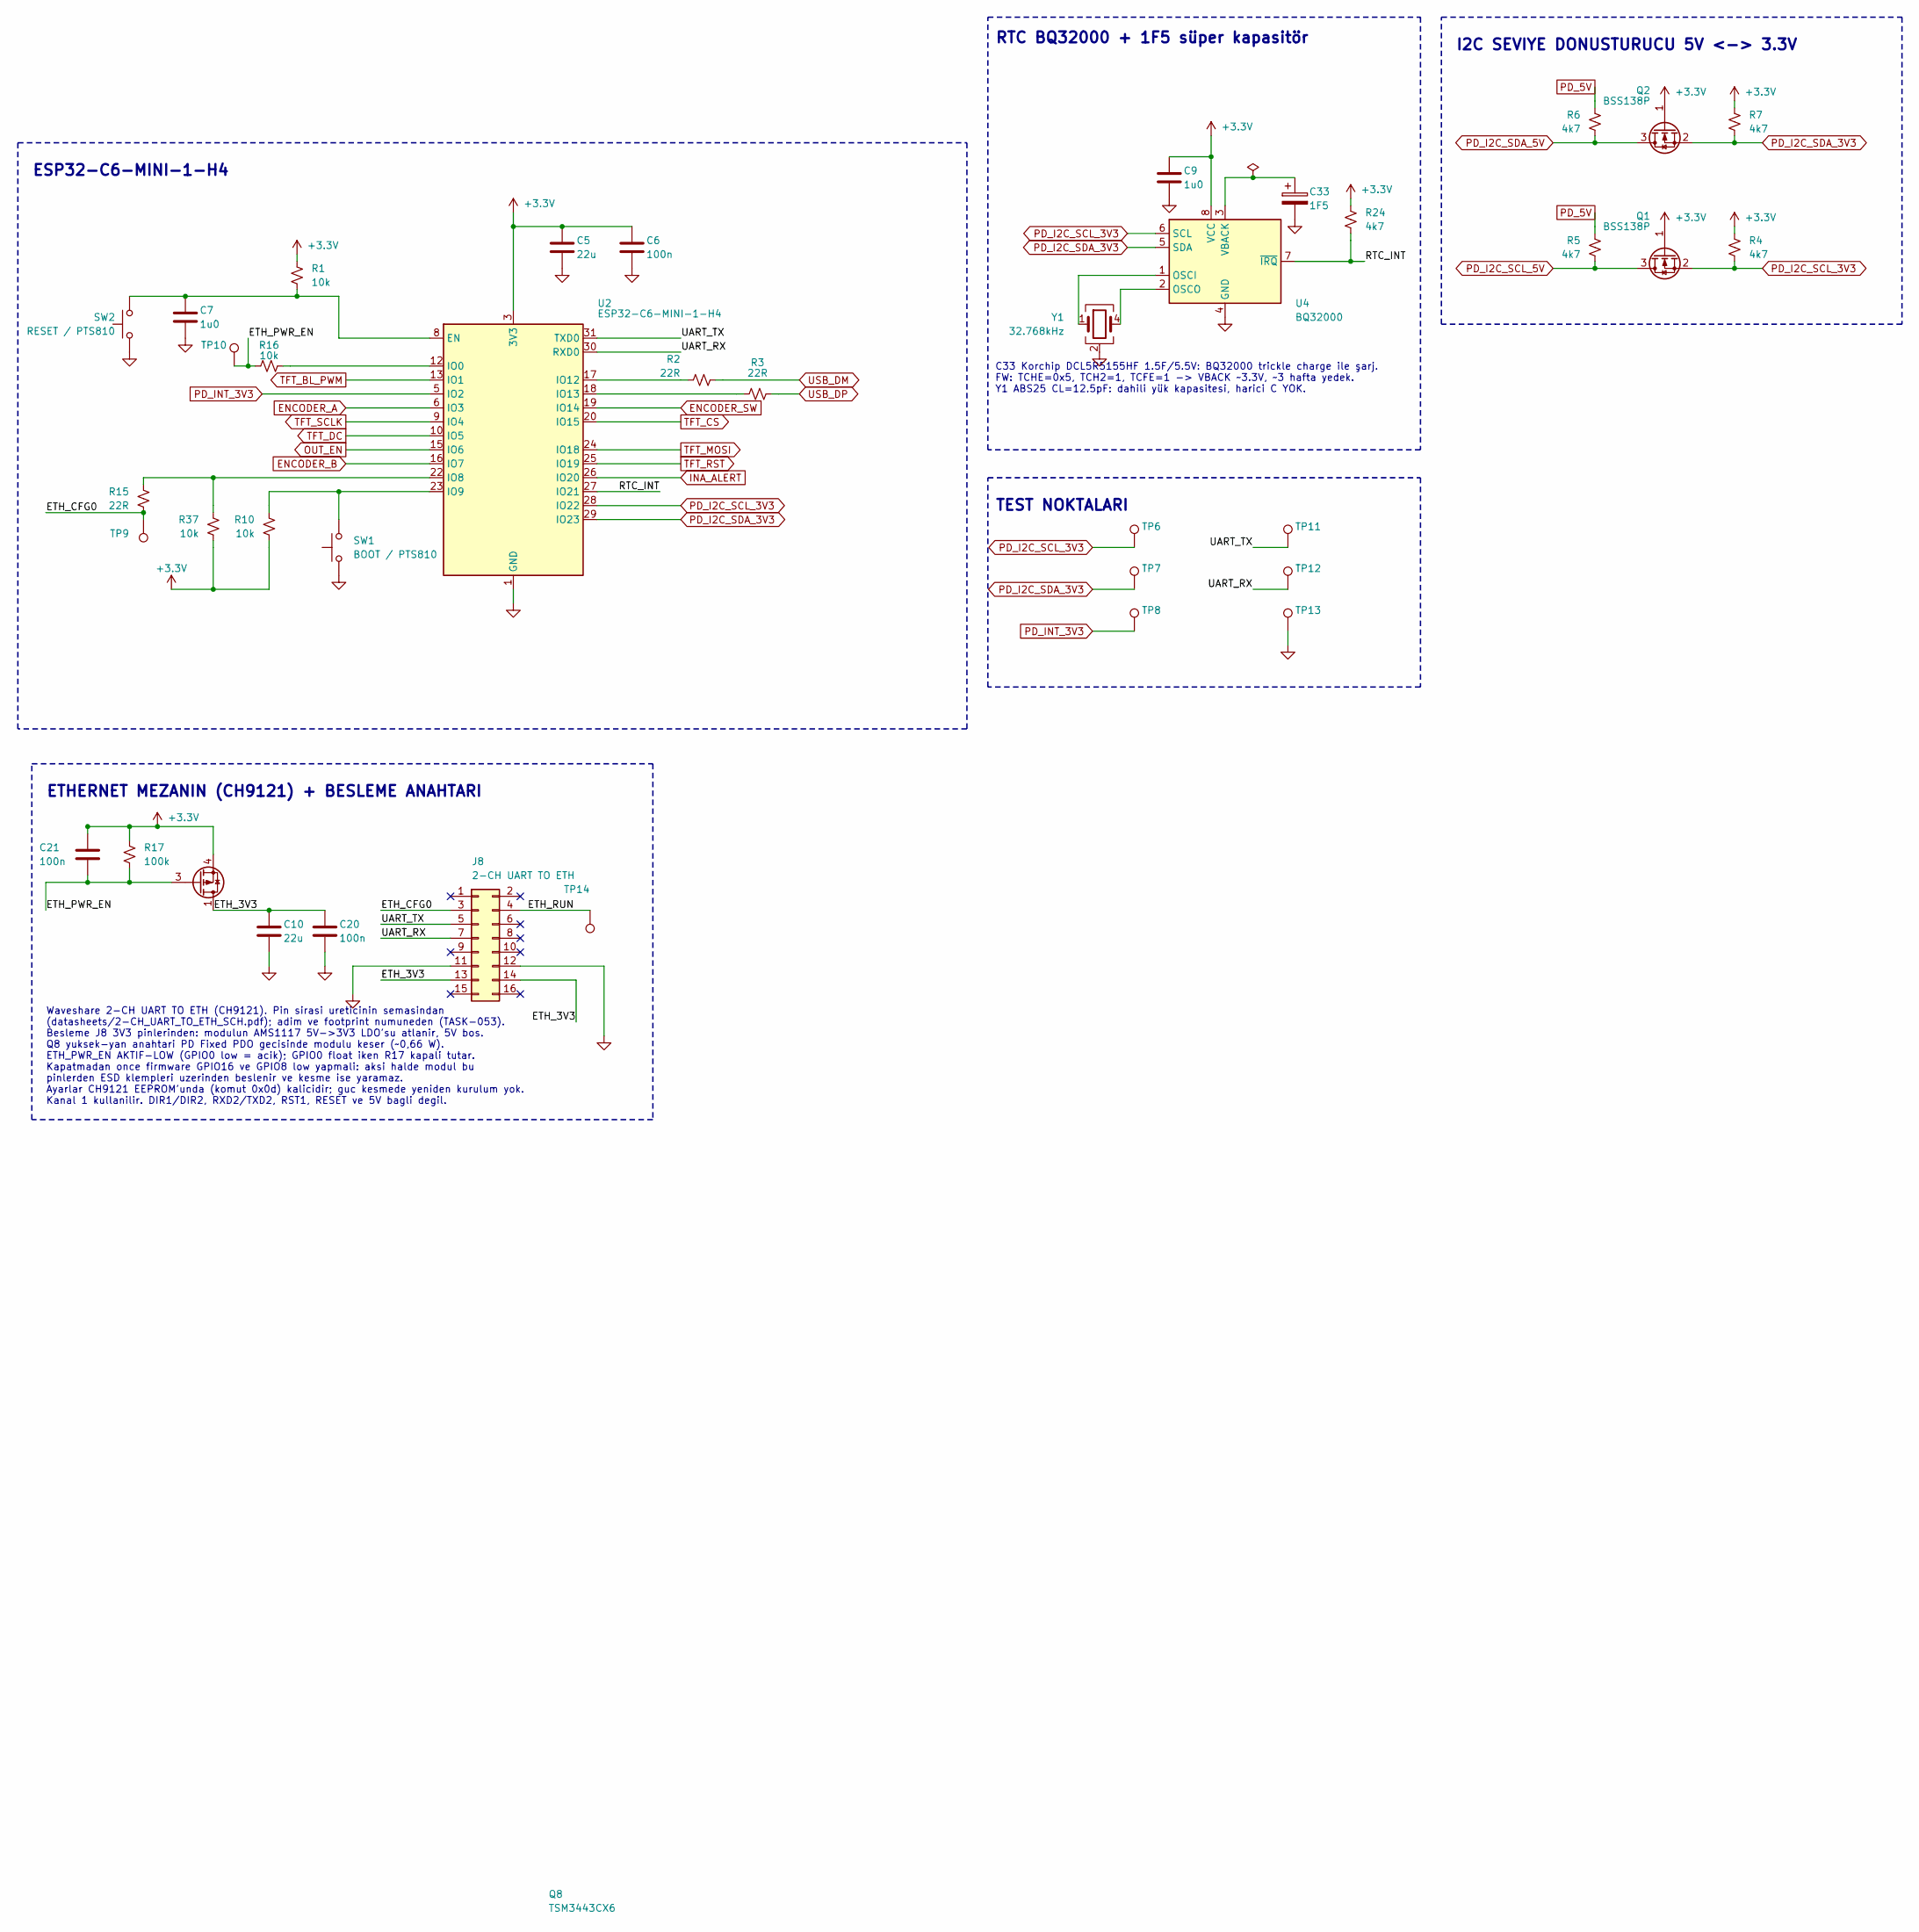
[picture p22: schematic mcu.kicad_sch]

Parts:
C5, C10: 22u; C_0805_2012Metric; Tolerance +/-20%; VoltageRating 10V; MPN GRT21BC81A226ME13K
C6, C20, C21: 100n; C_0402_1005Metric; Tolerance +/-10%; VoltageRating 50V; MPN CC0402KRX7R9BB104
C7, C9: 1u0; C_0402_1005Metric; Tolerance +/-10%; VoltageRating 16V; MPN EMK105BJ105KVHF
C33: 1F5; Korchip_DCL_H-Type_D19.0mm_P20.00mm_Horizontal; VoltageRating 5.5V; Tolerance -20%/+80%; MPN DCL5R5155HF
J8: 2-CH UART TO ETH; Waveshare_2-CH_UART_TO_ETH; VoltageRating TBD; MPN TBD
Q1, Q2: BSS138P; SOT-23; VoltageDS 60V; MPN BSS138P,215
Q8: TSM3443CX6; SOT-23-6; MPN TSM3443CX6 RF
R1, R10, R37: 10k; R_0402_1005Metric; Tolerance +/-0.1%; VoltageRating 25V; MPN TC0250B1002TCC
R2, R3, R15: 22R; R_0402_1005Metric; Tolerance +/-1%; VoltageRating 50V; MPN RC0402FR-0722RP
R4, R5, R6, R7, R24: 4k7; R_0402_1005Metric; Tolerance +/-1%; VoltageRating 50V; MPN HP02WAF4701TCE
R16: 10k; R_0402_1005Metric; Tolerance +/-1%; VoltageRating 50V; MPN TC0250B1002TCC
R17: 100k; R_0402_1005Metric; Tolerance +/-1%; VoltageRating 50V; MPN 0402WGF1003TCE
SW1: BOOT / PTS810; SW_SPST_PTS810; MPN PTS810 SJS 250 SMTR LFS
SW2: RESET / PTS810; SW_SPST_PTS810; MPN PTS810 SJS 250 SMTR LFS
TP6, TP7, TP8, TP9, TP10, TP11, TP12, TP13, TP14: TestPoint; TestPoint_Pad_D1.0mm; MPN N/A
U2: ESP32-C6-MINI-1-H4; ESP32-C6-MINI-1; MPN ESP32-C6-MINI-1-H4
U4: BQ32000; SOIC-8_3.9x4.9mm_P1.27mm; MPN BQ32000DR
Y1: 32.768kHz; Crystal_SMD_Abracon_ABS25-4Pin_8.0x3.8mm; MPN ABS25-32.768KHZ-T

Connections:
+3.3V: C5.1, C6.1, C9.1, C21.1, Q1.1 (G), Q2.1 (G), Q8.4 (S), R1.1, R4.2, R7.1, R10.2, R17.1, R24.1, R37.2, U2.3 (3V3), U4.8 (VCC); also elsewhere on the board
/MCU/ETH_3V3: C10.1, C20.1, J8.13, J8.14, Q8.1 (D), Q8.2 (D), Q8.5 (D), Q8.6 (D)
/MCU/ETH_CFG0: J8.3, R15.2, TP9.1 (1_1)
/MCU/ETH_PWR_EN: C21.2, Q8.3 (G), R16.1, R17.2, TP10.1 (1_1)
/MCU/ETH_RUN: J8.4, TP14.1
/MCU/RTC_INT: R24.2, U2.27 (IO21), U4.7 (~IRQ)
/MCU/UART_RX: J8.7, TP12.1, U2.30 (RXD0)
/MCU/UART_TX: J8.5, TP11.1, U2.31 (TXD0)
ENCODER_A: U2.6 (IO3); also elsewhere on the board
ENCODER_B: U2.16 (IO7); also elsewhere on the board
ENCODER_SW: U2.19 (IO14); also elsewhere on the board
GND: C5.2, C6.2, C7.1, C9.2, C10.2, C20.2, C33.2, J8.11, J8.12, SW1.1, SW2.1, TP13.1, U2.1 (GND), U2.2 (GND), U2.11 (GND), U2.14 (GND), U2.36 (GND), U2.37 (GND), U2.38 (GND), U2.39 (GND), U2.40 (GND), U2.41 (GND), U2.42 (GND), U2.43 (GND), U2.44 (GND), U2.45 (GND), U2.46 (GND), U2.47 (GND), U2.48 (GND), U2.49 (GND), U2.50 (GND), U2.51 (GND), U2.52 (GND), U2.53 (GND), U4.4 (GND), Y1.2 (G), Y1.3 (G); also elsewhere on the board
INA_ALERT: U2.26 (IO20); also elsewhere on the board
unnamed: C7.2, R1.2, SW2.2, U2.8 (EN)
unnamed: R16.2, U2.12 (IO0)
unnamed: R15.1, R37.1, U2.22 (IO8)
unnamed: R10.1, SW1.2, U2.23 (IO9)
unnamed: R2.1, U2.17 (IO12)
unnamed: R3.1, U2.18 (IO13)
unnamed: U4.1 (OSCI), Y1.1
unnamed: U4.2 (OSCO), Y1.4
unnamed: C33.1, U4.3 (VBACK)
OUT_EN: U2.15 (IO6); also elsewhere on the board
PD_5V: R5.1, R6.1; also elsewhere on the board
PD_I2C_SCL_3V3: Q1.2 (S), R4.1, TP6.1 (1_1), U2.28 (IO22), U4.6 (SCL); also elsewhere on the board
PD_I2C_SCL_5V: Q1.3 (D), R5.2; also elsewhere on the board
PD_I2C_SDA_3V3: Q2.2 (S), R7.2, TP7.1 (1_1), U2.29 (IO23), U4.5 (SDA); also elsewhere on the board
PD_I2C_SDA_5V: Q2.3 (D), R6.2; also elsewhere on the board
PD_INT_3V3: TP8.1 (1_1), U2.5 (IO2); also elsewhere on the board
TFT_BL_PWM: U2.13 (IO1); also elsewhere on the board
TFT_CS: U2.20 (IO15); also elsewhere on the board
TFT_DC: U2.10 (IO5); also elsewhere on the board
TFT_MOSI: U2.24 (IO18); also elsewhere on the board
TFT_RST: U2.25 (IO19); also elsewhere on the board
TFT_SCLK: U2.9 (IO4); also elsewhere on the board

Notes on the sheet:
TEST NOKTALARI
RTC BQ32000 + 1F5 süper kapasitör
C33 Korchip DCL5R5155HF 1.5F/5.5V: BQ32000 trickle charge ile şarj. FW: TCHE=0x5, TCH2=1, TCFE=1 -> VBACK ~3.3V, ~3 hafta yedek. Y1 ABS25 CL=12.5pF: dahili yük kapasitesi, harici C YOK.
ESP32-C6-MINI-1-H4
I2C SEVIYE DONUSTURUCU 5V <-> 3.3V
ETHERNET MEZANIN (CH9121) + BESLEME ANAHTARI
Waveshare 2-CH UART TO ETH (CH9121). Pin sirasi ureticinin semasindan (datasheets/2-CH_UART_TO_ETH_SCH.pdf); adim ve footprint numuneden (TASK-053). Besleme J8 3V3 pinlerinden: modulun AMS1117 5V->3V3 LDO'su atlanir, 5V bos. Q8 yuksek-yan anahtari PD Fixed PDO gecisinde modulu keser (~0,66 W). ETH_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

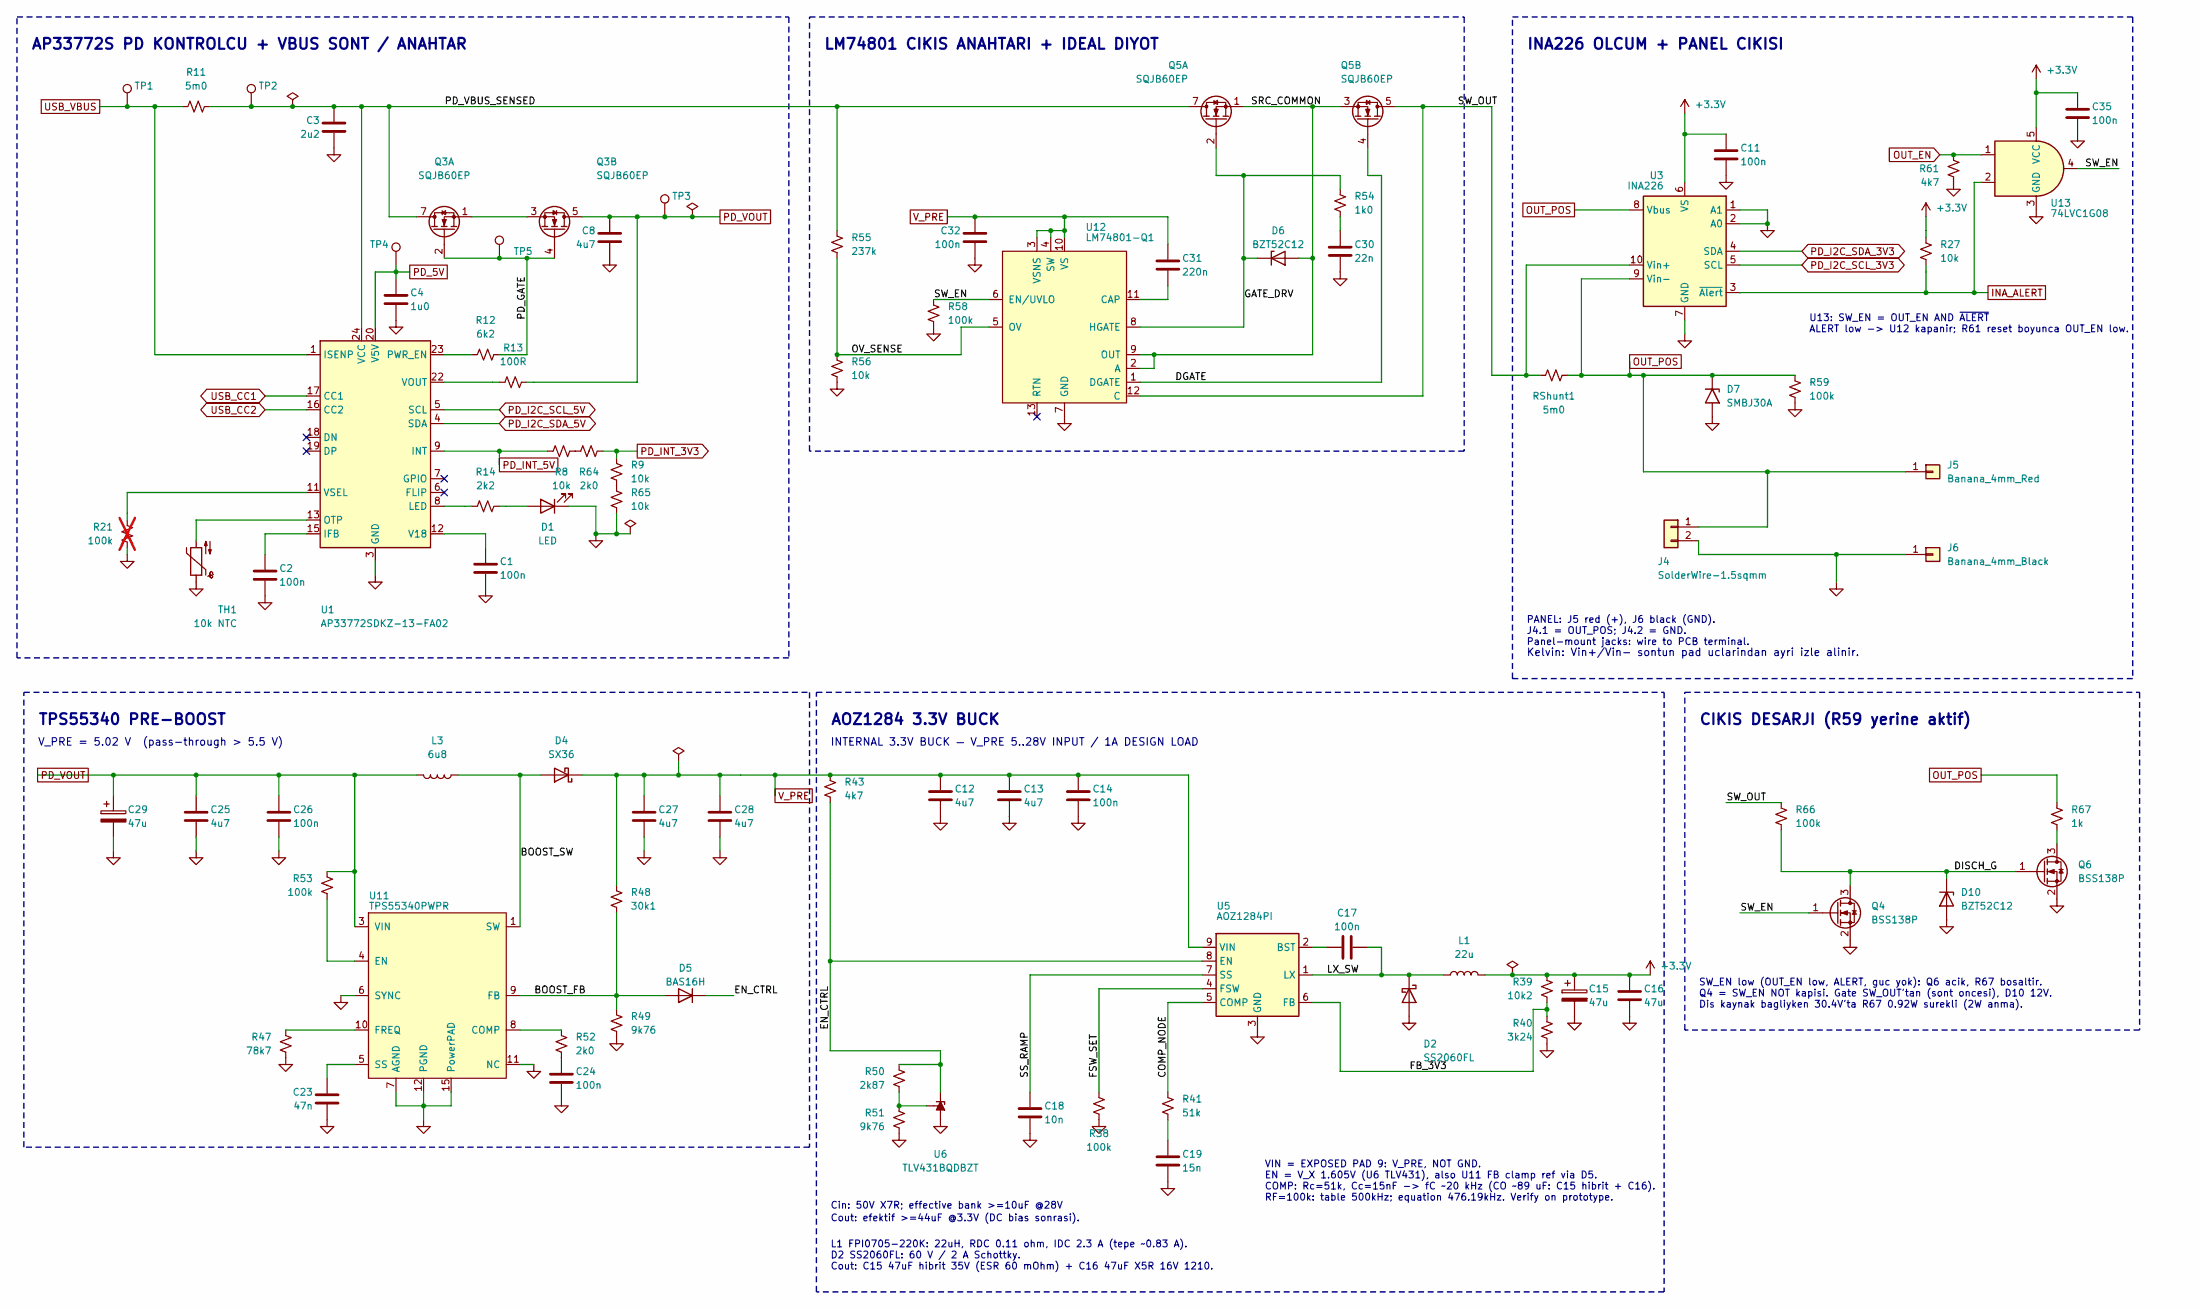
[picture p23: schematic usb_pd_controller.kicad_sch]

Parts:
C1, C2, C11, C14, C17, C24, C26, C32, C35: 100n; C_0402_1005Metric; Tolerance +/-10%; VoltageRating 50V; MPN CC0402KRX7R9BB104
C3: 2u2; C_0805_2012Metric; Tolerance +/-10%; VoltageRating 50V; MPN CL21A225KB9LNNC
C4: 1u0; C_0402_1005Metric; Tolerance +/-10%; VoltageRating 16V; MPN EMK105BJ105KVHF
C8, C12, C13, C25, C27, C28: 4u7; C_1210_3225Metric; Tolerance +/-10%; VoltageRating 50V; MPN CL32B475KBJNNNE
C15, C29: 47u; CP_Elec_6.3x5.8; VoltageRating 35V; Tolerance +/-20%; MPN EEHZA1V470P
C16: 47u; C_1210_3225Metric; Tolerance +/-10%; VoltageRating 16V; MPN CL32A476KOJNNNE
C18: 10n; C_0402_1005Metric; Tolerance +/-10%; VoltageRating 25V; MPN CL05B103KA5NNNC
C19: 15n; C_0402_1005Metric; Tolerance +/-10%; VoltageRating 16V; MPN CL05B153KO5NNNC
C23: 47n; C_0402_1005Metric; Tolerance +/-10%; VoltageRating 16V; MPN CL05B473KO5NNNC
C30: 22n; C_0402_1005Metric; Tolerance +/-10%; VoltageRating 50V; MPN CC0402KRX7R9BB223
C31: 220n; C_0603_1608Metric; Tolerance +/-10%; VoltageRating 25V; MPN CL10B224KA8NNNC
D1: LED; LED_0402_1005Metric; MPN APHHS1005SURCK
D2: SS2060FL; D_SOD-123F; MPN SS2060FL_R1_00001
D4: SX36; D_SMA; MPN SX36_R1_00001
D5: BAS16H; D_SOD-323; MPN BAS16HT1G
D6, D10: BZT52C12; D_SOD-123; MPN BZT52-C12_R1_00001
D7: SMBJ30A; D_SMB; MPN SMBJ30A-E3/52
J4: SolderWire-1.5sqmm; SolderWire-1.5sqmm_1x02_P7.8mm_D1.7mm_OD3.9mm; VoltageRating TBD; MPN N/A (PCB pedi)
J5: Banana_4mm_Red; Cinch_108-0902-001_Panel; VoltageRating TBD; MPN KOM.KNN.06.000021
J6: Banana_4mm_Black; Cinch_108-0903-001_Panel; VoltageRating TBD; MPN KOM.KNN.06.000022
L1: 22u; L_CoreMaster_FPI0705_7.8x7.0mm_H5.0; Tolerance TBD; MPN FPI0705-220K
L3: 6u8; L_7.3x7.3_H4.5; Tolerance TBD; MPN SRI0704-6R8M
Q3, Q5: SQJB60EP; Vishay_PowerPAK_SO-8L_Dual; VoltageDS 60V; MPN SQJB60EP-T1_GE3
Q4, Q6: BSS138P; SOT-23; VoltageDS 60V; MPN BSS138P,215
R8, R9, R27, R56, R65: 10k; R_0402_1005Metric; Tolerance +/-0.1%; VoltageRating 25V; MPN TC0250B1002TCC
R11: 5m0; R_2512_6332Metric; Tolerance +/-1%; VoltageRating N/A; MPN BVT-I-R005-1.0
R12: 6k2; R_0402_1005Metric; Tolerance +/-1%; VoltageRating 50V; MPN 0402WGF6201TCE
R13: 100R; R_0402_1005Metric; Tolerance +/-0.1%; VoltageRating 25V; MPN TC0250B1000TCC
R14: 2k2; R_0402_1005Metric; Tolerance +/-1%; VoltageRating 50V; MPN ERJ2RKF2201X
R21: 100k; R_0402_1005Metric; Tolerance +/-1%; VoltageRating 50V; MPN CQ02WGF1003TCE; not fitted
R38, R53, R58: 100k; R_0402_1005Metric; Tolerance +/-1%; VoltageRating 50V; MPN CQ02WGF1003TCE
R39: 10k2; R_0402_1005Metric; Tolerance +/-1%; VoltageRating 50V; MPN RC1005F1022CS
R40: 3k24; R_0402_1005Metric; Tolerance +/-1%; VoltageRating 50V; MPN ERJ2RKF3241X
R41: 51k; R_0402_1005Metric; Tolerance +/-1%; VoltageRating 50V; MPN 0402WGF5102TCE
R43: 4k7; R_2512_6332Metric; Tolerance +/-1%; VoltageRating 200V; MPN CQ121WF4701T4E
R47: 78k7; R_0402_1005Metric; Tolerance +/-1%; VoltageRating 50V; MPN 0402WGF7872TCE
R48: 30k1; R_0402_1005Metric; Tolerance +/-1%; VoltageRating 50V; MPN 0402WGF3012TCE
R49, R51: 9k76; R_0402_1005Metric; Tolerance +/-1%; VoltageRating 50V; MPN 0402WGF9761TCE
R50: 2k87; R_0402_1005Metric; Tolerance +/-1%; VoltageRating 50V; MPN 0402WGF2871TCE
R52, R64: 2k0; R_0402_1005Metric; Tolerance +/-1%; VoltageRating 50V; MPN ERJ2RKF2001X
R54: 1k0; R_0402_1005Metric; Tolerance +/-0.1%; VoltageRating 50V; MPN RT0402BRD071KL
R55: 237k; R_0402_1005Metric; Tolerance +/-1%; VoltageRating 50V; MPN 0402WGF2373TCE
R59, R66: 100k; R_0603_1608Metric; Tolerance +/-1%; VoltageRating 75V; MPN CRCW0603100KFKTBBC
R61: 4k7; R_0402_1005Metric; Tolerance +/-1%; VoltageRating 50V; MPN HP02WAF4701TCE
R67: 1k; R_2512_6332Metric; Tolerance +/-1%; VoltageRating 500V; MPN PS122WF1001T4E
RShunt1: 5m0; R_2512_6332Metric; Tolerance +/-1%; VoltageRating N/A; MPN BVT-I-R005-1.0
TH1: 10k NTC; R_0402_1005Metric; MPN TSM0B103F3381RZ
TP1, TP2, TP3, TP4, TP5: TestPoint; TestPoint_Pad_D1.0mm; MPN N/A
U1: AP33772SDKZ-13-FA02; Texas_RTW_WQFN-24-1EP_4x4mm_P0.5mm_EP2.7x2.7mm; MPN AP33772SDKZ-13-FA02
U3: INA226; TSSOP-10_3x3mm_P0.5mm; MPN INA226AIDGSR
U5: AOZ1284PI; SOIC-8-1EP_3.9x4.9mm_P1.27mm_EP2.71x3.7mm; MPN AOZ1284PI
U6: TLV431BQDBZT; SOT-23; MPN TLV431BQDBZT
U11: TPS55340PWPR; Texas_HTSSOP-14-1EP_4.4x5mm_P0.65mm_EP3.4x5mm_Mask3.155x3.2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; MPN TPS55340PWPR
U12: LM74801-Q1; WSON-12-1EP_3x3mm_P0.5mm_EP1.5x2.5mm; MPN LM74801QDRRRQ1
U13: 74LVC1G08; SOT-23-5; MPN SN74LVC1G08DBVR

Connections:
+3.3V: C11.1, C15.1, C16.1, C35.1, L1.2, R27.1, R39.1, U3.6 (VS), U13.5 (VCC); also elsewhere on the board
/USB_PD_CONTROLLER/BOOST_FB: D5.2 (A), R48.2, R49.1, U11.9 (FB)
/USB_PD_CONTROLLER/BOOST_SW: D4.2 (A), L3.1, U11.1 (SW), U11.2 (SW)
/USB_PD_CONTROLLER/COMP_NODE: R41.1, U5.5 (COMP)
/USB_PD_CONTROLLER/DGATE: Q5.4 (G), U12.1 (DGATE)
/USB_PD_CONTROLLER/DISCH_G: D10.1 (K), Q4.3 (D), Q6.1 (G), R66.2
/USB_PD_CONTROLLER/EN_CTRL: D5.1 (K), R43.2, R50.1, U5.8 (EN), U6.2 (REF)
/USB_PD_CONTROLLER/FB_3V3: R39.2, R40.1, U5.6 (FB)
/USB_PD_CONTROLLER/FSW_SET: R38.1, U5.4 (FSW)
/USB_PD_CONTROLLER/GATE_DRV: D6.1 (K), Q5.2 (G), R54.1, U12.8 (HGATE)
/USB_PD_CONTROLLER/LX_SW: C17.2, D2.1 (K), L1.1, U5.1 (LX)
/USB_PD_CONTROLLER/OV_SENSE: R55.2, R56.1, U12.5 (OV)
/USB_PD_CONTROLLER/PD_GATE: Q3.2 (G), Q3.4 (G), R12.2, TP5.1 (1_1)
/USB_PD_CONTROLLER/PD_VBUS_SENSED: C3.1, Q3.7 (D), Q3.8 (D), Q5.7 (D), Q5.8 (D), R11.2, R55.1, TP2.1 (1_1), U1.24 (VCC)
/USB_PD_CONTROLLER/SRC_COMMON: D6.2 (A), Q5.1 (S), Q5.3 (S), U12.2 (A), U12.9 (OUT)
/USB_PD_CONTROLLER/SS_RAMP: C18.1, U5.7 (SS)
/USB_PD_CONTROLLER/SW_EN: Q4.1 (G), R58.1, U12.6 (EN/UVLO), U13.4
/USB_PD_CONTROLLER/SW_OUT: Q5.5 (D), Q5.6 (D), R66.1, RShunt1.1, U3.10 (Vin+), U12.12 (C)
GND: C1.2, C2.2, C3.2, C4.2, C8.2, C11.2, C12.2, C13.2, C14.2, C15.2, C16.2, C18.2, C19.2, C23.2, C24.2, C25.2, C26.2, C27.2, C28.2, C29.2, C30.2, C32.2, C35.2, D1.1 (K), D2.2 (A), D7.2 (A2), D10.2 (A), J4.2, J6.1, Q4.2 (S), Q6.2 (S), R21.1, R38.2, R40.2, R47.2, R49.2, R51.2, R56.2, R58.2, R59.2, R61.2, R65.2, TH1.1, U1.3 (GND), U1.25 (GND), U3.1 (A1), U3.2 (A0), U3.7 (GND), U5.3 (GND), U6.3 (A), U11.6 (SYNC), U11.7 (AGND), U11.11 (NC), U11.12 (PGND), U11.13 (PGND), U11.14 (PGND), U11.15 (PowerPAD), U12.7 (GND), U13.3 (GND); also elsewhere on the board
INA_ALERT: R27.2, U3.3 (~Alert), U13.2; also elsewhere on the board
unnamed: C19.1, R41.2
unnamed: C24.1, R52.2
unnamed: C30.1, R54.2
unnamed: D1.2 (A), R14.2
unnamed: Q3.1 (S), Q3.3 (S)
unnamed: Q6.3 (D), R67.2
unnamed: R8.2, R64.1
unnamed: R9.2, R65.1
unnamed: C2.1, U1.15 (IFB)
unnamed: R14.1, U1.8 (LED)
unnamed: TH1.2, U1.13 (OTP)
unnamed: R12.1, U1.23 (PWR_EN)
unnamed: C1.1, U1.12 (V18)
unnamed: R13.1, U1.22 (VOUT)
unnamed: R21.2, U1.11 (VSEL)
unnamed: C17.1, U5.2 (BST)
unnamed: R50.2, R51.1, U6.1 (K)
unnamed: R52.1, U11.8 (COMP)
unnamed: R53.2, U11.4 (EN)
unnamed: R47.1, U11.10 (FREQ)
unnamed: C23.1, U11.5 (SS)
unnamed: C31.2, U12.11 (CAP)
OUT_EN: R61.1, U13.1; also elsewhere on the board
OUT_POS: D7.1 (A1), J4.1, J5.1, R59.1, R67.1, RShunt1.2, U3.8 (Vbus), U3.9 (Vin-)
PD_5V: C4.1, TP4.1 (1_1), U1.20 (V5V); also elsewhere on the board
PD_I2C_SCL_3V3: U3.5 (SCL); also elsewhere on the board
PD_I2C_SCL_5V: U1.5 (SCL); also elsewhere on the board
PD_I2C_SDA_3V3: U3.4 (SDA); also elsewhere on the board
PD_I2C_SDA_5V: U1.4 (SDA); also elsewhere on the board
PD_INT_3V3: R9.1, R64.2; also elsewhere on the board
PD_INT_5V: R8.1, U1.9 (INT)
PD_VOUT: C8.1, C25.1, C26.1, C29.1, L3.2, Q3.5 (D), Q3.6 (D), R13.2, R53.1, TP3.1 (1_1), U11.3 (VIN)
USB_CC1: U1.17 (CC1); also elsewhere on the board
USB_CC2: U1.16 (CC2); also elsewhere on the board
USB_VBUS: R11.1, TP1.1 (1_1), U1.1 (ISENP); also elsewhere on the board
V_PRE: C12.1, C13.1, C14.1, C27.1, C28.1, C31.1, C32.1, D4.1 (K), R43.1, R48.1, U5.9 (VIN), U12.3 (VSNS), U12.4 (SW), U12.10 (VS)

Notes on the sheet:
V_PRE = 5.02 V (pass-through > 5.5 V)
AP33772S PD KONTROLCU + VBUS SONT / ANAHTAR
TPS55340 PRE-BOOST
Kelvin: Vin+/Vin- sontun pad uclarindan ayri izle alinir.
Cin: 50V X7R; effective bank >=10uF @28V
AOZ1284 3.3V BUCK
INA226 OLCUM + PANEL CIKISI
PANEL: J5 red (+), J6 black (GND). J4.1 = OUT_POS; J4.2 = GND. Panel-mount jacks: wire to PCB terminal.
U13: SW_EN = OUT_EN AND ~{ALERT} ALERT low -> U12 kapanir; R61 reset boyunca OUT_EN low.
LM74801 CIKIS ANAHTARI + IDEAL DIYOT
VIN = EXPOSED PAD 9: V_PRE, NOT GND. EN = V_X 1.605V (U6 TLV431), also U11 FB clamp ref via D5. COMP: Rc=51k, Cc=15nF -> fC ~20 kHz (CO ~89 uF: C15 hibrit + C16). RF=100k: table 500kHz; equation 476.19kHz. Verify on prototype.
INTERNAL 3.3V BUCK — V_PRE 5..28V INPUT / 1A DESIGN LOAD
Cout: efektif >=44uF @3.3V (DC bias sonrasi).
L1 FPI0705-220K: 22uH, RDC 0.11 ohm, IDC 2.3 A (tepe ~0.83 A). D2 SS2060FL: 60 V / 2 A Schottky. Cout: C15 47uF hibrit 35V (ESR 60 mOhm) + C16 47uF X5R 16V 1210.
CIKIS DESARJI (R59 yerine aktif)
SW_EN low (OUT_EN low, ALERT, guc yok): Q6 acik, R67 bosaltir. Q4 = SW_EN NOT kapisi. Gate SW_OUT'tan (sont oncesi), D10 12V. Dis kaynak bagliyken 30.4V'ta R67 0.92W surekli (2W anma).

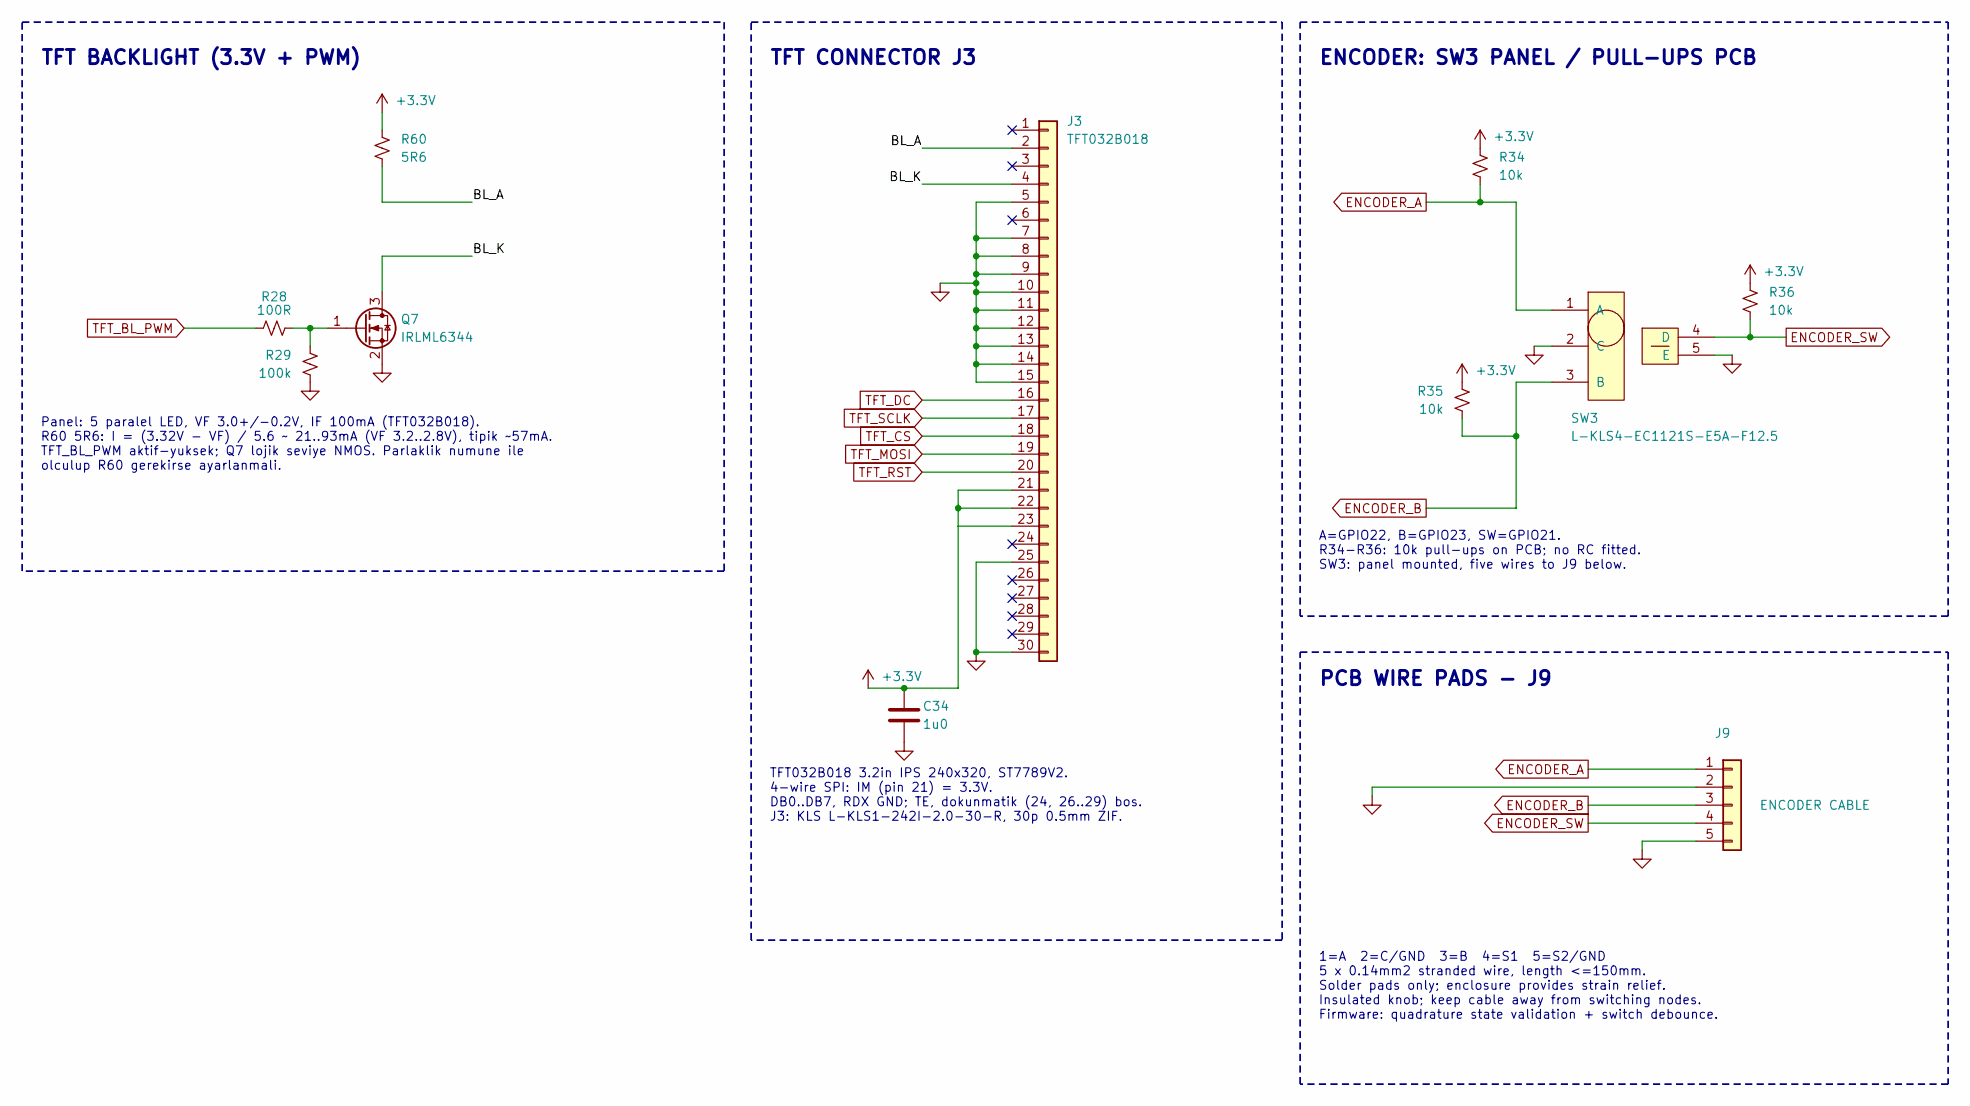
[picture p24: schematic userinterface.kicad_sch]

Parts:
C34: 1u0; C_0402_1005Metric; Tolerance +/-10%; VoltageRating 16V; MPN EMK105BJ105KVHF
J3: TFT032B018; KLS_L-KLS1-242I-2.0-30_1x30-2MP_P0.50mm_Horizontal; VoltageRating 50V; MPN L-KLS1-242I-2.0-30-R
J9: ENCODER CABLE; SolderWire-0.25sqmm_1x05_P4.2mm_D0.65mm_OD1.7mm; MPN N/A - PCB solder pads
Q7: IRLML6344; SOT-23; VoltageDS 30V; MPN IRLML6344TRPBF
R28: 100R; R_0402_1005Metric; Tolerance +/-0.1%; VoltageRating 25V; MPN TC0250B1000TCC
R29: 100k; R_0402_1005Metric; Tolerance +/-1%; VoltageRating 50V; MPN CQ02WGF1003TCE
R34, R35, R36: 10k; R_0402_1005Metric; Tolerance +/-0.1%; VoltageRating 25V; MPN TC0250B1002TCC
R60: 5R6; R_0805_2012Metric; Tolerance +/-5%; VoltageRating 150V; MPN CRT05J7F5R60
SW3: L-KLS4-EC1121S-E5A-F12.5; MPN L-KLS4-EC1121S-E5A-F12.5

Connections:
+3.3V: C34.1, J3.21, J3.22, J3.23, R34.1, R35.1, R36.1, R60.1; also elsewhere on the board
/USER INTERFACE/BL_A: J3.2, R60.2
/USER INTERFACE/BL_K: J3.4, Q7.3 (D)
ENCODER_A: J9.1, R34.2, SW3.1 (A); also elsewhere on the board
ENCODER_B: J9.3, R35.2, SW3.3 (B); also elsewhere on the board
ENCODER_SW: J9.4, R36.2, SW3.4 (D); also elsewhere on the board
GND: C34.2, J3.5, J3.7, J3.8, J3.9, J3.10, J3.11, J3.12, J3.13, J3.14, J3.15, J3.25, J3.30, J9.2, J9.5, Q7.2 (S), R29.2, SW3.2 (C), SW3.5 (E); also elsewhere on the board
unnamed: Q7.1 (G), R28.2, R29.1
TFT_BL_PWM: R28.1; also elsewhere on the board
TFT_CS: J3.18; also elsewhere on the board
TFT_DC: J3.16; also elsewhere on the board
TFT_MOSI: J3.19; also elsewhere on the board
TFT_RST: J3.20; also elsewhere on the board
TFT_SCLK: J3.17; also elsewhere on the board

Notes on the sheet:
TFT CONNECTOR J3
TFT BACKLIGHT (3.3V + PWM)
Panel: 5 paralel LED, VF 3.0+/-0.2V, IF 100mA (TFT032B018). R60 5R6: I = (3.32V - VF) / 5.6 ~ 21..93mA (VF 3.2..2.8V), tipik ~57mA. TFT_BL_PWM aktif-yuksek; Q7 lojik seviye NMOS. Parlaklik numune ile olculup R60 gerekirse ayarlanmali.
TFT032B018 3.2in IPS 240x320, ST7789V2. 4-wire SPI: IM (pin 21) = 3.3V. DB0..DB7, RDX GND; TE, dokunmatik (24, 26..29) bos. J3: KLS L-KLS1-242I-2.0-30-R, 30p 0.5mm ZIF.
ENCODER: SW3 PANEL / PULL-UPS PCB
A=GPIO22, B=GPIO23, SW=GPIO21. R34-R36: 10k pull-ups on PCB; no RC fitted. SW3: panel mounted, five wires to J9 below.
PCB WIRE PADS - J9
1=A 2=C/GND 3=B 4=S1 5=S2/GND 5 x 0.14mm2 stranded wire, length <=150mm. Solder pads only; enclosure provides strain relief. Insulated knob; keep cable away from switching nodes. Firmware: quadrature state validation + switch debounce.

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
Board: 4 copper layers, 144 parts (94 on the bottom side), 86 nets, no tracks yet.

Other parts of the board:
H1, H2, H3, H4: M3; MountingHole_3.2mm_M3
MECH_ENC: PANEL EC1121S; J9 cable

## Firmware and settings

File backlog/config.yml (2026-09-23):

project_name: "gopo"
default_status: "To Do"
statuses: ["To Do", "In Progress", "Blocked", "Done"]
labels: ["schematic", "layout", "procurement", "sample-eval", "fabrication", "bring-up", "firmware", "docs"]
types: ["task", "bug", "spike", "chore", "docs"]
definition_of_done: ["Kanıt (ERC/netlist/ölçüm/commit) Implementation Notes'a yazıldı", "Karar değiştiyse design_decisions/ ve CHANGES.TXT güncellendi"]
date_format: yyyy-mm-dd
max_column_width: 20
auto_open_browser: false
default_port: 6420
remote_operations: true
auto_commit: false
filesystem_only: false
zero_padded_ids: 3
bypass_git_hooks: false
check_active_branches: true
active_branch_days: 30
task_prefix: "task"

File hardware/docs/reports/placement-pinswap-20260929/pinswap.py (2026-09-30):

"""U2 pin atamasi aramasi: yerlesim sabit, izinli padlar arasinda net degisimi; Engine.total() en aza indirilir."""
import sys, random, time, itertools, json
sys.path.insert(0, ".claude/skills/kicad-placement/scripts")
from placelib import Model, Engine, load_cfg, load_state
cfg = load_cfg(".claude/skills/kicad-placement/examples/gopo_rev_c.py")
m = Model(sys.argv[1], cfg); st = load_state(sys.argv[2])
IC = "U2"
PADS = ["5", "6", "9", "10", "13", "16", "19", "20", "24", "25", "26", "27", "28", "29"]
STRAP = {"9", "10", "20"}                      # GPIO4, GPIO5, GPIO15
TFT_HIZ = {"TFT_SCLK", "TFT_MOSI", "TFT_DC", "TFT_CS", "TFT_RST"}
idx = {q["n"]: i for i, q in enumerate(m.P[IC]["pads"])}
full = {m.P[IC]["pads"][idx[p]]["s"]: m.P[IC]["pads"][idx[p]]["net"] for p in PADS}
orig = {p: m.P[IC]["pads"][idx[p]]["s"] for p in PADS}

def ok(a):
    return all(a[p] in TFT_HIZ for p in STRAP)

def rebuild(a):
    for p, n in a.items():
        q = m.P[IC]["pads"][idx[p]]; q["s"] = n; q["net"] = full[n]
    m.net_pads = {}
    for r in m.refs:
        for i, q in enumerate(m.P[r]["pads"]):
            if q["net"]:
                m.net_pads.setdefault(q["s"], []).append((r, i))
    m.nets_of = {r: sorted({q["s"] for q in m.P[r]["pads"] if q["net"]}) for r in m.refs}
    m._resolve_crit()

def cost(a):
    rebuild(a); E = Engine(m, st); return E.total(), m.crossings(st)[0]

t0 = time.time()
c0, x0 = cost(orig); print(f"mevcut: maliyet {c0:.1f} kesisme {x0}  ({time.time()-t0:.2f}s/deger)", flush=True)
best = (c0, x0, dict(orig))
random.seed(int(sys.argv[4]) if len(sys.argv) > 4 else 1)
starts = [dict(orig)]
for _ in range(int(sys.argv[3]) if len(sys.argv) > 3 else 3):
    while True:
        v = list(orig.values()); random.shuffle(v); a = dict(zip(PADS, v))
        if ok(a): starts.append(a); break
for si, a in enumerate(starts):
    c, x = cost(a)
    improved = True
    while improved:
        improved = False
        for p, q in itertools.combinations(PADS, 2):
            b = dict(a); b[p], b[q] = a[q], a[p]
            if not ok(b): continue
            cb, xb = cost(b)
            if cb < c - 1e-6:
                a, c, x, improved = b, cb, xb, True
    print(f"baslangic {si}: maliyet {c:.1f} kesisme {x} t={time.time()-t0:.0f}s", flush=True)
    if c < best[0]: best = (c, x, dict(a))
c, x, a = best
print(f"EN IYI: maliyet {c0:.1f} -> {c:.1f}, kesisme {x0} -> {x}")
for p in PADS:
    if a[p] != orig[p]: print(f"  pad {p}: {orig[p]} -> {a[p]}")
json.dump({"assign": a, "orig": orig, "cost": [c0, c], "cross": [x0, x]}, open(sys.argv[5] if len(sys.argv) > 5 else "pin.json", "w"), indent=1)

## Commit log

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2026-09-16 Depo yapısını open_hardware_template şablonuna uyarla
    Yapı https://github.com/mfhepp/open_hardware_template şablonunu izliyor:
    hardware/, design_decisions/, 3d_design/, software/, docs/ ve CERN OHL
    belgeleri (LICENSE, CHANGES.TXT, PRODUCT.TXT, cern_ohl_v_1_2.txt).
    Donanım
    - REV_B_20260914/ -> hardware/, KiCad projesi gopo.* olarak yeniden
    adlandırıldı (.kicad_pro/.kicad_prl ve 8 şematikteki iç referanslar dahil).
    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
    [AO3400A.step, BOM_PRELIMINARY_20260911.csv, BOM_PRELIMINARY_20260911.xlsx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]
2026-09-16 J2 UART başlığını test noktalarıyla değiştir, ESP32 sembolünü yerelleştir
    Kütüphane tabloları artık tamamen ${KIPRJMOD} göreli: harici mutlak yol
    veya eksik kütüphane kalmadı, proje başka bir makinede olduğu gibi açılır.
    J2 -> TP11/TP12/TP13
    - J2 (DS1021-1X3SF11-B, 3 pinli UART başlığı) sembolü ve lib_symbols
    önbelleği mcu.kicad_sch'ten kaldırıldı.
    - Yerine Connector:TestPoint ile TP11 (UART_TX), TP12 (UART_RX) ve
    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
    [mcu.kicad_sch]
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2026-09-16 usb_c_input: D3 SMAJ30A -> SMBJ30A (REV_C 3.1)
    VBUS TVS'i 400 W SMA'dan 600 W SMB'ye yükseltildi.
    Handoff dokümanı 3.1 #2'de D3'ü AQ3130E-01ETG (ESD diyotu) sanıyordu;
    gerçekte D3 zaten USB_VBUS üzerinde tek yönlü 30 V TVS idi. ESD elemanı
    ayrı: U10 = TPD4EUSB30. Bu yüzden "SMBJ30A ekle" maddesi mevcut TVS'in
    yükseltilmesi olarak uygulandı.
    ERC ve netlist değişmedi; yalnızca sembol, değer ve footprint.
    [usb_c_input.kicad_sch]
2026-09-16 usb_pd_controller: C3 1uF -> 2.2uF/50V X7R (REV_C 3.1 #3)
    cSnkBulk minimumu olan 1 uF'ı DC bias altında garanti etmek için.
    Footprint 0805'te bırakıldı; doküman footprint belirtmiyor. 50 V bias
    altında 0805 X7R'nin efektif kapasitesi 1 uF hedefinin altına düşebilir,
    1206'ya çıkarmak değerlendirilmeli.
    [usb_pd_controller.kicad_sch]
2026-09-16 powergeneration: C16 footprint 0402 -> 1210 (REV_C 3.3 #15)
    47 uF 0402 footprint'iyle atanmıştı; bu değer 0402'de üretilmiyor.
    C_1210_3225Metric'e çevrildi (C12/C13 ile aynı).
    [powergeneration.kicad_sch]
2026-09-16 powergeneration: TPS55340 pre-boost bloğunu ekle (REV_C 3.3 #1-#12)
    PD_VOUT 5 V'un altına indiğinde (3.3 V PPS) dahili rail'i ayakta tutan,
    üstünde pass-through çalışan asenkron boost. Yeni net: V_PRE (global).
    Bileşenler (18): U11 TPS55340PWPR, L3 6.8uH TBD, D4 Schottky TBD,
    D5 BAT54 (FB clamp), R47 78.7k FREQ, R48/R49 30.1k/9.76k FB bölücü,
    R50/R51 820R/1k clamp bias, R52 2k + C24 100nF kompanzasyon, R53 100k EN,
    C23 47nF SS, C25/C26 giriş, C27/C28 çıkış, C29 47uF sönümleme bulk.
    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
    [powergeneration.kicad_sch]
2026-09-16 powergeneration: dahili rail'i V_PRE'ye taşı (REV_C 3.3 #13, #14)
    AOZ1284 buck ve TL431 EN bias'ı artık PD_VOUT yerine pre-boost çıkışı
    V_PRE'den besleniyor. Böylece PD_VOUT 3.3 V PPS'e indiğinde dahili rail
    5.02 V'ta kalıyor.
    Sayfadaki iki PD_VOUT global etiketi V_PRE olarak değiştirildi:
    - (29.21, 71.12) -> AOZ1284 VIN + giriş kapasite bankası
    - (243.84, 110.49) -> R43 / TL431 EN bias
    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
    [powergeneration.kicad_sch]
2026-09-16 poweroutput: AP74502Q kullanıcı çıkış anahtarını ekle (REV_C 3.4, 3.2 #3)
    Kullanıcı akımı artık Q3/Q4'ten geçmiyor; şöntün arkasındaki dallanma
    noktasından (PD_VBUS_SENSED) M1/M2 back-to-back FET çifti üzerinden akıyor.
    Yol kaybı yarıya iniyor.
    Bileşenler (14): U12 AP74502Q, Q5/Q6 back-to-back NMOS (60V 4mR TBD),
    D6 BZT52C12 GATE-SRC zener, D7 SMBJ30A çıkış TVS, R54 1k + C30 22nF
    soft-start, R55/R56 232k/10k OVLO, R57/R58 10k/100k EN ağı, R59 10k bleed,
    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
    [poweroutput.kicad_sch, powersensing.kicad_sch]
2026-09-16 powergeneration: Blok A'yı kistack/schematic skill kurallarına göre yeniden çiz
    Izgara + etiket dizilimi yerine gerçek şema yerleşimi. Netlist değişmedi,
    ERC 4'te sabit (hepsi REV_C öncesinden).
    Yerleşim
    - Soldan sağa sinyal akışı: PD_VOUT rayı -> L3 -> BOOST_SW -> D4 -> V_PRE
    - Pasifler IC pinlerine gerçek tellerle bağlandı (dekuplaj, SS, FREQ,
    kompanzasyon, EN pull-up). Etiket yalnızca sayfa/blok arası ve okunabilirlik
    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
    [powergeneration.kicad_sch, poweroutput.kicad_sch]
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2026-09-16 poweroutput: Blok B'yi skill kurallarıyla yeniden çiz (REV_C 3.4)
    daeca6d commit'i Blok B'yi sessizce geri almıştı: Blok A'nın yerleşimini
    yeniden çizerken poweroutput sayfasını da eski haline döndürmüş ve
    git add -A onu commit'e dahil etmişti. Bu commit hem o kaybı telafi eder
    hem de bloğu profesyonel yerleşimle yeniden kurar.
    - Soldan sağa güç akışı: PD_VBUS_SENSED -> Q5 -> SRC_COMMON -> Q6 -> SW_OUT
    - U12 akış hattının altında, gate sürücü ağı sağında
    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
    [poweroutput.kicad_sch]
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2026-09-17 usb_pd_controller, mcu, powersensing: çizimleri yeniden düzenle, SDA dönüştürücüsünü bağla
    Çizim (netlist aşağıdaki düzeltme dışında aynı)
    - usb_pd_controller: üç blok (AP33772S kontrolcü, VBUS şönt + çıkış
    anahtarı, I2C seviye dönüştürücü). Q3/Q4 kapıları tek tel hattıyla,
    Q3 ang 90 + mirror y. TestPoint değer yazıları gizli.
    - mcu: ESP32, RTC ve test noktası blokları. Sağ kenar satırları kesişmesiz;
    GPIO8 strap ağı satır sonunda, GPIO9 BOOT ağı dıştan aşağı. EN RC + RESET
    IC'nin üstüne alındı. UART/I2C/INT test noktaları etiketle ayrı blokta.
    - powersensing: INA228 bloğu, şönt Kelvin bağlantısı kesişmesiz.
    Devr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
    [mcu.kicad_sch, powersensing.kicad_sch, usb_pd_controller.kicad_sch]
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2026-09-21 kicad-schematic skill'ini parça değişimi, alan aktarımı ve çerçeve denetimi dersleriyle güncelle
    - kisch_edit.swap_lib: sembolü başka kütüphane sembolüyle değiştirir (uuid,
    instance, alanlar korunur; pin uuid kayıtları eşitlenir, eski tanım silinir).
    RV-3028->BQ32000 ve Conn_01x40->01x30 elle yapılan sonuçla birebir, idempotent.
    - kisch_edit.prune_lib_symbols: kullanılmayan lib_symbols tanımlarını siler
    (Battery_Cell ve AO3400A artıklarını buldu).
    - kisch_edit.set_sym_props(visible=None): mevcut görünürlüğü korur; veri
    aktarımında gizli TestPoint/J7 Value'larının açılmasını önler.
    kisch_edit.field_visibility: önce/sonra görün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
2026-09-22 kicad-schematic skill'ini önbellek, parça değişimi ve kuru çalıştırma dersleriyle güncelle
    Araç düzeltmeleri:
    - place(): ref_at/val_at verilmezse Reference/Value sembolle aynı farkla taşınır.
    - translate_region(stretch=True): yalnız kutudaki tel uçları kayar (ray kopmaz).
    - ensure_lib_symbol/swap_lib: extends'li sembolleri bağımsızlaştırır
    (lib_symbol_source); swap_lib proje kütüphanesini sym-lib-table'dan bulur.
    - verify.py: önbellekte olmayan lib_id uyarısı (ERC yakalamıyor, pin sessizce
    ayrı nete düşüyordu).
    Yeni: update_fields, sym_blocks, set_dnp, K.sym(dnp=), missing_lib_symbols,
    ensure_used_lib_symbols, refresh_lib_symbol, kicadtools.kicad_open,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
2026-09-23 kicad-schematic: move_block önbellek girdisini doğru girintiyle ekle
    ensure_lib_symbol_from kopyalanan sembol tanımını lib_symbols içine tek
    sekmeyle başlatıyordu. KiCad dosyayı okuyordu ama missing_lib_symbols
    ("\n\t\t(symbol" arar) tanımı görmedi; verify.py "onbellekte yok"
    uyarısı verdi ve ensure_used_lib_symbols bunu düzeltemedi.
    TASK-048 taşımasında (Transistor_FET:BSS138 -> mcu) bulundu.
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2026-09-23 hardware: Ethernet mezanin blogu ve besleme anahtari (TASK-051/060)
    Waveshare 2-CH UART TO ETH (CH9121) modulu mcu sayfasina mezanin olarak
    baglandi. J8 (2x8) pinout'u ureticinin semasindan alindi; modulun 3V3
    pinleri beslenir, AMS1117 atlanir, 5V bos. Kanal 1 UART0'a bagli
    (GPIO16/17; loglar zaten USB-Serial/JTAG'de), CFG0 GPIO8'de (R37 10k
    boot boyunca high tutar = normal mod), RUN yalniz TP14 pedinde.
    Q8 TSM3443CX6 P-kanal yuksek-yan anahtari ETH_3V3'u keser: PD Fixed PDO
    gecisindeki 2,5 W standby butcesinden modulun ~0,66 W'i dusulebiliyor.
    ETH_PWR_EN = GPIO0, aktif-low; GPIO0 boot'ta yuksek empedans oldugu icin
    R17 100k modulu kapali tutar. R16 22R -> 10k gate seri direnci, yeni C21
    10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
    [mcu.kicad_sch]
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2026-09-23 backlog: TASK-052 Done; CH9121 dahili pull-up'lari ve SAMM tedariki
    - TASK-052 Done: modul semasi incelendi (3,3 V besleme yolu, RJ45 trafolu,
    kabuk GND'de, CFG0/RST1/RUN baglantilari); tedarik SAMM Market MP02965,
    634,89 TL + KDV. Kapsam "sema incele + tedarikci belirle" olarak daraltildi.
    - CH9121 veri sayfasi eklendi (hardware/datasheets/CH9121DS1.PDF): CFG,
    RSTI, RESET, RXD1/2 cip ici 30-55 kOhm pull-up. CFG0 pull-down riski
    kapandi; yerine modul kapaliyken boot'ta GPIO8/GPIO16 geri besleme riski.
    - TASK-053: kriterler yeni risklere, reset zamanlamasina (40-70 ms) ve
    footprint dogrulamasina gore guncellendi.
    - TASK-054: standoff yok, dogrudan lehim; J8 footprint atandi (KK#5).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
2026-09-23 hardware: kart dis hattini TFT032B018 gorunur alanina gore ciz (TASK-062)
    107 x 61 mm, r 3; orijin AA merkezi; LCD/AA referansi Dwgs.User'da;
    4 x M3 NPTH; U2 anteni sag kenarda, LCD'den 15.2 mm. TFT032B018
    mekanik cizimi eklendi. Karar: KART_DIS_HATTI_LCD_20260924.md.
    [gopo.kicad_pcb]
2026-09-23 hardware: kart dis hattini AA'ya gore simetrik yap (TASK-062)
    99.40 x 61.04 mm: sag/sol kenar AA'dan esit 17.30 mm, ust/alt LCD
    modulunden 3 mm. U2 anten varsayimi kaldirildi (konum TASK-063/054).
    M3 delikleri +-45.70/+-26.52.
    [gopo.kicad_pcb]
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2026-09-29 REV_C yerlesim: agirlikli ratsnest araclari, FPC keepout, routability ve ESP32 pin atamasi
    Yerlesim (hardware/gopo.kicad_pcb, kilitli H1-H4/J3 yerinde, parite 0):
    - TASK-115: kilitsiz parcalarin agirlikli ratsnest ile sifirdan yerlesimi
    - TASK-118: agirlik 10/5/5 (W_ORDINARY) ve LCD FPC bukum yolunda top'ta parca yok
    - TASK-119: kesisme cezasi, dekuplaj-IC ayni yuz kurali (flip destegi), IC-yerel kenarlar
    - TASK-122: In2 guc polygonlari metrige yansidi (PLANE_NETS), sinyal kesismesi 75 -> 51
    - TASK-124: BOOST LNS (sicak dongu sabit), C23 SS 7.0 -> 2.7 mm; PD degismedi
    ESP32-C6 pin atamasi (TASK-123, kullanici onayli):
    - mcu.kicad_sch: U2 pinlerindeki 12 etiket yeniden adlandirildi; ERC 0, n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
    [before.kicad_pcb, mcu.kicad_sch]
